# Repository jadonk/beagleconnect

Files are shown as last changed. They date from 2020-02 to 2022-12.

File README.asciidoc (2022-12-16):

ifdef::env-github[]
:tip-caption: :bulb:
:note-caption: :information_source:
:important-caption: :heavy_exclamation_mark:
:caution-caption: :fire:
:warning-caption: :warning:
:todo-caption: :hammer:
endif::[]
:toc:
:toc-placement!:

Moved to https://git.beagleboard.org/beagleconnect/freedom

[[beagleconnect]]
= BeagleConnect™

BeagleConnect™ is a revolutionary technology virtually eliminating low-level software
development for https://en.wikipedia.org/wiki/Internet_of_things[IoT] and https://en.wikipedia.org/wiki/Industrial_internet_of_things[IIoT] applications, such as building automation, factory
automation, home automation, and scientific data acquisition. While numerous IoT and IIoT
solutions available today
provide massive software libraries for microcontrollers footnote:[Complexity can be seen by exploring https://www.arduino.cc/reference/en/libraries/category/sensors/[Arduino sensor libraries]]
supporting a limited body of
https://en.wikipedia.org/wiki/Sensor[sensors],
https://en.wikipedia.org/wiki/Actuator[actuators] and
https://en.wikipedia.org/wiki/Indicator_(distance_amplifying_instrument)[indicators]
as well as libraries for communicating over various networks,
BeagleConnect simply eliminates the need for these libraries by shifting the burden
into the most massive and collaborative software project of all time, the https://en.wikipedia.org/wiki/Linux_kernel[Linux kernel].

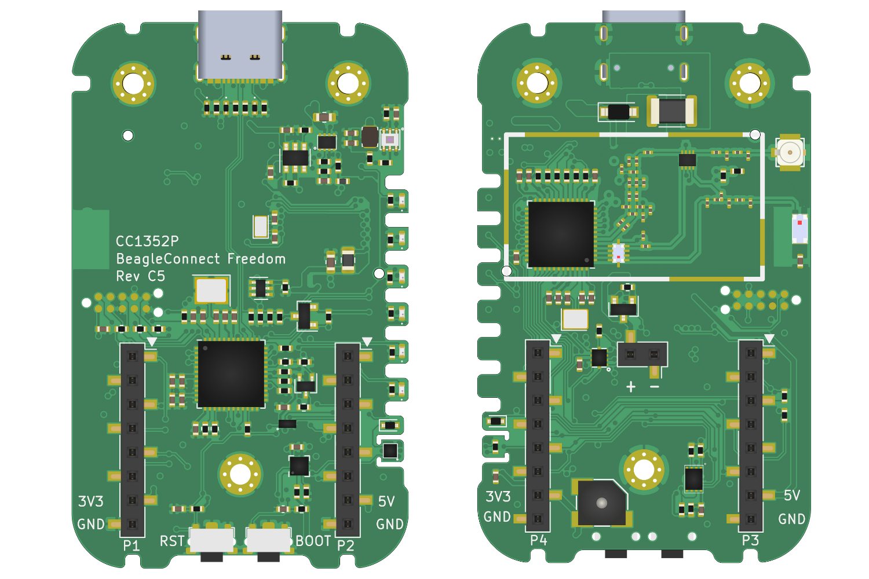
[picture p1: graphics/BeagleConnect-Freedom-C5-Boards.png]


These are the tools used to automate things in
https://en.wikipedia.org/wiki/Data_collection_system[scientific data collection],
https://en.wikipedia.org/wiki/Data_science[data science],
https://en.wikipedia.org/wiki/Mechatronics[mechatronics], and
https://en.wikipedia.org/wiki/Internet_of_things[IoT].

BeagleConnect™ technology solves: 

* The need to write software to add a large set of diverse devices to your system, 
* The need to maintain the software with security updates, 
* The need to rapidly prototype using off-the-shelf software and hardware without wiring, 
* The need to connect to devices using long-range, low-power wireless, and 
* The need to produce high-volume custom hardware cost-optimized for your requirements.

toc::[]

= BeagleConnect™ experience

BeagleConnect™ provides a scalable experience for interacting with the physical world.

NOTE: The term _BeagleConnect™_ refers to a technology comprising of
a family of boards, a collection of Linux kernel drivers,
microcontroller firmware, a communication protocol, and system-level
integration to automation software tools. More specific terms will be
applied in the architecture details. The term is also used here to
represent the experience introduced to users through the initial
_BeagleConnect™ Freedom_ product consisting of a board and case which
ships programmed and ready to be used.

For scientists, we are integrating https://jupyter.org/[Jupyter Notebook] with the data streams
from any of hundreds of sensor options, including https://www.mikroe.com/click/sensors/force[vibration],
https://www.mikroe.com/click/sensors/gas[gas detection],
https://www.mikroe.com/click/sensors/biometrics[biometrics] and
https://www.mikroe.com/click/sensors[more]. These data streams can be stored in simple
https://en.wikipedia.org/wiki/Comma-separated_values[data files] or processed and visualized.

WARNING: TODO provide images demonstrating Jupyter Notebook visualization

For embedded systems developers, data is easily extracted using the standard
https://www.kernel.org/doc/html/latest/driver-api/iio/index.html[IIO]
interface provided by the https://kernel.org[Linux kernel]
running on the gateway using any of hundreds of
programming languages and environments, without writing a line of microcontroller firmware.
The Linux environment provides opportunities for high-level remote management using tools
like https://balena.io[Balena] with applications deployed in
https://docker.io[Docker] containers.

WARNING: TODO provide image illustrating remote management#

The hardware and software are fully open source, providing for scalability and a lack of
vendor lock-in.

For DevOps...

For home automaters, integration into https://webthings.io[WebThings]...

WARNING: TODO think a bit more about this section with some feedback from Cathy.

= BeagleConnect™ hardware

== BeagleConnect™ Freedom

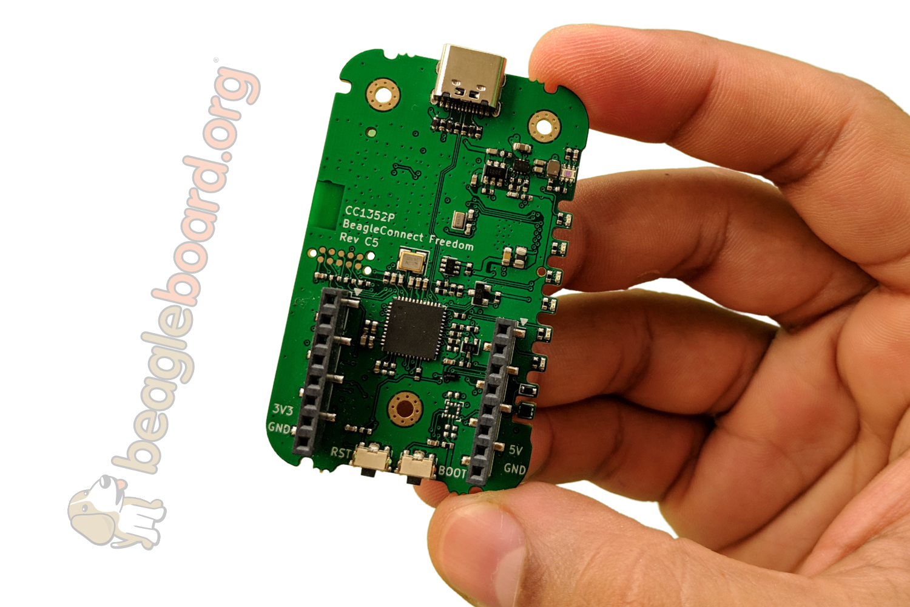
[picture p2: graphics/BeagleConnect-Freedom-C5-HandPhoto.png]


WARNING: TODO provide image of BeagleConnect™ Freedom in case with a hand for size perspective#

IMPORTANT: _BeagleConnect™ Freedom_ enables wirelessly adding new device nodes and is targeted
to cost initially around US$20 with a roadmap to variants as low as US$1.

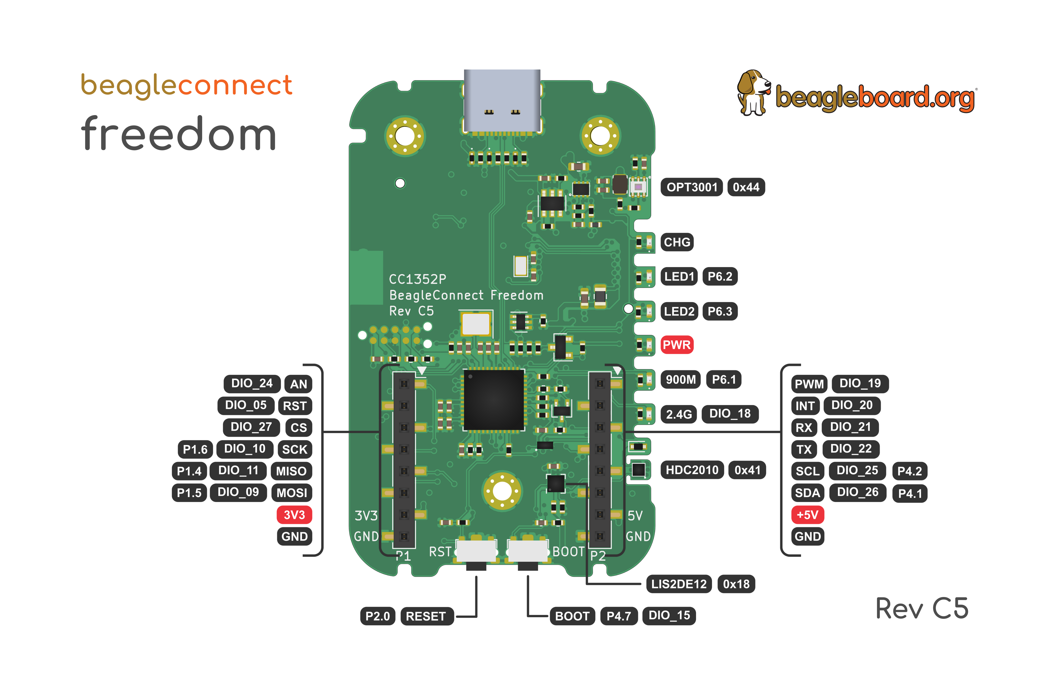
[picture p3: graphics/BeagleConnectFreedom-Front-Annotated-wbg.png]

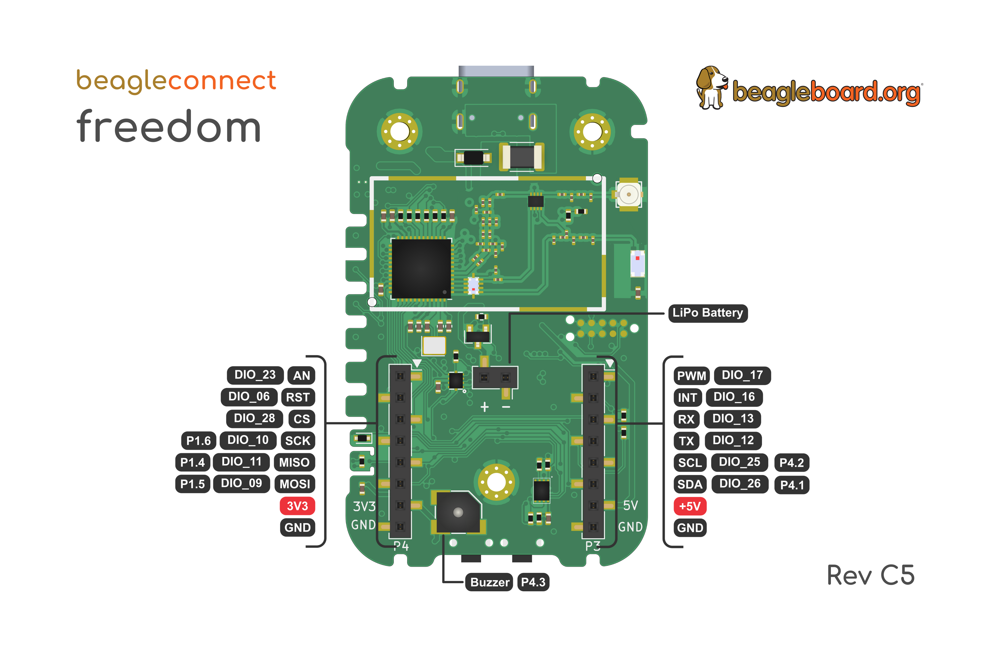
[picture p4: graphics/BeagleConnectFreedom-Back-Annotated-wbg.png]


The initial _BeagleConnect™ Freedom_ production release will: 

* Support at least 100 https://elinux.org/Mikrobus[mikroBUS]-based https://mikroe.com/click[Click boards from Mikroelectronika], 
* Work with https://en.wikipedia.org/wiki/Bluetooth_Low_Energy[Bluetooth Low Energy (BLE)]-enabled Linux computers at 2.4GHz, 
* Work with long-range sub-1GHz https://en.wikipedia.org/wiki/IEEE_802.15.4[IEEE 802.15.4 wireless connections] at 500 meters with data rates of 1kbps, and 
* Work with a low-cost BeagleBoard.org Linux https://en.wikipedia.org/wiki/Single-board_computer[single-board computer (SBC)] as a `BeagleConnect™ gateway device` and
  work with at least 10 other `BeagleConnect™ node devices` each supporting 2 add-on sensor, actuator or indicator devices.

Future releases will be collaborated with the community, evolve
dynamically, and contain additional functionality. The goal is to
support over 500 add-on devices within the first year after the
initial release.

[[beta-kit]]
== BeagleConnect™ Freedom beta kit

A small number of beta kits have been assembled with BeagleConnect™ Freedom rev C5
boards, which is the version that should be taken to production.

The kit includes:

* 1x https://wiki.seeedstudio.com/BeagleBone-Green-Gateway/[Seeed BeagleBone® Green Gateway] (board, USB cable)
* 3x BeagleConnect™ Freedom (board, antenna, USB cable)
* 1x https://www.mikroe.com/unique-id-click[MikroElektronikia Click ID Board]

To get started with this kit, see <<demo-1>>.

== BeagleConnect™ Mobile Gateway

This is a work-in-progress that will be released as the first integrated BeagleConnect™
gateway. It is possible to assemble a gateway with any Linux computer, but this computer
will ship setup and ready to go.

The gateway is built from:

* BeagleBoard.org PocketBeagle,
* BeagleConnect™ Freedom,
* a cellular modem,
* a USB WiFi dongle,
* antennas, and
* an enclosure.

[[story]]
= The Story Behind BeagleConnect™ 

[[long-background]]
== The Long Background
There are many stories behind BeagleConnect™, mine is just one of them. It begins
with my mom teaching me about computers. She told me I could anything I wanted
with ours, as long as I didn't open the case. This was the late-70s/early-80s, so
all she needed to do was put her https://en.wikipedia.org/wiki/Floppy_disk[floppy disk]
away and there wasn't risk of me damaging the family photo album or her ability to
do her work the next day. I listened and learned from her the basics of programming, but
it wasn't long before I wanted to take the computer apart. 

=== Getting Started in Electronics
Exploring http://www.forrestmims.org/[Getting Started in Electronics] satisfied my
itch for quite a while. Eventually, I got a Commodore 64 and began connecting voice
synthesizer ICs to it. My interest in computers and electronics flourished into
an electrical engineering degree and a long career in the semiconductor industry.

Over this time, I've become more and more alarmed with the progress of technology. Now,
to be clear, I love technology. I love innovation and invention. It is just that some
things have evolved in a sort of tunnel-vision, without bringing everyone along.

=== But, what about keyboard users?
As graphical user interfaces and mice took over computers, they rapidly became almost
unusable by my mom. She typed well, but the dexterity to move a mouse alluded her.
To satisfy the need to interact with locations on the screen, she adopted using a
joystick and her productivity came to a crawl. How is it that such assumptions could
be made impacting *all* computer users without any thoughtful provisions for what
already worked?

=== Find out more
Get on https://beagleboard.org/about/jkridner[my calendar] if you'd like to chat
with me more about this story.

[[architecture]]
= Architecture

[[beagleconnect-leash]]
== BeagleConnect™ Freedom
_BeagleConnect™ Freedom_ is based on the https://www.ti.com/product/CC1352R[TI CC1352] and is the first available
BeagleConnect™ solution. It implements:

* `BeagleConnect™ gateway device` function for Sub-GHz 802.15.4 long-range wireless
* `BeagleConnect™ node device` function for Bluetooth Low-Energy (BLE) and Sub-GHz
802.15.4 long range wireless
* USB-based serial console and firmware updates
* 2x https://www.mikroe.com/mikrobus[mikroBUS sockets] with `BeagleConnect™ protocol support`

WARNING: TODO provide BeagleConnect™ Freedom pinout diagram

[[what-is-new]]
== What makes BeagleConnect™ new and different?

IMPORTANT: BeagleConnect™ solves IoT in a different and better way than any previous
solution.

[[the-device-interface-software-is-already-done]]
=== The device interface software is already done

BeagleConnect™ uses the collaboratively developed Linux kernel to contain
the intelligence required to speak to these devices (sensors, actuators,
and indicators), rather than relying on writing code on a
microcontroller specific to these devices. Some existing solutions rely
on large libraries of microcontroller code, but the integration of
communications, maintenance of the library with a limited set of
developer resources and other constraints to be explained later make
those other solutions less suitable for rapid prototyping than
BeagleConnect™.

Linux presents these devices abstractly in ways that are
self-descriptive. Add an accelerometer to the system and you are
automatically fed a stream of force values in standard units. Add a
temperature sensor and you get it back in standard units again. Same for
sensing magnetism, proximity, color, light, frequency, orientation, or
multitudes of other inputs. Indicators, such as LEDs and displays, are
similarly abstracted with a few other kernel subsystems and more
advanced actuators with and without feedback control are in the process
of being developed and standardized. In places where proper Linux kernel
drivers exist, no new specialized code needs to be created for the
devices.

IMPORTANT: _Bottom line_: For hundreds of devices, users won't have to write a
single line of code to add them their systems. The automation code they
do write can be extremely simple, done with graphical tools or in any
language they want. Maintenance of the code is centralized in a small
reusable set of microcontroller firmware and the Linux kernel, which is
highly peer reviewed under a
https://wiki.p2pfoundation.net/Linux_-_Governance[highly-regarded
governance model].

[[on-going-maintenance]]
=== On-going maintenance

Because there isn't code specific to any given network-of-devices
configuration, we can all leverage the same software code base. This
means that when someone fixes an issue in either BeagleConnect™ firmware
or the Linux kernel, you benefit from the fixes. The source for
BeagleConnect™ firmware is also submitted to the
https://www.zephyrproject.org/[Zephyr Project] upstream, further
increasing the user base. Additionally, we will maintain stable branches
of the software and provide mechanisms for updating firmware on
BeagleConnect™ hardware. With a single, relatively small firmware load,
the potential for bugs is kept low. With large user base, the potential
for discovering and resolving bugs is high.

[[rapid-prototyping-without-wiring]]
=== Rapid prototyping without wiring

BeagleConnect™ utilizes the https://elinux.org/Mikrobus[mikroBUS
standard]. The mikroBUS standard interface is flexible enough for almost
any typical sensor or indicator with hundreds of devices available.

NOTE: Currently, we have support in the Linux kernel for a bit over 100
_Click_ mikroBUS add-on boards from Mikroelektronika and are working
with Mikroelektronika on a updated version of the specification for these
boards to self-identify. Further, eventually the vast majority of over
800 currently available _Click_ mikroBUS add-on boards will be supported
as well as the hundreds of compliant boards developed every year.

[[long-range-low-power-wireless]]
=== Long-range, low-power wireless

_BeagleConnect™ Freedom_ wireless hardware is built around a
http://www.ti.com/product/CC1352R[TI CC1352] multiprotocol and multi-band Sub-1 GHz and 2.4-GHz wireless 
microcontroller (MCU). CC1352R includes a 48-MHz Arm® Cortex®-M4F processor, 352KB Flash, 256KB ROM, 8KB Cache SRAM,
80KB of ultra-low leakage SRAM, and https://en.wikipedia.org/wiki/Over-the-air_programming[Over-the-Air] upgrades (OTA).

[[full-customization-possible]]
=== Full customization possible

BeagleConnect™ utilizes https://www.oshwa.org/definition/[open source
hardware] and https://en.wikipedia.org/wiki/Open-source_software[open
source software], making it possible to optimize hardware and software
implementations and sourcing to meet end-product requirements.
BeagleConnect™ is meant to enable rapid-prototyping and not to
necessarily satisfy any particular end-product's requirements, but with
full considerations for go-to-market needs.

Each BeagleBoard.org BeagleConnect™ solution will be:

* Readily available for over 10 years, 
* Built with fully
open source software with submissions to mainline Linux and Zephyr
repositories to aide in support and porting, 
* Built with fully open
source and non-restrictive hardware design including schematic,
bill-of-materials, layout, and manufacturing files (with only the
BeagleBoard.org logo removed due to licensing restrictions of our
brand), 
* Built with parts where at least a compatible part is available
from worldwide distributors in any quantity, 
* Built with design and
manufacturing partners able to help scale derivative designs, 
* Based on
a security model using public/private keypairs that can be replaced to
secure your own network, and 
* Fully FCC/CE certified.

[[usage]]
= Usage
This section describes the usage model we are developing. To use the current code in development,
please refer to the <<development>> section below.

[[beagleconnect-user-experience]]
== BeagleConnect™ wireless user experience

[[enable-a-linux-host-with-beagleconnect]]
=== Enable a Linux host with BeagleConnect™

image:https://github.com/beagleboard/beagleconnect/blob/master/docs/ProvStep1.PNG?raw=true[Provisioning
Step 1] Log into a host system running Linux that is BeagleConnect™
enabled. Enable a Linux host with BeagleConnect™ by plugging a
`BeagleConnect™ gateway device` into it's USB port. You'll also want to have a
`BeagleConnect™ node device` with a sensor, actuator or indicator device connected.

NOTE: _BeagleConnect™ Freedom_ can act as either a `BeagleConnect™ gateway device` or a
`BeagleConnect™ node device`.

IMPORTANT: The Linux host will need to run the `BeagleConnect™ management
software`, most of which is incorporated into the Linux kernel. Support will
be provided for BeagleBoard and BeagleBone boards, x86 hosts, and Raspberry Pi.

WARNING: TODO Clean up images

[[connect-host-and-device]]
=== Connect host and device

image:https://github.com/beagleboard/beagleconnect/blob/master/docs/ProvStep2.PNG?raw=true[Provisioning
Step 2] Initiate a connection between the host and devices by pressing
the discovery button(s).

[[device-data-shows-up-as-files]]
=== Device data shows up as files

image:https://github.com/beagleboard/beagleconnect/blob/master/docs/ProvStep3.PNG?raw=true[Provisioning
Step 3] New streams of self-describing data show up on the host system
using native device drivers.

High-level applications, like `Node-RED`, can directly read/write these high-level
data streams (including data-type information) to Internet-based https://mqtt.org/[MQTT] brokers,
live dashboards, or other logical operations without requiring any sensor-specific
coding. Business logic can be applied using simple if-this-then-that style operations
or be made as complex as desired using virtually any programming language or environment.

WARNING: TODO Actually, Node-RED will make these show up automatically as streams.

[[components]]
== Components

[horizontal]
BeagleConnect™ enabled host:: Linux computer, possibly single-board computer (SBC), with
`BeagleConnect™ management software` and `BeagleConnect™ gateway function`. `BeagleConnect™ gateway
function` can be provided by a `BeagleConnect™ compatible interface` or by connecting a
`BeagleConnect™ gateway device` over USB.
+
NOTE: If the Linux host has BLE, the BeagleConnect™ is optional for short distances
+

BeagleConnect™ Freedom:: Board, case, and wireless MCU with `Zephyr` based firmware for acting
as either a `BeagleConnect™ gateway device` or `BeagleConnect™ node device`.
* In `BeagleConnect™ gateway device` mode:
** Provides long-range, low-power wireless communications,
** Connects with the `host` via USB and an associated Linux kernel driver, and
** Is powered by the USB connector.
* In `BeagleConnect™ node device` mode:
** Powered by a battery or USB connector
** Provides 2 mikroBUS connectors for connecting any of hundreds of
https://bbb.io/click[Click Board] mikroBUS add-on devices
** Provides new Linux host controllers for SPI, I2C, UART, PWM, ADC, and
GPIO with interrupts via `Greybus`

BeagleConnect™ gateway device:: Provides a `BeagleConnect™ compatible interface` to a host. This
could be a built-in interface device or one connected over USB. _BeagleConnect™ Freedom_ can provide
this function.

BeagleConnect™ node device:: Utilizes a `BeagleConnect™ compatible interface` and #TODO#

BeagleConnect™ compatible interface:: Immediate plans are to support Bluetooth Low Energy (BLE),
2.4GHz IEEE 802.15.4, and Sub-GHz IEEE 802.15.4 _wireless_ interfaces. A built-in BLE interface is
suitable for this at short range, whereas IEEE 802.15.4 is typically significantly better at long
ranges. Other _wired_ interfaces, such as _CAN_ and _RS-485_, are being considered for future
`BeagleConnect™ gateway device` and `BeagleConnect™ node device` designs.

Greybus:: #TODO#

WARNING: TODO Find a place for the following notes:

** The device interfaces get exposed to the host via Greybus BRIDGED_PHY
protocol
** The I2C bus is probed for a an identifier EEPROM and appropriate
device drivers are loaded on the host
** Unsupported Click Boards connected are exposed via userspace drivers
on the host for development

[[whats-different]]
== What's different

So, in summary, what is so different with this approach?

* No microcontroller code development is required by users
* Userspace drivers make rapid prototyping really easy
* Kernel drivers makes the support code collaborative parts of the Linux
kernel, rather than cut-and-paste

[[development]]
= Develop for BeagleConnect™ Freedom with Zephyr

Developing directly in Zephyr will not be ultimately required for end-users who won't touch the firmware running on BeagleConnect™ Freedom and will instead use the BeagleConnect™ Greybus functionality, but is important for early adopters as well as people looking to extend the functionality of the open source design. If you are one of those people, this is a good place to get started.

[[equipment]]
== Equipment to begin development

There are many options, but let's get started with one recommended set for the beta users.

=== Required

* <<beta-kit>>
** https://wiki.seeedstudio.com/BeagleBone-Green-Gateway/[Seeed Studio BeagleBone® Green Gateway]
** 3x BeagleConnect™ Freedom board, antenna, U.FL to SMA cable, SMA antenna and USB Type-A to Type-C cable
** 1x https://www.mikroe.com/click[MikroE] ID Click
* microSD card (6GB or larger)
* microSD card programmer

=== Recommended

* https://smile.amazon.com/TMEZON-Power-Adapter-Supply-2-1mm/dp/B00Q2E5IXW[12V power brick]
* https://smile.amazon.com/Converter-Terminated-Galileo-BeagleBone-Minnowboard/dp/B06ZYPLFNB[USB to TTL 3.3V UART adapter]
* Ethernet cable and Internet connection
* 2x USB power adapters
* https://www.mikroe.com/weather-click[BME280-based Weather Click]
* https://www.mikroe.com/air-quality-2-click[iAQ-Core-based Air Quality 2 Click]

=== Optional

* x86_64 computer running Ubuntu 20.04.3 LTS

== Install the latest software image for BeagleBone Green Gateway

Download and install the Debian Linux operating system image for the
Seeed BeagleBone® Green Gateway host.

1. Download the special mikroBUS/Greybus BeagleBoard.org Debian image from
https://rcn-ee.net/rootfs/debian-mikrobus-armhf/[here]. 
Pick the most recent directory and select the file beginning with *bone-* and ending with *.img.xz*.
Today that file is *bone-debian-11.2-iot-mikrobus-armhf-2022-03-04-4gb.img.xz*.
2. Load this image to a microSD card using a tool like https://www.balena.io/etcher/[Etcher].
3. Insert the microSD card into the Green Gateway.
4. Power BeagleBone Green Gateway via the 12V barrel jack.

WARNING: TODO describe how to know it is working

== Setup BeagleBone Green Gateway

These instructions assume your BeagleBone Green is connected over USB to an x86_64 computer runing Ubuntu 20.04.3 LTS, but any other computer can also be used.

1. Log onto the Seeed BeagleBone® Green Gateway using `ssh`.
** We need IP address, username, and password to connect to the device.
** The default IP for the BeagleBone hardware over USB is `192.168.7.2` (over Ethernet it's usually at beaglebone.local)
** The default username is `debian` & password is `temppwd`
** To connect you can simply type `$ ssh debian@192.168.7.2` and when asked for password just type `temppwd`.
** Congratulations, You are now connected to the device!
2. Connect to the https://forum.beagleboard.org/t/debian-11-x-bullseye-monthly-snapshots/31280[WiFi]
** Execute `sudo nano /etc/wpa_supplicant/wpa_supplicant-wlan0.conf` and provide the password `temppwd` to edit the configuration file for the WiFi connection.
** Now edit the the file (shown below) under the `network={ ... }` section you can set you `ssid` (WiFi name) and `psk` (Wifi Password).

    ctrl_interface=DIR=/run/wpa_supplicant GROUP=netdev
    update_config=1
    #country=IN
    network={
            ssid="WiFi Name"
            psk="WiFi Password"
    }
    
** Now save the file with `CTRL+O` and exit with `CTRL+X`.
** Check if the connection is established by executing `$ ping 8.8.8.8` you should see something like shown below.

    debian@BeagleBone:~$ ping 8.8.8.8
    PING 8.8.8.8 (8.8.8.8) 56(84) bytes of data.
    64 bytes from 8.8.8.8: icmp_seq=1 ttl=118 time=10.5 ms
    64 bytes from 8.8.8.8: icmp_seq=2 ttl=118 time=5.72 ms
    64 bytes from 8.8.8.8: icmp_seq=3 ttl=118 time=6.13 ms
    64 bytes from 8.8.8.8: icmp_seq=4 ttl=118 time=6.11 ms
    ...
    
** If everything goes well, you are ready to update your system and install new applications for beagleconnect.

3. Install https://github.com/rcn-ee/code-server/tree/v3.11.1-bbb.io[Visual Studio Code Server] for easy terminal access and code editing.
** Update, Upgrade & Install the code server.

    sudo apt update
    
    sudo apt upgrade
    
    sudo apt install bb-code-server
    
    sudo reboot

** Enable and start the VSCode Server on `192.168.7.2:3000`
  
  sudo systemctl enable bb-code-server
  
  sudo systemctl start bb-code-server

** Visit `http://192.168.7.2:3000` and access the terminal easily using `CTRL + ``, You may also checkout other VSCode shortcuts https://code.visualstudio.com/shortcuts/keyboard-shortcuts-linux.pdf[here].

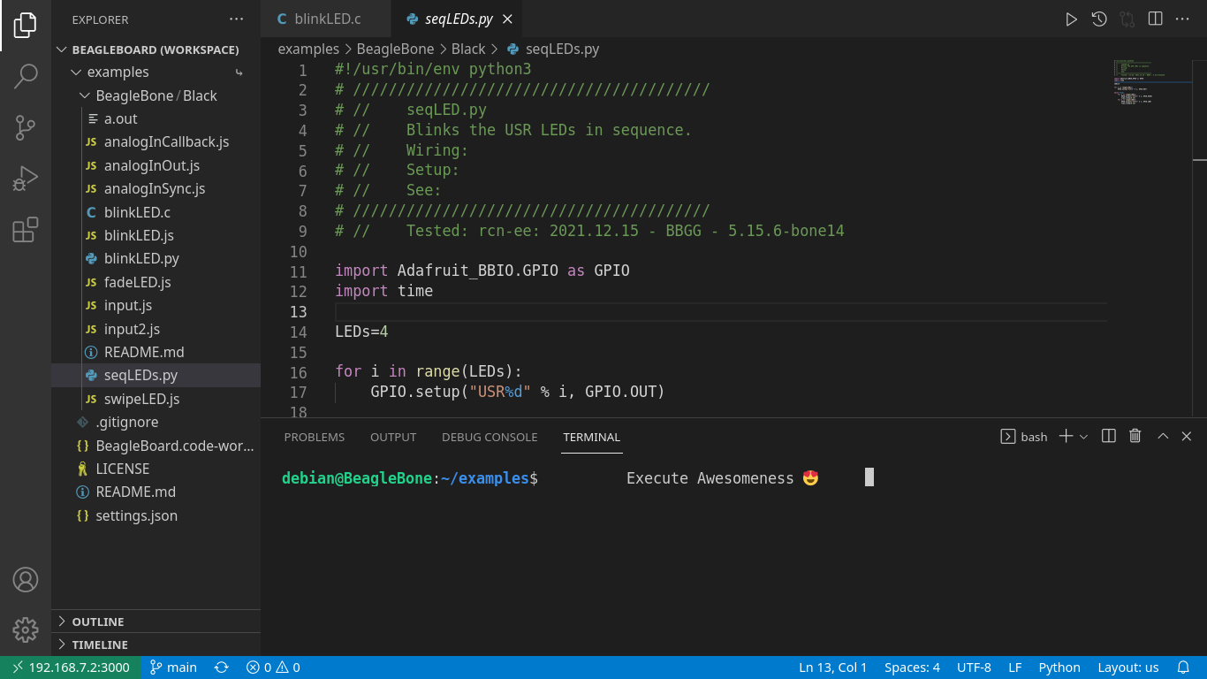
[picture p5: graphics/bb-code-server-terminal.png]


WARNING: TODO the above installation of bb-code-server should not be required on the mikrobus images. it needs to be enabled by default.

NOTE: If you are facing some issue during boot then you can try debuging the boot session with a USB to serial interface cable such as those made by https://www.digikey.com/short/cfjmdbdd[FTDI] plugged into J10 with the black wire of the FTDI cable toward the Ethernet connector. Application like tio/minicom/putty can be used to make the connection establishment procedure easy.

WARNING: TODO Simplify and elaborate on this section, add boot session debugging walkthrough

[[sdk]]
== Install Zephyr development tools on BeagleBone Green Gateway

<1> Update the system.

    sudo apt update

<2> Install all BeagleConnect™ management software.
    
    sudo apt install -y \
	    beagleconnect beagleconnect-msp430 \
	    git vim \
	    build-essential \
	    cmake ninja-build gperf \
	    ccache dfu-util device-tree-compiler \
	    make gcc libsdl2-dev \
	    libxml2-dev libxslt-dev libssl-dev libjpeg62-turbo-dev \
	    gcc-arm-none-eabi libnewlib-arm-none-eabi \
	    libtool-bin pkg-config autoconf automake libusb-1.0-0-dev \
	    python3-dev python3-pip python3-setuptools python3-tk python3-wheel

    echo "export PATH=$PATH:$HOME/.local/bin" >> $HOME/.bashrc
    
    source $HOME/.bashrc

<3> Reboot

    sudo reboot

<4> Install BeagleConnect™ flashing software

    pip3 install -U west

<5> Reboot

    sudo reboot

<6> Download and setup Zephyr for BeagleConnect™ 

    cd

    west init -m https://github.com/jadonk/zephyr --mr bcf-sdk-3.1.0-rebase bcf-zephyr

    cd $HOME/bcf-zephyr

    west update

    west zephyr-export

    pip3 install -r zephyr/scripts/requirements-base.txt

    echo "export CROSS_COMPILE=/usr/bin/arm-none-eabi-" >> $HOME/.bashrc

    echo "export ZEPHYR_BASE=$HOME/bcf-zephyr/zephyr" >> $HOME/.bashrc

    echo "export PATH=$HOME/bcf-zephyr/zephyr/scripts:$PATH" >> $HOME/.bashrc

    echo "export BOARD=beagleconnect_freedom" >> $HOME/.bashrc

    source $HOME/.bashrc

== Build applications for BeagleConnect Freedom on BeagleBone Green Gateway

Now you can build various Zephyr applications

<1> Change directory to BeagleConnect Freedom zephyr repository.
    
    cd $HOME/bcf-zephyr

<2> Build blinky example

    west build -d build/blinky zephyr/samples/basic/blinky

<3> TODO

    west build -d build/sensortest zephyr/samples/boards/beagle_bcf/sensortest -- -DOVERLAY_CONFIG=overlay-subghz.conf

<4> TODO

    west build -d build/wpanusb modules/lib/wpanusb_bc -- -DOVERLAY_CONFIG=overlay-subghz.conf

<5> TODO 

    west build -d build/bcfserial modules/lib/wpanusb_bc -- -DOVERLAY_CONFIG=overlay-bcfserial.conf -DDTC_OVERLAY_FILE=bcfserial.overlay

<6> TODO

    west build -d build/greybus modules/lib/greybus/samples/subsys/greybus/net -- -DOVERLAY_CONFIG=overlay-802154-subg.conf

== Flash applications to BeagleConnect Freedom from BeagleBone Green Gateway

And then you can flash the BeagleConnect Freedom boards over USB

<1> Make sure you are in Zephyr directory

    cd $HOME/bcf-zephyr

<2> Flash Blinky

    cc2538-bsl.py build/blinky

== Debug applications over the serial terminal

#TODO

[[work-in-progress]]
= Work in progress

To understand a bit more about how the BeagleConnect™ Greybus stack is being built, this section helps describe the development currently in progress and the principles of operation.

[[background]]
== Background

image:https://github.com/beagleboard/beagleconnect/blob/master/docs/SoftwareProp.PNG?raw=true[Software
Proposition] BeagleConnect™ uses Greybus and updated Click Boards with
identifiers to eliminate the need to add and manually configure devices
added onto the Linux system.

[[high-level]]
=== High-level

* For Linux nerds: Think of BeagleConnect™ as
https://en.wikipedia.org/wiki/6LoWPAN[6LoWPAN] over
https://en.wikipedia.org/wiki/IEEE_802.15.4[802.15.4]-based
https://kernel-recipes.org/en/2015/talks/an-introduction-to-greybus/[Greybus]
(instead of Unipro as used by Project Ara), where every BeagleConnect™
board shows up as new SPI, I2C, UART, PWM, ADC, and GPIO controllers
that can now be probed to load drivers for the sensors or whatever is
connected to them. (Proof of concept of Greybus over TCP/IP:
https://www.youtube.com/watch?v=7H50pv-4YXw)
* For MCU folks: Think of BeagleConnect™ as a
https://github.com/firmata/protocol[Firmata]-style firmware load that
exposes the interfaces for remote access over a secured wireless
network. However, instead of using host software that knows how to speak
the Firmata protocol, the Linux kernel speaks the slightly similar
Greybus protocol to the MCU and exposes the device generically to users
using a Linux kernel driver. Further, the Greybus protocol is spoken
over https://en.wikipedia.org/wiki/6LoWPAN[6LoWPAN] on
https://en.wikipedia.org/wiki/IEEE_802.15.4[802.15.4].

[[software-architecture]]
=== Software architecture

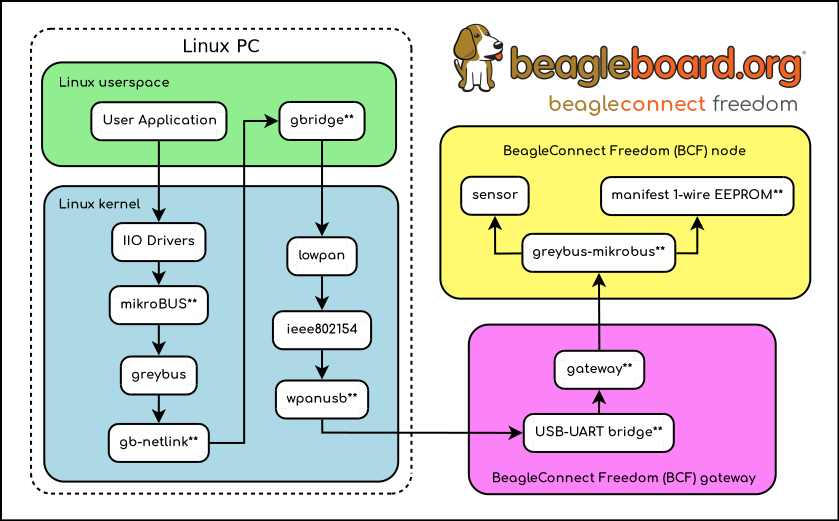
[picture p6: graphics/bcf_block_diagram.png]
Block Diagram


[[todo-items]]
TODO items
~~~~~~~~~~

* Linux kernel driver
* Provisioning
* Firmware for host CC13x
* Firmware for device CC13x
* Click Board drivers and device tree formatted metadata for 100 or so
Click Boards
* Click Board plug-ins for node-red for the same 100 or so Click Boards
* BeagleConnect™ Freedom System Reference Manual and FAQs

[[associated-pre-work]]
Associated pre-work
~~~~~~~~~~~~~~~~~~~

* Click Board support for Node-RED can be executed with native
connections on PocketBeagle+TechLab and BeagleBone Black with mikroBUS
Cape
* Device tree fragments and driver updates can be provided via
https://bbb.io/click
* The Kconfig style provisioning can be implemented for those solutions,
which will require a reboot. We need to centralize edits to
/boot/uEnv.txt to be programmatic. As I think through this, I don't
think BeagleConnect is impacted, because the Greybus-style discovery
along with Click EEPROMS will eliminate any need to edit /boot/uEnv.txt.

[[user-experience-concerns]]
User experience concerns
~~~~~~~~~~~~~~~~~~~~~~~~

* Make sure no reboots are required
* Plugging BeagleConnect into host should trigger host configuration
* Click EEPROMs should trigger loading whatever drivers are needed and
provisioning should load any new drivers
* Userspace (spidev, etc.) drivers should unload cleanly when 2nd phase
provisioning is completed

[[demo-1]]
= BeagleConnect™ Greybus demo using BeagleConnect™ Freedom
BeagleConnect™ Freedom runs a subGHz IEEE 802.15.4 network. This BeagleConnect™ Greybus demo shows how to interact with GPIO, I2C and mikroBUS add-on boards remotely connected over a BeagleConnect™ Freedom.

This section starts with the steps required to use
https://en.wikipedia.org/wiki/Linux[Linux] embedded computer (https://wiki.seeedstudio.com/BeagleBone-Green-Gateway/[BeagleBone Green Gateway]) and the
https://lwn.net/Articles/715955/[Greybus] protocol, over an IEEE
802.15.4 wireless link, to blink an LED on a
https://zephyrproject.org[Zephyr] device.

== Introduction

=== Why??

Good question. Blinking an LED is kind of the
https://en.wikipedia.org/wiki/%22Hello,_World!%22_program[Hello, World]
of the hardware community. In this case, we’re less interested in the
mechanics of switching a GPIO to drive some current through an LED and
more interested in how that happens with the
https://en.wikipedia.org/wiki/Internet_of_things[Internet of Things
(IoT)].

There are several existing network and application layers that are
driven by corporate heavyweights and industry consortiums, but
relatively few that are community driven and, more specifically, even
fewer that have the ability to integrate so tightly with the Linux
kernel.

The goal here is to provide a community-maintained, developer-friendly,
and open-source protocol for the Internet of Things using the Greybus
Protocol, and blinking an LED using Greybus is the simplest
proof-of-concept for that. All that is required is a reliable transport.

=== History

There are a few technologies at the core of this demonstration, and far
too much background information to describe adequately here, so they are
simply listed below for brevity:

* https://en.wikipedia.org/wiki/Project_Ara[Project Ara]
* https://en.wikipedia.org/wiki/IPv6[IPv6] (via
https://en.wikipedia.org/wiki/6LoWPAN[6LoWPAN])
* https://zephyrproject.org[Zephyr] support for
https://docs.zephyrproject.org/latest/reference/networking/ieee802154.html[IEEE
802.15.4]
* https://youtu.be/UzRq8jAHAxU[Greybus] originally from
https://youtu.be/UzRq8jAHAxU[Project Ara]
* https://youtu.be/7H50pv-4YXw[Using Greybus for IoT]

In short, Greybus is an application layer protocol that can be described
as a ``bus transport'' in that it conveys bus-specific messages back and
forth between Linux and a connected device. The physical bus is attached
to the connected device, which could be running Linux or a variety of
Real-Time Operating Systems. Meanwhile, on the Linux side, a virtual bus
is created corresponding to the physical bus on the connected device. To
the user, this virtual bus (be it /dev/gpiochip0, /dev/i2c5, etc)
appears and functions exactly the same. Greybus is the protocol used to
exchange bus-specific messages and data between Linux and the connected
device.

The major advantage there is that drivers can be well maintained in
Linux rather than buried in microcontroller firmware.

Greybus currently supports several busses, including:

* USB
* I2C
* GPIO
* PWM
* SPI
* UART
* SDIO
* Camera (V4L)
* LED (with various programmability)
* AUDIO (I2S)

WARNING: TODO The agenda for the above falls a bit short of BeagleConnect

=== Hardware requirements

See the <<Equipment>> section for hardware requirements.

== Running the demo

WARNING: TODO Fill in some details for new embedded Linux users

WARNING: TODO Arrange demo in order of _fast success_ to _greater understanding_

=== Install the latest software image

Download and install the Debian Linux operating system image for the
Seeed BeagleBone® Green Gateway host.

1. Download the special mikroBUS/Greybus BeagleBoard.org Debian image from
https://rcn-ee.net/rootfs/debian-mikrobus-armhf/[here]. 
Pick the most recent directory and select the file beginning with *bone-* and ending with *.img.xz*.
Today that file is *bone-debian-11.2-iot-mikrobus-armhf-2022-03-04-4gb.img.xz*.
2. Load this image to a microSD card using a tool like https://www.balena.io/etcher/[Etcher].
3. Insert the microSD card into the Green Gateway.
4. Power the Green Gateway via the 12V barrel jack.
5. Log onto the Seeed BeagleBone® Green Gateway using `ssh` or, with a serial to USB cable such as those made by FTDI[https://www.digikey.com/short/cfjmdbdd] plugged into J10 with the black wire of the FTDI cable toward the Ethernet connector.  To use `ssh`, you will have to know the Green Gateway's IP address that can be found from your router.
6. (If using WiFi) Use the `connmanctl` tool to gain an Internet connection.

=== Flash BeagleConnect™ Freedom *gateway* device

Command-line instructions below are to be issued into the BeagleBone® Green Gateway terminal, either via `ssh` or the serial console.

On the newly imaged BeagleBone® Green Gateway board:

1. Connect (or reconnect) a BeagleConnect™ Freedom board over USB
2. `cc2538-bsl.py /usr/share/beagleconnect/cc1352/wpanusb_beagleconnect.bin /dev/ttyACM0` 
footnote:[If the cc2538-bs1.py command fails, see Flashing via a Linux Host below]
3. After it finishes programming successfully, reconnect the BeagleConnect Freedom board over USB
4. Test that the driver loaded and is talking to the newly added gateway radio
+
```
debian@beaglebone:~$ iwpan wpan0 info
Interface wpan0
        ifindex 10
        wpan_dev 0x200000001
        extended_addr 0x5a4f745eb7beac7f
        short_addr 0xffff
        pan_id 0xffff
        type node
        max_frame_retries 3
        min_be 3
        max_be 5
        max_csma_backoffs 4
        lbt 0
        ackreq_default 0
```

=== Test gateway using pre-programmed node firmware

By default, the beta boards ship with a debug sensor broadcast per https://gist.github.com/Pillar1989/c579b789e38e856cde16e77345932ac4[sensortest-main.c]. You can use this to further test your gateway.

1. Power a BeagleConnect Freedom that has not yet been programmed via a USB power source, not
the BeagleBone Green Gateway. You'll hear a click every 1-2 seconds along with seeing 4 of the
LEDs turn off and on.
2. In an isolated terminal window, `sudo beagleconnect-start-gateway`
3. `sensortest-rx.py`

Every 1-2 minutes, you should see something like:
```
('fe80::3111:7a22:4b:1200%lowpan0', 52213, 0, 13)  '2l:7.79;'
('fe80::3111:7a22:4b:1200%lowpan0', 52213, 0, 13)  '4h:43.75;4t:23.11;'
```

The value after "2l:" is the amount of light in lux. The value after "4h:" is the relative humidity and after "4t:" is the temperature in Celcius.

=== Flash BeagleConnect™ Freedom *node* device with Greybus firmware

WARNING: TODO How can we add a step in here to show the network is connected without needing `gbridge` to be fully functional?

Do this from the BeagleBone® Green Gateway board that was previously used to program the BeagleConnect™ Freedom *gateway* device:

1. Disconnect the BeagleConnect™ Freedom *gateway* device
2. Connect a new BeagleConnect™ Freedom board via USB
3. `sudo systemctl stop lowpan.service`
4. `cc2538-bsl.py /usr/share/beagleconnect/cc1352/greybus_mikrobus_beagleconnect.bin /dev/ttyACM0`
footnote:[If the cc2538-bs1.py command fails, see Flashing via a Linux Host below]
5. After it finishes programming successfully, disconnect the BeagleConnect Freedom node device
6. Power the newly programmed BeagleConnect Freedom *node* device from an alternate USB power source
7. Reconnect the BeagleConnect Freedom *gateway* device to the BeagleBone Green Gateway
8. `sudo systemctl start lowpan.service`
9. `sudo beagleconnect-start-gateway`

```sh
debian@beaglebone:~$ sudo beagleconnect-start-gateway 
[sudo] password for debian: 
setting up wpanusb gateway for IEEE 802154 CHANNEL 1(906 Mhz)
ping6: Warning: source address might be selected on device other than lowpan0.
PING 2001:db8::1(2001:db8::1) from ::1 lowpan0: 56 data bytes
64 bytes from 2001:db8::1: icmp_seq=2 ttl=64 time=185 ms
64 bytes from 2001:db8::1: icmp_seq=3 ttl=64 time=40.9 ms
64 bytes from 2001:db8::1: icmp_seq=4 ttl=64 time=40.9 ms
64 bytes from 2001:db8::1: icmp_seq=5 ttl=64 time=40.6 ms

--- 2001:db8::1 ping statistics ---
5 packets transmitted, 4 received, 20% packet loss, time 36ms
rtt min/avg/max/mdev = 40.593/76.796/184.799/62.356 ms
debian@beaglebone:~$ iio_info 
Library version: 0.19 (git tag: v0.19)
Compiled with backends: local xml ip usb serial
IIO context created with local backend.
Backend version: 0.19 (git tag: v0.19)
Backend description string: Linux beaglebone 5.14.18-bone20 #1buster PREEMPT Tue Nov 16 20:47:19 UTC 2021 armv7l
IIO context has 1 attributes:
	local,kernel: 5.14.18-bone20
IIO context has 3 devices:
	iio:device0: TI-am335x-adc.0.auto (buffer capable)
		8 channels found:
			voltage0:  (input, index: 0, format: le:u12/16>>0)
			1 channel-specific attributes found:
				attr  0: raw value: 1412
			voltage1:  (input, index: 1, format: le:u12/16>>0)
			1 channel-specific attributes found:
				attr  0: raw value: 2318
			voltage2:  (input, index: 2, format: le:u12/16>>0)
			1 channel-specific attributes found:
				attr  0: raw value: 2631
			voltage3:  (input, index: 3, format: le:u12/16>>0)
			1 channel-specific attributes found:
				attr  0: raw value: 817
			voltage4:  (input, index: 4, format: le:u12/16>>0)
			1 channel-specific attributes found:
				attr  0: raw value: 881
			voltage5:  (input, index: 5, format: le:u12/16>>0)
			1 channel-specific attributes found:
				attr  0: raw value: 0
			voltage6:  (input, index: 6, format: le:u12/16>>0)
			1 channel-specific attributes found:
				attr  0: raw value: 0
			voltage7:  (input, index: 7, format: le:u12/16>>0)
			1 channel-specific attributes found:
				attr  0: raw value: 1180
		2 buffer-specific attributes found:
				attr  0: data_available value: 0
				attr  1: watermark value: 1
	iio:device1: hdc2010
		3 channels found:
			humidityrelative:  (input)
			3 channel-specific attributes found:
				attr  0: peak_raw value: 52224
				attr  1: raw value: 52234
				attr  2: scale value: 1.525878906
			current:  (output)
			2 channel-specific attributes found:
				attr  0: heater_raw value: 0
				attr  1: heater_raw_available value: 0 1
			temp:  (input)
			4 channel-specific attributes found:
				attr  0: offset value: -15887.515151
				attr  1: peak_raw value: 25600
				attr  2: raw value: 25628
				attr  3: scale value: 2.517700195
	iio:device2: opt3001
		1 channels found:
			illuminance:  (input)
			2 channel-specific attributes found:
				attr  0: input value: 79.040000
				attr  1: integration_time value: 0.800000
		2 device-specific attributes found:
				attr  0: current_timestamp_clock value: realtime

				attr  1: integration_time_available value: 0.1 0.8
debian@beaglebone:~$ dmesg | grep -e mikrobus -e greybus
[  100.491253] greybus 1-2.2: Interface added (greybus)
[  100.491294] greybus 1-2.2: GMP VID=0x00000126, PID=0x00000126
[  100.491306] greybus 1-2.2: DDBL1 Manufacturer=0x00000126, Product=0x00000126
[  100.737637] greybus 1-2.2: excess descriptors in interface manifest
[  102.475168] mikrobus:mikrobus_port_gb_register: mikrobus gb_probe , num cports= 2, manifest_size 192 
[  102.475206] mikrobus:mikrobus_port_gb_register: protocol added 3
[  102.475214] mikrobus:mikrobus_port_gb_register: protocol added 2
[  102.475239] mikrobus:mikrobus_port_register: registering port mikrobus-1 
[  102.475400] mikrobus_manifest:mikrobus_state_get: mikrobus descriptor not found
[  102.475417] mikrobus_manifest:mikrobus_manifest_attach_device: parsed device 1, driver=opt3001, protocol=3, reg=44
[  102.494516] mikrobus_manifest:mikrobus_manifest_attach_device: parsed device 2, driver=hdc2010, protocol=3, reg=41
[  102.494567] mikrobus_manifest:mikrobus_manifest_parse:  (null) manifest parsed with 2 devices
[  102.494592] mikrobus mikrobus-1: registering device : opt3001
[  102.495096] mikrobus mikrobus-1: registering device : hdc2010
debian@beaglebone:~$ 
```

#TODO: update the below for the built-in sensors

WARNING: TODO can we also handle the case where these sensors are included and recommend them? Same firmware?

WARNING: TODO the current demo is for the built-in sensors, not the Click boards mentioned below

Currently only a limited number of add-on boards have been tested to work over Greybus, simple add-on
boards without interrupt requirement are the ones that work currently.  The example is for
Air Quality 2 Click and Weather Click attached to the mikroBUS ports on the device side.

/var/log/gbridge will have the gbridge log, and if the mikroBUS port has been instantiated successfully the kernel log will show the devices probe messages:

WARNING: TODO this log needs to be updated

```
greybus 1-2.2: GMP VID=0x00000126, PID=0x00000126
greybus 1-2.2: DDBL1 Manufacturer=0x00000126, Product=0x00000126
greybus 1-2.2: excess descriptors in interface manifest
mikrobus:mikrobus_port_gb_register: mikrobus gb_probe , num cports= 3, manifest_size 252
mikrobus:mikrobus_port_gb_register: protocol added 11
mikrobus:mikrobus_port_gb_register: protocol added 3
mikrobus:mikrobus_port_gb_register: protocol added 2
mikrobus:mikrobus_port_register: registering port mikrobus-0
mikrobus_manifest:mikrobus_manifest_attach_device: parsed device 1, driver=bme280, protocol=3, reg=76
mikrobus_manifest:mikrobus_manifest_attach_device: parsed device 2, driver=ams-iaq-core, protocol=3, reg=5a
mikrobus_manifest:mikrobus_manifest_parse:  Greybus Service Sample Application manifest parsed with 2 devices
mikrobus mikrobus-0: registering device : bme280
mikrobus mikrobus-0: registering device : ams-iaq-core
```

WARNING: TODO bring in the GPIO toggle and I2C explorations for greater understanding

=== Flashing via a Linux Host
If flashing the Freedom board via the BeagleBone fails here's a trick you can try to flash from a Linux host.

Use `sshfs` to mount the Bone's files on the Linux host.  This assumes the Bone is plugged in the the USB
and appears at `192.168.7.2`:

```
host$ cd
host$ sshfs 192.168.7.2:/ bone
host$ cd bone; ls
bin   dev  home    lib         media  opt   root  sbin  sys  usr
boot  etc  ID.txt  lost+found  mnt    proc  run   srv   tmp  var
host$ ls /dev/ttyACM*
/dev/ttyACM1

```
The Bone's files now appear as local files.  Notice there is already a
`/dev/ACM` appearing.  Now plug the Connect into the Linux host's USB port
and run the command again.

```
host$ ls /dev/ttyACM*
/dev/ttyACM0  /dev/ttyACM1

```

The `/dev/ttyASM` that just appeared is the one associated with the Connect.
In my case it's `/dev/ttyACM0`.  That's what I'll use in this example.

Now change directories to where the binaries are and load:

```
host$ cd ~/bone/usr/share/beagleconnect/cc1352;ls
greybus_mikrobus_beagleconnect.bin     sensortest_beagleconnect.dts
greybus_mikrobus_beagleconnect.config  wpanusb_beagleconnect.bin
greybus_mikrobus_beagleconnect.dts     wpanusb_beagleconnect.config
sensortest_beagleconnect.bin           wpanusb_beagleconnect.dts
sensortest_beagleconnect.config

host$ ~/bone/usr/bin/cc2538-bsl.py sensortest_beagleconnect.bin /dev/ttyACM0
8-bsl.py sensortest_beagleconnect.bin /dev/ttyACM0
Opening port /dev/ttyACM0, baud 50000
Reading data from sensortest_beagleconnect.bin
Cannot auto-detect firmware filetype: Assuming .bin
Connecting to target...
CC1350 PG2.0 (7x7mm): 352KB Flash, 20KB SRAM, CCFG.BL_CONFIG at 0x00057FD8
Primary IEEE Address: 00:12:4B:00:22:7A:10:46
    Performing mass erase
Erasing all main bank flash sectors
    Erase done
Writing 360448 bytes starting at address 0x00000000
Write 104 bytes at 0x00057F988
    Write done                                
Verifying by comparing CRC32 calculations.
    Verified (match: 0x0f6bdf0f)
```

Now you are ready to continue the instructions above after the cc2528 command.

==== Trying for different add-on boards

See https://github.com/vaishnav98/greybus-for-zephyr/tree/mikrobus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[mikroBUS over Greybus] for trying out the same example for different mikroBUS add-on boards/ on-board devices.

== Observe the node device

Connect BeagleConnect Freedom node device to an Ubuntu laptop to observe the Zephyr console.

=== Console (`tio`)

In order to see diagnostic messages or to run certain commands on the
Zephyr device we will require a terminal open to the device console. In
this case, we use https://tio.github.io/[tio] due how its usage
simplifies the instructions.

==== Install `tio`

[source,console]
----
sudo apt install -y tio
----

==== Run `tio`

Now, we’ll open a terminal to Zephyr using the newly created setup with
the command below.

[source,console]
----
tio /dev/ttyACM0
----

IMPORTANT: To exit `tio` (later), enter `ctrl+t, q`.

=== The Zephyr Shell

After flashing, you should observe the something matching the following
output in `tio`.

....
uart:~$ *** Booting Zephyr OS build 9c858c863223  ***
[00:00:00.009,735] <inf> greybus_transport_tcpip: CPort 0 mapped to TCP/IP port 4242
[00:00:00.010,131] <inf> greybus_transport_tcpip: CPort 1 mapped to TCP/IP port 4243
[00:00:00.010,528] <inf> greybus_transport_tcpip: CPort 2 mapped to TCP/IP port 4244
[00:00:00.010,742] <inf> greybus_transport_tcpip: Greybus TCP/IP Transport initialized
[00:00:00.010,864] <inf> greybus_manifest: Registering CONTROL greybus driver.
[00:00:00.011,230] <inf> greybus_manifest: Registering GPIO greybus driver.
[00:00:00.011,596] <inf> greybus_manifest: Registering I2C greybus driver.
[00:00:00.011,871] <inf> greybus_service: Greybus is active
[00:00:00.026,092] <inf> net_config: Initializing network
[00:00:00.134,063] <inf> net_config: IPv6 address: 2001:db8::1
....

The line beginning with `+++***+++` is the Zephyr boot banner.

Lines beginning with a timestamp of the form `[H:m:s.us]` are Zephyr
kernel messages.

Lines beginning with `uart:~$` indicates that the Zephyr shell is
prompting you to enter a command.

From the informational messages shown, we observe the following.

* Zephyr is configured with the following
https://en.wikipedia.org/wiki/Link-local_address#IPv6[link-local IPv6
address] `fe80::3177:a11c:4b:1200`
* It is listening for (both) TCP and UDP traffic on port 4242

However, what the log messages do _not_ show (which will come into play
later), are 2 critical pieces of information:

1. *The RF Channel*: As you
may have guessed, IEEE 802.15.4 devices are only able to communicate
with each other if they are using the same frequency to transmit and
recieve data. This information is part of the Physical Layer.
2. The
https://www.silabs.com/community/wireless/proprietary/knowledge-base.entry.html/2019/10/04/connect_tutorial6-ieee802154addressing-rapc[PAN
identifier]: IEEE 802.15.4 devices are only be able to communicate with
one another if they use the _same_ PAN ID. This permits multiple
networks (PANs) on the same frequency. This information is part of the
Data Link Layer.

If we type `help` in the shell and hit _Enter_, we’re prompted with the
following:

[source,console]
----
Please press the <Tab> button to see all available commands.
You can also use the <Tab> button to prompt or auto-complete all commands or its subcommands.
You can try to call commands with <-h> or <--help> parameter for more information.
Shell supports following meta-keys:

Ctrl+a, Ctrl+b, Ctrl+c, Ctrl+d, Ctrl+e, Ctrl+f, Ctrl+k, Ctrl+l, Ctrl+n, Ctrl+p, Ctrl+u, Ctrl+w
Alt+b, Alt+f.
Please refer to shell documentation for more details.

----

So after hitting _Tab_, we see that there are several interesting
commands we can use for additional information.

[source,console]
----
uart:~$ 
  clear       help        history     ieee802154  log         net
  resize      sample      shell
----

===== Zephyr Shell: IEEE 802.15.4 commands

Entering `ieee802154 help`, we see

[source,console]
----
uart:~$ ieee802154 help
ieee802154 - IEEE 802.15.4 commands
Subcommands:
  ack             :<set/1 | unset/0> Set auto-ack flag
  associate       :<pan_id> <PAN coordinator short or long address (EUI-64)>
  disassociate    :Disassociate from network
  get_chan        :Get currently used channel
  get_ext_addr    :Get currently used extended address
  get_pan_id      :Get currently used PAN id
  get_short_addr  :Get currently used short address
  get_tx_power    :Get currently used TX power
  scan            :<passive|active> <channels set n[:m:...]:x|all> <per-channel
                   duration in ms>
  set_chan        :<channel> Set used channel
  set_ext_addr    :<long/extended address (EUI-64)> Set extended address
  set_pan_id      :<pan_id> Set used PAN id
  set_short_addr  :<short address> Set short address
  set_tx_power    :<-18/-7/-4/-2/0/1/2/3/5> Set TX power
----

We get the missing Channel number (frequency) with the command
`ieee802154 get_chan`.

[source,console]
----
uart:~$ ieee802154 get_chan
Channel 26
----

We get the missing PAN ID with the command `ieee802154 get_pan_id`.

[source,console]
----
uart:~$ ieee802154 get_pan_id
PAN ID 43981 (0xabcd)
----

===== Zephyr Shell: Network Commands

Additionally, we may query the IPv6 information of the Zephyr device.

[source,console]
----
uart:~$ net iface

Interface 0x20002b20 (IEEE 802.15.4) [1]
========================================
Link addr : CD:99:A1:1C:00:4B:12:00
MTU       : 125
IPv6 unicast addresses (max 3):
        fe80::cf99:a11c:4b:1200 autoconf preferred infinite
        2001:db8::1 manual preferred infinite
IPv6 multicast addresses (max 4):
        ff02::1
        ff02::1:ff4b:1200
        ff02::1:ff00:1
IPv6 prefixes (max 2):
        <none>
IPv6 hop limit           : 64
IPv6 base reachable time : 30000
IPv6 reachable time      : 16929
IPv6 retransmit timer    : 0
----

And we see that the static IPv6 address (`2001:db8::1`) from
`samples/net/sockets/echo_server/prj.conf` is present and configured.
While the statically configured IPv6 address is useful, it isn’t 100%
necessary.

== Rebuilding from source

WARNING: TODO revisit everything below here

=== Prerequisites

* Zephyr environment is set up according to the
https://docs.zephyrproject.org/latest/getting_started/index.html[Getting
Started Guide]
** Please use the Zephyr SDK when installing a toolchain above
* https://docs.zephyrproject.org/latest/getting_started/index.html#install-a-toolchain[Zephyr
SDK] is installed at ~/zephyr-sdk-0.11.2 (any later version should be
fine as well)
* Zephyr board is connected via USB

=== Cloning the repository

This repository utilizes
https://git-scm.com/book/en/v2/Git-Tools-Submodules[git submodules] to keep
track of all of the projects required to reproduce the on-going work.
The instructions here only cover checking out the `demo` branch which
should stay in a tested state. On-going development will be on the
`master` branch.

NOTE: The parent directory `~` is simply used as a placeholder for testing.
Please use whatever parent directory you see fit.

==== Clone specific tag

[source,console]
----
cd ~
git clone --recurse-submodules --branch demo https://github.com/jadonk/beagleconnect
----

=== Zephyr

==== Add the Fork

For the time being, Greybus must remain outside of the main Zephyr
repository. Currently, it is just in a Zephyr fork, but it should be
converted to a proper
https://docs.zephyrproject.org/latest/guides/modules.html[Module
(External Project)]. This is for a number of reasons, but mainly there
must be:

* specifications for authentication and encryption 
* specifications for joining and rejoining wireless networks 
* specifications for discovery

Therefore, in order to reproduce this example, please run the following.

NOTE: Open a separate terminal window (`Ctrl+Shift+N`) or simply create a
new tab in your existing terminal (`Ctrl+Shift+T`) so that you can see
both or quickly switch between `tio` and the shell.

[source,console]
----
cd ~/beagleconnect/sw/zephyrproject/zephyr
west update
----

==== Build and Flash Zephyr

Here, we will build and flash the Zephyr
https://github.com/cfriedt/zephyr/tree/greybus-sockets/samples/subsys/greybus/net[greybus_net
sample] to our device.

[arabic]
. Edit the file `~/.zephyrrc` and place the following text inside of it
+
[source,console]
----
export ZEPHYR_TOOLCHAIN_VARIANT=zephyr
export ZEPHYR_SDK_INSTALL_DIR=~/zephyr-sdk-0.11.2
----
+
. Set up the required Zephyr environment variables via
+
[source,console]
----
source zephyr-env.sh
----
+
. Build the project
+
[source,console]
----
BOARD=cc1352r1_launchxl west build samples/subsys/greybus/net --pristine \
  --build-dir build/greybus_launchpad -- -DCONF_FILE="prj.conf overlay-802154.conf"
----
+
. Ensure that the last part of the build process looks somewhat like
this:
+
....
...
[221/226] Linking C executable zephyr/zephyr_prebuilt.elf
Memory region         Used Size  Region Size  %age Used
           FLASH:      155760 B     360360 B     43.22%
      FLASH_CCFG:          88 B         88 B    100.00%
            SRAM:       58496 B        80 KB     71.41%
        IDT_LIST:         184 B         2 KB      8.98%
[226/226] Linking C executable zephyr/zephyr.elf
....
+
. Flash the firmware to your device using
+
[source,console]
----
BOARD=cc1352r1_launchxl west flash --build-dir build/greybus_launchpad
----

[[linux]]
=== Linux

WARNING: If you aren't comfortable building and installing a Linux kernel on your computer,
you should probably just stop here. I'll assume you know the basics of building and installing
a Linux kernel from here on out.

==== Clone, patch, and build the kernel
For this demo, I used the 5.8.4 stable kernel. Also, I've applied the `mikrobus` kernel
driver, though it isn't strictly required for greybus.

NOTE: Again, `~` is just used as a placeholder and you can use whatever directory you'd like.

WARNING: TODO The patches for gb-netlink will eventually be applied here until pushed into mainline.#

[source,console]
----
cd ~
git clone --branch v5.8.4 --single-branch git://git.kernel.org/pub/scm/linux/kernel/git/stable/linux.git
cd linux
git checkout -b v5.8.4-greybus
git am ~/beagleconnect/sw/linux/v2-0001-RFC-mikroBUS-driver-for-add-on-boards.patch
git am ~/beagleconnect/sw/linux/0001-mikroBUS-build-fixes.patch
cp /boot/config-`uname -r` .config
yes "" | make oldconfig
./scripts/kconfig/merge_config.sh .config ~/beagleconnect/sw/linux/mikrobus.config
./scripts/kconfig/merge_config.sh .config ~/beagleconnect/sw/linux/atusb.config
make -j`nproc --all`
sudo make modules_install
sudo make install
----

Reboot and select your new kernel.

==== Probe the IEEE 802.15.4 Device Driver

On the Linux machine, make sure the `atusb` driver is loaded. This should happen automatically
when the adapter is inserted or when the machine is booted while the adapter is installed.

[source,console]
----
$ dmesg | grep -i ATUSB
[    6.512154] usb 1-1: ATUSB: AT86RF231 version 2
[    6.512492] usb 1-1: Firmware: major: 0, minor: 3, hardware type: ATUSB (2)
[    6.525357] usbcore: registered new interface driver atusb
...
----

We should now be able to see the IEEE 802.15.4 network device by
entering `ip a show wpan0`.

[source,console]
----
$ ip a show wpan0
36: wpan0: <BROADCAST,NOARP,UP,LOWER_UP> mtu 123 qdisc fq_codel state UNKNOWN group default qlen 300
    link/ieee802.15.4 3e:7d:90:4d:8f:00:76:a2 brd ff:ff:ff:ff:ff:ff:ff:ff
----

But wait, that is not an IP address! It’s the hardware address of the
802.15.4 device. So, in order to associate it with an IP address, we
need to run a couple of other commands (thanks to
http://wpan.cakelab.org/[cakelab.org]).

==== Set the 802.15.4 Physical and Link-Layer Parameters

[arabic]
. First, get the phy number for the `wpan0` device
+
[source,console]
----
$ iwpan list
     wpan_phy phy0
     supported channels:
        page 0: 11,12,13,14,15,16,17,18,19,20,21,22,23,24,25,26
      current_page: 0
     current_channel: 26,  2480 MHz
     cca_mode: (1) Energy above threshold
     cca_ed_level: -77
     tx_power: 3
     capabilities:
         iftypes: node,monitor
          channels:
             page 0:
                  [11]  2405 MHz, [12]  2410 MHz, [13]  2415 MHz,
                  [14]  2420 MHz, [15]  2425 MHz, [16]  2430 MHz,
                  [17]  2435 MHz, [18]  2440 MHz, [19]  2445 MHz,
                  [20]  2450 MHz, [21]  2455 MHz, [22]  2460 MHz,
                  [23]  2465 MHz, [24]  2470 MHz, [25]  2475 MHz,
                  [26]  2480 MHz
           tx_powers:
                  3 dBm, 2.8 dBm, 2.3 dBm, 1.8 dBm, 1.3 dBm, 0.7 dBm,
                  0 dBm, -1 dBm, -2 dBm, -3 dBm, -4 dBm, -5 dBm,
                  -7 dBm, -9 dBm, -12 dBm, -17 dBm,
          cca_ed_levels:
                  -91 dBm, -89 dBm, -87 dBm, -85 dBm, -83 dBm, -81 dBm,
                  -79 dBm, -77 dBm, -75 dBm, -73 dBm, -71 dBm, -69 dBm,
                  -67 dBm, -65 dBm, -63 dBm, -61 dBm,
          cca_modes:
              (1) Energy above threshold
             (2) Carrier sense only
             (3, cca_opt: 0) Carrier sense with energy above threshold (logical operator is 'and')
             (3, cca_opt: 1) Carrier sense with energy above threshold (logical operator is 'or')
         min_be: 0,1,2,3,4,5,6,7,8
          max_be: 3,4,5,6,7,8
          csma_backoffs: 0,1,2,3,4,5
          frame_retries: 3
          lbt: false
----
+
. Next, set the Channel for the 802.15.4 device on the Linux machine
+
[source,console]
----
sudo iwpan phy phy0 set channel 0 26
----
+
. Then, set the PAN identifier for the 802.15.4 device on the Linux
machine `sudo iwpan dev wpan0 set pan_id 0xabcd` ## Create a
6LowPAN Network Interface
. Associate the `wpan0` device to a new, 6lowpan network interface
+
[source,console]
----
sudo ip link add link wpan0 name lowpan0 type lowpan
----
+
. Finally, set the links up for both `wpan0` and `lowpan0`
+
[source,console]
----
sudo ip link set wpan0 up
sudo ip link set lowpan0 up
----

We should observe something like the following when we run
`ip a show lowpan0`.

[source,console]
----
ip a show lowpan0
37: lowpan0@wpan0: <BROADCAST,MULTICAST,UP,LOWER_UP> mtu 1280 qdisc noqueue state UNKNOWN group default qlen 1000
    link/6lowpan 9e:0b:a4:e8:00:d3:45:53 brd ff:ff:ff:ff:ff:ff:ff:ff
    inet6 fe80::9c0b:a4e8:d3:4553/64 scope link 
       valid_lft forever preferred_lft forever
----

=== Ping Pong

==== Broadcast Ping

Now, perform a broadcast ping to see what else is listening on
`lowpan0`.

[source,console]
----
$ ping6 -I lowpan0 ff02::1
PING ff02::1(ff02::1) from fe80::9c0b:a4e8:d3:4553%lowpan0 lowpan0: 56 data bytes
64 bytes from fe80::9c0b:a4e8:d3:4553%lowpan0: icmp_seq=1 ttl=64 time=0.099 ms
64 bytes from fe80::9c0b:a4e8:d3:4553%lowpan0: icmp_seq=2 ttl=64 time=0.125 ms
64 bytes from fe80::cf99:a11c:4b:1200%lowpan0: icmp_seq=2 ttl=64 time=17.3 ms (DUP!)
64 bytes from fe80::9c0b:a4e8:d3:4553%lowpan0: icmp_seq=3 ttl=64 time=0.126 ms
64 bytes from fe80::cf99:a11c:4b:1200%lowpan0: icmp_seq=3 ttl=64 time=9.60 ms (DUP!)
64 bytes from fe80::9c0b:a4e8:d3:4553%lowpan0: icmp_seq=4 ttl=64 time=0.131 ms
64 bytes from fe80::cf99:a11c:4b:1200%lowpan0: icmp_seq=4 ttl=64 time=14.9 ms (DUP!)
----

Yay! We have pinged (pung?) the Zephyr device over IEEE 802.15.4 using
6LowPAN!

==== Ping Zephyr

We can ping the Zephyr device directly without a broadcast ping too, of
course.

[source,console]
----
$ ping6 -I lowpan0 fe80::cf99:a11c:4b:1200
PING fe80::cf99:a11c:4b:1200(fe80::cf99:a11c:4b:1200) from fe80::9c0b:a4e8:d3:4553%lowpan0 lowpan0: 56 data bytes
64 bytes from fe80::cf99:a11c:4b:1200%lowpan0: icmp_seq=1 ttl=64 time=16.0 ms
64 bytes from fe80::cf99:a11c:4b:1200%lowpan0: icmp_seq=2 ttl=64 time=13.8 ms
64 bytes from fe80::cf99:a11c:4b:1200%lowpan0: icmp_seq=3 ttl=64 time=9.77 ms
64 bytes from fe80::cf99:a11c:4b:1200%lowpan0: icmp_seq=5 ttl=64 time=11.5 ms
----

==== Ping Linux

Similarly, we can ping the Linux host from the Zephyr shell.

[source,console]
----
uart:~$ net ping --help
ping - Ping a network host.
Subcommands:
  --help  :'net ping [-c count] [-i interval ms] <host>' Send ICMPv4 or ICMPv6
           Echo-Request to a network host.
$ net ping -c 5 fe80::9c0b:a4e8:d3:4553
PING fe80::9c0b:a4e8:d3:4553
8 bytes from fe80::9c0b:a4e8:d3:4553 to fe80::cf99:a11c:4b:1200: icmp_seq=0 ttl=64 rssi=110 time=11 ms
8 bytes from fe80::9c0b:a4e8:d3:4553 to fe80::cf99:a11c:4b:1200: icmp_seq=1 ttl=64 rssi=126 time=9 ms
8 bytes from fe80::9c0b:a4e8:d3:4553 to fe80::cf99:a11c:4b:1200: icmp_seq=2 ttl=64 rssi=128 time=13 ms
8 bytes from fe80::9c0b:a4e8:d3:4553 to fe80::cf99:a11c:4b:1200: icmp_seq=3 ttl=64 rssi=126 time=10 ms
8 bytes from fe80::9c0b:a4e8:d3:4553 to fe80::cf99:a11c:4b:1200: icmp_seq=4 ttl=64 rssi=126 time=7 ms
----

==== Assign a Static Address

So far, we have been using IPv6 Link-Local addressing. However, the
Zephyr application is configured to use a statically configured IPv6
address as well which is, namely `2001:db8::1`.

If we add a similar static IPv6 address to our Linux IEEE 802.15.4
network interface, `lowpan0`, then we should expect to be able to reach
that as well.

In Linux, run the following

[source,console]
----
sudo ip -6 addr add 2001:db8::2/64 dev lowpan0
----

We can verify that the address has been set by examining the `lowpan0`
network interface again.

[source,console]
----
$ ip a show lowpan0
37: lowpan0@wpan0: <BROADCAST,MULTICAST,UP,LOWER_UP> mtu 1280 qdisc noqueue state UNKNOWN group default qlen 1000
    link/6lowpan 9e:0b:a4:e8:00:d3:45:53 brd ff:ff:ff:ff:ff:ff:ff:ff
    inet6 2001:db8::2/64 scope global 
       valid_lft forever preferred_lft forever
    inet6 fe80::9c0b:a4e8:d3:4553/64 scope link 
       valid_lft forever preferred_lft forever
----

Lastly, ping the statically configured IPv6 address of the Zephyr
device.

[source,console]
----
$ ping6 2001:db8::1
PING 2001:db8::1(2001:db8::1) 56 data bytes
64 bytes from 2001:db8::1: icmp_seq=2 ttl=64 time=53.7 ms
64 bytes from 2001:db8::1: icmp_seq=3 ttl=64 time=13.1 ms
64 bytes from 2001:db8::1: icmp_seq=4 ttl=64 time=22.0 ms
64 bytes from 2001:db8::1: icmp_seq=5 ttl=64 time=22.7 ms
64 bytes from 2001:db8::1: icmp_seq=6 ttl=64 time=18.4 ms
----

Now that we have set up a reliable transport, let’s move on to the
application layer.

=== Greybus

Hopefully the videos listed earlier provide a sufficient foundation to
understand what will happen shortly. However, there is still a bit more
preparation required.

==== Build and probe Greybus Kernel Modules

Greybus was originally intended to work exclusively on the UniPro
physical layer. However, we’re using RF as our physical layer and TCP/IP
as our transport. As such, there was need to be able to communicate with
the Linux Greybus facilities through userspace, and out of that need
arose gb-netlink. The Netlink Greybus module actually does not care
about the physical layer, but is happy to usher Greybus messages back
and forth between the kernel and userspace.

Build and probe the gb-netlink modules (as well as the other Greybus
modules) with the following:

[source,console]
----
cd ${WORKSPACE}/sw/greybus
make -j`nproc --all`
sudo make install
../load_gb_modules.sh
----

==== Build and Run Gbridge

The gbridge utility was created as a proof of concept to abstract the
Greybus Netlink datapath among several reliable transports. For the
purposes of this tutorial, we’ll be using it as a TCP/IP bridge.

To run `gbridge`, perform the following:

[source,console]
----
sudo apt install -y libnl-3-dev libnl-genl-3-dev libbluetooth-dev libavahi-client-dev
cd gbridge
autoreconf -vfi
GBNETLINKDIR=${PWD}/../greybus \
  ./configure --enable-uart --enable-tcpip --disable-gbsim --enable-netlink --disable-bluetooth
make -j`nproc --all`
sudo make install
gbridge
----

=== Blinky!

Now that we have set up a reliable TCP transport, and set up the Greybus
modules in the Linux kernel, and used Gbridge to connect a Greybus node
to the Linux kernel via TCP/IP, we can now get to the heart of the
demonstration!

First, save the following script as `blinky.sh`.

[source,bash]
----
#!/bin/bash

# Blinky Demo for CC1352R SensorTag

# /dev/gpiochipN that Greybus created
CHIP="$(gpiodetect | grep greybus_gpio | head -n 1 | awk '{print $1}')"

# red, green, blue LED pins
RED=6
GREEN=7
BLUE=21

# Bash array for pins and values
PINS=($RED $GREEN $BLUE)
NPINS=${#PINS[@]}

for ((;;)); do
    for i in ${!PINS[@]}; do
        # turn off previous pin
        if [ $i -eq 0 ]; then
            PREV=2
        else
            PREV=$((i-1))
        fi
        gpioset $CHIP ${PINS[$PREV]}=0

        # turn on current pin
        gpioset $CHIP ${PINS[$i]}=1

        # wait a sec
        sleep 1
    done
done
----

Second, run the script with root privileges: `sudo bash blinky.sh`

The output of your minicom session should resemble the following.

[source,console]
----
$ *** Booting Zephyr OS build zephyr-v2.3.0-1435-g40c0ed940d71  ***
[00:00:00.011,932] <inf> net_config: Initializing network
[00:00:00.111,938] <inf> net_config: IPv6 address: fe80::6c42:bc1c:4b:1200
[00:00:00.112,121] <dbg> greybus_service.greybus_service_init: Greybus initializing..
[00:00:00.112,426] <dbg> greybus_transport_tcpip.gb_transport_backend_init: Greybus TCP/IP Transport initializing..
[00:00:00.112,579] <dbg> greybus_transport_tcpip.netsetup: created server socket 0 for cport 0
[00:00:00.112,579] <dbg> greybus_transport_tcpip.netsetup: setting socket options for socket 0
[00:00:00.112,609] <dbg> greybus_transport_tcpip.netsetup: binding socket 0 (cport 0) to port 4242
[00:00:00.112,640] <dbg> greybus_transport_tcpip.netsetup: listening on socket 0 (cport 0)
[00:00:00.112,823] <dbg> greybus_transport_tcpip.netsetup: created server socket 1 for cport 1
[00:00:00.112,823] <dbg> greybus_transport_tcpip.netsetup: setting socket options for socket 1
[00:00:00.112,854] <dbg> greybus_transport_tcpip.netsetup: binding socket 1 (cport 1) to port 4243
[00:00:00.112,854] <dbg> greybus_transport_tcpip.netsetup: listening on socket 1 (cport 1)
[00:00:00.113,037] <inf> net_config: IPv6 address: fe80::6c42:bc1c:4b:1200
[00:00:00.113,250] <dbg> greybus_transport_tcpip.netsetup: created server socket 2 for cport 2
[00:00:00.113,250] <dbg> greybus_transport_tcpip.netsetup: setting socket options for socket 2
[00:00:00.113,281] <dbg> greybus_transport_tcpip.netsetup: binding socket 2 (cport 2) to port 4244
[00:00:00.113,311] <dbg> greybus_transport_tcpip.netsetup: listening on socket 2 (cport 2)
[00:00:00.113,494] <dbg> greybus_transport_tcpip.netsetup: created server socket 3 for cport 3
[00:00:00.113,494] <dbg> greybus_transport_tcpip.netsetup: setting socket options for socket 3
[00:00:00.113,525] <dbg> greybus_transport_tcpip.netsetup: binding socket 3 (cport 3) to port 4245
[00:00:00.113,555] <dbg> greybus_transport_tcpip.netsetup: listening on socket 3 (cport 3)
[00:00:00.113,861] <inf> greybus_transport_tcpip: Greybus TCP/IP Transport initialized
[00:00:00.116,149] <inf> greybus_service: Greybus is active
[00:00:00.116,546] <dbg> greybus_transport_tcpip.accept_loop: calling poll
[00:45:08.397,399] <dbg> greybus_transport_tcpip.accept_loop: poll returned 1
[00:45:08.397,399] <dbg> greybus_transport_tcpip.accept_loop: socket 0 (cport 0) has traffic
[00:45:08.397,491] <dbg> greybus_transport_tcpip.accept_loop: accepted connection from [2001:db8::2]:39638 as fd 4
[00:45:08.397,491] <dbg> greybus_transport_tcpip.accept_loop: spawning client thread..
[00:45:08.397,735] <dbg> greybus_transport_tcpip.accept_loop: calling poll
[00:45:08.491,363] <dbg> greybus_transport_tcpip.accept_loop: poll returned 1
[00:45:08.491,363] <dbg> greybus_transport_tcpip.accept_loop: socket 3 (cport 3) has traffic
[00:45:08.491,455] <dbg> greybus_transport_tcpip.accept_loop: accepted connection from [2001:db8::2]:39890 as fd 5
[00:45:08.491,455] <dbg> greybus_transport_tcpip.accept_loop: spawning client thread..
[00:45:08.491,699] <dbg> greybus_transport_tcpip.accept_loop: calling poll
[00:45:08.620,056] <dbg> greybus_transport_tcpip.accept_loop: poll returned 1
[00:45:08.620,086] <dbg> greybus_transport_tcpip.accept_loop: socket 2 (cport 2) has traffic
[00:45:08.620,147] <dbg> greybus_transport_tcpip.accept_loop: accepted connection from [2001:db8::2]:42422 as fd 6
[00:45:08.620,147] <dbg> greybus_transport_tcpip.accept_loop: spawning client thread..
[00:45:08.620,422] <dbg> greybus_transport_tcpip.accept_loop: calling poll
[00:45:08.679,504] <dbg> greybus_transport_tcpip.accept_loop: poll returned 1
[00:45:08.679,534] <dbg> greybus_transport_tcpip.accept_loop: socket 1 (cport 1) has traffic
[00:45:08.679,595] <dbg> greybus_transport_tcpip.accept_loop: accepted connection from [2001:db8::2]:48286 as fd 7
[00:45:08.679,595] <dbg> greybus_transport_tcpip.accept_loop: spawning client thread..
[00:45:08.679,870] <dbg> greybus_transport_tcpip.accept_loop: calling poll
...
----

=== Read I2C Registers

The SensorTag comes with an opt3001 ambient light sensor as well as an
hdc2080 temperature & humidity sensor.

First, find which i2c device corresponds to the SensorTag:

[source,bash]
----
ls -la /sys/bus/i2c/devices/* | grep "greybus"
lrwxrwxrwx 1 root root 0 Aug 15 11:24 /sys/bus/i2c/devices/i2c-8 -> ../../../devices/virtual/gb_nl/gn_nl/greybus1/1-2/1-2.2/1-2.2.2/gbphy2/i2c-8
----

On my machine, the i2c device node that Greybus creates is /dev/i2c-8.

Read the ID registers (at the i2c register address 0x7e) of the opt3001
sensor (at i2c bus address 0x44) as shown below:

[source,bash]
----
i2cget -y 8 0x44 0x7e w
0x4954
----

Read the ID registers (at the i2c register address 0xfc) of the hdc2080
sensor (at i2c bus address 0x41) as shown below:

[source,bash]
----
i2cget -y 8 0x41 0xfc w 
0x5449
----

=== Conclusion

The blinking LED can and poking i2c registers can be a somewhat
anticlimactic, but hopefully it illustrates the potential for Greybus as
an IoT application layer protocol.

What is nice about this demo, is that we’re using Device Tree to
describe our Greybus Peripheral declaratively, they Greybus Manifest is
automatically generated, and the Greybus Service is automatically
started in Zephyr.

In other words, all that is required to replicate this for other IoT
devices is simply an appropriate Device Tree overlay file.

The proof-of-concept involving Linux, Zephyr, and IEEE 802.15.4 was
actually fairly straight forward and was accomplished with mostly
already-upstream source.

For Greybus in Zephyr, there is still a considerable amount of
integration work to be done, including
* converting the fork to a proper
Zephyr module
* adding security and authentication
* automatic
detection, joining, and rejoining of devices

Thanks for reading, and we hope you’ve enjoyed this tutorial.

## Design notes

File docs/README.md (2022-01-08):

# BeagleConnect Documentation

This is a work-in-progress for some placeholder documentation
that is likely to get moved around to different places as it
solidifies. The [top-level README](../README.asciidoc) is the
main getting started documentation for now and I'll migrate
some of this over as I can work it out.

Some other place-holders here:

* [LEDs](LED.md)
* [MSP430](MSP430.md)
* [Green Gateway](Green_Gateway.md)
* [Roadmap](ROADMAP.md)

# Overall software architecture

Block Diagram

\*\* - New code generated in this project

## User Application

We have a lot more layers to add here, but the basic entry into developing
with BeagleConnect Freedom is to create a User Application that will interact
with sensors and actuators over the Linux IIO subsystem, primarily.

TODO: Provide IIO layers to WebThings, Jupyter Notebooks (Python and Julia) and more.

## IIO Drivers

There are hundreds of drivers included in the Linux kernel for interacting
with sensors. This is one of the fundamental code bases upon which this project
is building. It provides an abstract interface such that the sensor data is
self-describing. You can query for lists of sensors and what they measure.

TODO: Think about how we want to augment this interface with network, location
and other metadata to help leverage the sensor data intelligently.

Further reading: 
* [ADI IIO docs](https://wiki.analog.com/software/linux/docs/iio/iio)
* [Linux kernel IIO docs](https://www.kernel.org/doc/html/latest/driver-api/iio/intro.html)

## mikrobus\*\*

This kernel driver provides a pin-exact abstraction for sensor boards and
an identification mechanism that can be used to load the appropriate IIO Drivers
for a given sensor board.

This driver can be used with or without Greybus to make usage of mikroBUS add-on
boards not require the addition of device tree overlays or kernel modifications.

TODO: This driver needs to be resubmitted upstream and the manifest format should
be aligned.

RISK: The manifest format might not be sufficiently defined and approved upstream.

Further reading:
* [LPC 2020 presentation](https://linuxplumbersconf.org/event/7/contributions/669/)
* [mikroBUS driver wiki](https://elinux.org/Mikrobus)

## greybus

This kernel driver enables the embedded busses used to connect sensors, like SPI,
I2C, UART, ADC and GPIO, to be dynamically added to a system and for transactions
on them to be performed on an RPC-like mechanism.

Further reading:
* [GKH Intro to Greybus](https://kernel-recipes.org/en/2015/talks/an-introduction-to-greybus/)
* [RPC on Wikipedia](https://en.wikipedia.org/wiki/Remote_procedure_call)

## gb-netlink\*\*

This kernel driver provides a netlink interface as an alternative transport
for Greybus, rather than the initial UniPro interface it supports in mobile
phones.

TODO: This should be ready to go into the upstream Linux kernel.

## gbridge\*\*

This application utilizes the gb-netlink driver to extend Greybus to any
transport, including IPv6.

TODO: This is the least stable part of the code stack and needs significant
error handling updates and to provide additional metadata to users.

Futher reading:
* [Greybus for IoT at ELC on Youtube](https://www.youtube.com/watch?v=7H50pv-4YXw&list=PLbzoR-pLrL6pRFP6SOywVJWdEHlmQE51q) [slides](https://elinux.org/images/c/cb/Using_Greybus_for_IoT.pdf)

## lowpan/ieee802154

These drivers provide the upper networking layers for talking to the BeagleConnect Freedom
Sub-GHz network.

Further reading:
* [6LoWPAN on Wikipedia](https://en.wikipedia.org/wiki/6LoWPAN)

## wpanusb\*\*

This kernel driver is used by a number of IEEE802.15.4 MAC compatbible devices to provide
an interface to low-power, long-range wireless networks over USB.

TODO: This should be ready to go into the upstream Linux kernel.

Futher reading:
* [wpanusb driver on Github](https://github.com/finikorg/wpanusb)
* [Zephyr sample](https://docs.zephyrproject.org/2.6.0/samples/net/wpanusb/README.html)

## usb\_uart\_bridge\*\*

This MSP430 firmware acts as both a USB-to-UART bridge to access the Zephyr console on the
CC1352 as well as capturing WPANUSB USB actions and sending those to the CC1352 over HDLC.

Further reading:
* [BCF MSP430 doc](MSP430.md)
* [Source code](https://github.com/jadonk/msp430F55xx_usb_uart_bridge)
* [HDLC on Wikipedia](https://en.wikipedia.org/wiki/High-Level_Data_Link_Control)

## gateway\*\*

This CC1352 Zephyr-based firmware acts as an IEEE802.15.4 radio accepting HDLC encoded
transactions over the CC1352 UART.

TODO: This needs to be integrated into a single firmware image.

TODO: The UART pin-flip issue must be addressed along with dynamic UART selection for
the console and the HDLC-based radio interface.

Further reading:
* [wpanusb\_bc source code on Github](https://github.com/jadonk/wpanusb_bc)

## greybus-mikrobus\*\*

This CC1352 Zephyr-based firmware takes Greybus transactions provided via IPv6 packets
over a IEEE802.15.4 radio and converts them into mikroBUS provided hardware interface
busses, including I2C, SPI, UART and GPIO.

TODO: Loading new manifests into non-volatile storage needs to be made easier from
the command-line until the manifest 1-wire EEPROMs become commonplace.

TODO: The UART pin-flip issue must be addressed.

Further reading:
* [greybus-for-zephyr source code on Github](https://github.com/jadonk/greybus-for-zephyr)

## Summary

Futher reading:
* [LPC2020 presentation: Using Linux, Zephyr & Greybus for IoT](https://linuxplumbersconf.org/event/7/contributions/814/)

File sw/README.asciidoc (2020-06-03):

= BeagleConnect software projects

== Linux side
* *mikrobus* is a Linux kernel driver for mikroBUS sensor, actuator and indicator add-on boards.
* *manifesto* is a tool for converting text-based parameters into binary files. The tool is used for two purposes. One,  describe the interfaces exported over Greybus to Linux. Two, describe the parameters for the mikroBUS driver to load device drivers for the add-on board.
* *greybus* is the Linux kernel driver that enables new embedded busses to be added to the running Linux kernel and sent over other transports.
* *gbridge* is a Linux userspace application that implements other transports for Greybus, including transmission over IP.

== Device side

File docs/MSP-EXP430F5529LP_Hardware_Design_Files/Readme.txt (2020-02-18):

MSP-EXP430F5529LP Hardware Design Files v1.05.00
Texas Instruments, Inc.

********************************************************************************
Welcome to the MSP-EXP430F5529LP LaunchPad!
********************************************************************************

In this package, you will find hardware design files that can help you quickly
get started on developing your own project.

Available in the 'Hardware' folder are the complete board schematic and layout,
bill of material and Gerber files.

You can also find various web links in the 'Documentation' folder pointing to
the Tool Page, Quick Start Guide, User's Guide and MSP430 USB Developers Package.

For more resources, be sure to visit http://www.ti.com/tool/MSP-EXP430F5529LP
Also checkout the Wiki page at http://processors.wiki.ti.com/index.php/MSP430F5529_LaunchPad

********************************************************************************
Revision History
********************************************************************************
Ver 1.05.00 - June 22nd, 2015
- Added MacOSX + Linux support for MSP430Flasher

Ver 1.04.00 - March 24th, 2015
- Updated driverlib and USB stack in software examples

Ver 1.03.00 - September 26th, 2014
- Updated Hardware files to Revision 1.6

Ver 1.02.00 - June 23rd, 2014
- Updated release packages to distribute hardware and software files separately

Ver 1.01.00 - Jan 2nd, 2014
- Updated Hardware files to Revision 1.5

Ver 1.00.01 - October 09th, 2013
- Added Code Size limited project for emulStorageKeyboard
- Added new folder to include emulation tool driver and simpleUsbBackChannel driver

Ver 1.00.00 - August 27th, 2013
- Initial Release

********************************************************************************
Project File Listing
********************************************************************************
|--Documentation              : Folder containing links to more resources
|--Hardware                   : Folder containing board design files, bill of
                                material and gerber files
|--Readme.txt                 : This file

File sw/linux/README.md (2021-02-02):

# mikroBUS Linux kernel driver

## Build

To build, make sure you've already built your previous kernel properly, then...

```
cd <your linux source tree>
git am <beagleconnect source tree>/sw/linux/*.patch
scripts/kconfig/merge_config.sh <beagleconnect source tree>/sw/linux/mikrobus.config
make
sudo make modules_install
sudo make install
```

Then reboot and profit!

Notes:
* You'll need at least a 5.8 kernel

## Instantiation

mikroBUS ports on a system can be of two different types:
* physical mikroBUS ports on host : For host systems like a [PocketBeagle](https://github.com/beagleboard/pocketbeagle/wiki/System-Reference-Manual#72-mikrobus-socket-connections) or a BeagleBone Black attached to [mikroBUS cape](mikroe.com/beaglebone-mikrobus-cape), the mikroBUS ports are physically present on the board and they can be instantiated over a suitable device tree overlay[1] to describe the mikroBUS port, with physical mikroBUS ports the add-on board discovery is performed directly by reading the manifest from the ID Board[2] physically over 1-wire.
* mikroBUS ports instantiated over Greybus : mikroBUS ports are instantiated over Greybus and in this case the add-on board discovery is performed along with the Greybus interface discovery mechanism over the Greybus manifest, in this case the remote MCU device will either store the add-on board manifests during compile time or fetch it during runtime from ID Board(TODO) and pass it to the host along with the Greybus interface manifest.

1. [PocketBeagle mikroBUS port 0 device tree overlay](https://github.com/beagleboard/bb.org-overlays/blob/master/src/arm/PB-MIKROBUS-0.dts)
2. [mikroBUS ID adapter hardware draft documentation](https://download.mikroe.com/documents/mikrobu_socket/ClickIdentificationFunctionlity.pdf)

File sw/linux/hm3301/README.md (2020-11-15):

# hm3301 driver

```
make -C /lib/modules/`uname -r`/build M=$PWD
sudo make -C /lib/modules/`uname -r`/build M=$PWD modules_install
```

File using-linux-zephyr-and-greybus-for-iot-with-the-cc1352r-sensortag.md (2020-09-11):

# Using Linux, Zephyr & Greybus for IoT with the CC1352R1 LaunchPad (or CC1352R SensorTag)

- [Introduction](#introduction)
  * [Why??](#why--)
  * [History](#history)
- [Hardware Requirements](#hardware-requirements)
- [Prerequisites](#prerequisites)
- [Cloning the repository](#cloning-the-repository)
- [Console (tio)](#console---tio--)
  * [Set Up tio](#set-up--tio-)
  * [Run tio](#run--tio-)
- [Zephyr](#zephyr)
  * [Add the Fork](#add-the-fork)
  * [Build and Flash Zephyr](#build-and-flash-zephyr)
  * [The Zephyr Shell](#the-zephyr-shell)
    + [Zephyr Shell: IEEE 802.15.4 commands](#zephyr-shell--ieee-802154-commands)
    + [Zephyr Shell: Network Commands](#zephyr-shell--network-commands)
- [Linux](#linux)
  * [Probe the IEEE 802.15.4 Device Driver](#probe-the-ieee-802154-device-driver)
  * [Set the 802.15.4 Physical and Link-Layer Parameters](#set-the-802154-physical-and-link-layer-parameters)
  * [Create a 6LowPAN Network Interface](#create-a-6lowpan-network-interface)
- [Ping Pong](#ping-pong)
  * [Broadcast Ping](#broadcast-ping)
  * [Ping Zephyr](#ping-zephyr)
  * [Ping Linux](#ping-linux)
  * [Assign a Static Address](#assign-a-static-address)
- [Greybus](#greybus)
    + [Build and probe Greybus Kernel Modules](#build-and-probe-greybus-kernel-modules)
    + [Build and Run Gbridge](#build-and-run-gbridge)
- [Blinky!](#blinky-)
- [Read I2C Registers](#read-i2c-registers)
- [Conclusion](#conclusion)

# Introduction
This document describes, in some detail, the steps required to use [Linux](https://en.wikipedia.org/wiki/Linux) workstation and the [Greybus](https://lwn.net/Articles/715955/) protocol, over an IEEE 802.15.4 wireless link, to blink an LED on a [Zephyr](https://zephyrproject.org) device.

## Why??
Good question. Blinking an LED is kind of the [Hello, World](https://en.wikipedia.org/wiki/%22Hello,_World!%22_program) of the hardware community. In this case, we're less interested in the mechanics of switching a GPIO to drive some current through an LED and more interested in how that happens with the [Internet of Things (IoT)](https://en.wikipedia.org/wiki/Internet_of_things).

There are several existing network and application layers that are driven by corporate heavyweights and industry consortiums, but relatively few that are community driven and, more specifically, even fewer that have the ability to integrate so tightly with the Linux kernel.

The goal here is to provide a community-maintained, developer-friendly, and open-source protocol for the Internet of Things using the Greybus Protocol, and blinking an LED using Greybus is the simplest proof-of-concept for that. All that is required is a reliable transport.

## History

There are a few technologies at the core of this demonstration, and far too much background information to describe adequately here, so they are simply listed below for brevity
* [Project Ara](https://en.wikipedia.org/wiki/Project_Ara)
* [IPv6](https://en.wikipedia.org/wiki/IPv6) (via [6LoWPAN](https://en.wikipedia.org/wiki/6LoWPAN))
* [Zephyr](https://zephyrproject.org) support for [IEEE 802.15.4](https://docs.zephyrproject.org/latest/reference/networking/ieee802154.html)
* [Greybus](https://youtu.be/UzRq8jAHAxU) originally from [Project Ara](https://youtu.be/UzRq8jAHAxU)
* [Using Greybus for IoT](https://youtu.be/7H50pv-4YXw)

In short, Greybus is an application layer protocol that can be described as a "bus transport" in that it conveys bus-specific messages back and forth between Linux and a connected device. The physical bus is attached to the connected device, which could be running Linux or a variety of Real-Time Operating Systems. Meanwhile, on the Linux side, a virtual bus is created corresponding to the physical bus on the connected device. To the user, this virtual bus (be it /dev/gpiochip0, /dev/i2c5, etc) appears and functions exactly the same. Greybus is the protocol used to exchange bus-specific messages and data between Linux and the connected device.

The major advantage there is that drivers can be well maintained in Linux rather than buried in microcontroller firmware.

Greybus currently supports several busses, including:
* USB
* I2C
* GPIO
* PWM
* SPI
* UART
* SDIO
* Camera (V4L)
* LED (with various programmability)
* AUDIO (I2S)

# Hardware Requirements
* a Linux workstation running [Ubuntu Bionic](https://releases.ubuntu.com/18.04.4)
  * Only x86_64 is supported at this time
* a USB-Serial adapter
* a J-Link JTAG tool (optional) or a LaunchPad (may require some wires)
* a board that is supported by Zephyr with support for IEEE 802.15.4
  * In this example, we use the [cc1352r1_launchpadxl](https://www.ti.com/tool/LAUNCHXL-CC1352R1)
  * Alternatively, you could use the [cc1352r_sensortag](https://www.ti.com/tool/LPSTK-CC1352R) 
    * Connect DIO12 (RXD) and DIO13 (TXD) as well as GND to the appropriate pins on your serial adapter 
* a USB IEEE 802.15.4 adapter
  * In this example, we use the [atusb](http://downloads.qi-hardware.com/people/werner/wpan/web)
  * Available for purchase from [sysmocom](http://shop.sysmocom.de/products/atusb)
  * This part is [OSHW](https://www.oshwa.org/) (i.e. all CAD files and firmware source is available) for those who choose to create their own.

# Prerequisites
* Zephyr environment is set up according to the [Getting Started Guide](https://docs.zephyrproject.org/latest/getting_started/index.html)
  * Please use the Zephyr SDK when installing a toolchain above
* [Zephyr SDK](https://docs.zephyrproject.org/latest/getting_started/index.html#install-a-toolchain) is installed at ~/zephyr-sdk-0.11.2 (any later version should be fine as well)
* Zephyr board is connected via USB

# Cloning the repository
This repository utilizes (git submodules)[https://git-scm.com/book/en/v2/Git-Tools-Submodules] to
keep track of all of the projects required to reproduce the on-going work. The instructions here
only cover checking out the "demo" branch which should stay in a tested state. On-going development
will be on the "master" branch.

## Clone specific tag
```console
cd <parent directory you choose>
git clone --recurse-submodules --branch demo https://github.com/jadonk/beagleconnect
```

# Console (`tio`)
In order to see diagnostic messages or to run certain commands on the Zephyr device we will require a terminal open to the device console. In this case, we use [tio](https://tio.github.io/).

## Install `tio`
```console
sudo apt install -y tio
```

## Run `tio`
Now, we'll open a terminal to Zephyr using the newly created setup with the command below.
```console
tio /dev/ttyACM0
```

To exit `tio` (later), enter `ctrl+t, q`.

# Zephyr
## Add the Fork

For the time being, Greybus must remain outside of the main Zephyr repository. Currently, it is just in a Zephyr fork, but it should be converted to a proper [Module (External Project)](https://docs.zephyrproject.org/latest/guides/modules.html). This is for a number of reasons, but mainly there must be:
* specifications for authentication and encryption
* specifications for joining and rejoining wireless networks
* specifications for discovery

Therefore, in order to reproduce this example, please run the following in your zephyr directory.
```console
git remote add greybus https://github.com/cfriedt/zephyr.git
git fetch greybus
git checkout -b greybus-service-lpc2020 greybus/greybus-service-lpc2020
west update
```

## Build and Flash Zephyr
Here, we will build and flash the Zephyr [greybus_net sample](https://github.com/cfriedt/zephyr/tree/greybus-sockets/samples/subsys/greybus/net) to our device.

1. Open a separate terminal window (`Ctrl+Shift+N`) or simply create a new tab in your existing terminal (`Ctrl+Shift+T`) so that you can see both or quickly switch between `minicom` and the shell.
1. Now in the shell, change to the `zephyrproject/zephyr` directory
1. Edit the file `~/.zephyrrc` and place the following text inside of it
    ```
    export ZEPHYR_TOOLCHAIN_VARIANT=zephyr
    export ZEPHYR_SDK_INSTALL_DIR=~/zephyr-sdk-0.11.2
    ```
1. Set up the required Zephyr environment variables via `source zephyr-env.sh`
1. Build the project
    ```
    BOARD=cc1352r1_launchxl west build samples/subsys/greybus/net --pristine --build-dir build/greybus_launchpad -- \
      -DCONF_FILE="prj.conf overlay-802154.conf"
    ```
1. Ensure that the last part of the build process looks somewhat like this:
    ```console
    ...
    Memory region         Used Size  Region Size  %age Used
               FLASH:      261996 B         1 MB     24.99%
                SRAM:       50879 B       256 KB     19.41%
            IDT_LIST:         152 B         2 KB      7.42%
    [245/245] Linking C executable zephyr/zephyr.elf
    ```
1. Flash the firmware to your device using `BOARD=cc1352r1_launchxl west flash --build-dir build/greybus_launchpad`

## The Zephyr Shell

After flashing, you should observe the something matching the following output in `minicom`.
```
*** Booting Zephyr OS build zephyr-v2.3.0-1435-g40c0ed940d71  ***
[00:00:00.011,932] <inf> net_config: Initializing network
[00:00:00.111,938] <inf> net_config: IPv6 address: fe80::6c42:bc1c:4b:1200
[00:00:00.112,121] <dbg> greybus_service.greybus_service_init: Greybus initializing..
[00:00:00.112,426] <dbg> greybus_transport_tcpip.gb_transport_backend_init: Greybus TCP/IP Transport initializing..
[00:00:00.112,579] <dbg> greybus_transport_tcpip.netsetup: created server socket 0 for cport 0
[00:00:00.112,579] <dbg> greybus_transport_tcpip.netsetup: setting socket options for socket 0
[00:00:00.112,609] <dbg> greybus_transport_tcpip.netsetup: binding socket 0 (cport 0) to port 4242
[00:00:00.112,640] <dbg> greybus_transport_tcpip.netsetup: listening on socket 0 (cport 0)
[00:00:00.112,823] <dbg> greybus_transport_tcpip.netsetup: created server socket 1 for cport 1
[00:00:00.112,823] <dbg> greybus_transport_tcpip.netsetup: setting socket options for socket 1
[00:00:00.112,854] <dbg> greybus_transport_tcpip.netsetup: binding socket 1 (cport 1) to port 4243
[00:00:00.112,854] <dbg> greybus_transport_tcpip.netsetup: listening on socket 1 (cport 1)
[00:00:00.113,037] <inf> net_config: IPv6 address: fe80::6c42:bc1c:4b:1200
[00:00:00.113,250] <dbg> greybus_transport_tcpip.netsetup: created server socket 2 for cport 2
[00:00:00.113,250] <dbg> greybus_transport_tcpip.netsetup: setting socket options for socket 2
[00:00:00.113,281] <dbg> greybus_transport_tcpip.netsetup: binding socket 2 (cport 2) to port 4244
[00:00:00.113,311] <dbg> greybus_transport_tcpip.netsetup: listening on socket 2 (cport 2)
[00:00:00.113,494] <dbg> greybus_transport_tcpip.netsetup: created server socket 3 for cport 3
[00:00:00.113,494] <dbg> greybus_transport_tcpip.netsetup: setting socket options for socket 3
[00:00:00.113,525] <dbg> greybus_transport_tcpip.netsetup: binding socket 3 (cport 3) to port 4245
[00:00:00.113,555] <dbg> greybus_transport_tcpip.netsetup: listening on socket 3 (cport 3)
[00:00:00.113,861] <inf> greybus_transport_tcpip: Greybus TCP/IP Transport initialized
[00:00:00.116,149] <inf> greybus_service: Greybus is active
[00:00:00.116,546] <dbg> greybus_transport_tcpip.accept_loop: calling poll
uart:~$ 
```

The line beginning with `***` is the Zephyr boot banner.

Lines beginning with a timestamp of the form `[H:m:s.us]` are Zephyr kernel messages.

Lines beginning with `uart:~$ ` indicates that the Zephyr shell is prompting you to enter a command.

From the informational messages shown, we observe the following.
* Zephyr is configured with the following [link-local IPv6 address](https://en.wikipedia.org/wiki/Link-local_address#IPv6) `fe80::cf99:a11c:4b:1200`
* It is listening for (both) TCP and UDP traffic on port 4242

However, what the log messages do *not* show (which will come into play later), are 2 critical pieces of information:
1. The RF Channel: 
    As you may have guessed, IEEE 802.15.4 devices are only able to communicate with each other if they are using
    the same frequency to transmit and recieve data. This information is part of the Physical Layer.
1. The [PAN identifier](https://www.silabs.com/community/wireless/proprietary/knowledge-base.entry.html/2019/10/04/connect_tutorial6-ieee802154addressing-rapc): 
    IEEE 802.15.4 devices are only be able to communicate with one another if they use the *same* PAN ID. This permits multiple networks (PANs) on the same frequency. This information is part of the Data Link Layer.

If we type `help` in the shell and hit *Enter*, we're prompted with the following:
```console
Please press the <Tab> button to see all available commands.
You can also use the <Tab> button to prompt or auto-complete all commands or its subcommands.
You can try to call commands with <-h> or <--help> parameter for more information.
Shell supports following meta-keys:
Ctrl+a, Ctrl+b, Ctrl+c, Ctrl+d, Ctrl+e, Ctrl+f, Ctrl+k, Ctrl+l, Ctrl+n, Ctrl+p, Ctrl+u, Ctrl+w
Alt+b, Alt+f.
Please refer to shell documentation for more details.
```
So after hitting *Tab*, we see that there are several interesting commands we can use for additional information.
```console
uart:~$ 
  clear       help        history     ieee802154  log         net
  resize      sample      shell
```

### Zephyr Shell: IEEE 802.15.4 commands
Entering `ieee802154 help`, we see
```console
uart:~$ ieee802154 help
ieee802154 - IEEE 802.15.4 commands
Subcommands:
  ack             :<set/1 | unset/0> Set auto-ack flag
  associate       :<pan_id> <PAN coordinator short or long address (EUI-64)>
  disassociate    :Disassociate from network
  get_chan        :Get currently used channel
  get_ext_addr    :Get currently used extended address
  get_pan_id      :Get currently used PAN id
  get_short_addr  :Get currently used short address
  get_tx_power    :Get currently used TX power
  scan            :<passive|active> <channels set n[:m:...]:x|all> <per-channel
                   duration in ms>
  set_chan        :<channel> Set used channel
  set_ext_addr    :<long/extended address (EUI-64)> Set extended address
  set_pan_id      :<pan_id> Set used PAN id
  set_short_addr  :<short address> Set short address
  set_tx_power    :<-18/-7/-4/-2/0/1/2/3/5> Set TX power
```
We get the missing Channel number (frequency) with the command `ieee802154 get_chan`.
```console
uart:~$ ieee802154 get_chan
Channel 26
```
We get the missing PAN ID with the command `ieee802154 get_pan_id`.
```console
uart:~$ ieee802154 get_pan_id
PAN ID 43981 (0xabcd)
```

### Zephyr Shell: Network Commands
Additionally, we may query the IPv6 information of the Zephyr device.
```console
uart:~$ net iface

Interface 0x20002b20 (IEEE 802.15.4) [1]
========================================
Link addr : CD:99:A1:1C:00:4B:12:00
MTU       : 125
IPv6 unicast addresses (max 3):
        fe80::cf99:a11c:4b:1200 autoconf preferred infinite
        2001:db8::1 manual preferred infinite
IPv6 multicast addresses (max 4):
        ff02::1
        ff02::1:ff4b:1200
        ff02::1:ff00:1
IPv6 prefixes (max 2):
        <none>
IPv6 hop limit           : 64
IPv6 base reachable time : 30000
IPv6 reachable time      : 16929
IPv6 retransmit timer    : 0
```
And we see that the static IPv6 address (`2001:db8::1`) from `samples/net/sockets/echo_server/prj.conf` is present and configured. While the statically configured IPv6 address is useful, it isn't 100% necessary.

# Linux
## Probe the IEEE 802.15.4 Device Driver
On the Linux machine, we've inserted our atusb device, and should now be able to run `sudo modprobe atusb`. The kernel should provide some information messages (via `dmesg`) to indicate that the device is recognized.

```console
[704054.909350] usb 1-1.3: ATUSB: AT86RF231 version 2
[704054.909602] usb 1-1.3: Firmware: major: 0, minor: 2, hardware type: ATUSB (2)
[704054.910097] usb 1-1.3: Firmware: build #24 Wed 20 May 15:19:58 CEST 2015
[704054.927872] usbcore: registered new interface driver atusb
```

We should now be able to see the IEEE 802.15.4 network device by entering `ip a show wpan0`.
```console
$ ip a show wpan0
36: wpan0: <BROADCAST,NOARP,UP,LOWER_UP> mtu 123 qdisc fq_codel state UNKNOWN group default qlen 300
    link/ieee802.15.4 3e:7d:90:4d:8f:00:76:a2 brd ff:ff:ff:ff:ff:ff:ff:ff
```
But wait, that is not an IP address! It's the hardware address of the 802.15.4 device. So, in order to associate it with an IP address, we need to run a couple of other commands (thanks to [cakelab.org](http://wpan.cakelab.org/)).

## Set the 802.15.4 Physical and Link-Layer Parameters
1. First, get the phy number for the `wpan0` device
    ```console
    $ iwpan list 
    wpan_phy phy0
    supported channels:
    	page 0: 11,12,13,14,15,16,17,18,19,20,21,22,23,24,25,26 
    current_page: 0
    current_channel: 26,  2480 MHz
    cca_mode: (1) Energy above threshold
    cca_ed_level: -77
    tx_power: 3
    capabilities:
    	iftypes: node,monitor 
    	channels:
    		page 0: 
    			[11]  2405 MHz, [12]  2410 MHz, [13]  2415 MHz, 
    			[14]  2420 MHz, [15]  2425 MHz, [16]  2430 MHz, 
    			[17]  2435 MHz, [18]  2440 MHz, [19]  2445 MHz, 
    			[20]  2450 MHz, [21]  2455 MHz, [22]  2460 MHz, 
    			[23]  2465 MHz, [24]  2470 MHz, [25]  2475 MHz, 
    			[26]  2480 MHz  
    	tx_powers: 
    			3 dBm, 2.8 dBm, 2.3 dBm, 1.8 dBm, 1.3 dBm, 0.7 dBm, 
    			0 dBm, -1 dBm, -2 dBm, -3 dBm, -4 dBm, -5 dBm, 
    			-7 dBm, -9 dBm, -12 dBm, -17 dBm, 
    	cca_ed_levels: 
    			-91 dBm, -89 dBm, -87 dBm, -85 dBm, -83 dBm, -81 dBm, 
    			-79 dBm, -77 dBm, -75 dBm, -73 dBm, -71 dBm, -69 dBm, 
    			-67 dBm, -65 dBm, -63 dBm, -61 dBm, 
    	cca_modes: 
    		(1) Energy above threshold
    		(2) Carrier sense only
    		(3, cca_opt: 0) Carrier sense with energy above threshold (logical operator is 'and')
    		(3, cca_opt: 1) Carrier sense with energy above threshold (logical operator is 'or')
    	min_be: 0,1,2,3,4,5,6,7,8 
    	max_be: 3,4,5,6,7,8 
    	csma_backoffs: 0,1,2,3,4,5 
    	frame_retries: 3 
    	lbt: false
    ```
1. Next, set the Channel for the 802.15.4 device on the Linux machine
    ```console
    sudo iwpan phy phy0 set channel 0 26
    ```
1. Then, set the PAN identifier for the 802.15.4 device on the Linux machine
    ```console
    sudo iwpan dev wpan0 set pan_id 0xabcd
    ```
## Create a 6LowPAN Network Interface
1. Associate the `wpan0` device to a new, 6lowpan network interface
    ```console
    sudo ip link add link wpan0 name lowpan0 type lowpan
    ```
1. Finally, set the links up for both `wpan0` and `lowpan0`
    ```console
    sudo ip link set wpan0 up
    sudo ip link set lowpan0 up
    ```

We
should observe something like the
following when we run `ip a show lowpan0`. 
```console
ip a show lowpan0
37: lowpan0@wpan0: <BROADCAST,MULTICAST,UP,LOWER_UP> mtu 1280 qdisc noqueue state UNKNOWN group default qlen 1000
    link/6lowpan 9e:0b:a4:e8:00:d3:45:53 brd ff:ff:ff:ff:ff:ff:ff:ff
    inet6 fe80::9c0b:a4e8:d3:4553/64 scope link 
       valid_lft forever preferred_lft forever
```

# Ping Pong
## Broadcast Ping

Now, perform a broadcast ping to see what else is listening on `lowpan0`.
```console
$ ping6 -I lowpan0 ff02::1
PING ff02::1(ff02::1) from fe80::9c0b:a4e8:d3:4553%lowpan0 lowpan0: 56 data bytes
64 bytes from fe80::9c0b:a4e8:d3:4553%lowpan0: icmp_seq=1 ttl=64 time=0.099 ms
64 bytes from fe80::9c0b:a4e8:d3:4553%lowpan0: icmp_seq=2 ttl=64 time=0.125 ms
64 bytes from fe80::cf99:a11c:4b:1200%lowpan0: icmp_seq=2 ttl=64 time=17.3 ms (DUP!)
64 bytes from fe80::9c0b:a4e8:d3:4553%lowpan0: icmp_seq=3 ttl=64 time=0.126 ms
64 bytes from fe80::cf99:a11c:4b:1200%lowpan0: icmp_seq=3 ttl=64 time=9.60 ms (DUP!)
64 bytes from fe80::9c0b:a4e8:d3:4553%lowpan0: icmp_seq=4 ttl=64 time=0.131 ms
64 bytes from fe80::cf99:a11c:4b:1200%lowpan0: icmp_seq=4 ttl=64 time=14.9 ms (DUP!)
```

Yay! We have pinged (pung?) the Zephyr device over IEEE 802.15.4 using 6LowPAN!

## Ping Zephyr
We can ping the Zephyr device directly without a broadcast ping too, of course.
```console
$ ping6 -I lowpan0 fe80::cf99:a11c:4b:1200
PING fe80::cf99:a11c:4b:1200(fe80::cf99:a11c:4b:1200) from fe80::9c0b:a4e8:d3:4553%lowpan0 lowpan0: 56 data bytes
64 bytes from fe80::cf99:a11c:4b:1200%lowpan0: icmp_seq=1 ttl=64 time=16.0 ms
64 bytes from fe80::cf99:a11c:4b:1200%lowpan0: icmp_seq=2 ttl=64 time=13.8 ms
64 bytes from fe80::cf99:a11c:4b:1200%lowpan0: icmp_seq=3 ttl=64 time=9.77 ms
64 bytes from fe80::cf99:a11c:4b:1200%lowpan0: icmp_seq=5 ttl=64 time=11.5 ms
```
## Ping Linux
Similarly, we can ping the Linux host from the Zephyr shell.
```console
uart:~$ net ping --help
ping - Ping a network host.
Subcommands:
  --help  :'net ping [-c count] [-i interval ms] <host>' Send ICMPv4 or ICMPv6
           Echo-Request to a network host.
$ net ping -c 5 fe80::9c0b:a4e8:d3:4553
PING fe80::9c0b:a4e8:d3:4553
8 bytes from fe80::9c0b:a4e8:d3:4553 to fe80::cf99:a11c:4b:1200: icmp_seq=0 ttl=64 rssi=110 time=11 ms
8 bytes from fe80::9c0b:a4e8:d3:4553 to fe80::cf99:a11c:4b:1200: icmp_seq=1 ttl=64 rssi=126 time=9 ms
8 bytes from fe80::9c0b:a4e8:d3:4553 to fe80::cf99:a11c:4b:1200: icmp_seq=2 ttl=64 rssi=128 time=13 ms
8 bytes from fe80::9c0b:a4e8:d3:4553 to fe80::cf99:a11c:4b:1200: icmp_seq=3 ttl=64 rssi=126 time=10 ms
8 bytes from fe80::9c0b:a4e8:d3:4553 to fe80::cf99:a11c:4b:1200: icmp_seq=4 ttl=64 rssi=126 time=7 ms
```

## Assign a Static Address

So far, we have been using IPv6 Link-Local addressing. However, the Zephyr application is configured to use a statically configured IPv6 address as well which is, namely `2001:db8::1`.

If we add a similar static IPv6 address to our Linux IEEE 802.15.4 network interface, `lowpan0`, then we should expect to be able to reach that as well.

In Linux, run the following
```console
sudo ip -6 addr add 2001:db8::2/64 dev lowpan0
```
We can verify that the address has been set by examining the `lowpan0` network interface again.
```console
$ ip a show lowpan0
37: lowpan0@wpan0: <BROADCAST,MULTICAST,UP,LOWER_UP> mtu 1280 qdisc noqueue state UNKNOWN group default qlen 1000
    link/6lowpan 9e:0b:a4:e8:00:d3:45:53 brd ff:ff:ff:ff:ff:ff:ff:ff
    inet6 2001:db8::2/64 scope global 
       valid_lft forever preferred_lft forever
    inet6 fe80::9c0b:a4e8:d3:4553/64 scope link 
       valid_lft forever preferred_lft forever
```

Lastly, ping the statically configured IPv6 address of the Zephyr device.
```console
$ ping6 2001:db8::1
PING 2001:db8::1(2001:db8::1) 56 data bytes
64 bytes from 2001:db8::1: icmp_seq=2 ttl=64 time=53.7 ms
64 bytes from 2001:db8::1: icmp_seq=3 ttl=64 time=13.1 ms
64 bytes from 2001:db8::1: icmp_seq=4 ttl=64 time=22.0 ms
64 bytes from 2001:db8::1: icmp_seq=5 ttl=64 time=22.7 ms
64 bytes from 2001:db8::1: icmp_seq=6 ttl=64 time=18.4 ms
```

Now that we have set up a reliable transport, let's move on to the application layer.

# Greybus

Hopefully the videos listed earlier provide a sufficient foundation to understand what will happen shortly. However, there is still a bit more preparation required.

### Build and probe Greybus Kernel Modules

Greybus was originally intended to work exclusively on the UniPro physical layer. However, we're using RF as our physical layer and TCP/IP as our transport. As such, there was need to be able to communicate with the Linux Greybus facilities through userspace, and out of that need arose gb-netlink. The Netlink Greybus module actually does not care about the physical layer, but is happy to usher Greybus messages back and forth between the kernel and userspace.

Build and probe the gb-netlink modules (as well as the other Greybus modules) with the following:
```console
cd ${WORKSPACE}
git clone https://github.com/friedtco/greybus.git
cd greybus
make -j`nproc --all`
./gbprobe.sh
```

### Build and Run Gbridge

The gbridge utility was created as a proof of concept to abstract the Greybus Netlink datapath among several reliable transports. For the purposes of this tutorial, we'll be using it as a TCP/IP bridge.

To run `gbridge`, perform the following:
```console
cd gbridge
autoreconf -vfi
GBNETLINKDIR=${PWD}/../greybus \
  ./configure --enable-uart --enable-tcpip --disable-gbsim --enable-netlink --disable-bluetooth
make -j`nproc --all`
sudo make install
gbridge
```

# Blinky!

Now that we have set up a reliable TCP transport, and set up the Greybus modules in the Linux kernel, and used Gbridge to connect a Greybus node to the Linux kernel via TCP/IP, we can now get to the heart of the demonstration!

First, save the following script as `blinky.sh`.
```bash
#!/bin/bash

# Blinky Demo for CC1352R SensorTag

# /dev/gpiochipN that Greybus created
CHIP="$(gpiodetect | grep greybus_gpio | head -n 1 | awk '{print $1}')"

# red, green, blue LED pins
RED=6
GREEN=7
BLUE=21

# Bash array for pins and values
PINS=($RED $GREEN $BLUE)
NPINS=${#PINS[@]}

for ((;;)); do
	for i in ${!PINS[@]}; do
		# turn off previous pin
		if [ $i -eq 0 ]; then
			PREV=2
		else
			PREV=$((i-1))
		fi
		gpioset $CHIP ${PINS[$PREV]}=0

		# turn on current pin
		gpioset $CHIP ${PINS[$i]}=1

		# wait a sec
		sleep 1
	done
done
```

Second, run the script with root privileges: `sudo bash blinky.sh`

The output of your minicom session should resemble the following.

```console
$ *** Booting Zephyr OS build zephyr-v2.3.0-1435-g40c0ed940d71  ***
[00:00:00.011,932] <inf> net_config: Initializing network
[00:00:00.111,938] <inf> net_config: IPv6 address: fe80::6c42:bc1c:4b:1200
[00:00:00.112,121] <dbg> greybus_service.greybus_service_init: Greybus initializing..
[00:00:00.112,426] <dbg> greybus_transport_tcpip.gb_transport_backend_init: Greybus TCP/IP Transport initializing..
[00:00:00.112,579] <dbg> greybus_transport_tcpip.netsetup: created server socket 0 for cport 0
[00:00:00.112,579] <dbg> greybus_transport_tcpip.netsetup: setting socket options for socket 0
[00:00:00.112,609] <dbg> greybus_transport_tcpip.netsetup: binding socket 0 (cport 0) to port 4242
[00:00:00.112,640] <dbg> greybus_transport_tcpip.netsetup: listening on socket 0 (cport 0)
[00:00:00.112,823] <dbg> greybus_transport_tcpip.netsetup: created server socket 1 for cport 1
[00:00:00.112,823] <dbg> greybus_transport_tcpip.netsetup: setting socket options for socket 1
[00:00:00.112,854] <dbg> greybus_transport_tcpip.netsetup: binding socket 1 (cport 1) to port 4243
[00:00:00.112,854] <dbg> greybus_transport_tcpip.netsetup: listening on socket 1 (cport 1)
[00:00:00.113,037] <inf> net_config: IPv6 address: fe80::6c42:bc1c:4b:1200
[00:00:00.113,250] <dbg> greybus_transport_tcpip.netsetup: created server socket 2 for cport 2
[00:00:00.113,250] <dbg> greybus_transport_tcpip.netsetup: setting socket options for socket 2
[00:00:00.113,281] <dbg> greybus_transport_tcpip.netsetup: binding socket 2 (cport 2) to port 4244
[00:00:00.113,311] <dbg> greybus_transport_tcpip.netsetup: listening on socket 2 (cport 2)
[00:00:00.113,494] <dbg> greybus_transport_tcpip.netsetup: created server socket 3 for cport 3
[00:00:00.113,494] <dbg> greybus_transport_tcpip.netsetup: setting socket options for socket 3
[00:00:00.113,525] <dbg> greybus_transport_tcpip.netsetup: binding socket 3 (cport 3) to port 4245
[00:00:00.113,555] <dbg> greybus_transport_tcpip.netsetup: listening on socket 3 (cport 3)
[00:00:00.113,861] <inf> greybus_transport_tcpip: Greybus TCP/IP Transport initialized
[00:00:00.116,149] <inf> greybus_service: Greybus is active
[00:00:00.116,546] <dbg> greybus_transport_tcpip.accept_loop: calling poll
[00:45:08.397,399] <dbg> greybus_transport_tcpip.accept_loop: poll returned 1
[00:45:08.397,399] <dbg> greybus_transport_tcpip.accept_loop: socket 0 (cport 0) has traffic
[00:45:08.397,491] <dbg> greybus_transport_tcpip.accept_loop: accepted connection from [2001:db8::2]:39638 as fd 4
[00:45:08.397,491] <dbg> greybus_transport_tcpip.accept_loop: spawning client thread..
[00:45:08.397,735] <dbg> greybus_transport_tcpip.accept_loop: calling poll
[00:45:08.491,363] <dbg> greybus_transport_tcpip.accept_loop: poll returned 1
[00:45:08.491,363] <dbg> greybus_transport_tcpip.accept_loop: socket 3 (cport 3) has traffic
[00:45:08.491,455] <dbg> greybus_transport_tcpip.accept_loop: accepted connection from [2001:db8::2]:39890 as fd 5
[00:45:08.491,455] <dbg> greybus_transport_tcpip.accept_loop: spawning client thread..
[00:45:08.491,699] <dbg> greybus_transport_tcpip.accept_loop: calling poll
[00:45:08.620,056] <dbg> greybus_transport_tcpip.accept_loop: poll returned 1
[00:45:08.620,086] <dbg> greybus_transport_tcpip.accept_loop: socket 2 (cport 2) has traffic
[00:45:08.620,147] <dbg> greybus_transport_tcpip.accept_loop: accepted connection from [2001:db8::2]:42422 as fd 6
[00:45:08.620,147] <dbg> greybus_transport_tcpip.accept_loop: spawning client thread..
[00:45:08.620,422] <dbg> greybus_transport_tcpip.accept_loop: calling poll
[00:45:08.679,504] <dbg> greybus_transport_tcpip.accept_loop: poll returned 1
[00:45:08.679,534] <dbg> greybus_transport_tcpip.accept_loop: socket 1 (cport 1) has traffic
[00:45:08.679,595] <dbg> greybus_transport_tcpip.accept_loop: accepted connection from [2001:db8::2]:48286 as fd 7
[00:45:08.679,595] <dbg> greybus_transport_tcpip.accept_loop: spawning client thread..
[00:45:08.679,870] <dbg> greybus_transport_tcpip.accept_loop: calling poll
...
```
# Read I2C Registers

The SensorTag comes with an opt3001 ambient light sensor as well as an hdc2080 temperature & humidity sensor.

First, find which i2c device corresponds to the SensorTag:

```bash
ls -la /sys/bus/i2c/devices/* | grep "greybus"
lrwxrwxrwx 1 root root 0 Aug 15 11:24 /sys/bus/i2c/devices/i2c-8 -> ../../../devices/virtual/gb_nl/gn_nl/greybus1/1-2/1-2.2/1-2.2.2/gbphy2/i2c-8
```
On my machine, the i2c device node that Greybus creates is /dev/i2c-8.

Read the ID registers (at the i2c register address 0x7e) of the opt3001 sensor (at i2c bus address 0x44) as shown below:

```bash
i2cget -y 8 0x44 0x7e w
0x4954
```

Read the ID registers (at the i2c register address 0xfc) of the hdc2080 sensor (at i2c bus address 0x41) as shown below:

```bash
i2cget -y 8 0x41 0xfc w 
0x5449
```

# Conclusion
The blinking LED can and poking i2c registers can be a somewhat anticlimactic, but hopefully it illustrates the potential for Greybus as an IoT application layer protocol.

What is nice about this demo, is that we're using Device Tree to describe our Greybus Peripheral declaratively, they Greybus Manifest is automatically generated, and the Greybus Service is automatically started in Zephyr.

In other words, all that is required to replicate this for other IoT devices is simply an appropriate Device Tree overlay file.

The proof-of-concept involving Linux, Zephyr, and IEEE 802.15.4 was actually fairly straight forward and was accomplished with mostly already-upstream source.

For Greybus in Zephyr, there is still a considerable amount of integration work to be done, including
* converting the fork to a proper Zephyr module
* adding security and authentication
* automatic detection, joining, and rejoining of devices

Thanks for reading, and we hope you've enjoyed this tutorial.

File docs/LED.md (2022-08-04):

# LED definition

These definitions are proposed with the mindset of giving end-users high-level functional
status indication of the devices and nodes. It seeks to avoid having the status of any
one LED being required to interpret another, which has the undesirable effect of limiting
the amount of information that can be conveyed, but should simplify interpretation.

Single letter abbreviations are provided in case we can put these on a silkscreen on the
side of the case.

## Positions

#TODO: - I need to determine for sure where each LED is on the board and make it clear in this document.

## Functions

<table>
 <thead>
  <tr>
   <td>LED</td>
   <td>Signal</td>
   <td>Status</td>
   <td>Indication</td>
  </tr>
 </thead>
 <tbody>
  <tr>
   <td rowspan=2>CHG (Charging)</td>
   <td rowspan=2>D7, CHG (no S/W control)</td>
   <td>On</td>
   <td>Charger active</td>
  </tr>
  <tr>
   <td>Off</td>
   <td>Charger not active</td>
  </tr>
  <tr>
   <td rowspan=4>LNK (Link)</td>
   <td rowspan=4>D6, 2.4G (DIO_18 on CC1352)</td>
   <td>On</td>
   <td>Radio RX within timeout</td>
  </tr>
  <tr>
   <td>Fast blink</td>
   <td>Radio active</td>
  </tr>
  <tr>
   <td>Off</td>
   <td>Radio RX inactive (timeout)</td>
  </tr>
  <tr>
   <td>Slow blink</td>
   <td>Radio error</td>
  </tr>
  <tr>
   <td rowspan=4>USB (USB)</td>
   <td rowspan=4>D5, 900M (P6.1 on MSP430)</td>
   <td>On</td>
   <td>Device in <i>gateway</i> mode</td>
  </tr>
  <tr>
   <td>Fast blink</td>
   <td>USB active</td>
  </tr>
  <tr>
   <td>Off</td>
   <td>Device in <i>node</i> mode</td>
  </tr>
  <tr>
   <td>Slow blink</td>
   <td>Seeking USB (<i>gateway</i>) connection</td>
  </tr>
  <tr>
   <td rowspan=2>PWR (Power)</td>
   <td rowspan=2>D4, PWR (no S/W control)</td>
   <td>On</td>
   <td>Device powered</td>
  </tr>
  <tr>
   <td>Off</td>
   <td>Device not powered</td>
  </tr>
  <tr>
   <td rowspan=6>MB1 (mikroBUS 1)</td>
   <td rowspan=6>D3, LED1 (P6.2 on MSP430)</td>
   <td>On</td>
   <td>Identified and connected</td>
  </tr>
  <tr>
   <td>Fast blink (w/o 2)</td>
   <td>Active</td>
  </tr>
  <tr>
   <td>Fast blink (w/ 2)</td>
   <td>Internal sensor active</td>
  </tr>
  <tr>
   <td>Off</td>
   <td>Inactive</td>
  </tr>
  <tr>
   <td>Slow blink (w/o 2)</td>
   <td>Identified, but not connected</td>
  </tr>
  <tr>
   <td>Slow blink (w/ 2)</td>
   <td>Seeking Greybus connection</td>
  </tr>
  <tr>
   <td rowspan=6>MB2 (mikroBUS 2)</td>
   <td rowspan=6>D2, LED2 (P6.3 on MSP430)</td>
   <td>On</td>
   <td>Identified and connected</td>
  </tr>
  <tr>
   <td>Fast blink (w/o 1)</td>
   <td>Active</td>
  </tr>
  <tr>
   <td>Fast blink (w/ 1)</td>
   <td>Internal sensor active</td>
  </tr>
  <tr>
   <td>Off</td>
   <td>Inactive</td>
  </tr>
  <tr>
   <td>Slow blink (w/o 1)</td>
   <td>Identified, but not connected</td>
  </tr>
  <tr>
   <td>Slow blink (w/ 1)</td>
   <td>Seeking Greybus connection</td>
  </tr>
 </tbody>
</table>

## Modes

<table>
 <thead>
  <tr>
   <td>Mode/firmware</td>
   <td>Submode</td>
   <td>USB LED (U)</td>
   <td>MikroBUS LEDs (1/2)</td>
  </tr>
 </thead>
 <tbody>
  <tr>
   <td rowspan=1>Sensortest node</td>
   <td>-</td>
   <td>off</td>
   <td>off</td>
  </tr>
  <tr>
   <td rowspan=4>Greybus node</td>
   <td>searching</td>
   <td rowspan=3>off</td>
   <td>slow blink</td>
  </tr>
  <tr>
   <td>searching</td>
   <td rowspan=3>connected</td>
   <td>off</td>
  </tr>

| Mode/firmware | USB LED | MikroBUS 1/2 LEDs |
| --- | --- | --- |
| Sensortest node | off | off |
| Greybus node | off | slow blink, fast blink, or on (not off) |
| Gateway | slow blink, fast blink, or on (not off) | off |

## Implementation

### Link

#### CC1352
* We've got a hook for TX toggle at the antenna switch. A global variable can remember if
  we should leave it on or off.
* I need to look for where we have RX at the level of valid IEEE802.15.4 packets on the
  SubG radio. I think we can set the flag there, but probably need a mutex.

### USB

#### MSP430
* A global flag to reflect the LED mode
* Set the LED if USB connected and HDLC connection established with _gateway_ firmware
* Toggle the LED status with short pulses based on getting or sending USB traffic
* Toggle the LED slow if USB is connected, but not in HDLC mode (passthrough or searching for HDLC)

### 1/2

TBD

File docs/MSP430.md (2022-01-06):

# MSP430 summary

Primary goal is to be a USB-to-UART bridge for the CC1352, but it has evolved over time.

* The Linux WPANUSB driver talks to USB use a custom protocol, not as a UART. To support communication

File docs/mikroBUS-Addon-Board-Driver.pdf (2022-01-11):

# mikroBUS Driver for Add-on Boards

You, Me and IoT Two MicroConference

Vaishnav M A <vaishnav@beagleboard.org>

### mikroBUSTM add-on board socket standard

- Open Standard from MikroElektronika
- can add mikroBUSTM Sockets to board designs.
- can design new add-on boards.
- 140+ Development Boards Supported.
- 850+ Add-on Boards.
- not excessively flexible and require abritrary device-tree overlays like Cape/Hats/Shields.
- 150+ add-on boards already have corresponding device drivers within the linux kernel.

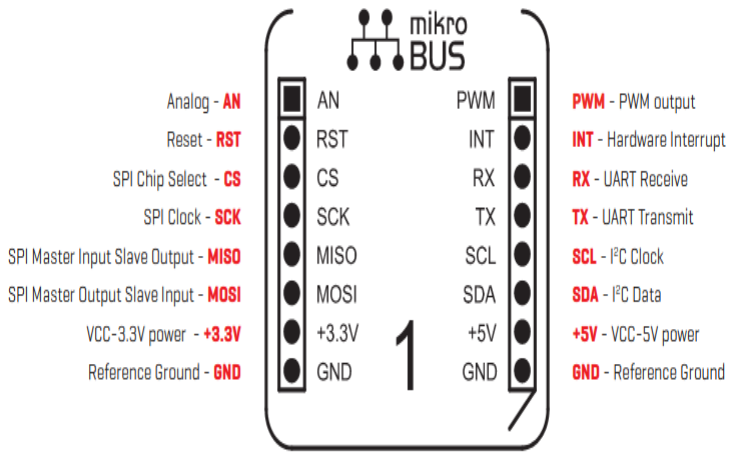
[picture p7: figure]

https://www.mikroe.com/mikrobus

### Usage of mikroBUS comaptible add-on boards today

- 150+ add-on board has existing device drivers on the kernel.
- Device-Tree Overlays loaded at boot time.
- requires maintenance of overlay fragments specific to each add-on board for each socket.*
- Considering a BeagleBoard.org PocketBeagle target alone(2 mikroBUS socket) with the 150 add-on boards which has existing device drivers, 300 different device tree overlay fragment needs to be maintained.
- Time consuming and potentially error-prone.

* Device Tree maintainer Frank Rowand has an active proposal to solve the problem of maintaining overlay fragments for each socket, but this might not apply for mikroBUS sockets added dynamically.(discussed later)

### mikroBUS driver in the Linux Kernel

- mikroBUS as a probeable bus, kernel can discover the device(s) on the mikroBUS at boot time.
- Add-on board specific identifier information stored on a non-volatile storage on the add-on board.
- Currently the identifier is stored on an EEPROM on the I2C bus on the mikroBUS socket.
- Identifier format used is an extension to Greybus Manifest <linux/greybus/greybus_manifest.h>.
- Support tested for 110 mikroBUS add-on boards.
- MikroBUS v3 standard under development.

### mikroBUS driver in the Linux Kernel

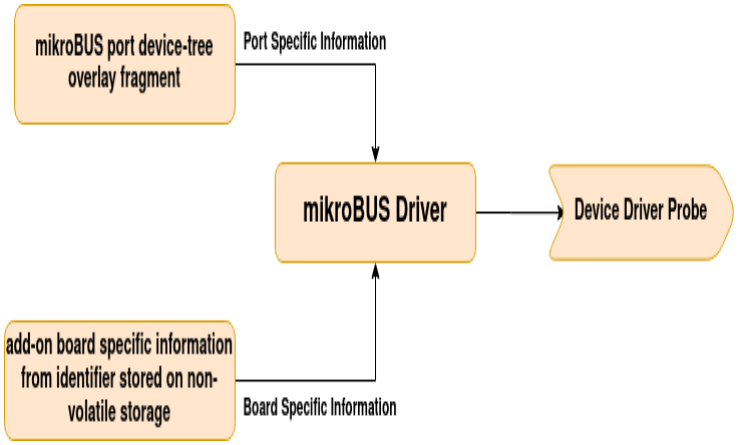
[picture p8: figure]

### Add-on board identifier : Extension to Greybus Manifest

- data structure which contains the manifest header along with a set of descriptors, used within greybus to describe the capabilities of a module.
- Source similar to INI style configuration.
- existing descriptors cannot accurately describe a device with enough information to perform the device-driver probe.
- majority of the add-on boards require interrupt information for sucessful device driver probe, few require additional named properties, few require named GPIOs.
- Addition of new descriptors : mikrobus-descriptor, device-descriptor, property-descriptor, uses same manifesto tool to generate the manifest binary.

### mikrobus-descriptor

- to describe the prior setup(pinmux, GPIO states) required on the mikroBUS for the add-on board.
- Each pin can take up its own default state or a GPIO state.

[mikrobus-descriptor]
pwm-state = 4
int-state = 1
rx-state = 7
tx-state = 7
scl-state = 6
sda-state = 6
mosi-state = 5
miso-state = 5
sck-state = 5
cs-state = 5
rst-state = 2
an-state = 1

### device-descriptor

- Used to describe a single device on an add-on board, contains fields from spi_board_info and i2c_board_info, can also fairly describe other devices relevant to the mikroBUS(serdev, platform devices).
- Fixed length descriptor, can have multiple instances of in a single add-on board manifest.

[device-descriptor 1]
driver-string-id = 3
protocol = 0x0b
mode = 0x0
reg = 0
max-speed-hz = 16000000
irq = 1
irq-type = 0x2

[string-descriptor 3]
string = enc28j60

### property-descriptor

- Used to pass additional named properties/GPIOs to device drivers, in case of properties the information is mapped to a struct property_entry under <linux/property.h> , in case of named GPIOs, the mikroBUS driver will map the values to the actual GPIOs and add a GPIOD lookup table for the device.

[property-descriptor 2]
name-string-id = 5
type = 0x05
value = <262144>

[string-descriptor 5]
string = size

### MikroBUS ports over Greybus : Proposal

- Dynamically adding mikrobus ports over greybus has the advantage of using different transports.
- Addition of new bundle class.
- The mikroBUS bundle will have Cport with protocols corresponding to each of the Busses(SPI,I2C,UART) and other peripherals(PWM, GPIOs) on the mikroBUS socket.

### Demo

- BeagleBoard.org PocketBeagle mikroBUS ports.
- PocketBeagle with Techlab Cape.
- BeagleBone Black Wireless with mikroBUS Cape.
- Writing manifests for mikroBUS add-on boards.

### Open Problems/Challenges

- Device Drivers not using Unified Device Properties API to fetch properties : drivers which uses device_property_read_* calls work but of_propert_read_u32 will not work , similarly devm_gpiod_get will work but of_get_named_gpio will not work.
- Device Drivers for which the corresponding device tree entries have child nodes cannot be described through property descriptors.
- Pinmux handling when adding mikroBUS ports through Greybus

### TODO

- SERDEV Devices Support (GNSS Add-on Boards)
- Update the identifier fetching mechanism according to mikroBUS v3 standard (add-on boards with on-board identifier mechanism).
- Greybus Bundle Class
- Documentation

# THANK YOU

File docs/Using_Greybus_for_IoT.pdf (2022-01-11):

Greybus for IOT
Alexandre Bailon ELCE Berlin 2016

## Table of Contents

1 | Introduction
2 | Greybus for IOT
3 | Greybus
4 | Samples
5 | Limitations / Know issues

## Project ARA

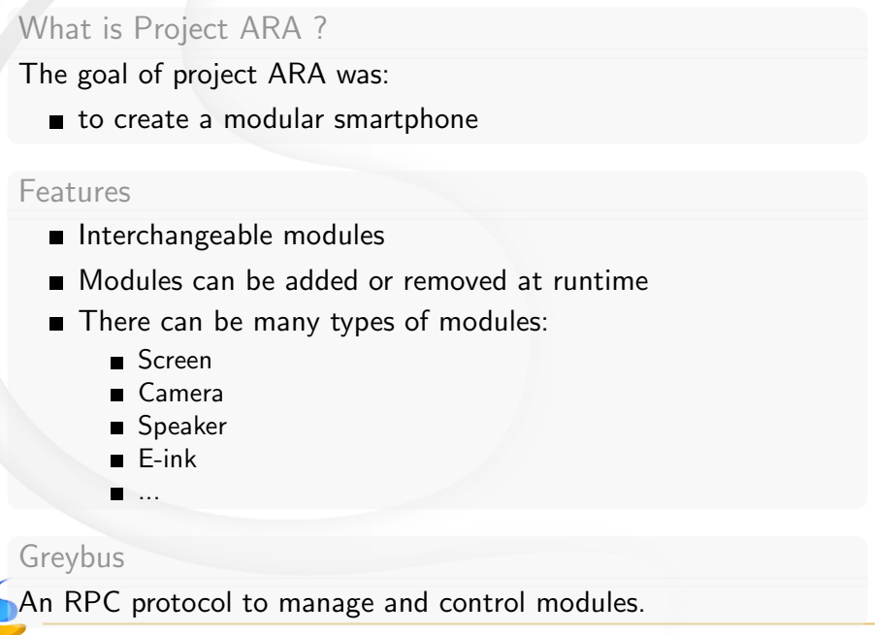
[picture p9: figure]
What is Project ARA ?; The goal of project ARA was:; to create a modular smartphone; Features; Interchangeable modules; There can be many types of modules:; Screen Camera Speaker E-ink ...; Greybus

Modules can be added or removed at runtime

An RPC protocol to manage and control modules.

## Greybus

Features
hotplug / hot unplug

Modules discovery
Class and protocols to talk to modules

## Greybus

Main classes
Camera

Audio
HID
I2C
SPI
GPIO
SDIO

PWM
UART

## Greybus for IOT

Why Greybus may be useful for IOT ?

Free
Highly documented
Will be merged to mainline kernel soon (currently in linux-next)

Keep the intelligence in the host
It just works!

## Greybus for IOT

CC26xx SensorTag

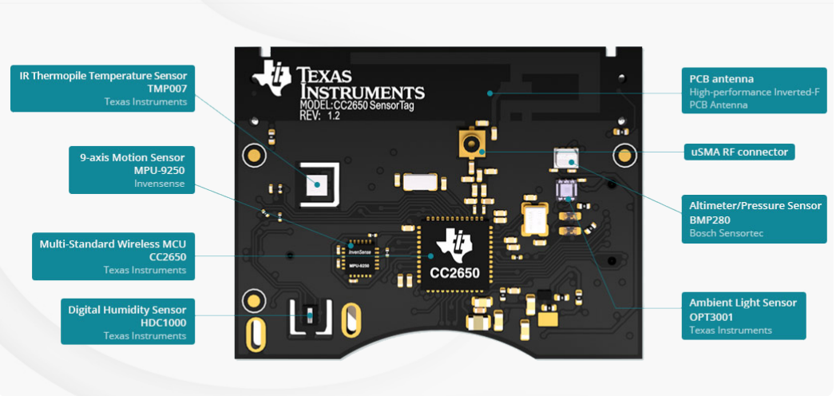
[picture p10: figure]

## Greybus for IOT

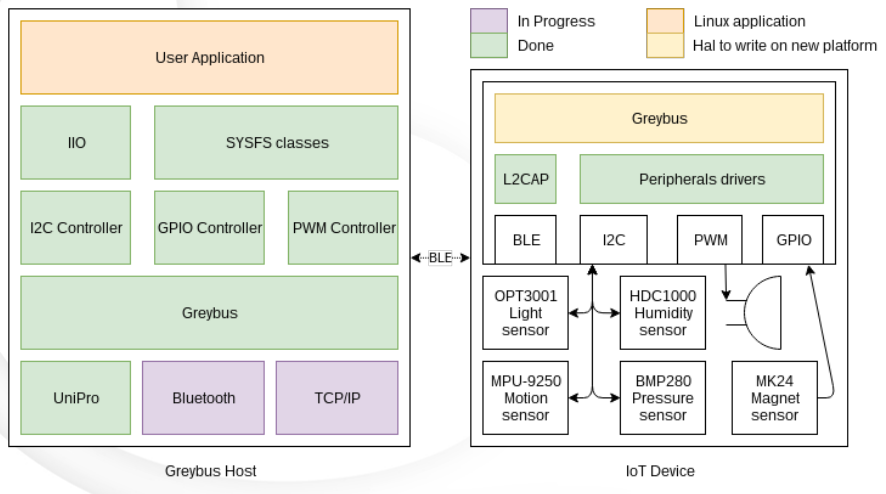
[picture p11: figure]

## Greybus: An application layer of UniPro

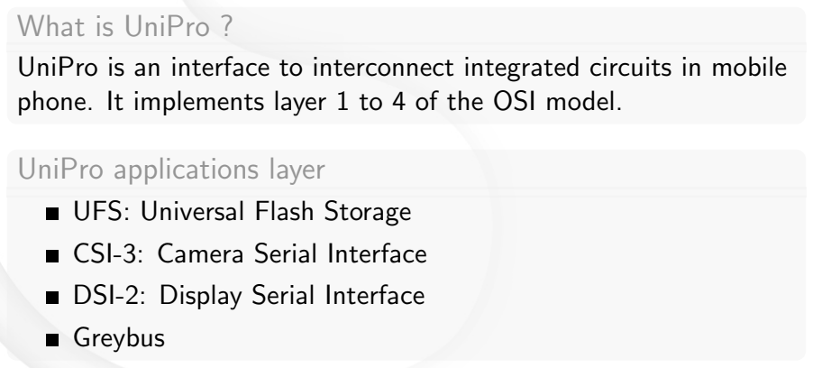
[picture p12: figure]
What is UniPro ?; UniPro applications layer; UFS: Universal Flash Storage; CSI-3: Camera Serial Interface; DSI-2: Display Serial Interface; Greybus

UniPro is an interface to interconnect integrated circuits in mobile phone. It implements layer 1 to 4 of the OSI model.

## Greybus: An application layer of UniPro

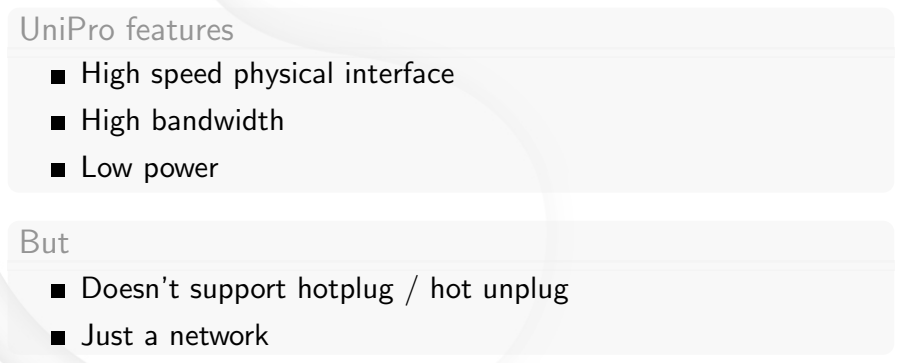
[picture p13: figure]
UniPro features; High speed physical interface; High bandwidth; Low power; But; Doesn’t support hotplug / hot unplug; Just a network

## Greybus / UniPro topology

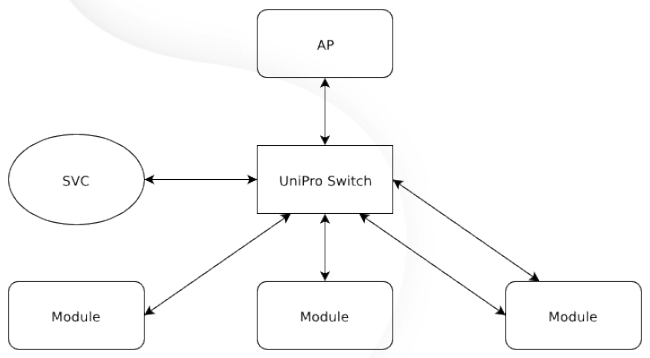
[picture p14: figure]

## Greybus / IOT topology

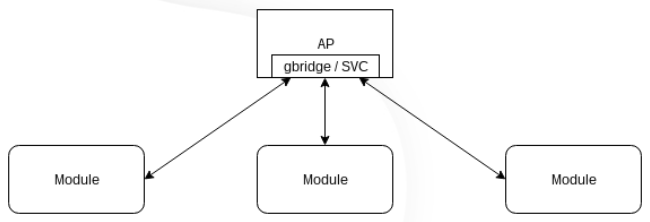
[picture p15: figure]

## Greybus

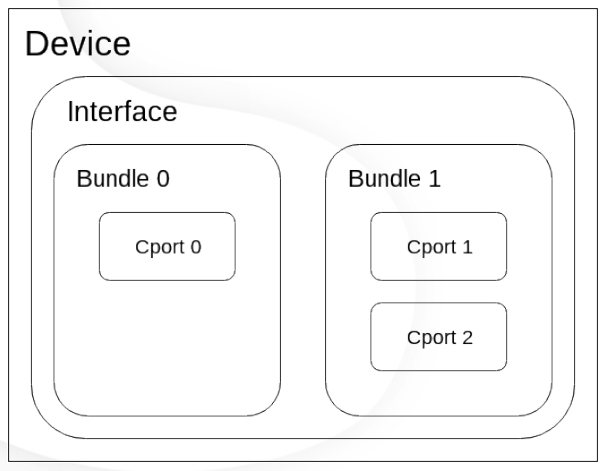
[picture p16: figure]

## Greybus sysfs

sysfs layout

/sys/bus/greybus/devices/
1-1: module
1-1.1: interface
1-1.1.1: bundle 1
1-1.1.ctrl: control bundle

## Greybus manifest

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

[ b u n dle−d e s c r i p t o r 1 ] c l a s s = 2

## Greybus GPIO sample

/sys/class/gpio
export
gpiochip506
unexport

cat /sys/class/gpio/gpiochip506/label greybus gpio

cat /sys/class/gpio/gpiochip506/ngpio 6

echo 506 >/sys/class/gpio/export
echo out >/sys/class/gpio/gpio506/direction echo 1 >/sys/class/gpio/gpio506/value

## Firmware sample

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

## Limitations

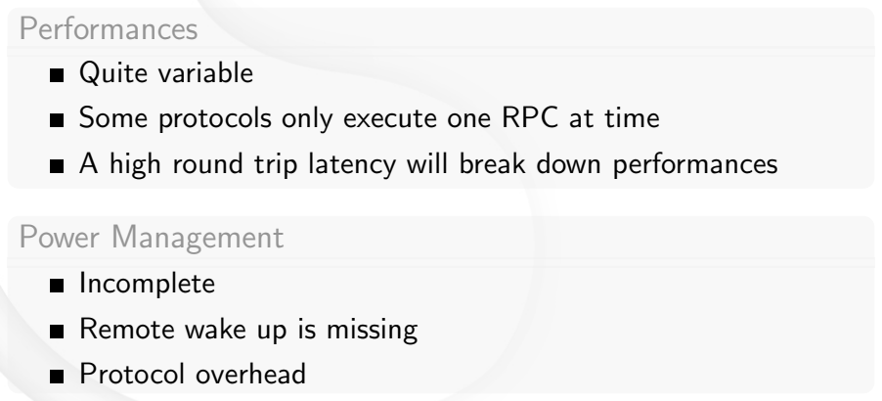
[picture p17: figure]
Performances; Quite variable; Power Management; Incomplete; Remote wake up is missing; Protocol overhead

Some protocols only execute one RPC at time

A high round trip latency will break down performances

## Limitations

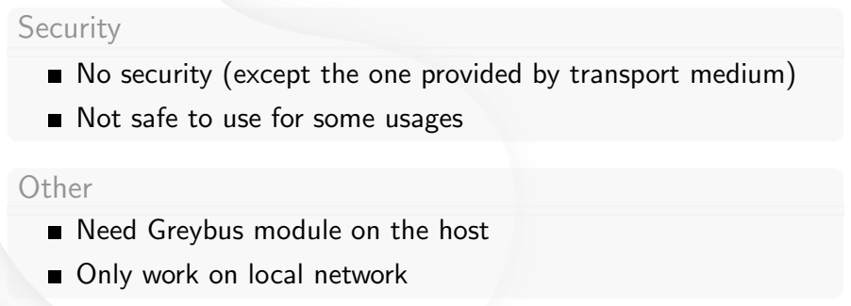
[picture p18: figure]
Security; Not safe to use for some usages; Other; Need Greybus module on the host; Only work on local network

No security (except the one provided by transport medium)

## Source code

Requirements

A Beagle Bone Black to run gbsim
A computer to run Greybus and gbridge

Sources
git clone https://github.com/anobli/gbridge.git -b ELCE git clone https://github.com/anobli/greybus.git -b ELCE git clone https://github.com/anobli/gbsim.git -b ELCE

## Next steps

Update gbridge and gbsim to work with the latest version of Greybus
Port Greybus to an OS for MCU.

## Contribute

Greybus was driven by Google to develop a module phone Now, we are free to do what ever we want

## Thank you

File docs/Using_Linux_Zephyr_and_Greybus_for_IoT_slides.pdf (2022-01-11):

# Using Zephyr, Linux and Greybus for IoT

## Chris Friedt

chris@friedt.co

# The Internet of Things

“A system of interrelated computing devices, mechanical and digital machines provided with unique identifiers and the ability to transfer data over a network without requiring human-to-human or human-to-computer interaction.”

-- Wikipedia

# Popular IoT Devices

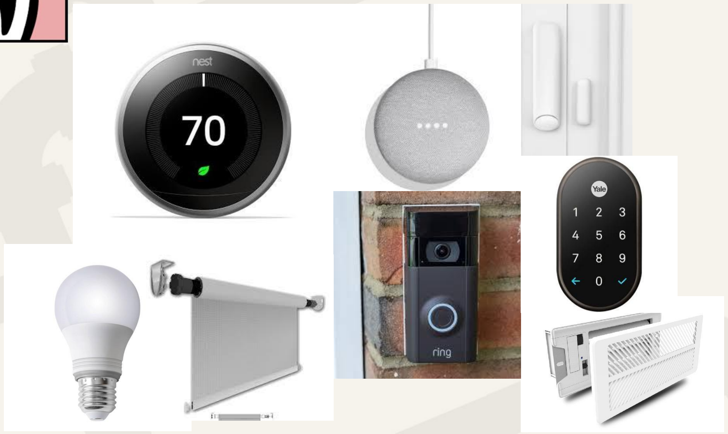
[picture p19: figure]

# Popular IoT Devices

- /dev/gpiochipN
- /dev/i2cN
- /dev/videodevN
- /sys/bus/iio/devices/iio:deviceN ...

# Discoverable Buses

1. Must be able to query devices attached to the bus
2. Services provided by each device must be categorized
3. Services should use a standard protocol

PCIe, USB, Ethernet are discoverable
GPIO, I2C, SPI are non-discoverable

# Project Ara

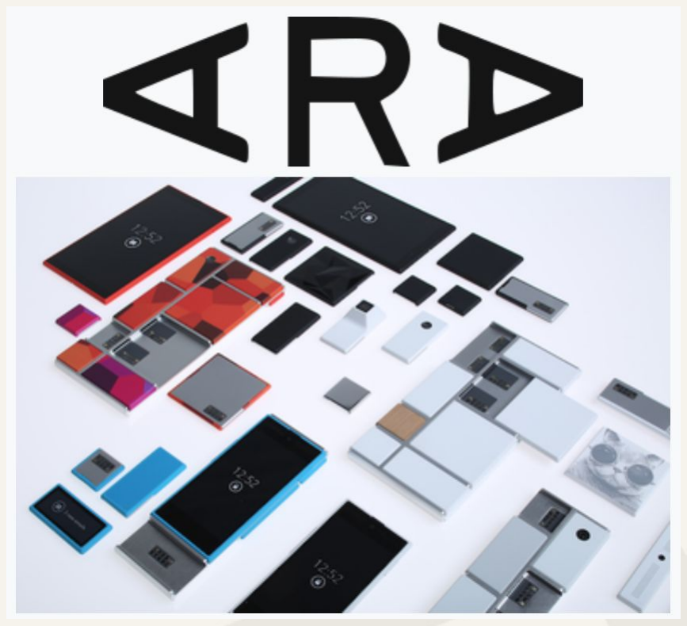
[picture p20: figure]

- Motorola Advanced
Technologies and
Projects (ATAP)
- Former DARPA
- Acquired by Google

# Project Ara

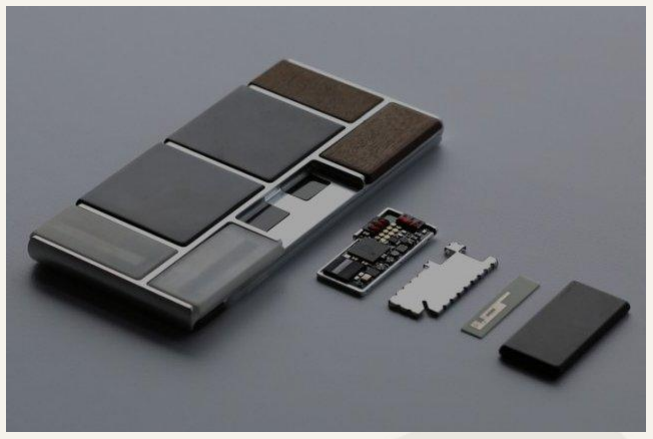
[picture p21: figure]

- Modules could use
GPIO, I2C, SPI, MIPI,
etc.
- UniPro High-speed
Interconnect
- Shelved in 2016

# Project Ara

Due to the application-layer protocol being used on top of UniPro for Project Ara, all of those non-discoverable buses that we had been using in embedded for so long had suddenly become discoverable*.

*with some exceptions

# Greybus

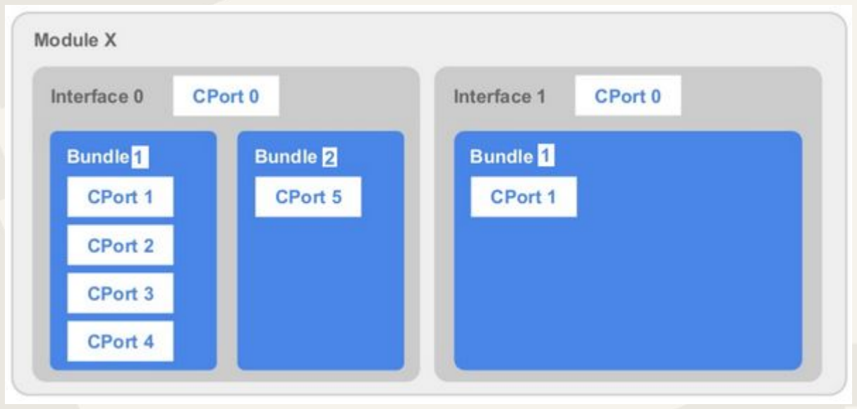
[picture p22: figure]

# Greybus Manifest

[manifest-header]
version-major = 0
version-minor = 1

[interface-descriptor]
vendor-string-id = 0x1
vendor-product-id = 0x2

; Interface vendor string
[string-descriptor 0x1]
string = Zephyr Project RTOS

; Interface product string [string-descriptor 0x2]
string = Greybus Service Sample Application

; 'Control' class on Bundle 0 [bundle-descriptor 0x0]
class = 0x0

; 'Bridged PHY' class on Bundle 1 [bundle-descriptor 0x1]
class = 0xa

; 'Bridged PHY' class on Bundle 2 [bundle-descriptor 0x2]
class = 0xa

; 'Bridged PHY' class on Bundle 3 [bundle-descriptor 0x3]
class = 0xa

; 'Control' protocol on CPort 0 [cport-descriptor 0x0]
bundle = 0x0
protocol = 0x0

; 'GPIO' protocol on CPort 1 [cport-descriptor 0x1]
bundle = 0x1
protocol = 0x2

; 'I2C' protocol on CPort 2 [cport-descriptor 0x2]
bundle = 0x2
protocol = 0x3

; 'SPI' protocol on CPort 3 [cport-descriptor 0x3]
bundle = 0x3
protocol = 0xb

# Greybus Special Entities

AP (Applications Processor)
- Lives inside the Linux kernel
- Communicates via UniPro using AP Bridge
- Administrates the Greybus network

SVC (Supervisory Controller)
- Notify AP when modules are inserted or removed
- Configure and Control the transport (e.g. UniPro)

# Gbridge: Greybus for IoT

- Alexandre Baillon, BayLibre
- ELCE 2016, Berlin (https://www.youtube.com/watch?v=7H50pv-4YXw)
- Plumbers 2019, Lisbon (https://linuxplumbersconf.org/event/4/sessions/56/attachments/263/627/greybus_for_iot.pdf)
- Implement SVC in software
- Communicate with AP (Linux kernel) via Netlink
- gb-netlink kernel module

https://github.com/anobli/gbridge

https://github.com/anobli/greybus/tree/gb_netlink | 12

# Project Ara Topology

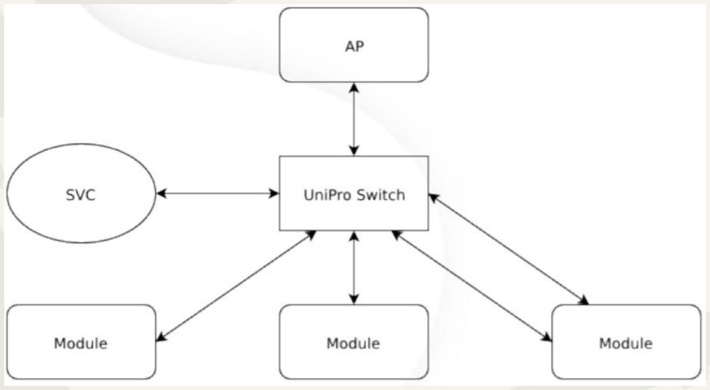
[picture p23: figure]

# Gbridge Topology

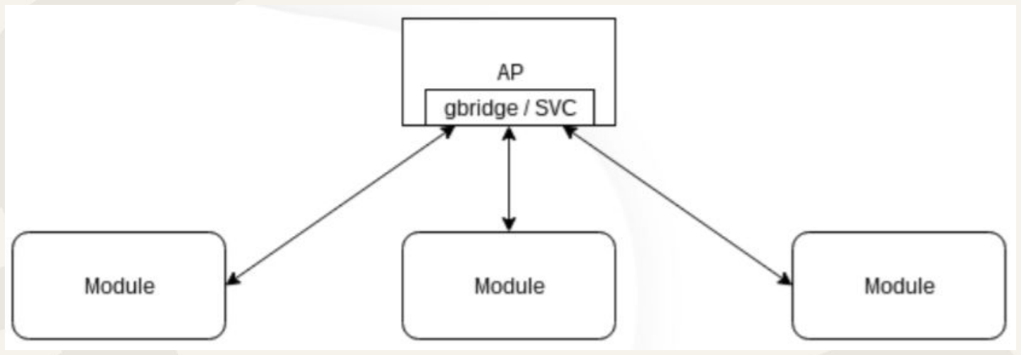
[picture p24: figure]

# Gbridge Host Controllers

- UART (CPort buried in reserved bits)
- BLE (using Generic Attribute Profile?)
- GB Sim (simulated Greybus module using BBB)
- TCP/IP (mDNS discovery, CPorts as seq TCP ports )

# Gbridge Host Controllers

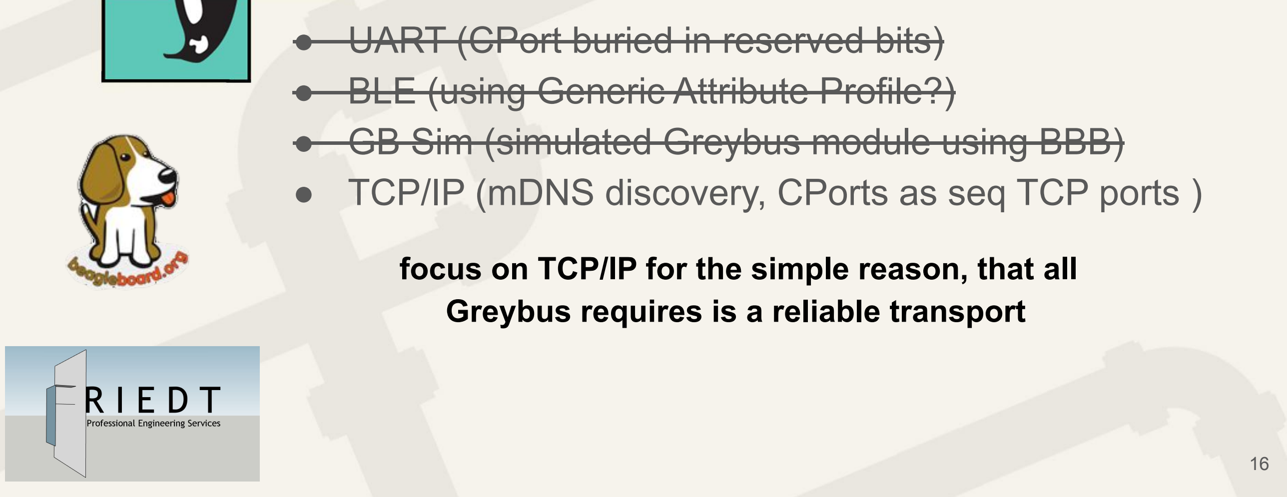
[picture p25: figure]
● UART (CPort buried in reserved bits)

- BLE (using Generic Attribute Profile?)
- GB Sim (simulated Greybus module using BBB)
- TCP/IP (mDNS discovery, CPorts as seq TCP ports )

focus on TCP/IP for the simple reason, that all Greybus requires is a reliable transport

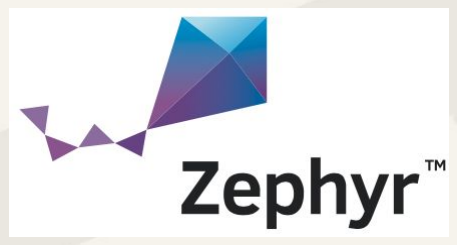
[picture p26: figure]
Zephyr

- Kconfig
- Menuconfig
- Shell!
- Documentation!
- Community!

Features:

- BSD Sockets API
- Network protocols
- 6LowPAN
- IP over everything
- POSIX threads
- Device Tree

# Zephyr Menuconfig

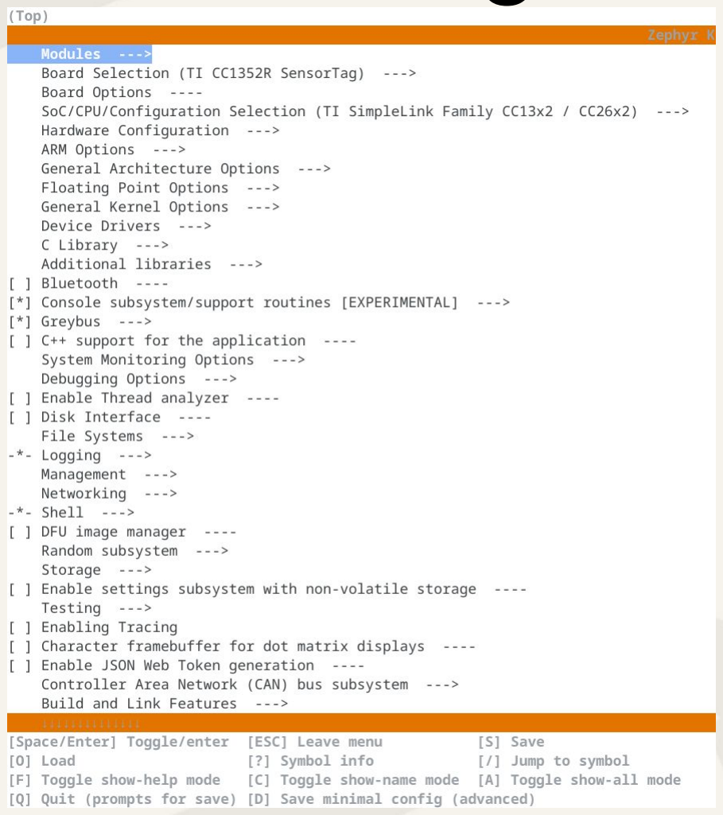
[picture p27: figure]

- $ ninja -C build
menuconfig
- familiar look & feel
- easily find Kconfig
symbols and info

# Zephyr & Device Tree

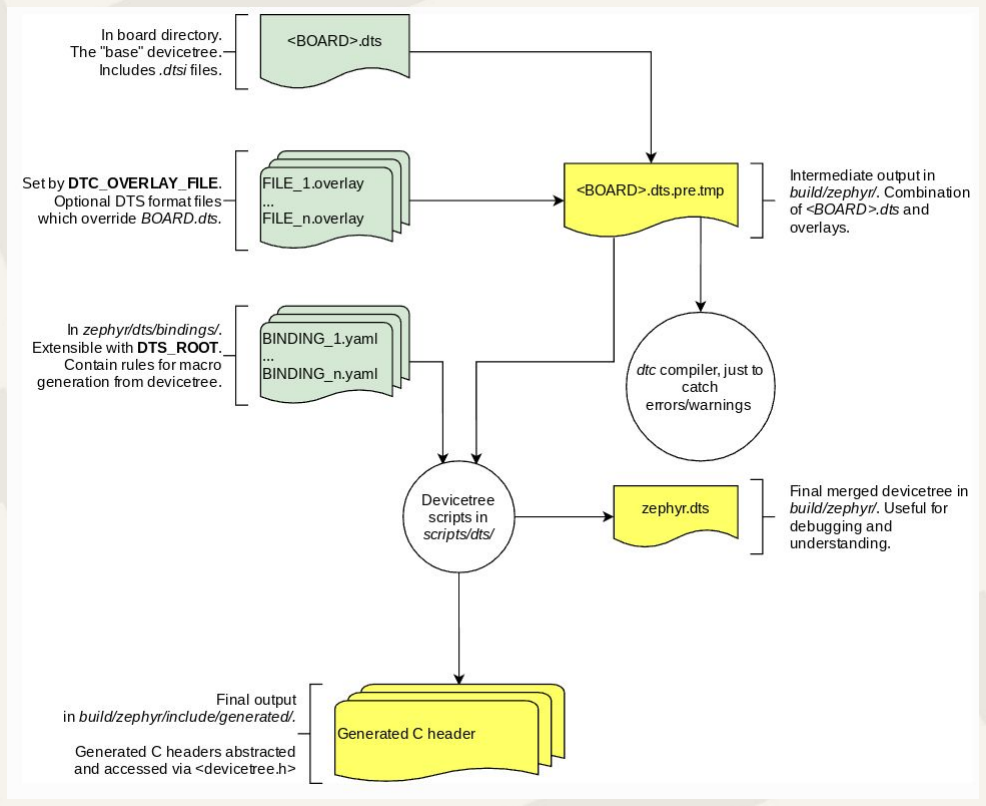
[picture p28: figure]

# Porting Greybus to Zephyr

The original NuttX Greybus implementation had relatively few runtime and OS requirements:
- POSIX threads
- malloc / heap allocation
- unistd.h sleep routines
- qsort
- atomics
- linked-lists

# Porting Greybus to Zephyr

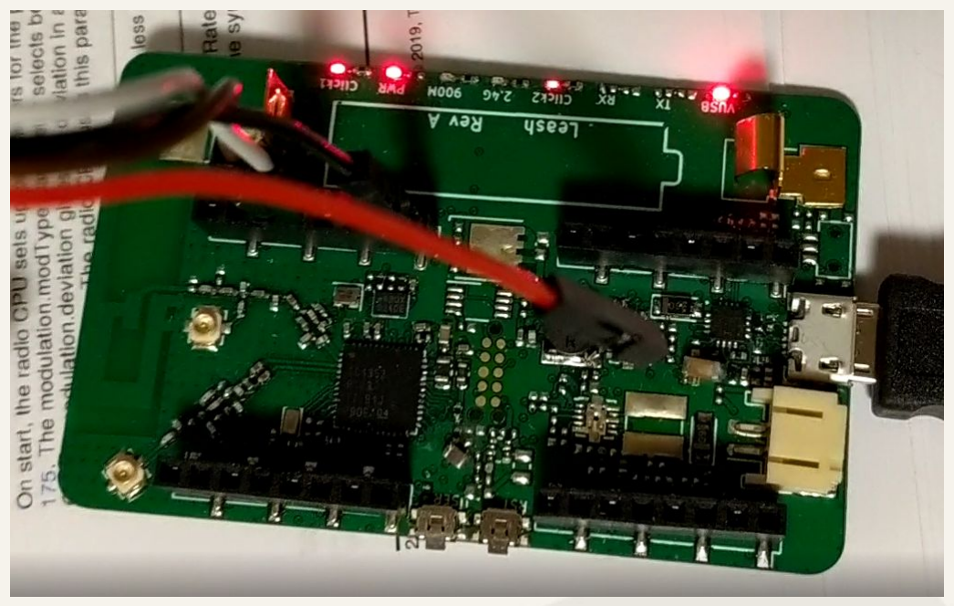
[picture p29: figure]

- Port done last year
- Sneak preview of Leash
PCB
- Blinking LEDs
- UART only
- Demo hardcoded a lot
of things

# Zephyr & Device Tree

- DT is the single source of all hardware configuration
- Includes virtual hardware
- DT bindings compatible with Linux & other OS’s
- Preprocessed DT used to generate C header
- All DT information is compile-time const
- Unused DT nodes occupy 0 bytes in ROM
- Cannot parse DT at runtime

# Zephyr Devices

- Devices instantiated by macro
#define DT_DRV_COMPAT my_dt_label #include <devicetree.h>

#define MY_FUN(_num) ...

DT_INST_FOREACH_STATUS_OKAY(MY_FUN) (https://docs.zephyrproject.org/latest/reference/devicetree/index.html#c.DT_INST_FOREACH_STATUS_OKAY)
- All Zephyr devices have
- Mandatory init function (ro)
- optional config (ro), data (rw), api (ro)

# Zephyr Devices + Greybus

Integration Options:

1. 👎require users to maintain a Greybus Manifest AND

Device Tree AND ensure that the two are consistent

2. 👍somehow generate Manifest from Device Tree or

vice-versa

## Greybus Manifest ≠> Device Tree 👎

- Insufficient platform metadata to go in this direction
- Implies that 10’s (100’s?) of board-specific init functions exist
- Possibly requires runtime parsing of DT
- Not possible in Zephyr
- Possibly requires handling permutations of enabled device instances
- Undesired ROM footprint

## Device Tree => Greybus Manifest 👍

- DT is a Superset of what is required for Manifest
- Conveniently handles nested relationships
- Possibility of supporting multiple, isolated Greybus instances
- Handle the base case for a given platform
- Allow User Manifests (e.g. in EEPROM) to override default given a fixed pinmux / pinconf

# Greybus (DT)

#include <dt-bindings/greybus/greybus.h> / {

greybus0: greybus0 {
compatible = "zephyr,greybus"; label = "GREYBUS_0";
};
};
&greybus0 {
status = "okay";
version-major = <GREYBUS_VERSION_MAJOR>; version-minor = <GREYBUS_VERSION_MINOR>; /* … interfaces … */
};

# Greybus String (DT)

&greybus0 {
/* ... */
gbstring1: gbstring1 {
status = "okay";
compatible = "zephyr,greybus-string"; /* string id 0 is invalid */
id = <1>;
greybus-string = "Zephyr Project RTOS"; };
/* ... */
};

# Greybus Interface (DT)

&greybus0 {
/* ... */
gbinterface0 {
status = "okay";
compatible = "zephyr,greybus-interface"; /* give phandle rather than integer */ vendor-string-id = <&gbstring1>; product-string-id = <&gbstring2>; greybus-interface;
};
/* ... */
};

# Greybus Bundle (DT)

&greybus0 {
/* ... */
gbbundle0 {
status = "okay";
compatible = "zephyr,greybus-bundle";
id = <42>; /* 0 is reserved for the Control Bundle */ bundle-class = </* fixed based on child CPorts */>; /* … CPorts nested inside of bundles … */
};
/* ... */
};

# GPIO CPort (DT)

&greybus0 {
gbbundle0 {
/* ... */
bundle-class = <BUNDLE_CLASS_BRIDGED_PHY>; gbgpio0 {
status = "okay";
compatible = "zephyr,greybus-gpio-controller"; greybus-gpio-controller = <&gpio0>;
id = <1>;
cport-protocol = <CPORT_PROTOCOL_GPIO>; };
};
};

# I2C CPort (DT)

&greybus0 {
gbbundle0 {
/* ... */
bundle-class = <BUNDLE_CLASS_BRIDGED_PHY>; gbi2c0 {
status = "okay";
compatible = "zephyr,greybus-i2c-controller"; greybus-i2c-controller = <&i2c0>;
id = <1>;
cport-protocol = <CPORT_PROTOCOL_I2C>; };
};
};

# SPI CPort (DT)

gbspi0 {
status = "okay";
compatible = "zephyr,greybus-spi-controller"; greybus-spi-controller = <&spi0>;
id = <1>; /* CPort ID */
cport-protocol = <CPORT_PROTOCOL_SPI>;
/* Entries for struct gb_spi_master_config_response */ bpw-mask = <0xff>;
min-speed-hz = <2000000>;
max-speed-hz = <6000000>;
mode = <0>;
flags = <0>;
/* greybus spi devices */

# SPI Device (DT)

gbspi0 {
gbspidev0 {
status = "okay";
compatible = "zephyr,greybus-spi-peripheral";
cs = <0>; /* used as gpio array index in spi phandle of parent device */ /* Entries for struct gb_spi_device_config_response */
mode = <0>;
bpw = <8>;
max-speed-hz = <8000000>;
device-type = <GB_SPI_SPI_DEV>; device-name = "ADXL362";
};
};

# Fake GPIO, I2C, & SPI

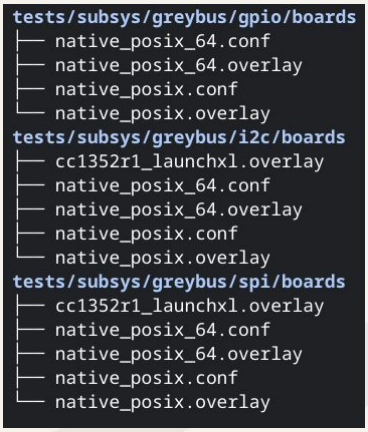
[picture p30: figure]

Another core philosophy of Zephyr is to test everything

Development of DT
bindings was mostly driven via test cases using “fake” device interfaces.

# Greybus System Service

- Leveraged Device Tree to automatically generate the manifest.
- Leveraged Device Tree to automatically create virtual
- Why not also automatically start a Greybus Service?
- Not a single line of code required
- Declare GB resources in Device Tree
- Support for drivers in Kconfig

# Linux Driver Ecosystem

- Keep the intelligence in the host
- Vaishnav Ma has done a great job of re-using existing Linux drivers
- Same driver works regardless of Wireless SoC
- Drivers get updated & maintained in the Linux kernel

# Greybus in Linux: a Proposal

- Currently with the Gbridge Topology, the SVC lives in userspace and effectively routes messages between AP and other Greybus devices
- By using a connected socket (or really any file descriptor), we can move the SVC into the kernel
- Gbridge would then stay in userspace as mainly an auth + session broker

# Linux: WPANUSB

- being developed further as more of a generic interface to IEEE 802.15.4 USB hardware
- Enable Linux & RTOS devs, as well as HW manufacturers
- Originally developed by Andrei Emeltchenko (Intel)
- Already supported in Zephyr (less extensions below)
- Commitment to add support in RIOT OS (Koen Zandberg)
- Add GET_EXTENDED_ADDR command
- Add GET_CAPABILITIES command
- Set LBT in USB
- Set frame retries in USB (for controllers lacking auto-ack)

# Open Problems: Greybus

- authentication: support multiple mechanisms
- public key auth (in progress)
- encryption: standardize on one or two methods
- aes-128 (in progress)
- auth negotiation
- commissioning, joining, rejoining
- cloud: management of devices at scale

# Open Problems: Zephyr

- pthread: dynamic stack allocation (in progress)
- dt-bindings: greybus: mask for fixed pin direction
- dt-bindings: greybus: pwm, adc, camera, ..
- ieee802154: cc1352r: TI RF driverlib (in progress)
- ieee802154: cc1352r: subghz (in progress)
- ble: cc1352r: split-stack driver (in progress)
- proper Zephyr module repo for Greybus
- init: dt: deterministic module loading (in progress)

# Open Problems: Linux

- gbridge: discovery should be ip-version agnostic
- gbridge: move svc in-kernel
- greybus: pass fd + session key to kernel post auth
- wpanusb: feature implementation, test, & lkml patch
- opt3001: specify i2c bus / addr with modprobe

# Additional Resources

Current development branch for Greybus in Zephyr https://github.com/cfriedt/zephyr (branch greybus-service-lpc2020) Zephyr Getting Started Guide / Slack (https://zephyrproject.slack.com/) https://docs.zephyrproject.org/latest/getting_started/index.html BeagleConnect (Hardware Rev C) / Slack (https://beagleboard.slack.com/)

https://github.com/jadonk/beagleconnec

Board | Topic(s) | Instructions | Video
nRF52840 DK | GPIO LED BLE | https://bit.ly/2NR0NCI | https://youtu.be/Y_6y6gpZ2GA
CC1352R1 LaunchXL | GPIO LED IEEE 802.15.4
CC1352R SensorTag | GPIO LED I2C SPI IEEE 802.15.4
https://bit.ly/31FQNV4 | https://youtu.be/hd60CbiUN1g
https://bit.ly/3aZK7ne | https://youtu.be/6SNkjiDJ3KY

# Conclusion

- Now is the time to start contributing!
- Developers Wanted!! - Zephyr, Linux, Cloud, BeagleConnect
- Greybus itself may well begin to evolve very soon..

Q & A

# Thank You!

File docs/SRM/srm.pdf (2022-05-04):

# BeagleConnect™ C5 System Reference Manual

# Table of Contents

3.5. Install the latest software image for BeagleBone Green Gateway ... 16
3.7. Install Zephyr development tools on BeagleBone Green Gateway .. 18
3.8. Build applications for BeagleConnect Freedom on BeagleBone

iii

BeagleConnect™ C5 System Reference Manual

3.9. Flash applications to BeagleConnect Freedom from BeagleBone
4.6. BeagleConnect™ Greybus demo using BeagleConnect™
4.8. Flash BeagleConnect™ Freedom node device with Greybus

iv

BeagleConnect™ C5 System Reference Manual

4.17.3. Set the 802.15.4 Physical and Link-Layer Parameters ..... 39

v

vi

# The Story Behind BeagleConnect™

There are many stories behind BeagleConnect™, mine is just one of them. It begins with my mom teaching me about computers. She told me I could anything I wanted with ours, as long as I didn’t open the case. This was the late-70s/ early-80s, so all she needed to do was put her floppy disk¹ (https://en.wikipedia.org/wiki/Floppy_disk)
away and there wasn’t
risk of me damaging the family photo album or her ability to do her work the next day. I listened and learned from her the basics of programming, but it wasn’t long before I wanted to take the computer apart.
Initially exploring Getting Started in Electronics² (http://www.forrestmims.org/)
satisfied my itch for quite a while. Eventually, I got a Commodore 64 and began connecting voice synthesizer ICs to it. My interest in computers and electronics flourished into an electrical engineering degree and a long career in the semiconductor industry.

Over this time, I’ve become more and more alarmed with the progress of technology. Now, to be clear, I love technology. I love innovation and invention. It is just that some things have evolved in a sort of tunnel-vision, without bringing everyone along.

But, what about keyboard users? As graphical user interfaces and mice took over computers, they rapidly became almost unusable by my mom. She typed well, but the dexterity to move a mouse aluded her. To satisfy the need to interact with locations on the screen, she adopted using a joystick and her productivity came to a crawl. How is it that such assumptions could be made impacting all computer users without any thoughtful provisions for what already worked?

1
https://en.wikipedia.org/wiki/Floppy_disk 2
http://www.forrestmims.org/

vii

viii

1

# BeagleConnect™ Introduction

BeagleConnect™ is a revolutionary technology virtually eliminating low-level software development for IoT¹ (https://en.wikipedia.org/wiki/Internet_of_things)

and IIoT² (https://en.wikipedia.org/wiki/Industrial_internet_of_things)
applications, such as building automation, factory automation, home automation, and scientific data acquisition. While numerous IoT and IIoT solutions available today provide massive software libraries for microcontrollers 3

supporting a limited body of sensors⁴ (https://en.wikipedia.org/wiki/Sensor)

, actuators⁵ (https://en.wikipedia.org/wiki/Actuator)
and indicators⁶ (https://en.wikipedia.org/wiki/Indicator_(distance_amplifying_instrument))
as well as libraries for communicating over various networks, BeagleConnect simply eliminates the need for these libraries by shifting the burden into the most massive and collaborative software project of all time, the Linux kernel⁷ (https://en.wikipedia.org/wiki/Linux_kernel)

1
https://en.wikipedia.org/wiki/Internet_of_things
2
https://en.wikipedia.org/wiki/Industrial_internet_of_things
3Complexity can be seen by exploring Arduino sensor libraries (https://www.arduino.cc/reference/en/libraries/category/sensors/) [https://www.arduino.cc/reference/en/libraries/category/sensors/] (https://www.arduino.cc/reference/en/libraries/category/sensors/)
4
https://en.wikipedia.org/wiki/Sensor
5
https://en.wikipedia.org/wiki/Actuator
6
https://en.wikipedia.org/wiki/Indicator_(distance_amplifying_instrument) 7
https://en.wikipedia.org/wiki/Linux_kernel

BeagleConnect™ experience


These are the tools used to automate things in scientific data collection⁸ (https://en.wikipedia.org/wiki/Data_collection_system) , data
science⁹ (https://en.wikipedia.org/wiki/Data_science)

, mechatronics¹⁰, (https://en.wikipedia.org/wiki/Mechatronics) and IoT¹¹ (https://en.wikipedia.org/wiki/Internet_of_things)

BeagleConnect™ technology solves:

- The need to write software to add a large set of diverse devices to your system,
- The need to maintain the software with security updates,
- The need to rapidly prototype using off-the-shelf software and hardware without wiring,
- The need to connect to devices using long-range, low-power wireless, and
- The need to produce high-volume custom hardware cost-optimized for your requirements.

### 1.1. BeagleConnect™ experience

BeagleConnect™ provides a scalable experience for interacting with the physical world.

8
https://en.wikipedia.org/wiki/Data_collection_system
9
https://en.wikipedia.org/wiki/Data_science

### 10 https://en.wikipedia.org/wiki/Mechatronics

11
https://en.wikipedia.org/wiki/Internet_of_things

BeagleConnect™ experience

The term BeagleConnect™ refers to a technology comprising of a family of boards, a collection of Linux kernel drivers, microcontroller firmware, a communication protocol, and system-level integration to automation software tools. More specific terms will be applied in the architecture details. The term is also used here to represent the experience introduced to users through the initial BeagleConnect™ Freedom product consisting of a board and case which ships programmed and ready to be used.
For scientists, we are integrating Jupyter Notebook¹² (https://jupyter.org/) with the data streams from any of hundreds of sensor options, including vibration¹³ (https://www.mikroe.com/click/sensors/force)

, gas detection¹⁴ (https://www.mikroe.com/click/sensors/gas)
,
biometrics¹⁵ (https://www.mikroe.com/click/sensors/biometrics) and more¹⁶. (https://www.mikroe.com/click/sensors) These data streams can be stored in simple data files¹⁷ (https://en.wikipedia.org/wiki/Comma-separated_values) or processed and visualized.

#TODO: provide images demonstrating Jupyter Notebook visualization

For embedded systems developers, data is easily extrated using the standard IIO¹⁸ (https://www.kernel.org/doc/html/latest/driver-api/iio/index.html) interface provided by the Linux kernel¹⁹ (https://kernel.org) running on the gateway using any of hundreds of programming languages and environments, without writing a line of microcontroller firmware. The Linux environment provides opportunities for high-level remote management using tools like Balena²⁰ (https://balena.io) with applications deployed in Docker²¹ (https://docker.io) containers.

#TODO: provide image illustrating remote management

The hardware and software are fully open source, providing for scalability and a lack of vendor lock-in.

12 https://jupyter.org/ 13 https://www.mikroe.com/click/sensors/force 14 https://www.mikroe.com/click/sensors/gas 15 https://www.mikroe.com/click/sensors/biometrics 16 https://www.mikroe.com/click/sensors 17 https://en.wikipedia.org/wiki/Comma-separated_values 18 https://www.kernel.org/doc/html/latest/driver-api/iio/index.html 19 https://kernel.org 20 https://balena.io 21 https://docker.io

BeagleConnect™ hardware

For DevOps…

For home automaters, integration into WebThings (https://webthings.io)

22…

#TODO: think a bit more about this section with some feedback from Cathy.

### 1.2. BeagleConnect™ hardware

### 1.2.1. BeagleConnect™ Freedom


BeagleConnect™ Freedom enables wirelessly adding new device nodes and is targeted to cost initially around US$20 with a roadmap to variants as low as US$1.

The initial BeagleConnect™ Freedom production release will:

- Support at least 100 mikroBUS²³-based (https://elinux.org/Mikrobus) Click boards from Mikroelectronika²⁴ (https://mikroe.com/click)
,
- Work with Bluetooth Low Energy (BLE)²⁵-enabled (https://en.wikipedia.org/wiki/Bluetooth_Low_Energy) Linux computers at 2.4GHz,

### 22 https://webthings.io 23 https://elinux.org/Mikrobus 24 https://mikroe.com/click 25 https://en.wikipedia.org/wiki/Bluetooth_Low_Energy

BeagleConnect™ Freedom beta kit

- Work with long-range sub-1GHz IEEE 802.15.4 wireless connections²⁶ (https://en.wikipedia.org/wiki/IEEE_802.15.4) at 500 meters with data rates of 1kbps, and
- Work with a low-cost BeagleBoard.org Linux single-board computer (SBC)²⁷ (https://en.wikipedia.org/wiki/Single-board_computer) as a BeagleConnect™ gateway device and work with at least 10 other BeagleConnect™ node devices each supporting 2 add-on sensor, actuator or indicator devices.

Future releases will be collaborated with the community, evolve dynamically, and contain additional functionality. The goal is to support over 500 add-on devices within the first year after the initial release.

### 1.2.2. BeagleConnect™ Freedom beta kit

A small number of beta kits have been assembled with BeagleConnect™ Freedom rev C5 boards, which is the version that should be taken to production.

The kit includes:

- 1x Seeed BeagleBone® Green Gateway²⁸ (https://wiki.seeedstudio.com/BeagleBone-Green-Gateway/) (board, USB cable)
- 3x BeagleConnect™ Freedom (board, attenna, USB cable)
- 1x MikroElektronikia Click ID Board²⁹ (https://www.mikroe.com/unique-id-click)

To get started with this kit, see Section 4.6, “BeagleConnect™ Greybus demo using BeagleConnect™ Freedom”.

### 1.3. BeagleConnect™ Mobile Gateway

This is a work-in-progress that will be released as the first integrated BeagleConnect™ gateway. It is possible to assemble a gateway with any Linux computer, but this computer will ship setup and ready to go.

The gateway is built from:

- BeagleBoard.org PocketBeagle,

### 26 https://en.wikipedia.org/wiki/IEEE_802.15.4 27 https://en.wikipedia.org/wiki/Single-board_computer 28 https://wiki.seeedstudio.com/BeagleBone-Green-Gateway/ 29 https://www.mikroe.com/unique-id-click

Architecture

- BeagleConnect™ Freedom,
- a cellular modem,
- a USB WiFi dongle,
- antennas, and
- an enclosure.

### 1.3.1. Architecture

### 1.3.2. BeagleConnect™ Freedom

BeagleConnect™ Freedom is based on the TI CC1352³⁰ (https://www.ti.com/product/CC1352R) and is the first available BeagleConnect™ solution. It implements:

- BeagleConnect™ gateway device function for Sub-GHz 802.15.4 long-range wireless
- BeagleConnect™ node device function for Bluetooth Low-Energe (BLE) and Sub-GHz 802.15.4 long range wireless
- USB-based serial console and firmware updates
- 2x mikroBUS sockets³¹ (https://www.mikroe.com/mikrobus) with BeagleConnect™ protocol support

#TODO: provide image of BeagleConnect™ Freedom in a case with a hand for size perspective

### 1.3.3. What makes BeagleConnect™ new and different?

BeagleConnect™ solves IoT in a different and better way than any previous solution.

### 1.3.4. The device interface software is already done

BeagleConnect™ uses the collaboratively developed Linux kernel to contain the intelligence required to speak to these devices (sensors, actuators, and indicators), rather than relying on writing code on a microcontroller specific to these devices. Some existing solutions rely on large libraries of microcontroller

### 30 https://www.ti.com/product/CC1352R 31 https://www.mikroe.com/mikrobus

On-going maintenance

code, but the integration of communications, maintenance of the library with a limited set of developer resources and other constraints to be explained later make those other solutions less suitable for rapid prototyping than BeagleConnect™.

Linux presents these devices abstractly in ways that are self-descriptive. Add an accelerometer to the system and you are automatically fed a stream of force values in standard units. Add a temperature sensor and you get it back in standard units again. Same for sensing magnetism, proximity, color, light, frequency, orientation, or multitudes of other inputs. Indicators, such as LEDs and displays, are similarly abstracted with a few other kernel subsystems and more advanced actuators with and without feedback control are in the process of being developed and standardized. In places where proper Linux kernel drivers exist, no new specialized code needs to be created for the devices.

Bottom line: For hundreds of devices, users won’t have to write a single line of code to add them their systems. The automation code they do write can be extremely simple, done with graphical tools or in any language they want. Maintenance of the code is centralized in a small reusable set of microcontroller firmware and the Linux kernel, which is highly peer reviewed under a highly-regarded governance model³² (https://wiki.p2pfoundation.net/Linux_-_Governance)

### 1.3.5. On-going maintenance

Because there isn’t code specific to any given network-of-devices configuration, we can all leverage the same software code base. This means that when someone fixes an issue in either BeagleConnect™ firmware or the Linux kernel, you benefit from the fixes. The source for BeagleConnect™ firmware is also submitted to the Zephyr Project³³ (https://www.zephyrproject.org/) upstream, further increasing the user base. Additionally, we will maintain stable branches of the software and provide mechanisms for updating firmware on BeagleConnect™ hardware. With a single, relatively small firmware load, the potential for bugs is kept low. With large user base, the potential for discovering and resolving bugs is high.

### 32 https://wiki.p2pfoundation.net/Linux_-_Governance 33 https://www.zephyrproject.org/

Rapid prototyping without wiring

### 1.3.6. Rapid prototyping without wiring

BeagleConnect™ utilizes the mikroBUS standard³⁴. (https://elinux.org/Mikrobus) The mikroBUS standard interface is flexible enough for almost any typical sensor or indicator with hundreds of devices available.

Currently, we have support in the Linux kernel for a bit over 100 Click mikroBUS add-on boards from Mikroelektronika and are working with Mikroelektronika on a updated version of the specification for these boards to self-identify. Further, eventually the vast majority of over 800 currently available Click mikroBUS add-on boards will be supported as well as the hundreds of compliant boards developed every year.

### 1.3.7. Long-range, low-power wireless

BeagleConnect™ Freedom wireless hardware is built around a TI CC1352³⁵ (http://www.ti.com/product/CC1352R) multiprotocol and multi-band Sub-1 GHz and 2.4-GHz wireless microcontroller (MCU). CC1352R includes a 48-MHz Arm® Cortex®-M4F processor, 352KB Flash, 256KB ROM, 8KB Cache SRAM, 80KB of ultra-low leakage SRAM, and Over-the-Air³⁶ (https://en.wikipedia.org/wiki/Over-the-air_programming) upgrades (OTA).

### 1.3.8. Full customization possible

BeagleConnect™ utilizes open source hardware³⁷ (https://www.oshwa.org/definition/) and open source software³⁸ (https://en.wikipedia.org/wiki/Open-source_software) ,
making it possible to optimize hardware and software implementations and sourcing to meet end-product requirements. BeagleConnect™ is meant to enable rapid-prototyping and not to necessarily satisfy any particular end-product’s requirements, but with full considerations for go-to-market needs.

Each BeagleBoard.org BeagleConnect™ solution will be:

- Readily available for over 10 years,

### 34 https://elinux.org/Mikrobus 35 http://www.ti.com/product/CC1352R 36 https://en.wikipedia.org/wiki/Over-the-air_programming 37 https://www.oshwa.org/definition/ 38 https://en.wikipedia.org/wiki/Open-source_software

Full customization possible

- Built with fully open source software with submissions to mainline Linux and Zephyr repositories to aide in support and porting,
- Built with fully open source and non-restrictive hardware design including schematic, bill-of-materials, layout, and manufacturing files (with only the BeagleBoard.org logo removed due to licensing restrictions of our brand),
- Built with parts where at least a compatible part is available from worldwide distributors in any quantity,
- Built with design and manufacturing partners able to help scale derivative designs,
- Based on a security model using public/private keypairs that can be replaced to secure your own network, and
- Fully FCC/CE certified.

2

# BeagleConnect™ Usage

This section describes the usage model we are developing. To use the current code in development, please refer to the Section 3.1, “Develop for BeagleConnect™ Freedom with Zephyr” section below.

### 2.1. BeagleConnect™ wireless user experience

### 2.1.1. Enable a Linux host with BeagleConnect™

Log into a host system running Linux that is BeagleConnect™ enabled. Enable a Linux host with BeagleConnect™ by plugging a BeagleConnect™ gateway device into it’s USB port. You’ll also want to have a BeagleConnect™ node device with a sensor, actuator or indicator device connected.

BeagleConnect™ Freedom can act as either a
BeagleConnect™ gateway device or a BeagleConnect™ node device.

The Linux host will need to run the BeagleConnect™ management software, most of which is incorporated into the Linux kernel. Support will be provided for BeagleBoard and BeagleBone boards, x86 hosts, and Raspberry Pi.

TODO: Clean up images

### 2.2. Connect host and device

Initiate a connection between the host and devices by pressing the discovery button(s).

Device data shows up as files

### 2.3. Device data shows up as files

New streams of self-describing data show up on the host system using native device drivers.

High-level applications, like Node-RED, can directly read/write these high-level data streams (including data-type information) to Internet-based MQTT¹ (https://mqtt.org/) brokers,
live dashboards, or other logical operations without requiring any sensor-specific coding. Business logic can be applied using simple if-this-then-that style operations or be made as complex as desired using virtually any programming language or environment.

TODO: Actually, Node-RED will make these show up automatically as streams.

### 2.4. Components

BeagleConnect™ enabled host Linux computer, possibly single-board computer
(SBC), with BeagleConnect™ | management | software and BeagleConnect™
gateway function. BeagleConnect™ gateway function can be provided by a BeagleConnect™ compatible interface or by connecting a BeagleConnect™ gateway device over USB.

If the Linux host has BLE, the BeagleConnect™ is optional for short distances

BeagleConnect™ Freedom Board, case, and wireless MCU with Zephyr based firmware for acting as either a BeagleConnect™ gateway device or
BeagleConnect™ node device. * In BeagleConnect™ gateway device mode:
Provides long-range, low-power wireless communications, Connects with the host via USB and an associated Linux kernel driver, and Is powered by the
USB connector. * In BeagleConnect™ node device mode: Powered by a battery
or USB connector Provides 2 mikroBUS connectors for connecting any of hundreds of Click Board² (https://bbb.io/click)
mikroBUS add-on devices Provides new Linux host controllers for SPI, I2C, UART, PWM, ADC, and GPIO with interrupts via Greybus

1
https://mqtt.org/
2
https://bbb.io/click

What’s different

BeagleConnect™ gateway device
Provides a BeagleConnect™ compatible interface to a host. This could
be a built-in interface device or one connected over USB. BeagleConnect™ Freedom can provide this function.

BeagleConnect™ node device
Utilizes a BeagleConnect™ compatible interface and TODO

BeagleConnect™ compatible interface
Immediate plans are to support Bluetooth Low Energy (BLE), 2.4GHz IEEE 802.15.4, and Sub-GHz IEEE 802.15.4 wireless interfaces. A built-in BLE interface is suitable for this at short range, whereas IEEE 802.15.4 is typically significantly better at long ranges. Other wired interfaces, such as CAN and RS-485, are being considered for future BeagleConnect™ gateway device
and BeagleConnect™ node device designs.

Greybus
TODO

#TODO: Find a place for the following notes:

- The device interfaces get exposed to the host via Greybus BRIDGED_PHY protocol
- The I2C bus is probed for a an identifier EEPROM and appropriate device drivers are loaded on the host
- Unsupported Click Boards connected are exposed via userspace drivers on the host for development

### 2.5. What’s different

So, in summary, what is so different with this approach?

- No microcontroller code development is required by users
- Userspace drivers make rapid prototyping really easy
- Kernel drivers makes the support code collaborative parts of the Linux kernel, rather than cut-and-paste

3

# BeagleConnect™ Freedom & Zephyr

### 3.1. Develop for BeagleConnect™ Freedom with Zephyr

Developing directly in Zephyr will not be ultimately required for end-users who won’t touch the firmware running on BeagleConnect™ Freedom and will instead use the BeagleConnect™ Greybus functionality, but is important for early adopters as well as people looking to extend the functionality of the open source design. If you are one of those people, this is a good place to get started.

### 3.1.1. Equipment to begin development

There are many options, but let’s get started with one recommended set for the beta users.

### 3.2. Required

- Section 1.2.2, “BeagleConnect™ Freedom beta kit”
- Seeed Studio BeagleBone® Green Gateway¹ (https://wiki.seeedstudio.com/BeagleBone-Green-Gateway/)
- 3x BeagleConnect™ Freedom board, antenna, U.FL to SMA cable, SMA antenna and USB Type-A to Type-C cable
- 1x MikroE² (https://www.mikroe.com/click)
ID Click
- microSD card (6GB or larger)
- microSD card programmer

1
https://wiki.seeedstudio.com/BeagleBone-Green-Gateway/2
https://www.mikroe.com/click

Recommended

### 3.3. Recommended

- 12V power brick³ (https://smile.amazon.com/TMEZON-Power-Adapter-Supply-2-1mm/dp/B00Q2E5IXW)
- USB to TTL 3.3V UART adapter (https://smile.amazon.com/Converter-Terminated-Galileo-BeagleBone-Minnowboard/dp/B06ZYPLFNB)

4
- Ethernet cable and Internet connection
- 2x USB power adapters
- BME280-based Weather Click (https://www.mikroe.com/weather-click)

5
- iAQ-Core-based Air Quality 2 Click⁶ (https://www.mikroe.com/air-quality-2-click)

### 3.4. Optional

- x86_64 computer running Ubuntu 20.04.3 LTS

### 3.5. Install the latest software image for BeagleBone Green Gateway

Download and install the Debian Linux operating system image for the Seeed BeagleBone® Green Gateway host.

1. Download the special mikroBUS/Greybus BeagleBoard.org Debian image from here⁷ (https://rcn-ee.net/rootfs/debian-mikrobus-armhf/)
. Pick the most recent directory and select the file beginning with bone- and ending with .img.xz. Today that file is bone-debian-11.2-iot-mikrobus-armhf-2022-03-04-4gb.img.xz.
2. Load this image to a microSD card using a tool like Etcher⁸ (https://www.balena.io/etcher/)
3. Insert the microSD card into the Green Gateway.
4. Power BeagleBone Green Gateway via the 12V barrel jack.

#TODO: describe how to know it is working

3
https://smile.amazon.com/TMEZON-Power-Adapter-Supply-2-1mm/dp/B00Q2E5IXW 4
https://smile.amazon.com/Converter-Terminated-Galileo-BeagleBone-Minnowboard/dp/B06ZYPLFNB (https://smile.amazon.com/Converter-Terminated-Galileo-BeagleBone-Minnowboard/dp/B06ZYPLFNB)
5
https://www.mikroe.com/weather-click
6
https://www.mikroe.com/air-quality-2-click
7
https://rcn-ee.net/rootfs/debian-mikrobus-armhf/8
https://www.balena.io/etcher/

Log into BeagleBone Green Gateway

### 3.6. Log into BeagleBone Green Gateway

These instructions assume an x86_64 computer runing Ubuntu 20.04.3 LTS, but any computer can be used to connect to your BeagleBone Green Gateway.

1. Log onto the Seeed BeagleBone® Green Gateway using ssh.
- We need IP address, Username, and Password to connect to the device.
- The default IP for the BeagleBone hardware is 192.168.7.2
- The default Username is debian & Password is temppwd
- To connect you can simply type $ ssh debian@192.168.7.2 and when asked for password just type temppwd.
- Congratulations, You are now connected to the device!
2. Connect to the WiFi⁹ (https://forum.beagleboard.org/t/debian-11-x-bullseye-monthly-snapshots/31280)
- Execute sudo nano /etc/wpa_supplicant/wpa_supplicant-wlan0.conf
and provide the password temppwd to edit the configuration file for the WiFi connection.
- Now edit the the file (shown below) under the network={ … } section you can set you ssid (WiFi name) and psk (Wifi Password).

ctrl_interface=DIR=/run/wpa_supplicant GROUP=netdev update_config=1
#country=IN

network={
ssid="WiFi Name"
psk="WiFi Password"
}
- Now save the file with CTRL+O and exit with CTRL+X.
- Check if the connection is established by executing $ ping 8.8.8.8 you should see something like shown below.

debian@BeagleBone:~$ ping 8.8.8.8
PING 8.8.8.8 (8.8.8.8) 56(84) bytes of data.
64 bytes from 8.8.8.8: icmp_seq=1 ttl=118 time=10.5 ms

9
https://forum.beagleboard.org/t/debian-11-x-bullseye-monthly-snapshots/31280

Install Zephyr development tools on BeagleBone Green Gateway 64 bytes from 8.8.8.8: icmp_seq=2 ttl=118 time=5.72 ms 64 bytes from 8.8.8.8: icmp_seq=3 ttl=118 time=6.13 ms
64 bytes from 8.8.8.8: icmp_seq=4 ttl=118 time=6.11 ms
- If everything goes well, you are ready to update your system and install new applications for beagleconnect.

If you are facing some issue during boot then you can try debuging the boot session with a USB to serial interface cable such as those made by FTDI¹⁰ (https://www.digikey.com/short/cfjmdbdd) plugged into J10 with the black wire of the FTDI cable toward the Ethernet connector. Application like tio/mimicom/putty can be used to make the connection estibleshment procedure easy.

TODO: Simplify and elaborate on this section, add boot session debugging walkthrough

### 3.7. Install Zephyr development tools on BeagleBone Green Gateway

Update the system.

sudo apt update
Install all BeagleConnect™ management software.

sudo apt install -y \
beagleconnect beagleconnect-msp430 \
git vim \
build-essential \
cmake ninja-build gperf \
ccache dfu-util device-tree-compiler \
make gcc libsdl2-dev \
libxml2-dev libxslt-dev libssl-dev libjpeg62-turbo-dev \ gcc-arm-none-eabi libnewlib-arm-none-eabi \
libtool-bin pkg-config autoconf automake libusb-1.0-0-dev \ python3-dev python3-pip python3-setuptools python3-tk python3-wheel

### 10 https://www.digikey.com/short/cfjmdbdd

Install Zephyr development tools on BeagleBone Green Gateway

echo "export PATH=$PATH:$HOME/.local/bin" >> $HOME/.bashrc

source $HOME/.bashrc
Reboot

sudo reboot
Install BeagleConnect™ flashing software

pip3 install -U west
Reboot

sudo reboot
Download and setup Zephyr for BeagleConnect™

cd

west init -m https://github.com/jadonk/zephyr --mr bcf-sdk-0.0.5 bcf-zephyr

cd $HOME/bcf-zephyr

west update

west zephyr-export

pip3 install -r zephyr/scripts/requirements-base.txt

echo "export CROSS_COMPILE=/usr/bin/arm-none-eabi-" >> $HOME/.bashrc

echo "export ZEPHYR_BASE=$HOME/bcf-zephyr/zephyr" >> $HOME/.bashrc

Build applications for BeagleConnect Freedom on BeagleBone Green Gateway

echo "export PATH=$HOME/bcf-zephyr/zephyr/scripts:$PATH" >> $HOME/.bashrc

echo "export BOARD=beagleconnect_freedom" >> $HOME/.bashrc

source $HOME/.bashrc

### 3.8. Build applications for BeagleConnect Freedom on BeagleBone Green Gateway

Now you can build various Zephyr applications

Change directory to BeagleConnect Freedom zephyr repository.

cd $HOME/bcf-zephyr
Build blinky example

west build -d build/blinky zephyr/samples/basic/blinky
TODO

west build -d build/sensortest zephyr/samples/boards/beagle_bcf/ sensortest -- -DOVERLAY_CONFIG=overlay-subghz.conf
TODO

west build -d build/wpanusb modules/lib/wpanusb_bc -- -DOVERLAY_CONFIG=overlay-subghz.conf
TODO

west build -d build/bcfserial modules/lib/wpanusb_bc -- -DOVERLAY_CONFIG=overlay-bcfserial.conf -DDTC_OVERLAY_FILE=bcfserial.overlay
TODO

Flash applications to BeagleConnect Freedom from BeagleBone Green Gateway

west build -d build/greybus modules/lib/greybus/samples/subsys/ greybus/net -- -DOVERLAY_CONFIG=overlay-802154-subg.conf

### 3.9. Flash applications to BeagleConnect Freedom from BeagleBone Green Gateway

And then you can flash the BeagleConnect Freedom boards over USB

Make sure you are in Zephyr directory

cd $HOME/bcf-zephyr
Flash Blinky

cc2538-bsl.py build/blinky

### 3.10. Debug applications over the serial terminal

#TODO

4

# BeagleConnect™ greybus stack

### 4.1. Work in progress

To understand a bit more about how the BeagleConnect™ Greybus stack is being built, this section helps describe the development currently in progress and the principles of operation.

### 4.1.1. Background

BeagleConnect™ uses Greybus and updated Click Boards with identifiers to eliminate the need to add and manually configure devices added onto the Linux system.

### 4.1.2. High-level

- For Linux nerds: Think of BeagleConnect™ as 6LoWPAN (https://en.wikipedia.org/wiki/6LoWPAN)

1

over 802.15.4² (https://en.wikipedia.org/wiki/IEEE_802.15.4)
based Greybus³ (https://kernel-recipes.org/en/2015/talks/an-introduction-to-greybus/)
(instead of Unipro as used by Project Ara), where every BeagleConnect™ board shows up as new SPI, I2C, UART, PWM, ADC, and GPIO controllers that can now be probed to load drivers for the sensors or whatever is connected to them. (Proof of concept of Greybus over TCP/IP: https://www.youtube.com/watch?v=7H50pv-4YXw)
- For MCU folks: Think of BeagleConnect™ as a Firmata⁴ (https://github.com/firmata/protocol)
-style firmware load
that exposes the interfaces for remote access over a secured wireless network.

1
https://en.wikipedia.org/wiki/6LoWPAN
2
https://en.wikipedia.org/wiki/IEEE_802.15.4
3
https://kernel-recipes.org/en/2015/talks/an-introduction-to-greybus/4
https://github.com/firmata/protocol

Software architecture

However, instead of using host software that knows how to speak the Firmata protocol, the Linux kernel speaks the slightly similar Greybus protocol to the MCU and exposes the device generically to users using a Linux kernel driver. Further, the Greybus protocol is spoken over 6LoWPAN (https://en.wikipedia.org/wiki/6LoWPAN)

5

on 802.15.4⁶ (https://en.wikipedia.org/wiki/IEEE_802.15.4)

### 4.2. Software architecture

### 4.3. TODO items

- Linux kernel driver
- Provisioning
- Firmware for host CC13x
- Firmware for device CC13x
- Click Board drivers and device tree formatted metadata for 100 or so Click Boards
- Click Board plug-ins for node-red for the same 100 or so Click Boards
- BeagleConnect™ Freedom System Reference Manual and FAQs

### 4.4. Associated pre-work

- Click Board support for Node-RED can be executed with native connections on PocketBeagle+TechLab and BeagleBone Black with mikroBUS Cape
- Device tree fragments and driver updates can be provided via https://bbb.io/click (https://bbb.io/click)
- The Kconfig style provisioning can be implemented for those solutions, which will require a reboot. We need to centralize edits to /boot/uEnv.txt to be programmatic. As I think through this, I don’t think BeagleConnect is impacted, because the Greybus-style discovery along with Click EEPROMS will eliminate any need to edit /boot/uEnv.txt.

### 4.5. User experience concerns

- Make sure no reboots are required

5
https://en.wikipedia.org/wiki/6LoWPAN
6
https://en.wikipedia.org/wiki/IEEE_802.15.4

BeagleConnect™ Greybus demo using BeagleConnect™ Freedom
- Plugging BeagleConnect into host should trigger host configuration
- Click EEPROMs should trigger loading whatever drivers are needed and provisioning should load any new drivers
- Userspace (spidev, etc.) drivers should unload cleanly when 2nd phase provisioning is completed

### 4.6. BeagleConnect™ Greybus demo using BeagleConnect™ Freedom

BeagleConnect™ Freedom runs a subGHz IEEE 802.15.4 network. This BeagleConnect™ Greybus demo shows how to interact with GPIO, I2C and mikroBUS add-on boards remotely connected over a BeagleConnect™ Freedom. This section starts with the steps required to use Linux⁷ (https://en.wikipedia.org/wiki/Linux)
embedded computer
(BeagleBone Green Gateway⁸ (https://wiki.seeedstudio.com/BeagleBone-Green-Gateway/)

) and the Greybus⁹ (https://lwn.net/Articles/715955/)
protocol, over an IEEE
802.15.4 wireless link, to blink an LED on a Zephyr¹⁰ (https://zephyrproject.org) device.

### 4.7. Introduction

### 4.7.1. Why??

Good question. Blinking an LED is kind of the Hello, World (https://en.wikipedia.org/wiki/%22Hello,_World!%22_program)

11
of the hardware
community. In this case, we’re less interested in the mechanics of switching a GPIO to drive some current through an LED and more interested in how that happens with the Internet of Things (IoT)¹² (https://en.wikipedia.org/wiki/Internet_of_things)
There are several existing network and application layers that are driven by corporate heavyweights and industry consortiums, but relatively few that are community driven and, more specifically, even fewer that have the ability to integrate so tightly with the Linux kernel.
The goal here is to provide a community-maintained, developer-friendly, and open-source protocol for the Internet of Things using the Greybus Protocol, and

7
https://en.wikipedia.org/wiki/Linux
8
https://wiki.seeedstudio.com/BeagleBone-Green-Gateway/9
https://lwn.net/Articles/715955/

### 10 https://zephyrproject.org

11
https://en.wikipedia.org/wiki/%22Hello,_World!%22_program

### 12 https://en.wikipedia.org/wiki/Internet_of_things

Flash BeagleConnect™ Freedom node device with Greybus firmware
blinking an LED using Greybus is the simplest proof-of-concept for that. All that is required is a reliable transport.
1. Power a BeagleConnect Freedom that has not yet been programmed via a USB power source, not the BeagleBone Green Gateway. You’ll hear a click every 1-2 seconds along with seeing 4 of the LEDs turn off and on.
2. In an isolated terminal window, sudo beagleconnect-start-gateway
3. sensortest-rx.py

Every 1-2 minutes, you should see something like:

('fe80::3111:7a22:4b:1200%lowpan0', 52213, 0, 13) '2l:7.79;' ('fe80::3111:7a22:4b:1200%lowpan0', 52213, 0, 13) '4h:43.75;4t:23.11;'

The value after "2l:" is the amount of light in lux. The value after "4h:" is the relative humidity and after "4t:" is the temperature in Celcius.

### 4.8. Flash BeagleConnect™ Freedom node device with Greybus firmware

#TODO: How can we add a step in here to show the network is connected without needing gbridge to be fully functional?

Do this from the BeagleBone® Green Gateway board that was previously used to program the BeagleConnect™ Freedom gateway device:

1. Disconnect the BeagleConnect™ Freedom gateway device
2. Connect a new BeagleConnect™ Freedom board via USB
3. sudo systemctl stop lowpan.service
4. cc2538-bsl.py | /usr/share/beagleconnect/cc1352/
greybus_mikrobus_beagleconnect.bin /dev/ttyACM0 13
5. After it finishes programming successfully, disconnect the BeagleConnect Freedom node device
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

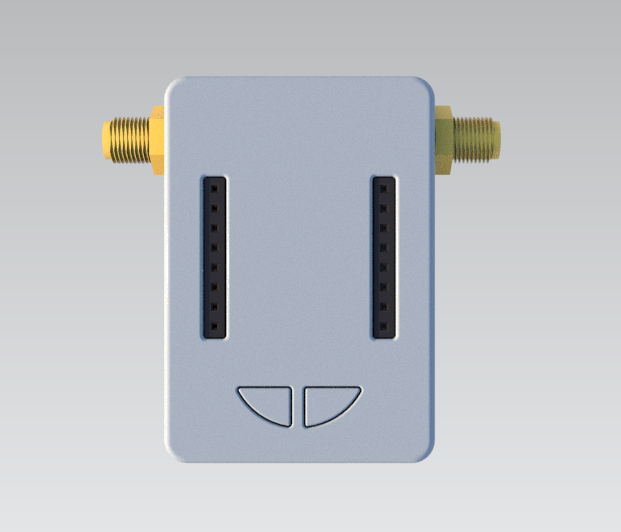
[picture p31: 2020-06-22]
case/Industrial design/BeagleConnect_ID_1.png

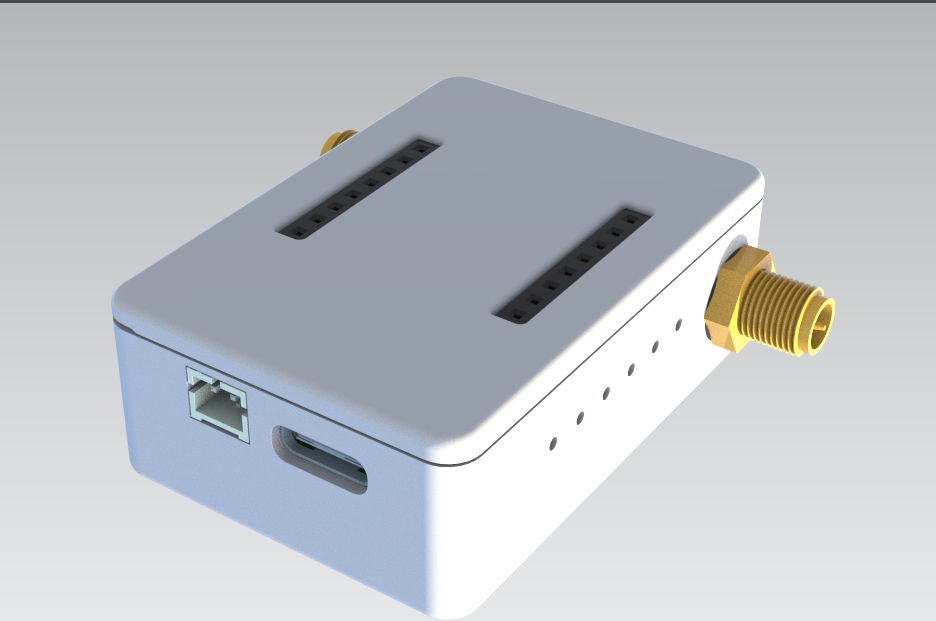
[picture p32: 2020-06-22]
case/Industrial design/BeagleConnect_ID_7.png

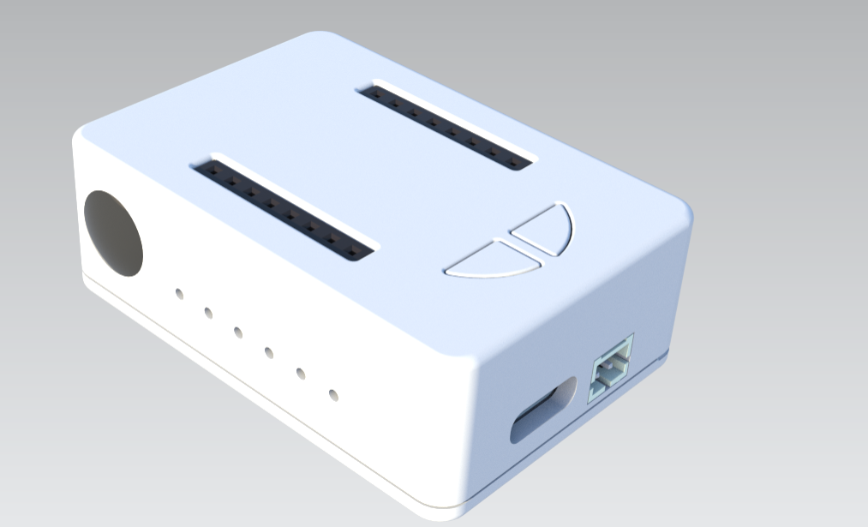
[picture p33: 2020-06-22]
case/Industrial design/BeagleConnect_ID_3.png

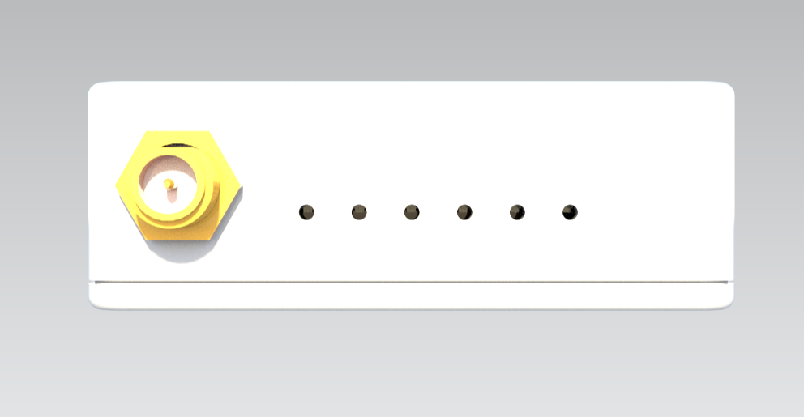
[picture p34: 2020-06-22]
case/Industrial design/BeagleConnect_ID_9.png

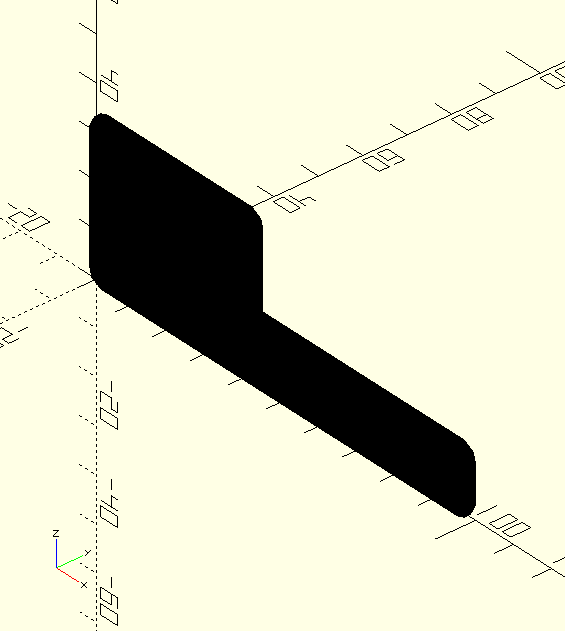
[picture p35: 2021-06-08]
case/Industrial design/backplate1.png

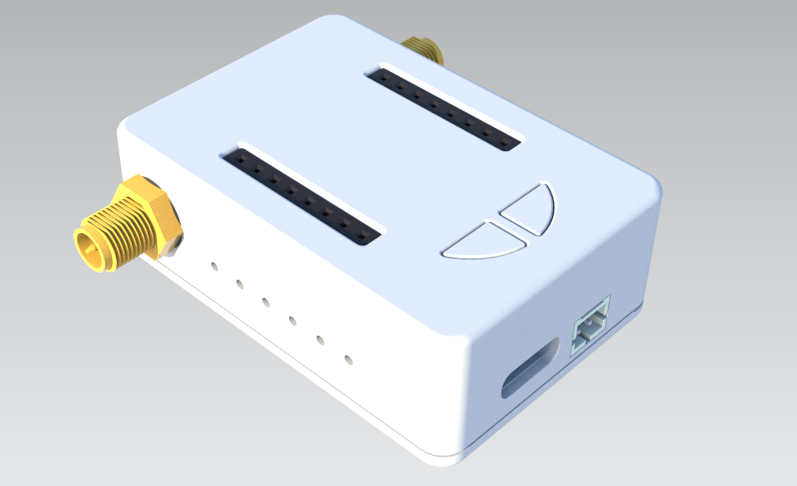
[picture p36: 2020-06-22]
case/Industrial design/BeagleConnect_ID_2.png

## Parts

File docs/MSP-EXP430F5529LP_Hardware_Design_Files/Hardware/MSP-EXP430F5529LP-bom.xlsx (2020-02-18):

BOM for MSP-EXP430F5529LP
Do not populate (Dnp) part if Quantity equals zero
Use exact PartNumber and Manufacturer if this data is provided
Feedback from ContractManufacturer (CM) needed where supplier equals CM
ezFET or EXP? | Qty | Reference | Manufacturer | Description | Part Number | PCB DECAL/Package | Value | Supplier1 | Digikey Number | Rev1.4 to Rev 1.5 Change
Box | 1 |  | CM | MicroUSB cable. Lierda to suggest part | tbd | Box | Micro USB cable | CM | to be provided by CM
ezFET | 1 | C101 | Standard | CAP CER 0.47UF 16V 10% X5R 0402,Digikey 445-4976-1-ND |  | C0402 | 470n | Digikey | 445-4976-1-ND
ezFET | 1 | C102 | Standard | CAP CER 0.22UF 16V 10% X5R 0402,Digikey 445-4972-1-ND |  | C0402 | 220n | Digikey | 445-4972-1-ND
ezFET | 1 | C103 | Standard | CAP CER 0.1UF 10V 20% X5R 0402,Digikey 445-4984-1-ND |  | C0402 | 100n | Digikey | 445-4984-1-ND
ezFET | 1 | C104 | Standard | CAP TANT 10UF 10V 20% 1206,Digikey 493-2351-1-ND |  | TANT_3216 | 10u | Digikey | 493-2351-1-ND
ezFET | 1 | C107 | Standard | CAP CER 0.22UF 16V 10% X5R 0402,Digikey 445-4972-1-ND |  | C0402 | 220n | Digikey | 445-4972-1-ND
ezFET | 1 | C110 | Standard | CAP CER 10PF 50V NP0 0402,Digikey 445-1235-1-ND |  | C0402 | 10p | Digikey | 445-1235-1-ND
ezFET | 1 | C111 | Standard | CAP CER 10PF 50V NP0 0402,Digikey 445-1235-1-ND |  | C0402 | 10p | Digikey | 445-1235-1-ND
ezFET | 1 | C112 | Standard | CAP CER 1000PF 50V 10% X7R 0402,Digikey 445-1256-1-ND |  | C0402 | 1n | Digikey | 445-1256-1-ND
ezFET | 1 | C113 | Standard | CAP CER 0.1UF 10V 20% X5R 0402,Digikey 445-4984-1-ND |  | C0402 | 100n | Digikey | 445-4984-1-ND
ezFET | 1 | C121 | Standard | CAP CER 0.1UF 10V 20% X5R 0402,Digikey 445-4984-1-ND |  | C0402 | 100n | Digikey | 445-4984-1-ND
ezFET | 1 | C122 | Standard | CAP CER 33PF 50V 5% NP0 0402,Digikey 445-1241-1-ND |  | C0402 | 33p | Digikey | 445-1241-1-ND
ezFET | 1 | C123 | Standard | CAP CER 33PF 50V 5% NP0 0402,Digikey 445-1241-1-ND |  | C0402 | 33p | Digikey | 445-1241-1-ND
LP | 1 | C14 | Standard | CAP CER 0.1UF 10V 20% X5R 0402,Digikey 445-4984-1-ND |  | C0402 | 100n | Digikey | 445-4984-1-ND
LP | 1 | C15 | Standard | CAP CER 0.22UF 16V 10% X5R 0402,Digikey 445-4972-1-ND |  | C0402 | 220n | Digikey | 445-4972-1-ND
LP | 1 | C16 | Standard | CAP CER 0.22UF 16V 10% X5R 0402,Digikey 445-4972-1-ND |  | C0402 | 220n | Digikey | 445-4972-1-ND
LP | 1 | C17 | Standard | CAP CER 1000PF 50V 10% X7R 0402,Digikey 445-1256-1-ND |  | C0402 | 1n | Digikey | 445-1256-1-ND
LP | 1 | C18 | Standard | CAP CER 0.47UF 16V 10% X5R 0402,Digikey 445-4976-1-ND |  | C0402 | 470n | Digikey | 445-4976-1-ND
LP | 1 | C19 | Standard | CAP CER 0.1UF 10V 20% X5R 0402,Digikey 445-4984-1-ND |  | C0402 | 100n | Digikey | 445-4984-1-ND
LP | 1 | C20 | Standard | CAP CER 0.1UF 10V 20% X5R 0402,Digikey 445-4984-1-ND |  | C0402 | 100n | Digikey | 445-4984-1-ND
LP | 1 | C21 | Standard | CAP CER 0.1UF 10V 20% X5R 0402,Digikey 445-4984-1-ND |  | C0402 | 100n | Digikey | 445-4984-1-ND
LP | 1 | C23 | Standard | CAP CER 10PF 50V 5%NP0 0402,Digikey 445-1235-1-ND |  | C0402 | 10p | Digikey | 445-1235-1-ND
LP | 1 | C24 | Standard | CAP CER 10PF 50V 5% NP0 0402,Digikey 445-1235-1-ND |  | C0402 | 10p | Digikey | 445-1235-1-ND
LP | 1 | C25 | Standard | CAP CER 12PF 50V 5% NP0 0402,Digikey 445-1236-1-ND |  | C0402 | 12p | Digikey | 445-1236-1-ND
LP | 1 | C26 | Standard | CAP CER 12PF 50V 5% NP0 0402,Digikey 445-1236-1-ND |  | C0402 | 12p | Digikey | 445-1236-1-ND
LP | 1 | C27 | Standard | CAP TANT 4.7UF 10V 10% 1206,Digikey 493-4142-1-ND |  | A/3216-18R | 4u7 | Digikey | 493-4142-1-ND
LP | 1 | C28 | Standard | CAP CER 0.1UF 10V 20% X5R 0402,Digikey 445-4984-1-ND |  | C0402 | 100n | Digikey | 445-4984-1-ND
LP | 1 | C29 | Standard | CAP CER 0.1UF 10V 20% X5R 0402,Digikey 445-4984-1-ND |  | C0402 | 100n | Digikey | 445-4984-1-ND
LP | 1 | C30 | Standard | CAP TANT 10UF 10V 20% 1206,Digikey 493-2351-1-ND |  | TANT_3216 | 10u | Digikey | 493-2351-1-ND
LP | 1 | C31 | Standard | CAP CER 0.1UF 10V 20% X5R 0402,Digikey 445-4984-1-ND |  | C0402 | 100n | Digikey | 445-4984-1-ND
Hub | 1 | C401 | Standard | CAP CER 1UF 10V 10% X7R 0805,Digikey 587-1284-2-ND |  | CSMD0805 | 1u | Digikey | 587-1284-2-ND
Hub | 1 | C402 | Standard | CAP CER 0.1UF 10V 20% X5R 0402,Digikey 445-4984-1-ND |  | C0402 | 100n | Digikey | 445-4984-1-ND
Hub | 1 | C403 | Standard | CAP TANT 4.7UF 10V 10% 1206,Digikey 493-4142-1-ND |  | A/3216-18R | 4u7 | Digikey | 493-4142-1-ND
Hub | 1 | C404 | Standard | CAP CER 1UF 10V 10% X7R 0805,Digikey 587-1284-2-ND |  | CSMD0805 | 1u | Digikey | 587-1284-2-ND
Hub | 1 | C405 | Standard | CAP CER 22PF 50V 5% NP0 0402,Digikey 445-1239-1-ND |  | C0402 | 22p | Digikey | 445-1239-1-ND
Hub | 1 | C406 | Standard | CAP CER 22PF 50V 5% NP0 0402,Digikey 445-1239-1-ND |  | C0402 | 22p | Digikey | 445-1239-1-ND
Hub | 1 | C407 | Standard | CAP CER 0.1UF 10V 20% X5R 0402,Digikey 445-4984-1-ND |  | C0402 | 100n | Digikey | 445-4984-1-ND
Hub | 1 | C408 | Standard | CAP CER 0.1UF 10V 20% X5R 0402,Digikey 445-4984-1-ND |  | C0402 | 100n | Digikey | 445-4984-1-ND
Hub | 1 | C409 | Standard | CAP CER 22PF 50V 5% NP0 0402,Digikey 445-1239-1-ND |  | C0402 | 22p | Digikey | 445-1239-1-ND
Hub | 1 | C410 | Standard | CAP CER 22PF 50V 5% NP0 0402,Digikey 445-1239-1-ND |  | C0402 | 22p | Digikey | 445-1239-1-ND
Hub | 1 | C411 | Standard | CAP CER 22PF 50V 5% NP0 0402,Digikey 445-1239-1-ND |  | C0402 | 22p | Digikey | 445-1239-1-ND
Hub | 1 | C412 | Standard | CAP CER 22PF 50V 5% NP0 0402,Digikey 445-1239-1-ND |  | C0402 | 22p | Digikey | 445-1239-1-ND
Hub | 1 | IC401 | TI | IC 4-PORT HUB FOR USB 32-QFN,Digikey 296-21926-1-ND | TUSB2046BIRHBR | RHB_S-PQFP-N32 | TUSB2046BIRHBIRHB | Digikey | 296-21926-1-ND
LP | 1 | J1 | CM | CONN HEADER 20POS .100" DUAL, FEMALE with long male leads | CNT-F254-2*10-GS-850-9 | 2X10 |  | CM | to be provided by CM | Updated part # for stronger male leads
LP | 1 | J10 | Standard | CONN HEADER 3POS .100" SNGL TIN,Digikey SAM1075-03-ND |  | 1X03 | PWR | Digikey | SAM1075-03-ND
LP | 1 | J3 | Standard | CONN HEADER 3POS .100" SNGL TIN,Digikey SAM1075-03-ND |  | 1X03 | PWR | Digikey | SAM1075-03-ND
Hub | 1 | J401 | Standard | CONN RCPT MICRO USB B SMD R/A, Digikey H11574CT-ND |  | CONN_USB-MICRO-B-SMT_R | ZX62R-B-5P | Digikey | H11574CT-ND
LP | 1 | J5 | CM | CONN HEADER 20POS .100" DUAL, FEMALE with long male leads | CNT-F254-2*10-GS-850-9 | 2X10 |  | CM | to be provided by CM | Updated part # for stronger male leads
LP | 1 | JP1 | Standard | CONN HEADER 2POS .100" SNGL TIN,Digikey SAM1075-02-ND |  | JP1M | +5V | Digikey | SAM1075-02-ND
LP | 1 | JP2 | Standard | CONN HEADER 2POS .100" SNGL TIN,Digikey SAM1075-02-ND |  | JP1M | +3V3 | Digikey | SAM1075-02-ND
LP | 1 | JP3 | Standard | CONN HEADER 2POS .100" SNGL TIN,Digikey SAM1075-02-ND |  | JP1M | GND | Digikey | SAM1075-02-ND
LP | 1 | JP4.1 | Standard | CONN HEADER 2POS .100" SNGL TIN,Digikey SAM1075-02-ND |  | JP1M | SBWTCK | Digikey | SAM1075-02-ND
LP | 1 | JP4.2 | Standard | CONN HEADER 2POS .100" SNGL TIN,Digikey SAM1075-02-ND |  | JP1M | SBWTDIO | Digikey | SAM1075-02-ND
LP | 0 | JP4.3 | Standard | CONN HEADER 2POS .100" SNGL TIN,Digikey SAM1075-02-ND |  | JP1M | SBWDAT (dnp) | Digikey | SAM1075-02-ND
LP | 1 | JP6.1 | Standard | CONN HEADER 2POS .100" SNGL TIN,Digikey SAM1075-02-ND |  | JP1M | TXD | Digikey | SAM1075-02-ND
LP | 1 | JP6.2 | Standard | CONN HEADER 2POS .100" SNGL TIN,Digikey SAM1075-02-ND |  | JP1M | RXD | Digikey | SAM1075-02-ND
LP | 1 | JP6.3 | Standard | CONN HEADER 2POS .100" SNGL TIN,Digikey SAM1075-02-ND |  | JP1M | CTS | Digikey | SAM1075-02-ND
LP | 1 | JP6.4 | Standard | CONN HEADER 2POS .100" SNGL TIN,Digikey SAM1075-02-ND |  | JP1M | RTS | Digikey | SAM1075-02-ND
LP | 1 | JP8 | Standard | CONN HEADER 2POS .100" SNGL TIN,Digikey SAM1075-02-ND |  | JP1 | LED1_PWR | Digikey | SAM1075-02-ND
Hub | 1 | L401 | Taiyo Yuden | INDUCTOR 2.2UH 20% SMD,Digikey 587-1638-1-ND | NR3010T2R2M | L-NR3010 | 2.2uH (NR3010T2R2M) | Digikey | 587-1638-1-ND
LP | 1 | LED1 | Standard | LED RED CLEAR 0603 SMD,Digikey 160-1181-1-ND |  | CHIPLED_0603 |  | Digikey | 160-1181-1-ND
ezFET | 1 | LED101 | Standard | LED RED CLEAR 0603 SMD,Digikey 160-1181-1-ND |  | LED603 | Red | Digikey | 160-1181-1-ND
ezFET | 1 | LED102 | Standard | LED GREEN CLEAR 0603 SMD,Digikey 160-1183-1-ND |  | LED603 | Green | Digikey | 160-1183-1-ND
LP | 1 | LED2 | Standard | LED GREEN CLEAR 0603 SMD,Digikey 160-1183-1-ND |  | CHIPLED_0603 |  | Digikey | 160-1183-1-ND
ezFET | 1 | MSP101 | TI | IC MCU 16BIT 128KB FLASH 64VQFN,Digikey 296-27400-1-ND | MSP430F5528IRGC | RGC-64 | MSP430F5528IRGC | Digikey | 296-27400-1-ND
ezFET | 1 | Q101 | Murata | CER RESONATOR 4.00MHZ SMD | CSTCR4M00G15L99 | PIEZO-2X4.5MM | PIEZO_CSTCR4M00G15L99 | Murata | #VALUE!
LP | 1 | Q2 | Microcrystal | MS3V-T1R 32.768kHz CL 12pF +-20ppm, Microcrystal | MS3V-T1R | MS3V-T1R | 32.768kHz Microcrystal | Microcrystal | #VALUE!
LP | 1 | Q4 | Murata | CER RESONATOR 4.00MHZ SMD | CSTCR4M00G15L99 | PIEZO-2X4.5MM | PIEZO_CSTCR4M00G15L99 | Murata | #VALUE!
Hub | 1 | Q401 | Murata | CER RESONATOR 6.00MHZ SMD | CSTCR6M00G15L99 | PIEZO-2X4.5MM | PIEZO_CSTCR6M00G15L99 | Murata | #VALUE!
ezFET | 1 | R101 | Standard | RES 470 OHM 1/16W 1% 0402 SMD,Digikey 311-470LRCT-ND |  | R0402 | 470 | Digikey | 311-470LRCT-ND
ezFET | 1 | R102 | Standard | RES 390 OHM 1/16W 1% 0402 SMD,Digikey 311-390LRCT-ND |  | R0402 | 390 | Digikey | 311-390LRCT-ND
ezFET | 1 | R103 | Standard | RES 27 OHM 1/16W 5% 0402 SMD,Digikey 311-27JRCT-ND |  | R0402 | 27 | Digikey | 311-27JRCT-ND
ezFET | 1 | R104 | Standard | RES 27 OHM 1/16W 5% 0402 SMD,Digikey 311-27JRCT-ND |  | R0402 | 27 | Digikey | 311-27JRCT-ND
ezFET | 1 | R105 | Standard | RES 1.33K OHM 1/16W 1% 0402 SMD,Digikey 311-1.33KLRCT-ND |  | R0402 | 1k4 | Digikey | 311-1.33KLRCT-ND
ezFET | 1 | R106 | Standard | RES 1.00M OHM 1/16W 1% 0402 SMD,Digikey 311-1.00MLRCT-ND |  | R0402 | 1M | Digikey | 311-1.00MLRCT-ND
ezFET | 1 | R109 | Standard | RES 47.0K OHM 1/16W 1% 0402 SMD,Digikey 311-47.0KLRCT-ND |  | R0402 | 47k | Digikey | 311-47.0KLRCT-ND
ezFET | 1 | R121 | Standard | RES 220K OHM 1/16W 1% 0402 SMD,Digikey 311-220KLRCT-ND |  | R0402 | 220k | Digikey | 311-220KLRCT-ND
ezFET | 1 | R122 | Standard | RES 220K OHM 1/16W 1% 0402 SMD,Digikey 311-220KLRCT-ND |  | R0402 | 220k | Digikey | 311-220KLRCT-ND
ezFET | 1 | R124 | Standard | RES 240K OHM 1/16W 1% 0402 SMD,Digikey 311-240KLRCT-ND |  | R0402 | 240k | Digikey | 311-240KLRCT-ND
ezFET | 1 | R125 | Standard | RES 150K OHM 1/16W 1% 0402 SMD,Digikey 311-150KLRCT-ND |  | R0402 | 150k | Digikey | 311-150KLRCT-ND
LP | 1 | R14 | Standard | RES 100 OHM 1/16W 1% 0402 SMD,Digikey 311-100LRCT-ND |  | R0402 | 100R | Digikey | 311-100LRCT-ND
LP | 1 | R15 | Standard | RES 1.33K OHM 1/16W 1% 0402 SMD,Digikey 311-1.33KLRCT-ND |  | R0402 | 1k4 | Digikey | 311-1.33KLRCT-ND
LP | 1 | R16 | Standard | RES 1.00M OHM 1/16W 1% 0402 SMD,Digikey 311-1.00MLRCT-ND |  | R0402 | 1M | Digikey | 311-1.00MLRCT-ND
LP | 1 | R27 | Standard | RES 47.0K OHM 1/16W 1% 0402 SMD,Digikey 311-47.0KLRCT-ND |  | R0402 | 47k | Digikey | 311-47.0KLRCT-ND
LP | 1 | R28 | Standard | RES 0.0 OHM 1/16W 0402 SMD,Digikey 311-0.0JRTR-ND |  | R0402 | 0R | Digikey | 311-0.0JRTR-ND
LP | 1 | R29 | Standard | RES 470 OHM 1/16W 1% 0402 SMD,Digikey 311-470LRCT-ND |  | R0402 | 470R | Digikey | 311-470LRCT-ND
LP | 1 | R30 | Standard | RES 470 OHM 1/16W 1% 0402 SMD,Digikey 311-470LRCT-ND |  | R0402 | 470R | Digikey | 311-470LRCT-ND
LP | 1 | R31 | Standard | RES 27 OHM 1/16W 5% 0402 SMD,Digikey 311-27JRCT-ND |  | R0402 | 27R | Digikey | 311-27JRCT-ND
LP | 1 | R32 | Standard | RES 27 OHM 1/16W 5% 0402 SMD,Digikey 311-27JRCT-ND |  | R0402 | 27R | Digikey | 311-27JRCT-ND
Hub | 1 | R401 | Standard | RES 33 OHM 1/16W 5% 0402 SMD,Digikey 311-33JRCT-ND |  | R0402 | 33R | Digikey | 311-33JRCT-ND
Hub | 1 | R402 | Standard | RES 10.0K OHM 1/16W 1% 0402 SMD,Digikey 311-10.0KLRCT-ND |  | R0402 | 10k | Digikey | 311-10.0KLRCT-ND
Hub | 1 | R403 | Standard | RES 1.50K OHM 1/16W 1% 0402 SMD,Digikey 311-1.50KLRCT-ND |  | R0402 | 1k5 | Digikey | 311-1.50KLRCT-ND
Hub | 1 | R404 | Standard | RES 47.0K OHM 1/16W 1% 0402 SMD,Digikey 311-47.0KLRCT-ND |  | R0402 | 47k | Digikey | 311-47.0KLRCT-ND
Hub | 1 | R405 | Standard | RES 22 OHM 1/16W 5% 0402 SMD,Digikey 311-22JRCT-ND |  | R0402 | 22R | Digikey | 311-22JRCT-ND
Hub | 1 | R406 | Standard | RES 22 OHM 1/16W 5% 0402 SMD,Digikey 311-22JRCT-ND |  | R0402 | 22R | Digikey | 311-22JRCT-ND
Hub | 1 | R407 | Standard | RES 1.50K OHM 1/16W 1% 0402 SMD,Digikey 311-1.50KLRCT-ND |  | R0402 | 1k5 | Digikey | 311-1.50KLRCT-ND
Hub | 1 | R408 | Standard | RES 15.0K OHM 1/16W 1% 0402 SMD,Digikey 311-15.0KLRCT-ND |  | R0402 | 15k | Digikey | 311-15.0KLRCT-ND
Hub | 1 | R409 | Standard | RES 15.0K OHM 1/16W 1% 0402 SMD,Digikey 311-15.0KLRCT-ND |  | R0402 | 15k | Digikey | 311-15.0KLRCT-ND
Hub | 1 | R410 | Standard | RES 22 OHM 1/16W 5% 0402 SMD,Digikey 311-22JRCT-ND |  | R0402 | 22R | Digikey | 311-22JRCT-ND
Hub | 1 | R411 | Standard | RES 22 OHM 1/16W 5% 0402 SMD,Digikey 311-22JRCT-ND |  | R0402 | 22R | Digikey | 311-22JRCT-ND
Hub | 1 | R412 | Standard | RES 15.0K OHM 1/16W 1% 0402 SMD,Digikey 311-15.0KLRCT-ND |  | R0402 | 15k | Digikey | 311-15.0KLRCT-ND
Hub | 1 | R413 | Standard | RES 15.0K OHM 1/16W 1% 0402 SMD,Digikey 311-15.0KLRCT-ND |  | R0402 | 15k | Digikey | 311-15.0KLRCT-ND
Hub | 1 | R414 | Standard | RES 15.0K OHM 1/16W 1% 0402 SMD,Digikey 311-15.0KLRCT-ND |  | R0402 | 15k | Digikey | 311-15.0KLRCT-ND
Hub | 1 | R415 | Standard | RES 15.0K OHM 1/16W 1% 0402 SMD,Digikey 311-15.0KLRCT-ND |  | R0402 | 15k | Digikey | 311-15.0KLRCT-ND
Hub | 1 | R416 | Standard | RES 22 OHM 1/16W 5% 0402 SMD,Digikey 311-22JRCT-ND |  | R0402 | 22R | Digikey | 311-22JRCT-ND
Hub | 1 | R417 | Standard | RES 22 OHM 1/16W 5% 0402 SMD,Digikey 311-22JRCT-ND |  | R0402 | 22R | Digikey | 311-22JRCT-ND
Hub | 1 | R418 | Standard | RES 15.0K OHM 1/16W 1% 0402 SMD,Digikey 311-15.0KLRCT-ND |  | R0402 | 15k | Digikey | 311-15.0KLRCT-ND
Hub | 1 | R419 | Standard | RES 15.0K OHM 1/16W 1% 0402 SMD,Digikey 311-15.0KLRCT-ND |  | R0402 | 15k | Digikey | 311-15.0KLRCT-ND
LP | 1 | S1 | Standard | SWITCH TACTILE SPST-NO 0.02A 15V,Digikey P8079STB-ND |  | PBTH | SPST | Digikey | P8079STB-ND
LP | 1 | S2 | Standard | SWITCH TACTILE SPST-NO 0.02A 15V,Digikey P8079STB-ND |  | PBTH | SPST | Digikey | P8079STB-ND
LP | 1 | S3 | Standard | SWITCH TACTILE SPST-NO 0.02A 15V,Digikey P8079STB-ND |  | PBTH | SPST | Digikey | P8079STB-ND
LP | 1 | S5 | Standard | SWITCH TACTILE SPST-NO 0.02A 15V,Digikey P8079STB-ND |  | PBTH | SPST | Digikey | P8079STB-ND
ezFET | 1 | TP104 | PCB | Test Point,O.038 Hole, Digikey nothing-to-purchase |  | TP | TP | Digikey | nothing-to-purchase
ezFET | 1 | TP105 | PCB | Test Point,O.038 Hole, Digikey nothing-to-purchase |  | TP | TP | Digikey | nothing-to-purchase
ezFET | 1 | TP106 | PCB | Test Point,O.038 Hole, Digikey nothing-to-purchase |  | TP | TP | Digikey | nothing-to-purchase
ezFET | 1 | TP107 | PCB | Test Point,O.038 Hole, Digikey nothing-to-purchase |  | TP | TP | Digikey | nothing-to-purchase
ezFET | 1 | TP108 | PCB | Test Point,O.038 Hole, Digikey nothing-to-purchase |  | TP | TP | Digikey | nothing-to-purchase
ezFET | 1 | TP109 | PCB | Test Point,O.038 Hole, Digikey nothing-to-purchase |  | TP | TP | Digikey | nothing-to-purchase
ezFET | 1 | TP110 | PCB | Test Point,O.038 Hole, Digikey nothing-to-purchase |  | TP | TP | Digikey | nothing-to-purchase
Hub | 0 | U401 | TI | IC PWR DIST SWITCH SNGL SOT23-5,Digikey 296-21263-1-ND | TPS2041BDBVR | DBV5 | TPS2041B_DBV_5 | Digikey | 296-21263-1-ND | DNP- Parts Removed from PCB
Hub | 1 | U402 | TI | IC REG BUCK SYNC 3.3V 0.5A 6SON,Digikey 296-25630-1-ND | TPS62237DRYT | DRY6 | TPS62237DRY | Digikey | 296-25630-1-ND
Hub | 0 | U403 | TI | IC PWR DIST SWITCH SNGL SOT23-5,Digikey 296-21263-1-ND | TPS2041BDBVR | DBV5 | TPS2041B_DBV_5 | Digikey | 296-21263-1-ND | DNP- Parts Removed from PCB
Hub | 1 | U404 | TI | IC ESD-PROT ARRAY 2CH SOT-5,Digikey 296-21883-1-ND | TPD2E001DRLR | TPD2E001-DRL | TPD2E001DRLR | Digikey | 296-21883-1-ND
LP | 1 | U6 | TI | IC MCU 16BIT 128K FLASH 80LQFP,Digikey 296-27306-1-ND | MSP430F5529IPNR | PN80 | MSP430F5529IPNR | Digikey | 296-27306-1-ND
PCB | 1 | STAND1 | PCB | Mounting Hole 110 mil, Digikey nothing-to-purchase |  | 110mil | 110mil | Digikey | nothing-to-purchase
PCB | 1 | STAND2 | PCB | Mounting Hole 110 mil, Digikey nothing-to-purchase |  | 110mil | 110mil | Digikey | nothing-to-purchase
PCB | 1 | STAND3 | PCB | Mounting Hole 110 mil, Digikey nothing-to-purchase |  | 110mil | 110mil | Digikey | nothing-to-purchase
PCB | 1 | STAND4 | PCB | Mounting Hole 110 mil, Digikey nothing-to-purchase |  | 110mil | 110mil | Digikey | nothing-to-purchase

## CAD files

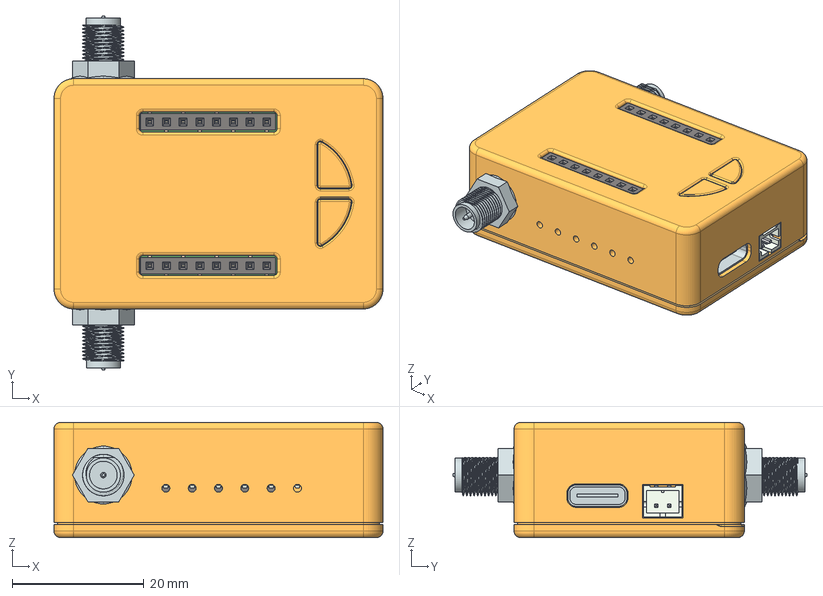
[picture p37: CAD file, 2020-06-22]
case/mechanical design/BeagleConnect_B_PCB_Placement_v2.0.stp
50.0 x 53.7 x 17.5 mm
下壳
Type C
上壳
天线通螺母接头 x 2
硅胶塞 x 2
按键1

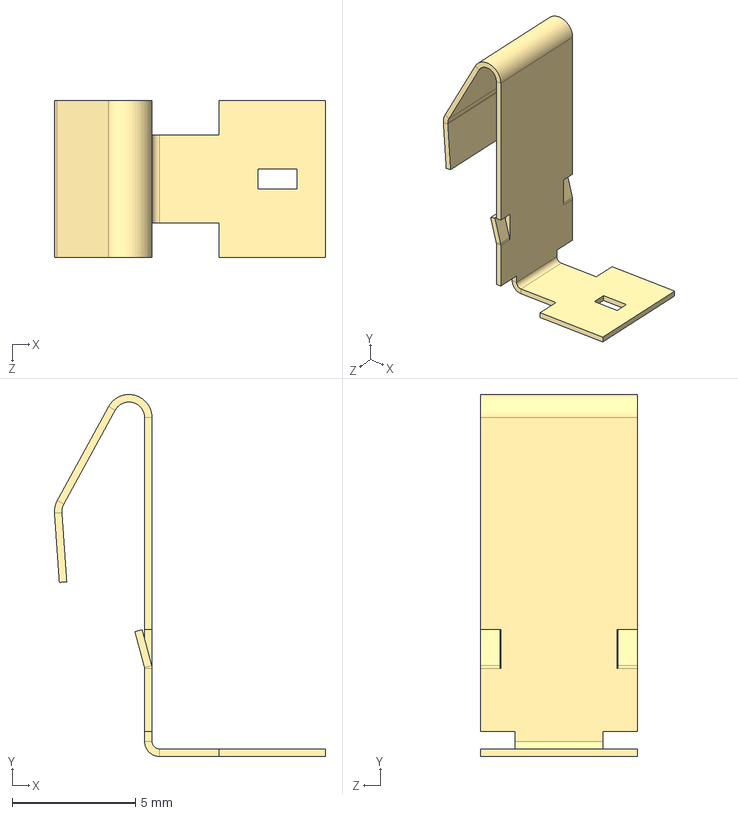
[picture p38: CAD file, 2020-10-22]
hw/Freedom_C4/mech/keystone-PN1016-1.STEP
11.0 x 14.7 x 6.35 mm

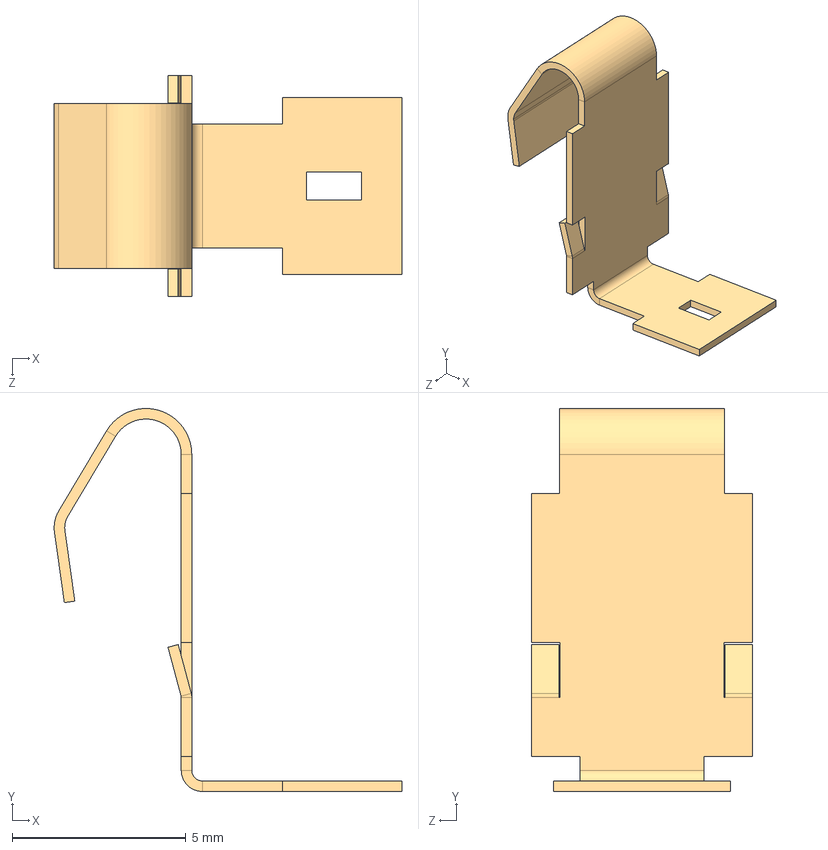
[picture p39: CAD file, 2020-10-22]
hw/Freedom_C4/mech/keystone-PN1020-1.STEP
10.0 x 11.0 x 6.35 mm

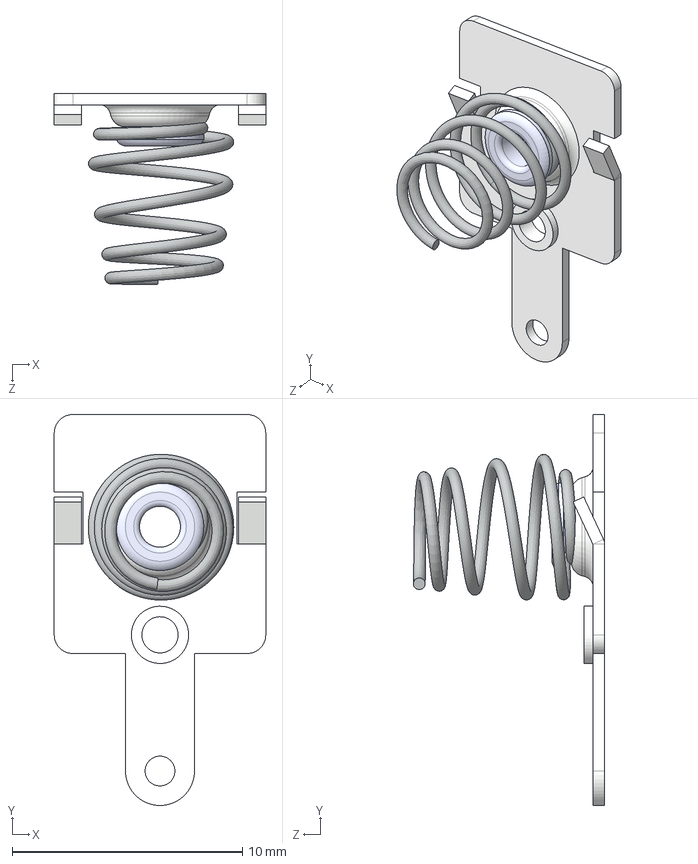
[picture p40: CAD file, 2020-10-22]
hw/Freedom_C4/mech/keystone-PN5204.STEP
9.19 x 17.0 x 8.31 mm

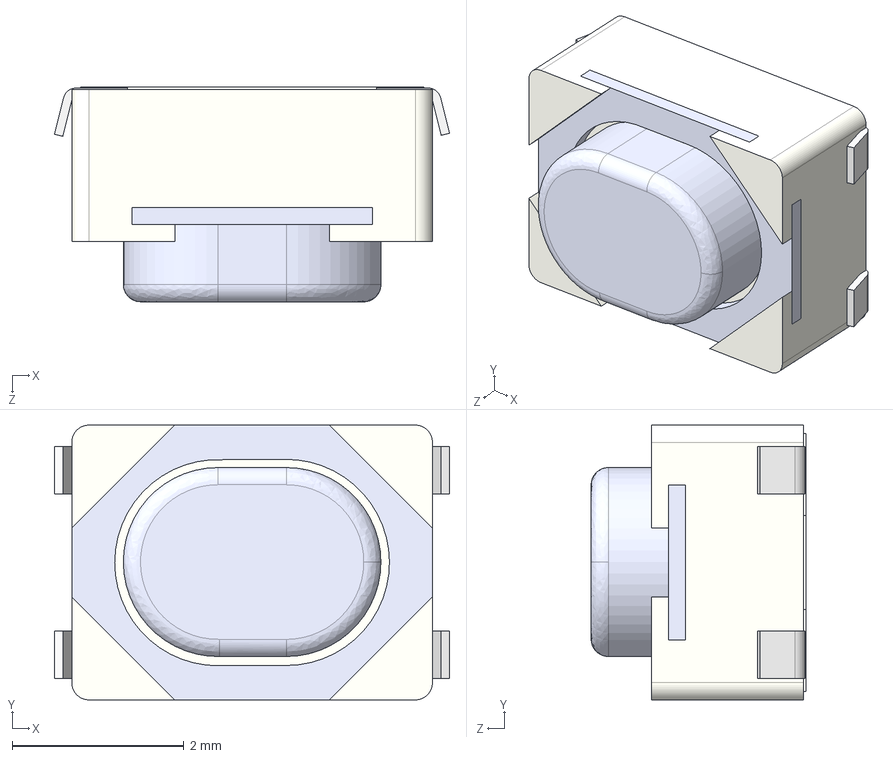
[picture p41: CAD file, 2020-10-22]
hw/Freedom_C4/mech/PTS810.STEP
4.60 x 3.20 x 2.50 mm
Strip
Button
Sheet Metal Part6 x 2
Pin

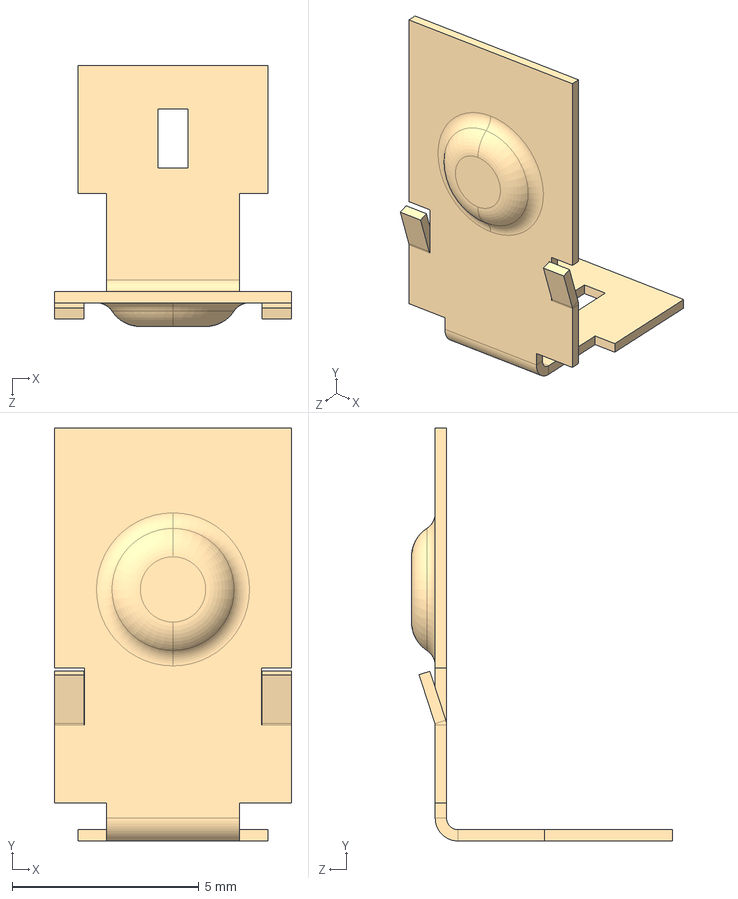
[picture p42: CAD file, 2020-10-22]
hw/Freedom_C4/mech/keystone-PN1076-1.STEP
6.35 x 11.0 x 6.99 mm

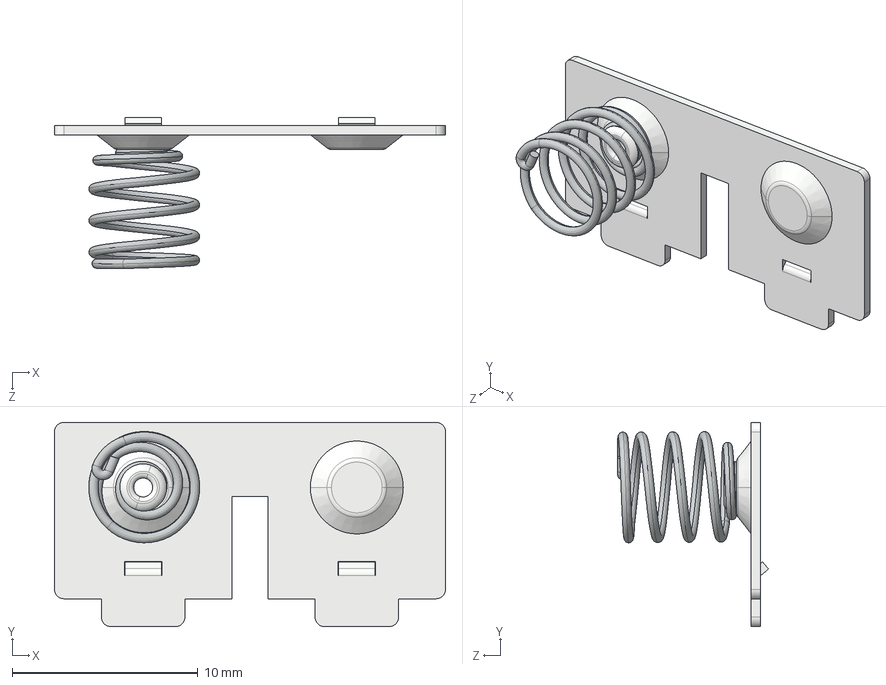
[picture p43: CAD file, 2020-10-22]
hw/Freedom_C4/mech/keystone-PN5213.STEP
21.1 x 11.0 x 8.14 mm

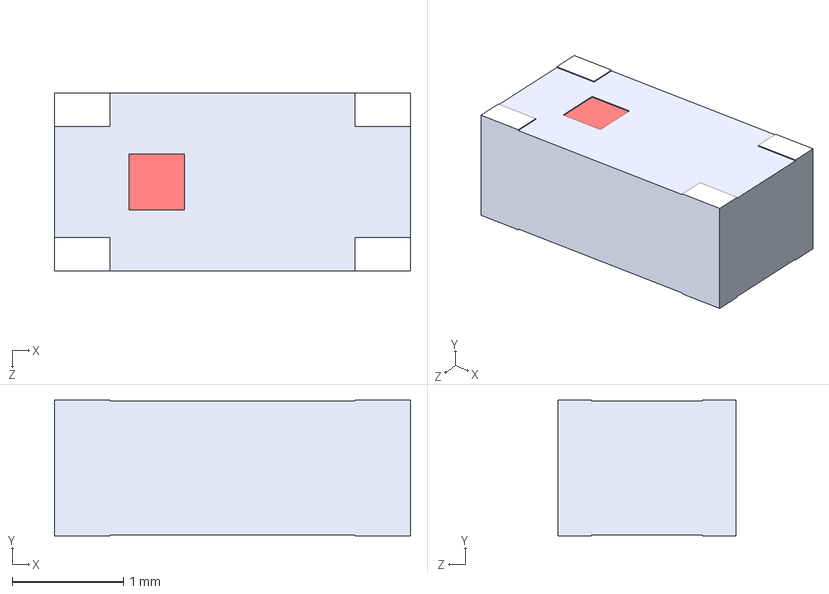
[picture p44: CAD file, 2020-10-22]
hw/Freedom_C4/mech/2450AT18D0100.STEP
3.20 x 1.22 x 1.60 mm

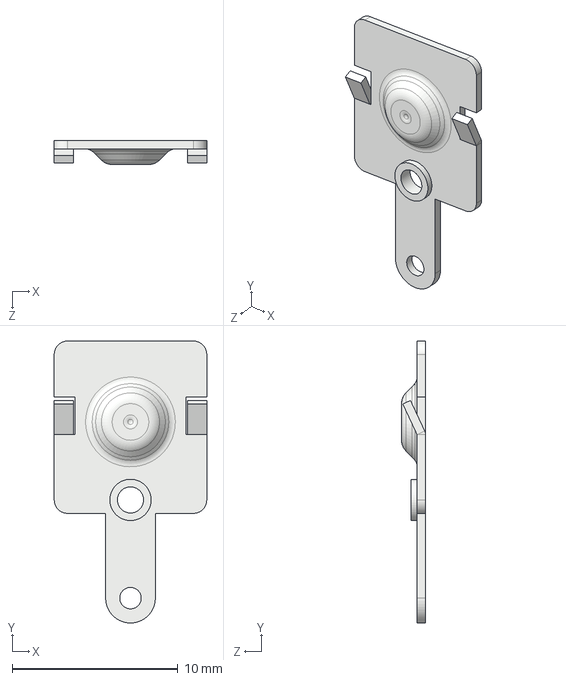
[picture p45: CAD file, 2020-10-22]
hw/Freedom_C4/mech/keystone-PN5226.STEP
9.19 x 17.0 x 1.45 mm

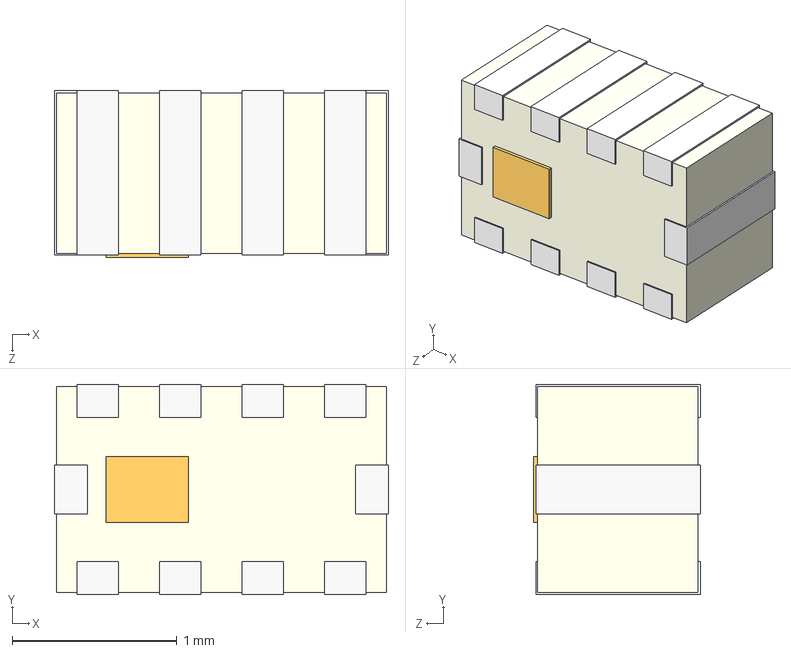
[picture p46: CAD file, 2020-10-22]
hw/Freedom_C4/mech/0900PC15J0013.STEP
2.02 x 1.27 x 1.01 mm
Pin09
Pin05
Pin03
Pin01
Pin10
Pin02
Pin04
Pin08
Pin06
Pin07

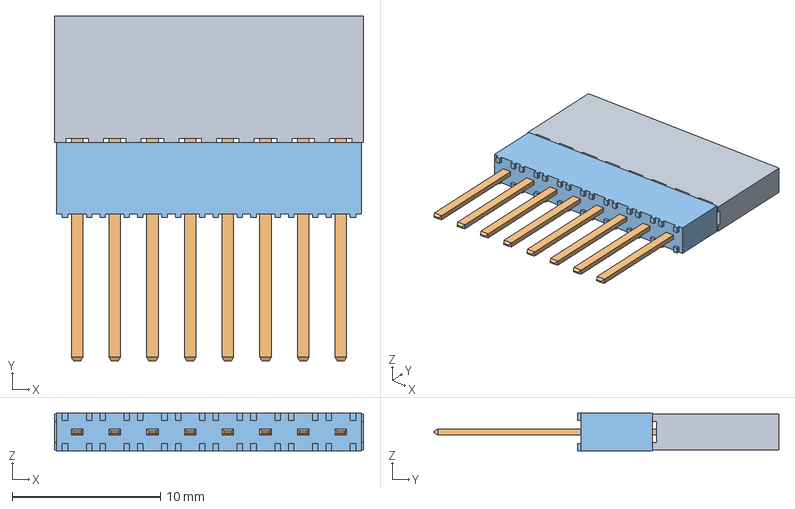
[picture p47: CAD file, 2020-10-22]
hw/Freedom_C4/mech/ESW-108-24-L-S.stp
20.8 x 23.2 x 2.54 mm
_ESW-108-24-L-S_socket
_ESW-108-24-L-S_pins
_ESW-108-24-L-S_bsocket

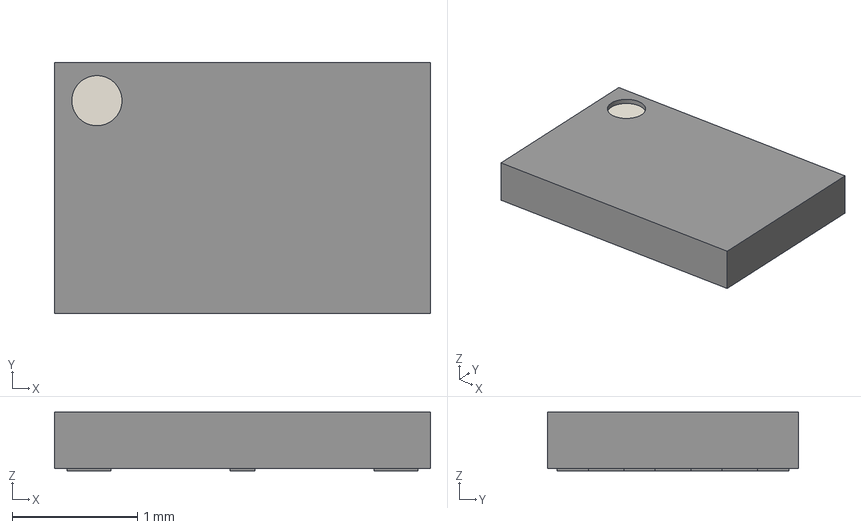
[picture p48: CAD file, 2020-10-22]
hw/Freedom_C4/mech/USON8_3x2mm.step
3.00 x 2.00 x 0.47 mm

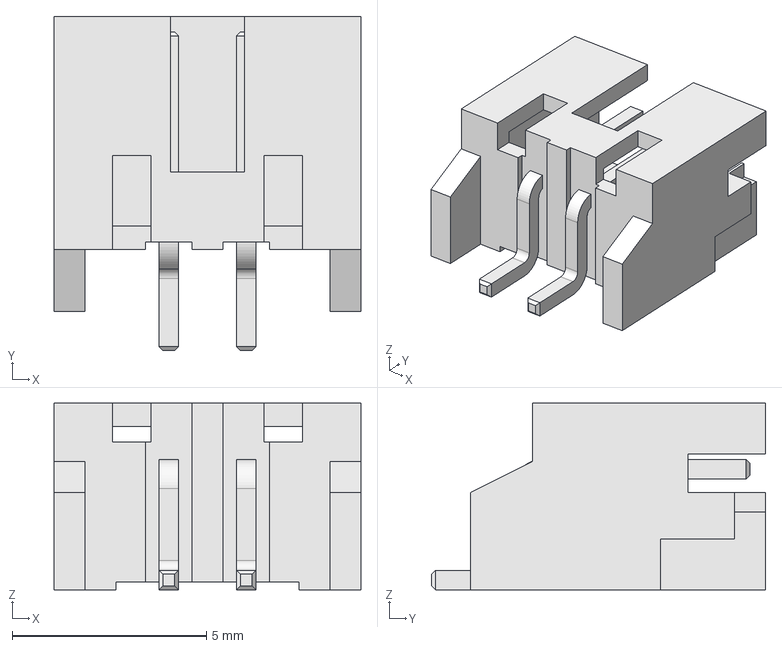
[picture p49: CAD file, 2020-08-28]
hw/Freedom_C4/mech/s2b-PH.step
7.90 x 8.60 x 4.80 mm

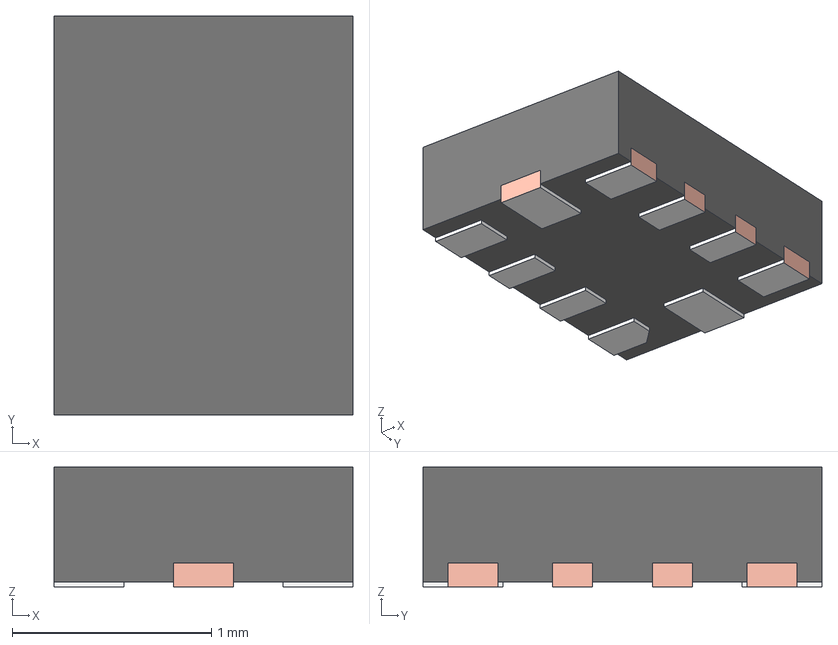
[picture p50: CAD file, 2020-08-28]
hw/Freedom_C4/mech/TS5A23157RSER.stp
1.50 x 2.00 x 0.6 mm
FRAME-RSE0010A
BODY-QFN
PIN1-ID

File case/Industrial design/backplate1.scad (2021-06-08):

color("black")
rotate([90,0,0])
linear_extrude(1.57) 
difference() {
  offset(r=3) offset(delta=-3) polygon(
  [[0,0],[0,35],[44,35],
  [44,15],[100,15],[100,0],[0,0]]);
}

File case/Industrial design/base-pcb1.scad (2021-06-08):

color("black")
translate([96-25.4,60-9*2.54,1.57])
linear_extrude(1.57)
union() {
  square([2.54,8*2.54]);
  translate([9*2.54,0,0])
    square([2.54,8*2.54]);
}

color("green")
linear_extrude(1.57) 
difference() {
  offset(r=3) offset(delta=-3) polygon(
  [[0,0],[0,60],[100,60],
  [100,0],[0,0]]);
  translate([96,30,0]) square([4,30]);
  translate([96-(25.4)-30,30,0]) square([30,30]);
}

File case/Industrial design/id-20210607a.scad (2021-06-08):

union() {
color("black")
translate([0,60-9*2.54,1.57])
union() {
cube([2.54,8*2.54,1.57]);
translate([9*2.54,0,0])
cube([2.54,8*2.54,1.57]);
}
color("green")
linear_extrude(1.57)
square([25.4,60]);
color("yellow")
translate([0,0,-10])
cube([25.4,40,10]);
}

translate([-5,0,10])
union() {
color("black")
translate([0,60-9*2.54,0.79])
union() {
cube([2.54,8*2.54,7.5]);
translate([9*2.54,0,0])
cube([2.54,8*2.54,7.5]);
}
color("green")
cube([40,60,0.79]);
}

translate([25.4,0,20])
rotate([0,180,0])
union() {
color("black")
translate([0,60-9*2.54,1.57])
union() {
cube([2.54,8*2.54,1.57]);
translate([9*2.54,0,0])
cube([2.54,8*2.54,1.57]);
}
color("green")
cube([25.4,60,1.57]);
color("yellow")
translate([0,0,-10])
cube([25.4,40,10]);
}

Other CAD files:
hw/Freedom_C4/mech/YPA0006ABAB_TEX.step
hw/Freedom_C4/mech/LGA-12_STM-M.step
hw/Freedom_C4/mech/USB Type C Port (SMD Type).STEP
case/mechanical design/BeagleConnect_B_PCB_Placement_v2.0.dxf
hw/Freedom/mech/0900PC15J0013.STEP
hw/Freedom/mech/1054500101.stp
hw/Freedom/mech/2450AT18D0100.STEP
hw/Freedom/mech/AAA Battery.STEP
hw/Freedom/mech/DNP0006A.stp
hw/Freedom/mech/ESW-108-24-L-S.stp
hw/Freedom/mech/EVQP7-JA-01P.STEP
hw/Freedom/mech/LGA-12_STM-L.step
hw/Freedom/mech/LGA-12_STM-M.step
hw/Freedom/mech/LGA-12_STM.step
hw/Freedom/mech/Leash_061319.step
hw/Freedom/mech/PTS810.STEP
hw/Freedom/mech/TPS62821.stp
hw/Freedom/mech/TS5A23157RSER.stp
hw/Freedom/mech/USB Type C Port (SMD Type).STEP
hw/Freedom/mech/USON8_3x2mm.step
hw/Freedom/mech/YPA0006ABAB_TEX.step
hw/Freedom/mech/a_1jb_3d_model_file.stp
hw/Freedom/mech/keystone-PN1016-1.STEP
hw/Freedom/mech/keystone-PN1020-1.STEP
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

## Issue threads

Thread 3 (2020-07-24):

Add MSP430 DFU mode via button press

statropy, 2020-07-24:
Pressing the USER1 button during USB insertion should put the MSP430 into USB DFU (firmware update) mode. The PUR pin needs to be pulled up to trigger this mode. See launchpad schematic for BSL button example:

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

jadonk, 2020-07-28:
@ChrisGammell is this change in the rev C schematic? Will you update today or should we ask @FionaYu20180326 at Seeed to fix?

statropy, 2020-07-28:
Looks complete to me, I think this can be closed

ChrisGammell, 2020-07-28:
Yes, this was fixed in c925208, it didn't pick up on the issue number (I had tagged #4 and #5 in my commit)

Closed 2020-07-28.

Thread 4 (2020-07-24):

CC1352R Boot trigger

statropy, 2020-07-24:
The CC1352R needs to be able to be placed in BSL (bootloader) mode by button press and programatically by the MSP430. The default boot pin is DIO15, active low. Pressing USER1 button should ground DIO15. The MSP430 needs to be able to control DIO15 and NReset of the CC1352R. No pull-up on USER1 is needed as an internal pull-up is configured by default.

Closed 2020-07-24.

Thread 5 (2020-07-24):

UART Pins for BSL

statropy, 2020-07-24:
The CC1352R serial bootloader (BSL) can only use pins DIO12 (CC1352R RX) and DIO13 (CC1352R TX). These pins should be connected to the MSP430 UART pins P4.4 (MSP430 TX) and P4.5 (MSP430 RX).

The CC1352R only has 2 UARTs available, so one must be shared with the external connector and the MSP430. Additionally, so that there is not contention for the UART pins, the MSP430 needs a method of switching the drive of the UART from the external connector to the MSP430 when USB is enumerated. This will prevent a UART connection to a module when connected via USB on that header.

statropy, 2020-07-27:
DIO12/DIO13 of CC1352R are switched in c925208247cc354a4dd9d04e9ffbb444a79c473b.

jadonk, 2020-07-28:
> DIO12/DIO13 of CC1352R are switched in [c925208](https://github.com/jadonk/beagleconnect/commit/c925208247cc354a4dd9d04e9ffbb444a79c473b).

Is this comment documentation or a request for correction?

statropy, 2020-07-28:
This needs to be fixed

Closed 2020-07-28.

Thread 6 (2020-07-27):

MSP430 Spy-Bi-Wire connections

statropy, 2020-07-27:
The simplest and default connection for MSP430 program/debug is the Spy-Bi-Wire interface, outlined in https://www.ti.com/lit/ug/slau278af/slau278af.pdf page 23 (screenshot below). The 4 connections needed are

|Signal | MSP430 | Tag Connect |
|---------|-------|-------|
| RST/NMI/SBWTDIO | 48 | 1 |
| TEST/SBWTCK | 47 | 7 |
| GND | | 9 |
| VCC |  | 4 |

The JTAG signals do not need to be connected, but the JTAG signals can still be routed to the connector using DNP 0-Ohm resistors. As long as the default mode is Spy-Bi-Wire.

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

jadonk, 2020-07-28:
@ChrisGammell are you making this change today or should we just ask @FionaYu20180326 at Seeed?

Closed 2020-07-28.

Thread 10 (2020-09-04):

Switch to Zephyr TI radio driver

jadonk, 2020-09-04:
The current Zephyr 802.15.4 driver for the CC1352R is a custom developed driver. Changing this
driver to instead use the already existing TI radio drivers will provide a more consistent interface
and ease the addition of Sub GHz communication. To support the Host Gateway, the 802.15.4
driver for the CC1352R also needs to have CONFIG_IEEE802154_RAW_MODE support added,
to allow direct access to the radio API (instead of using the Zephyr network layer).

cfriedt, 2020-09-13:
Issue: zephyrproject-rtos/zephyr#26312
PR: zephyrproject-rtos/zephyr#26316

jadonk, 2020-09-16:
Cool. Looks like the PR is still open though. Hope it gets merged soon.

cfriedt, 2020-09-24:
Yeah - everyone in the Zephyr community is kind of in crunch time right now because they're on 2.4.0-rc2 and 2.4.0 is set to be released imminently. I would assume that most / all of our changes will make it in for 2.5.0.

Although with the email from Tel Aviv last night / today, I'm going to give the TX optimization a shot again since the PR is still open.

CONFIG_IEEE802154_RAW_MODE looks pretty trivial, but it would definitely go into a separate issue / PR.

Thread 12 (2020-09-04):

Leash+Linux SW Documentation

jadonk, 2020-09-04:
- [ ] complete documentation of implementation
- [ ] step-by-step guides for compilation and usage
- [ ] prepare source code so that it is ready to upstream
- [ ] prepare slides and demonstrations for presentation

cfriedt, 2020-11-12:
IEEE 802.15.4 + CC1352R1 LaunchXL
https://gist.github.com/cfriedt/83becb9c483a818852894491b94b1eae

Blink an LED using Linux, Zephyr & Greybus via Bluetooth
GPIO LED
https://gist.github.com/cfriedt/f2026ed38025b30c67103088e14198d6

Blink an LED using Linux, Zephyr & Greybus via IEEE 802.15.4
GPIO LED
https://gist.github.com/cfriedt/67d88a7312b025d8c365b9b67d934c25
https://www.zephyrproject.org/blink-an-led-using-linux-zephyr-greybus-via-ieee-802-15-4/

https://linuxplumbersconf.org/event/7/contributions/814/
[Using_Linux_Zephyr_and_Greybus_for_IoT_slides.pdf](https://github.com/jadonk/beagleconnect/files/5531850/Using_Linux_Zephyr_and_Greybus_for_IoT_slides.pdf)

Using Linux, Zephyr & Greybus for IoT with the CC1352R SensorTag
GPIO LED + I2C
https://gist.github.com/cfriedt/9ad6a10250b5098e1aeb25193c2c9ba3
https://www.zephyrproject.org/using-linux-zephyr-greybus-for-iot/

The Greybus-for-Zephyr module will have additional documentation at
https://github.com/cfriedt/greybus-for-zephyr
shortly.

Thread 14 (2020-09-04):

BLE Greybus demo

jadonk, 2020-09-04:
- [ ] Unit Tests demonstrating required functionality
- [ ] Integration of Greybus into basic Bluetooth demonstration application
- [ ] Enumeration of SPI & I2C via Greybus over Bluetooth
- [ ] Linux host demo application that
pairs with the The Platform
enumerates remote SPI & I2C via Bluetooth & Greybus
- [ ] performs remote SPI & I2C transactions on simple, readily available SPI & I2C peripherals via Bluetooth & Greybus

jadonk, 2020-09-18:
Is this on an nRF or CC1352? I think we need to break down any nRF elements into a different issue.

cfriedt, 2020-11-12:
I'll follow up with TI to see if they will fund the BLE driver work
Otherwise, the demo is documented here:
https://gist.github.com/cfriedt/f2026ed38025b30c67103088e14198d6

Nowadays, with the greybus service, it's more like this but with `-DCONF_FILE=overlay-bt.conf`. All that needs to be changed is the board in use when the BLE driver is complete.
https://gist.github.com/cfriedt/9ad6a10250b5098e1aeb25193c2c9ba3

cfriedt, 2020-11-12:
Working on SPI next.

jadonk, 2021-01-15:
@cfriedt can you document what the issue seen with BLE is?

cfriedt, 2021-01-15:
Yes. This was rebased in June 2020 from previous work in March 2020. L

At this point, the CONNECT_IND message is processed, both the Linux host and Zephyr have made the connection (i.e. paired) but then there is a timeout with the initial TX window.

https://github.com/cfriedt/zephyr/tree/and-now-for-something-completely-different-rebased/subsys/bluetooth/controller/ll_sw/ti

jadonk, 2021-01-25:
Can you please document the issue with the TI BLE stack on e2e.ti.com and link here?

cfriedt, 2021-01-25:
> Can you please document the issue with the TI BLE stack on e2e.ti.com and link here?

TI's BLE5 Stack (and even the 'micro ble stack') require TI-RTOS. TI has no plans to support BLE5 Stack on anything other than TI-RTOS from what I've been told.

I've documented the issue on e2e.ti.com, although the post is awaiting moderator approval.

cfriedt, 2021-01-25:
https://e2e.ti.com/support/wireless-connectivity/bluetooth/f/538/t/973763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

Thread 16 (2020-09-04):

Leash rev C hardware

jadonk, 2020-09-04:
- [x] new layout
- [x] prototypes built
- [x] case prototypes built
- [x] validated

jadonk, 2020-11-04:
Superseeded by BeagleConnect Freedom rev C2.

Only confirmed case issue is to improve the silkscreen.

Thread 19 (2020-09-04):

Mikrobus driver

jadonk, 2020-09-04:
- [x] mikroBUS kernel driver patch with support tested for few example clicks
- [ ] Tested support for at least 140 different Click Boards
- [ ] Documentation, development/improvement of driver and any related userspace utilities

jadonk, 2021-01-25:
@vaishnav98 can you work on the README.md for using the latest code? I think we can create releases for the assets produced in the CI if you want to simplify the directions on usage vs. building.

vaishnav98, 2021-01-26:
Sure @jadonk I will add the step required for reproducing in README, currently the Click ID/manifest fetching mechanism is not yet added in Zephyr yet, also the zephr changes are made here  https://github.com/vaishnav98/greybus-for-zephyr/tree/mikrobus should I submit a PR to https://github.com/jadonk/greybus-for-zephyr or should add as a new submodule under https://github.com/jadonk/beagleconnect/tree/master/sw/zephyrproject ?

jadonk, 2021-01-26:
As we discussed on the call, add a new submodule *and* provide a pull request to @cfriedt greybus-for-zephyr repo. You can also create a PR for mine.

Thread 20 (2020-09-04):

Sub-G 802.15.4 Greybus demo

jadonk, 2020-09-04:
- [ ] Connect at Sub-G radio frequency
- [ ] Minimal patching for Linux (CC1352 to register with Linux WPAN subsystem)
- [ ] Linux host demo application that
forms an 802.15.4 PAN (Personal Area Network) with coordinator node
allows RFD to join PAN
- [ ] enumerates remote SPI & I2C via 6LowPan & Greybus
- [ ] performs remote SPI & I2C transactions on simple, readily available SPI & I2C peripherals via 6LowPan & Greybus

cfriedt, 2020-09-12:
LIkely will remove the requirement for coordinator. It's unnecessary for 6LowPAN and currently not anywhere close to being implemented on the Linux side. IEEE 802.15.4 joining isn't even necessary to use 6LowPAN over 15.4.

The host demo application is essentially the same as that for BLE and 2.4GHz 15.4.

This ticket should probably also be a Milestone.

There are really 2 remaining issues to complete this Milestone:
* zephyrprojectrtos/zephyr#26312 (PR: zephyrprojectrtos/zephyr#26316)
* zephyrprojectrtos/zephyr#26315 (PR forthcoming)

cfriedt, 2020-11-12:
Video of SubGHz Blinky

https://twitter.com/cfriedt/status/1324757273026154496

I2C transactions over SubGHz:
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

Just working on SPI now.

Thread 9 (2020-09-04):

Fix Bluetooth (BLE) in Zephyr on CC1352R

jadonk, 2020-09-04:
TI promised some help with this, but unsure if it is ever coming. Using 802.15.4 for the 2.4GHz doesn't give us the ability to connect to typical laptops that already have BLE radios.

jadonk, 2021-01-25:
One possible resolution is to take the Zephyr Split-Stack Bluetooth API and port it to the CC1352P.

- [ ] An implementation of the Zephyr Split-Stack Bluetooth API under zephyr/subsys/bluetooth/controller/ll_sw/ti/
- [ ] Pairing between the Linux host with BLE and CC1352P BeagleConnect Freedom device
- [ ] Sustained Bluetooth (BLE) operation between the Linux host and CC1352P BeagleConnect Freedom device
- [ ] Demonstrate the CC1352P running zephyr/samples/bluetooth/peripheral_hr/
- [ ] Demonstrate the CC1352P running zephyr/samples/bluetooth/ipsp/

Pillar1989, 2021-09-08:
https://software-dl.ti.com/simplelink/esd/simplelink_cc13x2_26x2_sdk/4.40.00.44/exports/docs/ble5stack/ble_user_guide/html/ble-mesh/ti-zephyr-overview.html @jadonk   It seam It had do some explore about this.

Pillar1989, 2021-10-09:
https://github.com/cfriedt/zephyr/blob/37ea335ea56963893897695051538a76a11ca739/subsys/bluetooth/controller/ll_sw/ti/README.md  @jadonk @cfriedt

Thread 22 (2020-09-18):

Silkscreen design for Leash case

jadonk, 2020-09-18:

jadonk, 2020-10-23:
This needs to be updated for 3-side markings and the new product name "BeagleBoard.org BeagleConnect Freedom".

jadonk, 2021-12-24:
#66 duplicate

Closed 2021-12-24.

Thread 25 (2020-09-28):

Host gateway config for BeagleBone AI and/or PocketBeagle

jadonk, 2020-09-28:
- [ ] Kernel: greybus/gb-netlink drivers
- [ ] Kernel: mikrobus drivers
- [ ] Kernel: Environmental Click driver
- [ ] Kernel: PM2.5 driver
- [ ] GBridge
- [ ] Node-RED: sources for sensors
- [ ] Integration: automated configuration and service start-up
- [ ] Integration: integrated disk image

jadonk, 2020-09-28:
PM2.5 example code: https://github.com/Seeed-Studio/Seeed_PM2_5_sensor_HM3301/blob/master/src/Seeed_HM330X.cpp

jadonk, 2021-01-25:
@vaishnav98 can you check where we are on these? Do you need a PM2.5 sensor? We likely need to ship you more boards. Please bug me for that.

vaishnav98, 2021-01-26:
@jadonk we are very close to this would like to have PM2.5 sensor and the latest HW, also one concern is the need to continuously send some traffic (https://github.com/jadonk/beagleconnect/blob/master/sw/buildroot/board/beagleboard/beagleconnect_gateway_qemu_x86_64/rootfs_overlay/opt/gbridge.sh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) so that the kernel panic/Netlink issue does not happen(looks like it is something related to greybus power management as it does not happen when the continuous background transactions are present), this was same on PocketBeagle as host and also on the qemux86(buildroot image) setup.

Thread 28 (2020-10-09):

HW: LeashPCB rev C USB not wired completely for cable swap

jadonk, 2020-10-09:
I'm finding that plugging in the USB cable that orientation matters. It should not. D+/D- should be routed to both sides with minimal stubs. Cc @FionaYu20180326

FionaYu20180326, 2020-10-12:
Sure. I will change the design in next sample building.

jadonk, 2020-12-29:
Resolved in C2.

Closed 2020-12-29.

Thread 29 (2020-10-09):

HW: Leash PCB rev C: mikrobus connector rotated

jadonk, 2020-10-09:
It seems the mikroBUS socket on the side of the board with the buttons is facing the wrong way. The mikroBUS add-on boards should extend *away* from the buttons as not to cover them up. This is wrong for sure.

The mikroBUS socket on the USB/battery side of the board faces away from the USB/battery, which is probably fine. Originally, the thought was to have the top/bottom side connectors facing opposite directions, but this is probably better due to assumptions likely to be made regarding the board orientation. We can discuss.

cc @FionaYu20180326

FionaYu20180326, 2020-10-12:
Sure. Let's talk about this and modify the PCB placement.

jadonk, 2020-11-02:
The rev C2 release did not fix this layout issue.

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

jadonk, 2020-11-16:
Rev C2 placement fix:

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

Closed 2021-01-15.

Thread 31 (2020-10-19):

HW: Leash PCB rev C: kicad_pcb file not up to date

statropy, 2020-10-19:
The hw/Leash/LeashPCB.kicad_pcb file does not match the Rev C board layout.

Error when opening hw/Leash/LeashPCB.sch
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

FionaYu20180326, 2020-10-20:
This may because of the different components library. We are trying to fix it, and will update Git once done.

statropy, 2020-10-20:
More importantly the PCB layout does not match the Rev C board. I really need this to be able to trace through and test hardware. Even if there are errors, please update the kicad_pcb file to the one used to make Rev C

FionaYu20180326, 2020-10-21:
Updated. In case that there may meet some issues if we cover old version, so I created a new folder. Please check #34

Closed 2022-01-06.

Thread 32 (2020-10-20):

CC1352R and CC1352P are not pin compatible

statropy, 2020-10-20:
Pins 5-9 have different assignments on the CC1352R vs CC1352P

Pin | CC1352R | CC1352P
---|----------|-----------
5 | RX_TX Bias | TX_20DBM_P
6 | X32K_Q1 | TX_20DBM_N
7 | X32K_Q2 | RX_TX Bias
8 | DIO_3 | X32K_Q1
9 | DIO_4 | X32K_Q2

jadonk, 2020-10-20:
Probably makes sense for us to stick with CC1352*P*. Looks like we'll need to move the 2.4GHz and SubGHz LEDs over to some other pins and move the User 1 and 2 LEDs over to the MSP430.

Also, looks like we'd want to use the output from the amplifier and adjust the layout to optimize for it.

jadonk, 2020-11-02:
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

jadonk, 2020-11-17:
Missed the radio interface changes:

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

jadonk, 2020-12-12:
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

New RF section:
* 2.4GHz uses on-board chip antenna by default population.
* SubGHz should have used AE2 spring antenna by default, but the population options above show the connection isn't populated and the J7 U.FL is used by default population.
* The power amplifier output is given a SubGHz balun and is TX only. I believe the current board has a wire modification to enable this, but this needs to be documented.

Notes:
* Populating the J6 U.FL for 2.4GHz doesn't make sense without populating the cap, so next version should remove J6.
* Using AE2 should be the default and J7 U.FL should be not populated on the next version.

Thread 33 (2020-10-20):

HW: Sensor interrupt design is incorrect

statropy, 2020-10-20:
The sensor interrupt design was changed incorrectly in Rev C. The Rev B design combined interrupt signals from the 3 on-board sensors (OPT3001, HDC2010 and LIS2DE12) through a logic-OR IC to provide the CC1352R with a single interrupt input that could be triggered by any of the 3 sensors. It would then be up to the CC1352R control software do poll each sensor to determine which provided the interrupt signal. The reason for this design is to reduce the required pins used on the CC1352R from 3 to 1.

The Rev C design has flipped the logic such that the CC1352R interrupt input is now an OUTPUT that is split and routed through Schottky Barrier Diodes to each of the sensor interrupt OUTPUT pins. This will not work and may damage the sensors if this pin is actively driven by the CC1352R.

qunanan, 2020-10-21:
Hi, I think the previous interuupt design has issues. First ,The OPT3301's interrupt pin has not connected. The second is LIS2DE12 has multiple interrupt outputs, any of the interrupt pins can be setuped by register. The other reason to modify the design is to reduce the cost of bom.

Let me explain how current desgin work：
The interrupt pin of OPT3011 can be setup as open-drain mod , this pin connected to the MCU derectly.
The interrupt pin of LIS2DE12 and HDC2010 can be setup as Push-Pull active-low mode, these pins connected to the MCU through diode and isolated mutual influences by the diodes.
Any one of the sensor's interrupt signal can put the INT_SENSOR signal to low to indicate the MCU.

statropy, 2020-10-21:
Now that I have the Rev C schematics and layout, I can trace the signals through the diodes. The push-pull interrupts are default configured to active high. Switching both LISDE12 and HDC2010 to active low allowed the interrupt to trigger. The shared interrupt doesn't fit very well with the Zephyr driver and device tree system, but the hardware does work as intended.

Closed 2020-10-21.

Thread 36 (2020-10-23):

HW: buck-only regulator only operates down to 3.5V

jadonk, 2020-10-23:
When using a LiPo battery, the life is severely limited due to the lack of a boost regulator.

jadonk, 2020-12-29:
See https://github.com/jadonk/beagleconnect/issues/41

Ddevendra, 2022-01-02:
does this issue still exists, if yes, I believe it could be solved by some of these methods

- changing voltage conversion IC to
	- [LTC3440](https://www.analog.com/en/products/ltc3440.html#product-overview)
	- [TPS61200](https://www.ti.com/product/TPS61200)
_These are some standalone ICs for single cell power management_

- using VLDO voltage regulator (useful only if entire board can operate on complete voltage range 3.3v-3.0v)

- using PowerMUX like [TPS2116](https://www.ti.com/product/TPS2116)

jadonk, 2022-01-06:
No, we switched to an "ideal diode".

Closed 2022-01-06.

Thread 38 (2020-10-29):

SubG Greybus Demo

jadonk, 2020-10-29:
- [x] CI for MSP430 firmware for UART pass-through (for flashing CC1352) @statropy
- [x] CI for MSP430 firmware for wpanusb @statropy and @jadonk
- [x] Main repo has instructions for flashing the MSP430 and CC1352 @statropy
- [x] CI for CC1352 firmware for Launchpad supporting 2.4G/SubG, Greybus w/ GPIO/I2C @cfriedt
- [x] CI for CC1352 firmware for BeagleConnect Freedom supporting wpanusb @cfriedt and @statropy
- [x] CI for qemu image with wpanusb driver @jadonk and @statropy

jadonk, 2020-11-05:
We need to set some new requirements to be completed for the next week! These are all completed, but it still isn't reproduced.

Closed 2020-11-05.

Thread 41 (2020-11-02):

HW: Freedom: Ideal diode

jadonk, 2020-11-02:
Replace D1 with an ideal diode circuit to increase battery life by reducing circuit voltage drop.

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

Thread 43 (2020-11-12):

SPI Demo

cfriedt, 2020-11-12:
Demonstrate SPI running over Greybus

jadonk, 2020-12-06:
I've got a new "build-firmware.sh" script. Adding the build steps for each demo project there would be of some value. With the CCACHE, I'm hopeful the CI build times won't go up too crazy.

cfriedt, 2020-12-09:
The ADXL portion has been demonstrated (video in the beagleconnect slack channel) and source code here:

https://github.com/cfriedt/cc1352r-sensortag-adxl362-greybus-demo

As for the OLED C Click board, I recently confirmed with @vaishnav98 that the using the Linux driver unmodified would require additional GPIOs to be passed from platform data which is really more along the lines of creating a mikrobus driver.

I would be happy to write another spidev driver for the OLED C Click board if we create an additional SoW that covers that requirement.

jadonk, 2022-06-09:
@lorforlinux can you replicate this and verify it is integrated and repeatable so we can close this?

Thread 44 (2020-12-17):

HW: add I2C signals to MSP430

jadonk, 2020-12-17:
We need some extra communication between the CC1352 and MSP430. Adding the I2C signals to the MSP430 would be very helpful.

Use pins 30/31 (P4.1/P4.2) (SDA/SCL).

jadonk, 2020-12-24:
@FionaYu20180326 can you confirm there is a fix for C2 (to fix the wire mod)? can you add this as well?

Still having trouble with the SubG radio.

FionaYu20180326, 2020-12-24:
Yes, this is fixed on next sample build.

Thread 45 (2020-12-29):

HW: Freedom: isolate temperature sensor

jadonk, 2020-12-29:
Baozhu, please note the issue here.

Pillar1989, 2020-12-30:
I have communicated this idea to the relevant electronic engineers.

Closed 2022-01-06.

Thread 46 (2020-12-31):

Case: need serial number barcode

jadonk, 2020-12-31:
We need some way to identify these in the field. Ideally, a 2D barcode with the MAC ID would be printed on a sticker on the side. Not sure if that is possible. Somehow, the device itself should have the value on the barcode.

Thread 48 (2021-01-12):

mikroBUS over Greybus

vaishnav98, 2021-01-12:
Hi @jadonk,

Temporarily adding this issue to track mikroBUS over Greybus steps to reproduce, not able to reproduce the buildroot setup still and is failing as before, can you point me on how I should update the beagleconnect repo for steps to repoduce the results?

For now an out of tree Greybus+mikroBUS modules are available/patches are added to bb-kernel repo, the changes are being added here:

- Greybus/mikroBUS Patches : https://github.com/vaishnav98/bb-kernel/commit/711db11fe3bb48c8caa4ac35fb0e0d54cf86a574
- Out of Tree Module (Greybus + mikroBUS) : https://github.com/vaishnav98/greybus/tree/mikrobus_over_greybus
- Zephyr changes: https://github.com/vaishnav98/greybus-for-zephyr/tree/mikrobus

Devices are described over Zephyr DT, the device tree binding for the same is available here: https://github.com/vaishnav98/greybus-for-zephyr/blob/mikrobus/dts/bindings/greybus/zephyr%2Cgreybus-device.yaml

The[ overlay](https://github.com/vaishnav98/greybus-for-zephyr/blob/mikrobus/samples/subsys/greybus/net/boards/cc1352r_sensortag.overlay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) for SensorTag sample(both UART, NET[2.4G] tested) adds the devices on board(OPT3001) and few added Click Boards, all the devices were tested in Polling/no IRQ mode.

Once the changes are taken the steps to reproduce are very similar to the normal Greybus Sample(mikrobus needs to be probed at host additionally)
For build and flash TCP/IP NET 2.4GHz Sample:

```
west build -t flash -p always -b cc1352r_sensortag ../greybus/samples/subsys/greybus/net -- -DOVERLAY_CONFIG=overlay-802154.conf -DCONFIG_NET_CONFIG_IEEE802154_DEV_NAME="\"IEEE802154_0\"" -DCONFIG_IEEE802154_CC13XX_CC26XX=y -DCONFIG_IEEE802154_CC13XX_CC26XX_SUB_GHZ=n
```
For build and flash UART Sample:
```
west build -t flash -p always -b cc1352r_sensortag ../greybus/samples/subsys/greybus/uart
```
At host:
```
gbidge -p /dev/ttyACM0 -b 115200
```
Here is a quick demo with PocketBeagle + ATUSB and CC1352R SensorTag : https://youtu.be/JKrCRRuCw3c?t=143

 TODO:
* GPIO Mapping from Greybus GPIO Chip to mikroBUS port GPIOs.
* SPI Chip Select Mapping.
* Reading manifest from Click ID NVMEM and Patching Base Manifest.

jadonk, 2021-01-15:
Let's get this documented in README.md

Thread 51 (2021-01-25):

SW: Add CC1352P support to Zephyr

jadonk, 2021-01-25:
- [ ] Add SoC CC1352P support under zephyr/soc/arm/ti_simplelink/cc13x2_cc26x2/
- [ ] Add necessary CC1352P drivers from the SimpleLink SDK to zephyrproject/hal/ti/
- [ ] Add SoC-specific entries to IEEE 802.15.4 drivers under zephyr/drivers/ieee802154
- [ ] Verify that IEEE 802.15.4 works with BeagleConnect Freedom at 2.4 GHz
- [ ] Verify that IEEE 802.15.4 works with BeagleConnect Freedom at SubGHz

Pillar1989, 2021-02-02:
Upgrade to version 4_40_00_44 and try to overwrite the original files directly, there are so many affected files.
```
.../ti/devices/cc13x2_cc26x2/driverlib/adi.c  |    86 +-
 .../ti/devices/cc13x2_cc26x2/driverlib/adi.h  |  1582 +-
 .../devices/cc13x2_cc26x2/driverlib/adi_doc.h |   136 +-
 .../ti/devices/cc13x2_cc26x2/driverlib/aes.c  |   744 +-
 .../ti/devices/cc13x2_cc26x2/driverlib/aes.h  |  1686 +-
 .../devices/cc13x2_cc26x2/driverlib/aes_doc.h |   132 +-
 .../cc13x2_cc26x2/driverlib/aon_batmon.c      |   160 +-
 .../cc13x2_cc26x2/driverlib/aon_batmon.h      |   612 +-
 .../cc13x2_cc26x2/driverlib/aon_event.c       |   360 +-
 .../cc13x2_cc26x2/driverlib/aon_event.h       |  1128 +-
 .../cc13x2_cc26x2/driverlib/aon_event_doc.h   |   116 +-
 .../devices/cc13x2_cc26x2/driverlib/aon_ioc.c |    78 +-
 .../devices/cc13x2_cc26x2/driverlib/aon_ioc.h |   584 +-
 .../cc13x2_cc26x2/driverlib/aon_ioc_doc.h     |   130 +-
 .../cc13x2_cc26x2/driverlib/aon_pmctl.c       |    82 +-
 .../cc13x2_cc26x2/driverlib/aon_pmctl.h       |   402 +-
 .../cc13x2_cc26x2/driverlib/aon_pmctl_doc.h   |   198 +-
 .../devices/cc13x2_cc26x2/driverlib/aon_rtc.c |   154 +-
 .../devices/cc13x2_cc26x2/driverlib/aon_rtc.h |  1862 +-
 .../cc13x2_cc26x2/driverlib/aon_rtc_doc.h     |    82 +-
 .../devices/cc13x2_cc26x2/driverlib/aux_adc.c |   709 +-
 .../devices/cc13x2_cc26x2/driverlib/aux_adc.h |  1259 +-
 .../cc13x2_cc26x2/driverlib/aux_smph.c        |    82 +-
 .../cc13x2_cc26x2/driverlib/aux_smph.h        |   516 +-
 .../cc13x2_cc26x2/driverlib/aux_sysif.c       |   192 +-
 .../cc13x2_cc26x2/driverlib/aux_sysif.h       |   308 +-
 .../devices/cc13x2_cc26x2/driverlib/aux_tdc.c |   222 +-
 .../devices/cc13x2_cc26x2/driverlib/aux_tdc.h |  1808 +-
 .../cc13x2_cc26x2/driverlib/ccfgread.c        |    82 +-
 .../cc13x2_cc26x2/driverlib/ccfgread.h        |   442 +-
 .../cc13x2_cc26x2/driverlib/ccfgread_doc.h    |   102 +-
 .../cc13x2_cc26x2/driverlib/chipinfo.c        |   439 +-
 .../cc13x2_cc26x2/driverlib/chipinfo.h        |  1398 +-
 .../ti/devices/cc13x2_cc26x2/driverlib/cpu.c  |   812 +-
 .../ti/devices/cc13x2_cc26x2/driverlib/cpu.h  |   932 +-
 .../devices/cc13x2_cc26x2/driverlib/cpu_doc.h |    88 +-
 .../ti/devices/cc13x2_cc26x2/driverlib/ddi.c  |   428 +-
 .../ti/devices/cc13x2_cc26x2/driverlib/ddi.h  |   924 +-
 .../devices/cc13x2_cc26x2/driverlib/ddi_doc.h |   134 +-
 .../devices/cc13x2_cc26x2/driverlib/debug.c   |   114 +-
 .../devices/cc13x2_cc26x2/driverlib/debug.h   |   168 +-
 .../driverlib/driverlib_release.c             |    90 +-
 .../driverlib/driverlib_release.h             |   312 +-
 .../devices/cc13x2_cc26x2/driverlib/event.c   |    82 +-
 .../devices/cc13x2_cc26x2/driverlib/event.h   |   534 +-
 .../cc13x2_cc26x2/driverlib/event_doc.h       |   116 +-
 .../devices/cc13x2_cc26x2/driverlib/flash.c   |  1337 +-
 .../devices/cc13x2_cc26x2/driverlib/flash.h   |  1640 +-
 .../ti/devices/cc13x2_cc26x2/driverlib/gpio.c |    82 +-
 .../ti/devices/cc13x2_cc26x2/driverlib/gpio.h |  1286 +-
 .../cc13x2_cc26x2/driverlib/gpio_doc.h        |   180 +-
 .../driverlib/group_analog_doc.h              |   210 +-
 .../cc13x2_cc26x2/driverlib/group_aon_doc.h   |   152 +-
 .../cc13x2_cc26x2/driverlib/group_aux_doc.h   |   116 +-
 .../ti/devices/cc13x2_cc26x2/driverlib/i2c.c  |   344 +-
 .../ti/devices/cc13x2_cc26x2/driverlib/i2c.h  |  1948 +-
 .../devices/cc13x2_cc26x2/driverlib/i2c_doc.h |   324 +-
 .../ti/devices/cc13x2_cc26x2/driverlib/i2s.c  |   698 +-
 .../ti/devices/cc13x2_cc26x2/driverlib/i2s.h  |  2718 +-
 .../devices/cc13x2_cc26x2/driverlib/i2s_doc.h |   282 +-
 .../cc13x2_cc26x2/driverlib/interrupt.c       |   938 +-
 .../cc13x2_cc26x2/driverlib/interrupt.h       |  1436 +-
 .../cc13x2_cc26x2/driverlib/interrupt_doc.h   |   324 +-
 .../ti/devices/cc13x2_cc26x2/driverlib/ioc.c  |  1366 +-
 .../ti/devices/cc13x2_cc26x2/driverlib/ioc.h  |  2450 +-
 .../devices/cc13x2_cc26x2/driverlib/ioc_doc.h |   184 +-
 .../ti/devices/cc13x2_cc26x2/driverlib/osc.c  |  1410 +-
 .../ti/devices/cc13x2_cc26x2/driverlib/osc.h  |  1510 +-
 .../ti/devices/cc13x2_cc26x2/driverlib/pka.c  |  3263 +-
 .../ti/devices/cc13x2_cc26x2/driverlib/pka.h  |  2910 +-
 .../devices/cc13x2_cc26x2/driverlib/pka_doc.h |   160 +-
 .../ti/devices/cc13x2_cc26x2/driverlib/prcm.c |  1337 +-
 .../ti/devices/cc13x2_cc26x2/driverlib/prcm.h |  2494 +-
 .../cc13x2_cc26x2/driverlib/pwr_ctrl.c        |   160 +-
 .../cc13x2_cc26x2/driverlib/pwr_ctrl.h        |   602 +-
 .../cc13x2_cc26x2/driverlib/rf_ble_cmd.h      |   223 +
 .../driverlib/rf_bt5_iq_autocopy.h            |   126 +
 .../cc13x2_cc26x2/driverlib/rf_common_cmd.h   |     2 +
 .../cc13x2_cc26x2/driverlib/rf_hid_cmd.h      |   844 +
 .../cc13x2_cc26x2/driverlib/rf_hid_mailbox.h  |    63 +
 .../cc13x2_cc26x2/driverlib/rf_prop_cmd.h     |     4 +
 .../ti/devices/cc13x2_cc26x2/driverlib/rom.h  |  2098 +-
 .../cc13x2_cc26x2/driverlib/rom_crypto.c      |   337 +-
 .../cc13x2_cc26x2/driverlib/rom_crypto.h      |   489 +-
 .../devices/cc13x2_cc26x2/driverlib/setup.c   |   688 +-
 .../devices/cc13x2_cc26x2/driverlib/setup.h   |   282 +-
 .../cc13x2_cc26x2/driverlib/setup_doc.h       |    82 +-
 .../cc13x2_cc26x2/driverlib/setup_rom.c       |  1886 +-
 .../cc13x2_cc26x2/driverlib/setup_rom.h       |   938 +-
 .../cc13x2_cc26x2/driverlib/setup_rom_doc.h   |    88 +-
 .../ti/devices/cc13x2_cc26x2/driverlib/sha2.c |   543 +-
 .../ti/devices/cc13x2_cc26x2/driverlib/sha2.h |  1604 +-
 .../cc13x2_cc26x2/driverlib/sha2_doc.h        |   124 +-
 .../ti/devices/cc13x2_cc26x2/driverlib/smph.c |   202 +-
 .../ti/devices/cc13x2_cc26x2/driverlib/smph.h |   624 +-
 .../cc13x2_cc26x2/driverlib/smph_doc.h        |   114 +-
 .../ti/devices/cc13x2_cc26x2/driverlib/ssi.c  |   506 +-
 .../ti/devices/cc13x2_cc26x2/driverlib/ssi.h  |  1400 +-
 .../cc13x2_cc26x2/driverlib/sw_chacha.c       |   242 +-
 .../driverlib/sw_ecrypt-config.h              |   558 +-
 .../driverlib/sw_ecrypt-machine.h             |   102 +-
 .../driverlib/sw_ecrypt-portable.h            |   616 +-
 .../cc13x2_cc26x2/driverlib/sw_ecrypt-sync.h  |   568 +-
 .../driverlib/sw_poly1305-donna-32.h          |   446 +-
 .../driverlib/sw_poly1305-donna.c             |   372 +-
 .../driverlib/sw_poly1305-donna.h             |    50 +-
 .../cc13x2_cc26x2/driverlib/sys_ctrl.c        |   769 +-
 .../cc13x2_cc26x2/driverlib/sys_ctrl.h        |  1154 +-
 .../devices/cc13x2_cc26x2/driverlib/systick.c |    82 +-
 .../devices/cc13x2_cc26x2/driverlib/systick.h |   574 +-
 .../cc13x2_cc26x2/driverlib/systick_doc.h     |   136 +-
 .../devices/cc13x2_cc26x2/driverlib/timer.c   |   784 +-
 .../devices/cc13x2_cc26x2/driverlib/timer.h   |  2352 +-
 .../cc13x2_cc26x2/driverlib/timer_doc.h       |   242 +-
 .../ti/devices/cc13x2_cc26x2/driverlib/trng.c |   224 +-
 .../ti/devices/cc13x2_cc26x2/driverlib/trng.h |   902 +-
 .../ti/devices/cc13x2_cc26x2/driverlib/uart.c |   608 +-
 .../ti/devices/cc13x2_cc26x2/driverlib/uart.h |  2194 +-
 .../cc13x2_cc26x2/driverlib/uart_doc.h        |   214 +-
 .../ti/devices/cc13x2_cc26x2/driverlib/udma.c |   896 +-
 .../ti/devices/cc13x2_cc26x2/driverlib/udma.h |  2484 +-
 .../ti/devices/cc13x2_cc26x2/driverlib/vims.c |   352 +-
 .../ti/devices/cc13x2_cc26x2/driverlib/vims.h |   742 +-
 .../cc13x2_cc26x2/driverlib/watchdog.c        |    82 +-
 .../cc13x2_cc26x2/driverlib/watchdog.h        |  1040 +-
 .../cc13x2_cc26x2/driverlib/watchdog_doc.h    |   242 +-
 .../ti/devices/cc13x2_cc26x2/inc/asmdefs.h    |   302 +-
 .../ti/devices/cc13x2_cc26x2/inc/hw_adi.h     |  2364 +-
 .../cc13x2_cc26x2/inc/hw_adi_2_refsys.h       |   724 +-
 .../cc13x2_cc26x2/inc/hw_adi_3_refsys.h       |  1370 +-
 .../devices/cc13x2_cc26x2/inc/hw_adi_4_aux.h  |  1026 +-
 .../devices/cc13x2_cc26x2/inc/hw_aon_batmon.h |  1324 +-
 .../devices/cc13x2_cc26x2/inc/hw_aon_event.h  |  2270 +-
 .../ti/devices/cc13x2_cc26x2/inc/hw_aon_ioc.h |   316 +-
 .../devices/cc13x2_cc26x2/inc/hw_aon_pmctl.h  |  1250 +-
 .../ti/devices/cc13x2_cc26x2/inc/hw_aon_rtc.h |  1092 +-
 .../devices/cc13x2_cc26x2/inc/hw_aux_aiodio.h |  2060 +-
 .../devices/cc13x2_cc26x2/inc/hw_aux_anaif.h  |  1266 +-
 .../devices/cc13x2_cc26x2/inc/hw_aux_evctl.h  |  4710 +-
 .../ti/devices/cc13x2_cc26x2/inc/hw_aux_mac.h |  1496 +-
 .../ti/devices/cc13x2_cc26x2/inc/hw_aux_ram.h |    96 +-
 .../ti/devices/cc13x2_cc26x2/inc/hw_aux_sce.h |   796 +-
 .../devices/cc13x2_cc26x2/inc/hw_aux_smph.h   |   564 +-
 .../devices/cc13x2_cc26x2/inc/hw_aux_spim.h   |   478 +-
 .../devices/cc13x2_cc26x2/inc/hw_aux_sysif.h  |  4176 +-
 .../ti/devices/cc13x2_cc26x2/inc/hw_aux_tdc.h |  1758 +-
 .../cc13x2_cc26x2/inc/hw_aux_timer01.h        |  1222 +-
 .../devices/cc13x2_cc26x2/inc/hw_aux_timer2.h |  4982 +-
 .../ti/devices/cc13x2_cc26x2/inc/hw_ccfg.h    |  3868 +-
 .../cc13x2_cc26x2/inc/hw_ccfg_simple_struct.h |   162 +-
 .../devices/cc13x2_cc26x2/inc/hw_chip_def.h   |   468 +-
 .../ti/devices/cc13x2_cc26x2/inc/hw_cpu_dwt.h |  1712 +-
 .../ti/devices/cc13x2_cc26x2/inc/hw_cpu_fpb.h |   886 +-
 .../ti/devices/cc13x2_cc26x2/inc/hw_cpu_itm.h |  2244 +-
 .../cc13x2_cc26x2/inc/hw_cpu_rom_table.h      |   440 +-
 .../ti/devices/cc13x2_cc26x2/inc/hw_cpu_scs.h |  9578 +--
 .../devices/cc13x2_cc26x2/inc/hw_cpu_tiprop.h |   136 +-
 .../devices/cc13x2_cc26x2/inc/hw_cpu_tpiu.h   |   694 +-
 .../ti/devices/cc13x2_cc26x2/inc/hw_crypto.h  |  7932 +-
 .../ti/devices/cc13x2_cc26x2/inc/hw_ddi.h     |   394 +-
 .../devices/cc13x2_cc26x2/inc/hw_ddi_0_osc.h  |  2316 +-
 .../ti/devices/cc13x2_cc26x2/inc/hw_event.h   |  7376 +-
 .../ti/devices/cc13x2_cc26x2/inc/hw_fcfg1.h   |  5846 +-
 .../ti/devices/cc13x2_cc26x2/inc/hw_flash.h   |  6996 +-
 .../ti/devices/cc13x2_cc26x2/inc/hw_gpio.h    |  4494 +-
 .../ti/devices/cc13x2_cc26x2/inc/hw_gpram.h   |    96 +-
 .../ti/devices/cc13x2_cc26x2/inc/hw_gpt.h     |  3394 +-
 .../ti/devices/cc13x2_cc26x2/inc/hw_i2c.h     |  1456 +-
 .../ti/devices/cc13x2_cc26x2/inc/hw_i2s.h     |  1934 +-
 .../ti/devices/cc13x2_cc26x2/inc/hw_ints.h    |   240 +-
 .../ti/devices/cc13x2_cc26x2/inc/hw_ioc.h     | 23838 +++---
 .../ti/devices/cc13x2_cc26x2/inc/hw_memmap.h  |   360 +-
 .../ti/devices/cc13x2_cc26x2/inc/hw_nvic.h    |  2052 +-
 .../ti/devices/cc13x2_cc26x2/inc/hw_pka.h     |  1212 +-
 .../ti/devices/cc13x2_cc26x2/inc/hw_pka_int.h |   314 +-
 .../ti/devices/cc13x2_cc26x2/inc/hw_pka_ram.h |    96 +-
 .../ti/devices/cc13x2_cc26x2/inc/hw_prcm.h    |  5058 +-
 .../devices/cc13x2_cc26x2/inc/hw_rfc_dbell.h  |  3344 +-
 .../ti/devices/cc13x2_cc26x2/inc/hw_rfc_pwr.h |   306 +-
 .../ti/devices/cc13x2_cc26x2/inc/hw_rfc_rat.h |   396 +-
 .../devices/cc13x2_cc26x2/inc/hw_rfc_ullram.h | 61534 ++++++++--------
 .../ti/devices/cc13x2_cc26x2/inc/hw_smph.h    |  2910 +-
 .../devices/cc13x2_cc26x2/inc/hw_sram_mmr.h   |   300 +-
 .../ti/devices/cc13x2_cc26x2/inc/hw_ssi.h     |  1088 +-
 .../ti/devices/cc13x2_cc26x2/inc/hw_sysctl.h  |    98 +-
 .../ti/devices/cc13x2_cc26x2/inc/hw_trng.h    |  1218 +-
 .../ti/devices/cc13x2_cc26x2/inc/hw_types.h   |   245 +-
 .../ti/devices/cc13x2_cc26x2/inc/hw_uart.h    |  2174 +-
 .../ti/devices/cc13x2_cc26x2/inc/hw_udma.h    |  1150 +-
 .../ti/devices/cc13x2_cc26x2/inc/hw_vims.h    |   408 +-
 .../ti/devices/cc13x2_cc26x2/inc/hw_wdt.h     |   580 +-
 .../rf_patches/rf_patch_cpe_bt5.c             |   137 +-
 .../rf_patches/rf_patch_cpe_ieee_802_15_4.c   |    35 +-
 .../rf_patches/rf_patch_cpe_multi_bt5_coex.c  |  1495 +-
 .../rf_patches/rf_patch_cpe_multi_protocol.c  |   196 +-
 .../rf_patch_cpe_multi_protocol_hid.c         |  2039 +
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

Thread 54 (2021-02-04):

SW: MSP430: Add I2C device to MSP430, control LEDs and buzzer

jadonk, 2021-02-04:
The C3 board version should have I2C between CC1352 and MSP430. The MSP430 controls 2 LEDs and the buzzer. Access to these should be exposed via I2C slave device on MSP430 to I2C master on CC1352 to request LED or buzzer indications.

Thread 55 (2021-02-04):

SW: MSP430: simplify code via use of I2C

jadonk, 2021-02-04:
Make the CDC full logger/shell only by:
* Replace HDLC commands with I2C commands for wpan
* Update wpanusb_bc (new name?) to use I2C instead of HDLC
* Add HID endpoint to MSP430 for CC sw update (and update python script/west integration)

I'm a little confused on this suggestion as I2C would be quite a bit slower than UART. Using I2C for mode/control tasks makes a lot of sense, but I wonder how to have reasonable data throughput without keeping the WPAN data on UART.

@statropy would you like to elaborate on the proposal?

statropy, 2021-02-04:
UART baud rate is 115,200 and I2C is 100 kbit/s in Standard Mode. I'd consider those functionally equivalent. It looks like the MSP430 can also operate in I2C Fast Mode, which is 400 kbit/s.

jadonk, 2021-02-04:
But why can't we up the UART rate to 1Mbit? Are the ports that slow?

statropy, 2021-02-04:
I did a LOT of throughput testing on the UART. 115200 was the highest speed that would work reliably without data loss. It's not just the raw clocking of the bus, but servicing the interrupt and pulling the data out without Rx overflow. The UART interrupt handler is very small, but it has to compete with the USB interrupts also.

Pillar1989, 2021-02-09:
@statropy  Is it possible to increase the burn-in speed of the CC1352? Currently, it takes almost 30 seconds to burn in one time, maybe more.

statropy, 2021-02-09:
The serial bootloader method already detects 'blank' sections and skips those when programming, so it's as fast as it is going to get. If you want a faster update method, then using the SWD port with an external programmer like a JLink is your best option.

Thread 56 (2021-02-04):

SW: MSP430/CC1352: Have CC1352 trigger how the MSP430 enumerates

jadonk, 2021-02-04:
2 separate USB enumeration profiles, with/without WPAN based on CC I2C commands

@statropy I'm confused how this would be done in time if board power is done over USB. Would/could the MSP430 trigger a bus reset and re-enumerate?

statropy, 2021-02-04:
I would have the MSP430 delay enumeration until the CC1352 sends a configuration profile to the MSP430. At that time it would enumerate, with or without the WPAN interface. An additional benefit would be to re-enumerate when the CC1352 resets, (via button push or firmware update) so the WPAN Linux driver would also reset and resynch with the gateway application.

jadonk, 2021-12-23:
@vaishnav98 Can we use the BOOT pin and I2C for this? I think the BOOT pin always needs to be MSP430->CC1352. The CC1352 could update the MSP430 with its status, however, over I2C. Maybe we need to think of this in more general terms.

vaishnav98, 2021-12-23:
It should be possible to use the BOOT pin as an interrupt for the I2C slave so that MSP430 can trigger I2C reads from CC1352, yes CC1352->MSP430 communication should be easy over the I2C, will try implementing this approach and we can review

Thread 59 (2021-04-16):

HW: Add way to disable on-board sensors

jadonk, 2021-04-16:
We need a way to change the base address of those sensors that can change (HDC2010) and/or disable sensors when their I2C address conflicts with off-board sensors. It would just be too frustrating for someone to not be able to use the sensor of their choice.

cc @Pillar1989 @FionaYu20180326

FionaYu20180326, 2021-04-16:
There are 3 ways we can do this. Which would you prefer?
1> Make a wire line on PCB and let users cut it, by cutting the line, they can chose which I2C port to use.
2> Use a resistor. Users can solder or dis-solder the resistor to chose which I2C port to use.
3> Add a analog switch and use MPS430 GPIO to control it. But may raise cost.

jadonk, 2021-04-21:
How about we use DIO_16 and DIO_17 for on-board I2C and restrict our JTAG support to 2-wire (SWD), which is the boot configuration anyway?

FionaYu20180326, 2021-04-23:
I will use current TI TS5A23157RSER as analog switch.

Pillar1989, 2021-04-25:
@jadonk  @FionaYu20180326  If we want to move quickly to the C4 version, there are three more things we need to determine at this point. I think the C4 version must be the last one. Or would it be better if we call it version C3.1?

- Antenna selection and suppliers. 14db requires 1pcs antenna, 20db requires 2pcs antennas. How many antennas inside the final package?
- About Sensor, how do we handle I2C addresses? Do we need to consider powering off the Sensor, under the ultra-low power mode?
- The current C3 version, during our testing there were power problems, when we used different power banks, the difference in signal strength was obvious, and in the worst case, using an external antenna, the communication distance was only 30 meters. @FionaYu20180326

jadonk, 2021-04-25:
> @jadonk @FionaYu20180326 If we want to move quickly to the C4 version, there are three more things we need to determine at this point. I think the C4 version must be the last one. Or would it be better if we call it version C3.1?

Please use C4 as the revision.

>
>     * Antenna selection and suppliers. 14db requires 1pcs antenna, 20db requires 2pcs antennas. How many antennas inside the final package?

Minimum required to reach 1km @ 1kbps. If we can do it with 1 14dB antenna, then let's do that. If we can do it with a shared antenna for 20dB TX and 14dB RX, then let's do that. If we must add 2 antennas to support 20dB and that is needed to reach 1km, then let's do that.

>
>     * About Sensor, how do we handle I2C addresses? Do we need to consider powering off the Sensor, under the ultra-low power mode?

Let's not try to add support for ultra-low power mode. The power is low enough for initial product.

TS5A23157RSER lists for $0.20. I don't think we need SPDT. We can just disable the on-board sensors by using SPST, like TS5A2066 which lists for only $0.13 and has fewer pins.

>
>     * The current C3 version, during our testing there were power problems, when we used different power banks, the difference in signal strength was obvious, and in the worst case, using an external antenna, the communication distance was only 30 meters. @FionaYu20180326

We should have reasonable on-board regulation with U3, C14, C45. Do you have any traces of supply noise? Our currents should be pretty low compared to what is provided by USB power sources. I'm having a hard time imagining why it would impact signal strength other than adding noise. Can you try to give me some theory?

jadonk, 2021-11-10:
There needed to have been a pull-up on the SEN_SDA/SEN_SCL side of the switch such that the SDA/SCL lines on the sensors didn't float and cause possible confusion. I'm concerned this could cause on-board sensor failure.

GuoqingLing2589, 2021-11-11:
> There needed to have been a pull-up on the SEN_SDA/SEN_SCL side of the switch such that the SDA/SCL lines on the sensors didn't float and cause possible confusion. I'm concerned this could cause on-board sensor failure.

We have added pull-up resistors to the analog switch inputs. The pull-up resistor comes into play when communication with the on-board sensor is required, pulling up the SEN_SDA/SCL. So there is no need to add pull-ups on the SEN_SDA/SEN_SCL side.

jadonk, 2021-11-12:
@GuoqingLing2589 the issue is that when you disconnect the SEN_SDA/SEN_SCL side from the pull-ups, the sensors can get into an unknown state. When you reconnect them, the sensors interfere with the I2C communications.

jadonk, 2021-11-12:
@GuoqingLing2589 Immediate issue issue may have been related to the scope probes. When I remove them, they start working. However, I think this possible failure mode is real.

jadonk, 2021-12-05:
Seems to be working well enough, but if we do any updates, we should put weak pull-ups on the sensor-side as well.

GuoqingLing2589, 2021-12-09:
Okay, we'll add it. Then jumper test it.

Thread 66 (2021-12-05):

Case: need to finalize silkscreen

jadonk, 2021-12-05:
We need a reviewed silkscreen/etch with:
* BeagleBoard.org logo
* LED indication (current schematic definition isn't accurate)
* Button labels
* MikroBUS labels

jadonk, 2021-12-13:
@GuoqingLing2589 @FionaYu20180326 Do you have any plans to create the silkscreen for the case/enclosure?

GuoqingLing2589, 2021-12-14:
Sure, what do you think of the effect of the picture below?
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

jadonk, 2021-12-21:
It looks good. Need to double-check pin positions and align with official mikroBus specification for sockets on both sides. Need to add "beagleconnect" and "freedom" below beagleboard.org.

GuoqingLing2589, 2021-12-22:
Okay, got it.

GuoqingLing2589, 2021-12-24:
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
Please see the new rendering.

jadonk, 2021-12-24:
@GuoqingLing2589 Please put "BeagleConnect" and "Freedom" on separate lines to make the text bigger. We have a lot of blank space. :-)

GuoqingLing2589, 2021-12-29:
So is this okay?
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

jadonk, 2022-01-06:
I'd go ahead and expand "Freedom" to be the full width of the available space. Also, "Connect" in "BeagleConnect" could be a different color.

GuoqingLing2589, 2022-01-17:
What about this look?
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

jadonk, 2022-01-20:
* Can you add ® marks to both the BeagleBoard.org logo and "BeagleConnect"?
* Do you have any markings for the RESET and BOOT/USER buttons?
* Do you have a similar set of markings for the backside?
* I think we need some indication of which mikroBUS. On "top", the side with the USB connector, LEDs, buttons, and MSP430, that is mikroBUS *1*. On "bottom", the side with the CC1352 and battery connector, that is mikroBUS *2*.

GuoqingLing2589, 2022-01-21:
- Okey, we will add it.
- We have added silkscreen to the RESET and BOOT/USER buttons.
- for the backside, it have the same silkscreen.
- Okey.
We will finish it as soon as possible and send you the renderings.

GuoqingLing2589, 2022-01-24:
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
We finished it, but there is a problem that the ® is too small and not obvious if we follow the trademark specification.

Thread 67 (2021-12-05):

HW (rev C5): UART pins to mikroBUS headers have swapped TX/RX

jadonk, 2021-12-05:
According to the [mikroBUS specification](https://download.mikroe.com/documents/standards/mikrobus/mikrobus-standard-specification-v200.pdf), the socket labels are based on the perspective of the MCU, meaning the RX pin on the socket in the following diagram should be connected to the RX pin on the MCU.

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

This is described in more detail in the section below showing how add-on boards should be labelled and connected in the opposite way.

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

This could be swapped in software, except the bootloader is configured in the alternate manner, as well as the connection to the MSP430.

Hey @vaishnav98, wouldn't you have seen this issue on the GPS/GNSS Click boards?

cc @ChrisGammell @statropy @Pillar1989 @FionaYu20180326

GuoqingLing2589, 2021-12-08:
Hello Jason, according to the master and slave devices has different to silkscreen, we recommend using the master device silkscreens on the front of the BeagleConnect and the slave device silkscreens on the back. Do you think it is feasible?

jadonk, 2021-12-09:
No, it should be socket/master in both cases. The socket is female, the add-on board uses male.

GuoqingLing2589, 2021-12-13:
Okay, got it

jadonk, 2021-12-13:
I don't believe the CC1352 has an easy way to detect the status of MB1_CTRL. It seems that this could cause some potential for device damage. We can do some monitoring of RX before we enable TX on the CC1352, but USB could be hot-plugged, resulting in the CC13520 TX being connected to MSP430 TX.

I'm unclear when this could be fixed in hardware--ie., can this be fixed before the larger production run. First-pass pilot run is already done.

GuoqingLing2589, 2021-12-17:
We have tested it and there are no problem. We will continue the aging test this week and give you the results next Monday.

GuoqingLing2589, 2021-12-22:
After the aging test, there is indeed a problem, is dealing with the problem.

GuoqingLing2589, 2021-12-28:
We switched the Pin 13 and Pin 14 wires on the J4 holder to avoid this problem, as follows:
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

jadonk, 2021-12-28:
OK. We'll need to have some version indication so we can apply the software work-around.

GuoqingLing2589, 2021-12-30:
I think we could change the hardware schematic version from C5 to C6 and send you the latest schematic, can we？

jadonk, 2022-01-06:
Schematic is good, but we need some software indication so that the old hardware can still work, I think.

Closed 2022-01-08.

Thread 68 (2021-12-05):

HW (rev C5): 2.4G LED cannot be used

jadonk, 2021-12-05:
Because the signal for this LED is the same signal as to the RF switch, it cannot be used in software. Further, it cannot reflect a valid antenna state as the signals that would enable this are not populated according to the schematic.

On the MSP430, the signal on pin 1 (P6.0/CB0) is available to control this LED. Otherwise, it is also possible to recover the signal fed to the antenna switch, since it has no valid use without the RF connection.

GuoqingLing2589, 2021-12-09:
Hello Jason, after our test, the LED is able to light up when 2.4G is on. Do you want the LED to achieve another function?

jadonk, 2021-12-09:
Wouldn't that interfere with the SubG radio signal? The path is mostly not populated, but it would adjust the signal to the u.fl.

GuoqingLing2589, 2021-12-13:
The external antenna is 50Ω impedance model does not need to do impedance matching, so our board is reserved for the empty paste position, and the use of 0201 package, the empty paste position does not interfere with the Sub G signal transmission.

jadonk, 2021-12-13:
so, we can enable/disable this signal without interference with the radio? This is confusing, but that seems OK. I'll re-enable that LED in the code, but we'll likely want to label it different on the enclosure silkscreen.

GuoqingLing2589, 2021-12-15:
LED can be restored to use without affecting the RF function, but to remove the resistor R58, which is in mass production when the air paste on the line. But LED silkscreens because the location is not enough to do special labeling.
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

jadonk, 2021-12-21:
I mean the silkscreen on the enclosure.

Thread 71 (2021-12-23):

SW:  Need to visually differentiate BCF node .bin files on node

erikwelsh, 2021-12-23:
Currently, all the BCF bin files have the same LED pattern on the node.  To make it easier to understand what bin file is programmed on each node, please change the LED pattern for each bin file.

Given that there are 6 LEDs on a node, you could binary encode which bin file it is using the LEDs.  For example:

gateway:  000001
sensortest:  000010
greybus:  000011

or you could do a one-hot pattern or something else.  When you have updated the bin files, please document what each LED pattern means.

jadonk, 2022-01-08:
I'd like to assign functional meaning to each LED and try to infer the running application from that.

There is a total of 6 LEDs. I believe they are in the order of CHG, 2.4G, 900M, 3V3, LED1 and LED2.

## CHG (A)
The mode of this cannot be changed. It is on when an attached battery is being charged.

## LED 2.4G (B)
This is the only one available on CC1352. I'd like to use it for things where low-overhead and low-latency matter. I think having it on when some kind of "link" is established and to blink when there is some data transfer. The easiest place I know to hook to is when the TX is active, but I don't want to miss blinking when we have noticed some RX. I may hook in TX initially and RX later. I am not aware of any "link" establishment for IEEE802.15.4 so this will require some research.

## 900M (C)
### Now
I've been using this LED to reflect the UART mux between the MSP430 and CC1352. I might want to add blinking in the case of data transfer. Currently, if **gateway** is functional, this LED should be on. This doesn't say if **gateway** is waiting for a connection over USB.

### Proposal
I think I'd like to add to the CC1352 something that says it is actively looking for a **gateway** connection. In the future, this will all be modes rather than different firmware loads. So, if the firmware is _not_ acting as a node and _is_ waiting for a host driver connection to act as a gateway, this LED should toggle slowly based on commands from the CC1352. If the UART mux is flipped to the MSP430, it should turn it on most of the time with short/fast blinks in the case of data transmission either way (not ideal to not have both TX/RX LEDs, but it is what we have. It would not be possible to distinguish between **gateway** (acting as **bcfserial** w/o the USB connection) and node operation via this LED.

## 3V3 (D)
When there is power, this is on. No way to change that.

## LED1 (E)
### Now
I've been using this for MSP430 debug to indicate an established UART connection (either passthrough or HDLC mode). This would typically be on only when there is a USB connection.

### Proposal
Both **sensortest** and **greybus** could use this LED. I'll need to think about what they might do with it and how to make up for the loss of debug information for HDLC, but, for now, they can simply turn it on and not have **gateway** or **bcfserial** turn it on.

## LED2 (F)
Why don't we use this to reflect **greybus** activity? If blinking slowly, it could mean looking for activity, meaning this is only used in the **greybus** build. Steady-on could reflect some higher-level activity, such as once a manifest has been fetched. Either after some time-out or if there is some other kind of disconnection event, it could go back to the slowly blinking state. No other firmware load should turn this LED on.

To simplify implementation, the MSP430 should perform the slow-blink operation. Due to the I2C latency, we should likely avoid any quick updates based on individual packets.

# Summary
All of this might result in a lot of blinking lights. I think there is a lot of information to consider and dynamic status will help users tell what is going on, given that we have no display for status. Do you think this is overwhelming, or can this be a workable plan?

jadonk, 2022-01-08:
Below is what I just proposed, but I'm concerned it doesn't have separate sensor status indication for both sides of the connector.

@vaishnav98 @erikwelsh - What would you think if I combined Greybus/Sensor into one indicator, but separate for each like:

## 1/2
1 or 2 on
: Sensor identified and Greybus connection established

1 or 2 off
: No sensor identified and not seeking Greybus connection

1 or 2 fast blink
: Greybus or other sensor traffic for corresponding sensor

1 and 2 fast blink
: Greybus or other sensor traffic for internal sensor

1 and 2 slow blink
: Seeking a Greybus connection

1 or 2 slow blink
: Sensor error on corresponding header

Not too complicated? Give the right information?

--

# LED definition

These definitions are proposed with the mindset of giving end-users high-level functional
status indication of the devices and nodes. It seeks to avoid having the status of any
one LED being required to interpret another, which has the undesirable effect of limiting
the amount of information that can be conveyed, but should simplify interpretation.

Single letter abbreviations are provided in case we can put these on a silkscreen on the
side of the case.

## Positions

TBD - I need to determine for sure where each LED is on the board and make it clear in this document.

## Functions

### C (Charging)

On
: Attached battery is being charged

Off
: Charger is not active

### L (Link)

On
: IEEE802.15.4 SubGHz connection established (RX occurred recently)

Fast blink
: IEEE802.15.4 SubGHz data TX or RX

Off
: IEEE802.15.4 SubGHz traffic not seen for some timeout period

Slow blink
: IEEE802.15.4 SubGHz connection error detected

### H (Gateway/Host)

On
: Device is in _gateway_ mode

Fast blink
: USB UART data traffic over MSP430

Off
: Device is in _node_ mode

Slow blink
: MSP430 is looking for a _gateway_ connection (USB active), but the CC1352 has not set the MSP430 clearly in _gateway_ or _node_ mode

### P (Power)

On
: Device is powered

Off
: Device is not powered

### S (Sensor)

On
: TBD

Fast blink
: Sensor traffic

Off
: TBD

Slow blink
: Sensor error

### G (Greybus)

On
: Greybus connection is active

Fast blink
: Greybus traffic

Off
: Greybus connection is inactive

Slow blink
: Greybus connection being attempted, but not completed

jadonk, 2022-01-08:
OK, might be useful to read this history, but I updated my proposal: https://github.com/jadonk/beagleconnect/commit/49c5539a52233f9ae5a751f95311e5e19fa50702

jadonk, 2022-05-05:
Greybus node - U off,1/2 slow/fast/on (not off)
Gateway - U slow/fast/on (not off), 1/2 off
Sensortest - U off, 1/2 off

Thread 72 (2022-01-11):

SW: BeagleBone based flashing of MSP430

jadonk, 2022-01-11:
Have a pre-installed Debian package to flash the MSP430. I've got instructions to build the virtualenv at https://github.com/jadonk/ti_msp430_python_tools/blob/main/README.md. I'd like that virtualenv to be installed so it can be used in an MSP430 programming script such as called in the usb_uart_bridge Makefile (https://github.com/jadonk/msp430F55xx_usb_uart_bridge/blob/master/Makefile#L140).

RobertCNelson, 2022-05-12:
@jadonk

```
i've added a new package to help program the msp430 on the Beagle's...
sudo apt update
sudo apt install beagleconnect-msp430
Device has to be in bootloader mode... (remove usb cable, hold down boot button, insert cable..)
Not-Okay
root@BeagleBone:~# lsusb | grep 2047
Bus 001 Device 004: ID 2047:0aa5 Texas Instruments BeagleConnect
Okay:
root@BeagleBone:~# lsusb | grep 2047
Bus 001 Device 005: ID 2047:0200 Texas Instruments MSP430 Bootloader
To update run:
python2.7 -m msp430.bsl5.hid_1 -e -P /usr/share/beagleconnect/msp430/usb_uart_bridge.hex
```

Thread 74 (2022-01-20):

HW: UART_0 pins are swapped on the mikroBUS connector

jadonk, 2022-01-20:
This is true for rev C5. I believe rev C6 addresses this issue already. We need the design released for C6.

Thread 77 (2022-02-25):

Ideas on Building at west zephyr-export and Receiving Errors on the Build

silver2row, 2022-02-25:
I am trying to build the /blinky application and port it to the Rev. C5 from the BBGG

I have researched specifics in the ZephyrProject, the communication aspects to the file system for Zephyr, and I am just starting to handle the ideas circulating around cc1352R and the M4F onboard the BeagleConnect.

I have been following along for now until I can make a break in the ` case `. Here:

```

pip3 install -U west
cd
west init -m https://github.com/jadonk/zephyr --mr bcf-sdk-0.0.5 bcf-zephyr
west update
west zephyr-export
pip3 install -r zephyr/scripts/requirements-base.txt

```

This seems a bit odd to me, e.g. as I cannot use ` west ` to ` update ` or ` zephyr-export ` outside of the ` bcf-zephyr ` directory on the BBGG.

I tried to make a closed environment via ` venv ` so far. I tried to move on and rekindle the advancement of the ` west update/zephyr-export ` outside of the bcf-zephyr build directory.

The first time I tried it, the build instructions, I got a hang up at installing the binary but only after moving on from not building with ` west update/zephyr-export ` outside of the ` bcf-zephyr ` directory. I built everything, including the ` requirements-base.txt ` file, inside of the ` bcf-zephyr ` dir.

I think that the binary is already on the C5 board and already flashed for this BeagleConnect. I expected to run through some details on how to achieve a way to flash binaries to the BeagleConnect. I also expected to move past this attempt to flash the BeagleConnect to try to start my own flashing instances.

silver2row, 2022-02-27:
Hello,

Is there a .dtsi file yet for the M4F?

Seth

silver2row, 2022-07-07:
Hello,

I have brought up this idea before today. I am building again and again. Here is the issue w/ cmake so far which I have been trying to figure out. So far, so not so good. I have not been able to move beyond: ` west zephyr-export `.

Seth

P.S. Oh! Here is the error in case others are working to fix this issue: ` FATAL ERROR: command exited with status 1: /usr/bin/cmake -P /home/debian/bcf-zephyr/zephyr/share/zephyr-package/cmake/zephyr_export.cmake `

I can only look at the files so far and through looking, I have found nothing in particular that warrants a ` FATAL ERROR `. Someone told me that people have moved on from this error but I have not moved on.

silver2row, 2022-07-07:
Hello again...

So, this command: ` west zephyr-export `

Creates this issue: ` FATAL ERROR: command exited with status 1: /usr/bin/cmake -P /home/debian/bcf-zephyr/zephyr/share/zephyr-package/cmake/zephyr_export.cmake `

If I remove that command from the build, this happens:

```
CMake Error at /home/debian/bcf-zephyr/zephyr/cmake/app/boilerplate.cmake:25 (find_package):
  Could not find a configuration file for package "Zephyr" that is compatible
  with requested version "".

  The following configuration files were considered but not accepted:

    /opt/source/bcf-zephyr/zephyr/share/zephyr-package/cmake/ZephyrConfig.cmake, version: unknown

Call Stack (most recent call first):
  /opt/source/bcf-zephyr/zephyr/share/zephyr-package/cmake/ZephyrConfig.cmake:24 (include)
  /opt/source/bcf-zephyr/zephyr/share/zephyr-package/cmake/ZephyrConfig.cmake:35 (include_boilerplate)
  CMakeLists.txt:4 (find_package)

CMake Error at CMakeLists.txt:4 (find_package):
  Found package configuration file:

    /opt/source/bcf-zephyr/zephyr/share/zephyr-package/cmake/ZephyrConfig.cmake

  but it set Zephyr_FOUND to FALSE so package "Zephyr" is considered to be
  NOT FOUND.

-- Configuring incomplete, errors occurred!
FATAL ERROR: command exited with status 1: /usr/bin/cmake -DWEST_PYTHON=/usr/bin/python3 -B/home/debian/bcf-zephyr/build/blinky -S/home/debian/bcf-zephyr/zephyr/samples/basic/blinky -GNinja -DBOARD=beagleconnect_freedom
```

I am not sure exactly what to do as of now w/ this build.

Seth

P.S. Um, if someone has figured it out, please advise me so I can move forward. I will keep on trying.

Closed 2022-09-18.

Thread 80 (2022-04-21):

SW: Usermode Linux for testing Greybus code

jadonk, 2022-04-21:
# What I'm trying to accomplish
* Enable crashes in greybus/gbridge code to not crash the system
* Validate code
* Create automated test benches that can run in CI
* Run test code in a container to normalize the build environment
* Create releases as an executable, such that we might be able to make applications

Note that User Mode Linux (UML) doesn't accomplish something I'd really like, which is the ability to make iPhone apps that could interact directly with BeagleConnect sensors. Android, however, might be possible, depending on the kernel dependencies and overall it allows better isolation.

The UML performance is also of concern, but our sensor interface example is more about code maintenance simplification and should not need very much performance which is likely to be network bound anyway.

# What I researched
* https://www.kernel.org/doc/html/latest/virt/uml/user_mode_linux_howto_v2.html
* http://user-mode-linux.sourceforge.net/
* https://git.kernel.org/pub/scm/linux/kernel/git/torvalds/linux.git/tree/arch/x86/um
* https://en.wikipedia.org/wiki/User-mode_Linux

From what people say, it only works on x86, but I've seen builds of `uml-utilities` on Debian/Ubuntu for ARM, so it seems there's some starting elements on the host-side kernel. The package `user-mode-linux` doesn't seem to be in any distros. It is unclear to me how much needs to be enabled in the host kernel.

# What I tried
Not much yet

# What happened
Nothing yet

# What I expect to happen
I need to put more here, but essentially run a Docker container with a Linux kernel and all the sensor drivers in it that "just works" and can be tested with network-based sensor simulations or the real deal.

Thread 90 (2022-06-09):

SW: Upstream wpanusb

jadonk, 2022-06-09:
https://elinux.org/BeagleBoard/GSoC/Ideas-2022#Upstream_wpanusb_and_bcfserial

These are the drivers that are used to enable Linux to use a BeagleConnect Freedom as a SubGHz IEEE802.15.4 radio (gateway). They need to be part of upstream Linux to simplify on-going support. There are several gaps that are known before they are acceptable upstream

Some notes from Stefan Schmidt:

1. The wpanusb linux driver is missing quite a few driver ops (listen before talk, set frame retries). I added rough sketches but these are non functional due to 2.
2. The zephyr firmware side needs to implement these ops as well and hook it up to the zephyr radio_api
3. A way to read the permanent extended address from the device to use in Linux is needed
4. The generic aspect of the firmware driver combo is missing completely. Band, supported channel, power levels, etc is all hard-coded in the linux driver and not queried from the device firmware. Its not even giving the page on which a channel is being set when changing it.
5. More driver ops are coming in right now as there is heavy work towards support management frames as well as active and passive scanning on the Linux stack. Which means these would need proper handling on the firmware side as well.

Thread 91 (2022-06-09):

SW: Greybus for Zephyr updates

jadonk, 2022-06-09:
https://elinux.org/BeagleBoard/GSoC/Ideas-2022#Greybus_for_Zephyr_Updates

https://elinux.org/BeagleBoard/GSoC/2022_Proposal/GreybusforZephyrUpdates

Support all the relevant peripherals(SPI, UART, PWM, ADC, GPIO IRQ) on BeagleConnect Freedom on Greybus for Zephyr, this requires adding platform specific changes to enable the protocols and interface to the existing NuttX sources, once the protocols are tested over greybus-for-zephyr, the mikrobus kernel driver needs to be updated to be able to support mikrobus add-on boards on these buses. An ideal end goal for the project would be to test one mikrobus add-on board of each category over greybus with the corresponding device driver in kernel.

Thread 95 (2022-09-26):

SW: linux/wpanusb : memory leak ?

Carton32, 2022-09-26:
Hi,

I'm using kernel 4.14.112 on a Raspberry Pi built with Yocto and your `wpanusb` kernel module. I've noticed that each time I perform a cycle of ifdown -> hard reset of MCU -> ifup, I get 2 memory leak reported by KMEMLEAK. I've spent several days to try to figure out what could cause this without success.

More details here: https://stackoverflow.com/questions/73743268/wpanusb-kernel-module-unable-to-find-memory-leak-in-probe-function-usb

Did you also notice this ? It doesn't seem to be a false positive as I've tried to perform thousands of ifup/ifdown in a script over 24h and my device ended up being freeze with a black screen after a single touch on it.

jadonk, 2022-11-11:
Thanks for the report. I'm in the process of rebasing and upstreaming and there are a lot of todos left on `wpanusb`. I'll dig into it.

Carton32, 2022-12-08:
Thank you very much. I will keep an eye on the updates!

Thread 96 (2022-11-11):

HW: 2.4G LED and mux control

jadonk, 2022-11-11:
Is R58 populated? It seems like it shouldn't be, since the antenna path through the mux isn't populated and I can only see it causing problems. If it is populated, I think the 2.4G LED should never be used.

Also, the latest schematic doesn't reflect the updated silkscreen for the LED labels.

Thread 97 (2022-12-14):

SW: production CC1352P7 firmware

jadonk, 2022-12-14:
- [ ]: Micropython shell should be possible to open via serial
- [ ]: FOTA/mcuboot: must be able to update firmware wirelessly
- [ ]: Sensortest app (python version) should run by default, broadcasting UDP packets of sensor data
- [ ]: Greybus app should be triggered by BeaglePlay packet
- [ ]: LEDs should respect the LED.md specification
- [ ]: Need MSP430 driver to control speaker and LEDs from Zephyr

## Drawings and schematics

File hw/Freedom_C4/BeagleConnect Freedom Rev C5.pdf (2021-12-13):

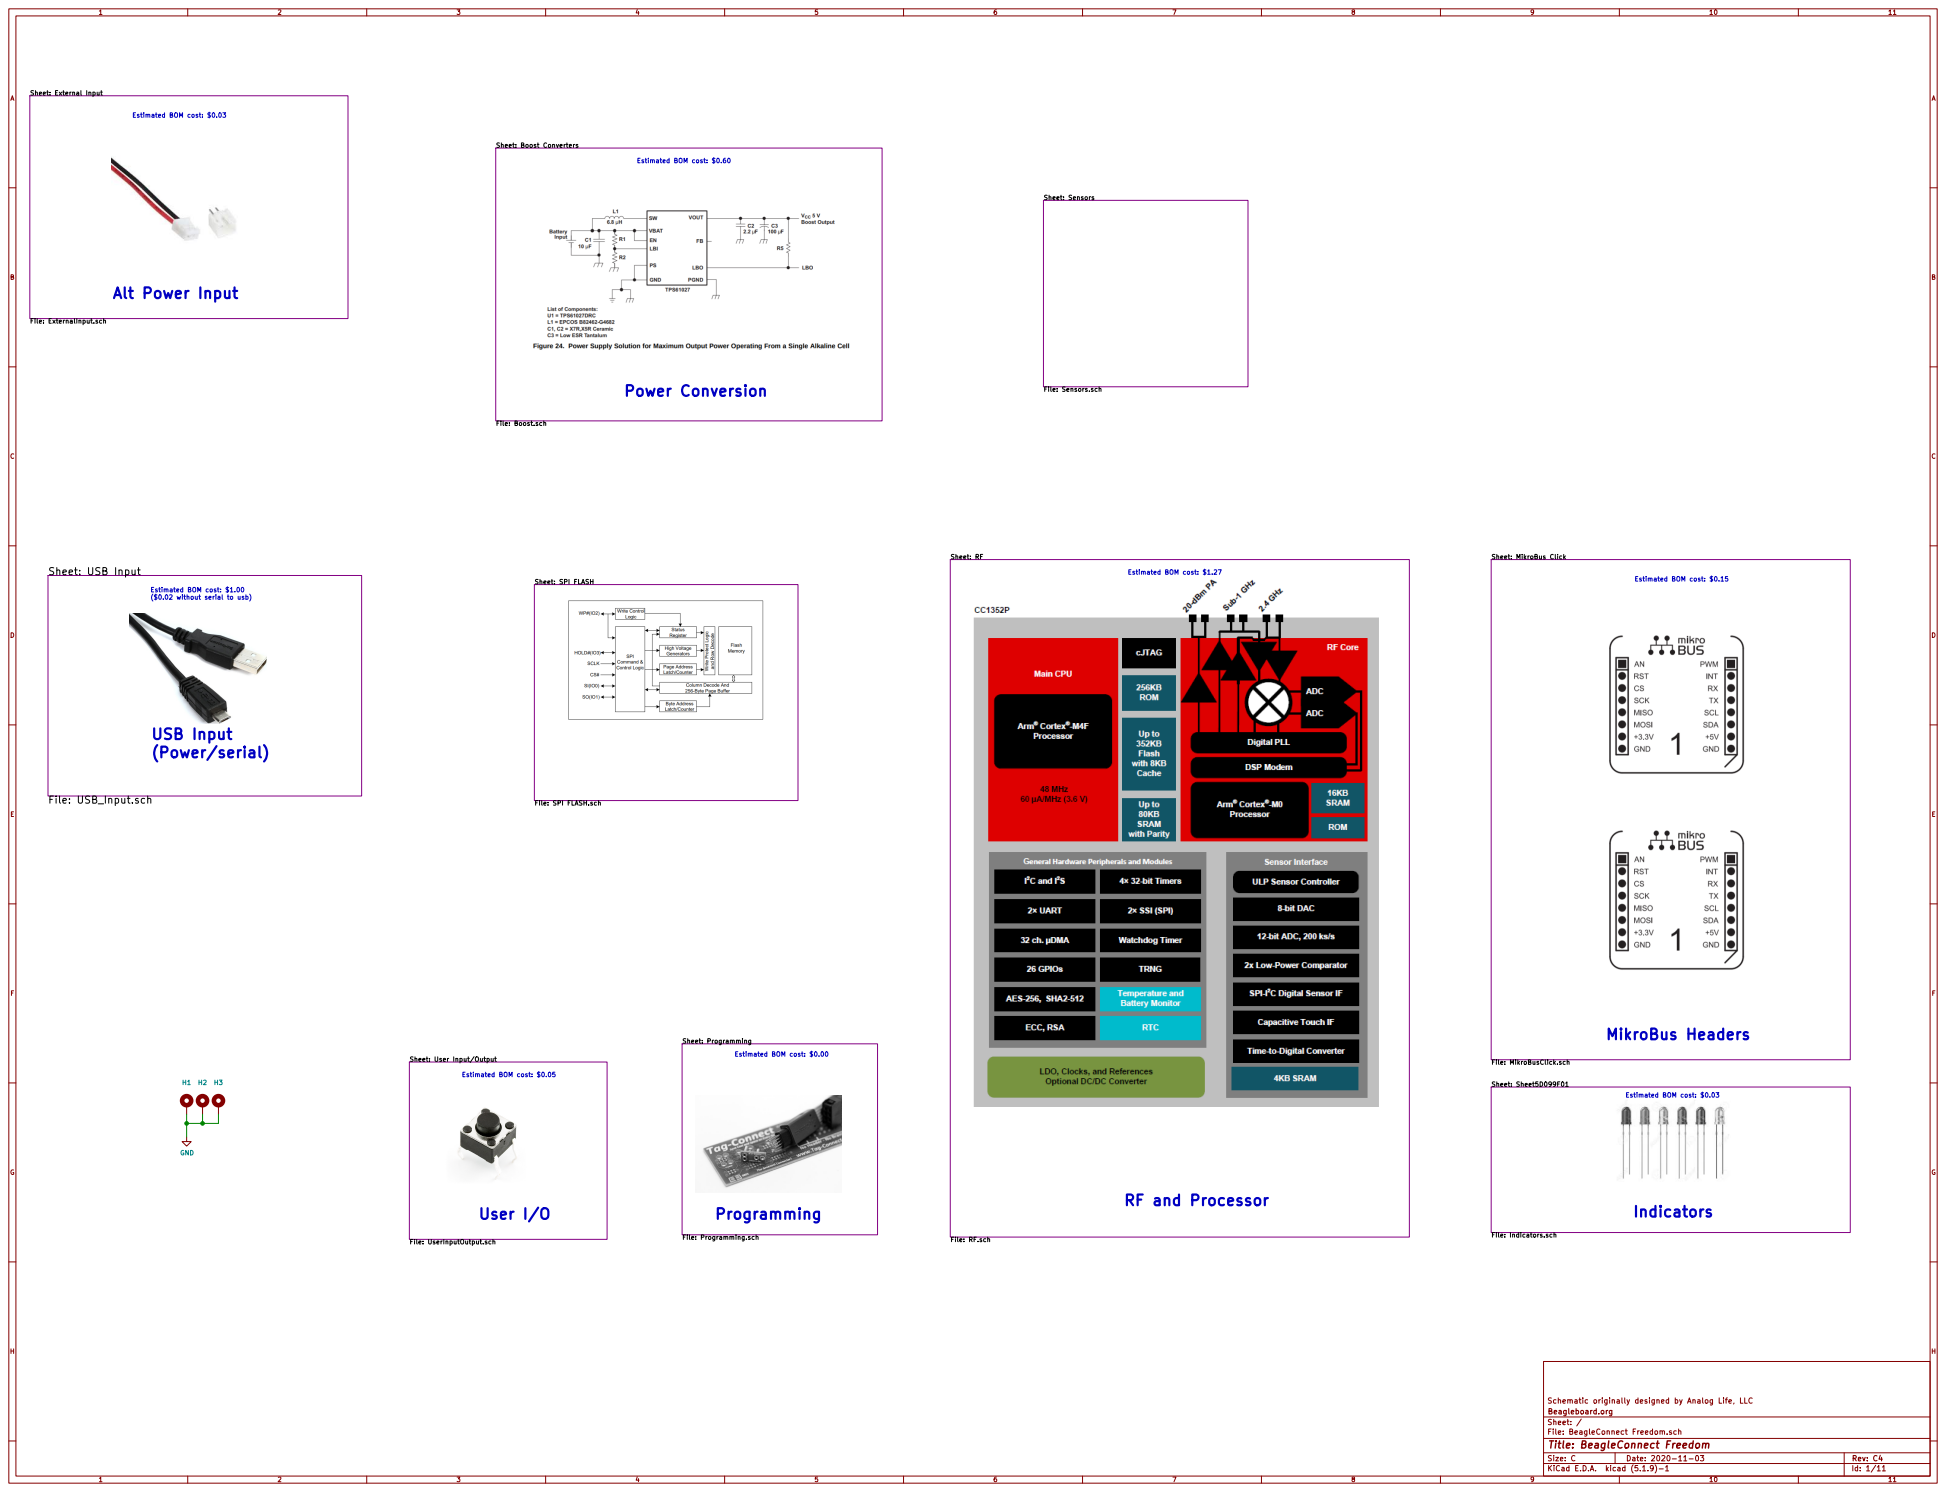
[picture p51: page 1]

Estimated BOM cost: $0.03 USB Input

Sheet: Sensors File: Sensors.sch Sheet: SPI FLASH

Estimated BOM cost: $1.27 Estimated BOM cost: $1.00

File: SPI FLASH.sch

File: RF.sch Sheet: User Input/Output

Sheet: Sheet5D099F01 File: Indicators.sch GND

Schematic originally designed by Analog Life, LLC
File: BeagleConnect Freedom.sch Sheet: / Beagleboard.org

Id: 1/11 Title: BeagleConnect Freedom

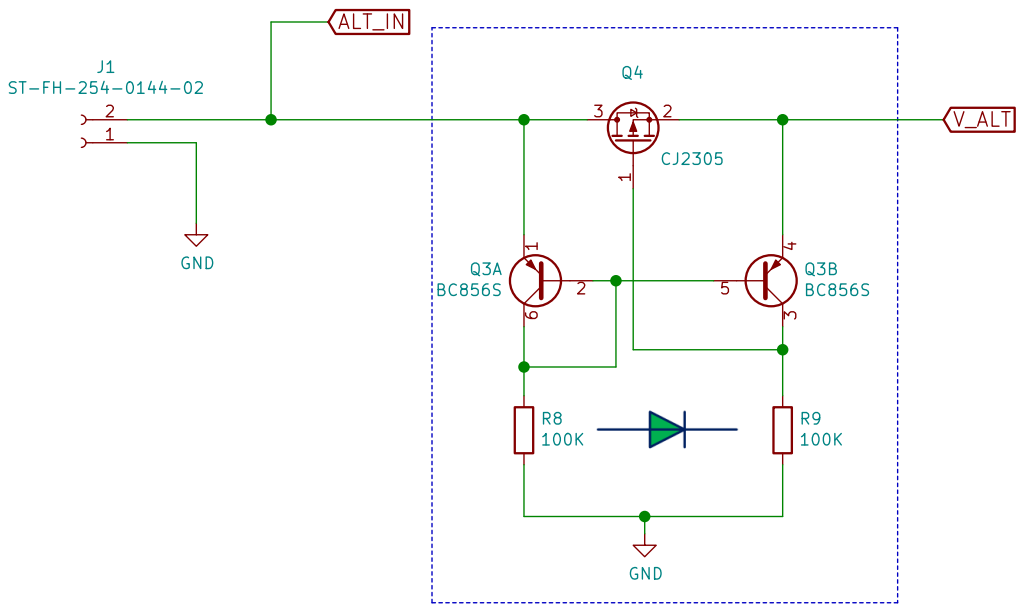
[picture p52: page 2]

Schematic originally designed by Analog Life, LLC
Beagleboard.org
Sheet: /External Input/
File: ExternalInput.sch
Id: 2/11 Title: BeagleConnect Freedom

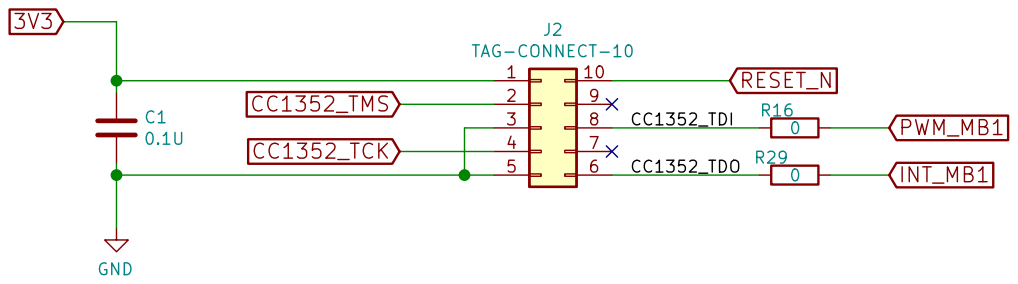
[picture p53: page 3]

Schematic originally designed by Analog Life, LLC
Beagleboard.org
Sheet: /Programming/
File: Programming.sch
Id: 3/11 Title: BeagleConnect Freedom

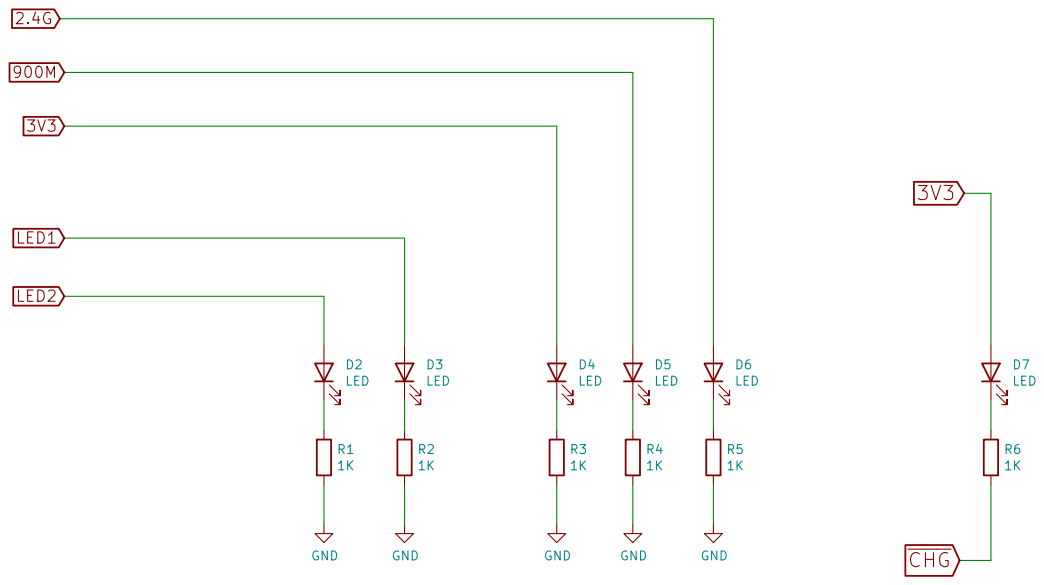
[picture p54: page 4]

Schematic originally designed by Analog Life, LLC
File: Indicators.sch Sheet: /Sheet5D099F01/ Beagleboard.org

Id: 4/11 Title: BeagleConnect Freedom

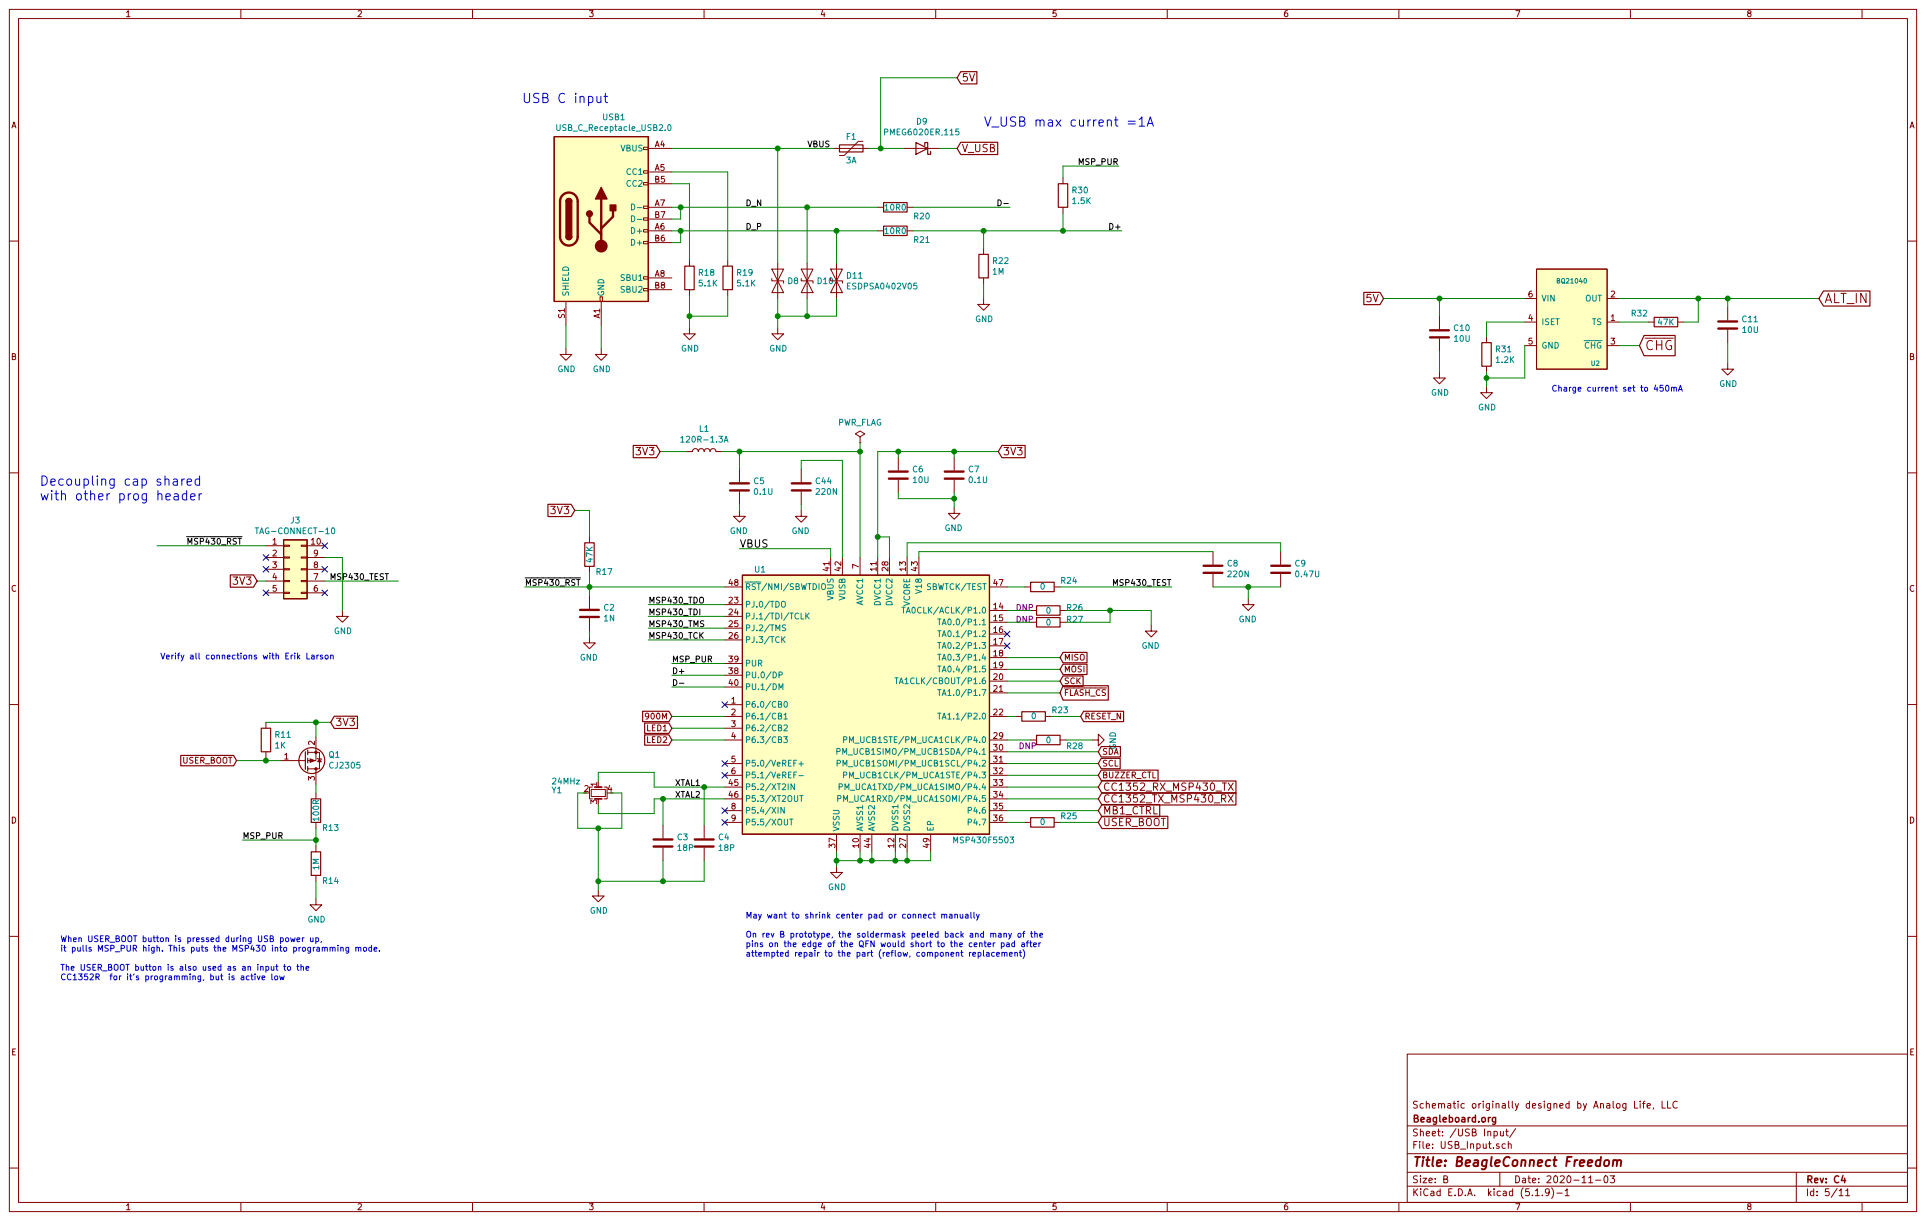
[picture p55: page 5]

Charge current set to 450mA

Decoupling cap shared
with other prog header

Verify all connections with Erik Larson

May want to shrink center pad or connect manually

When USER_BOOT button is pressed during USB power up,
it pulls MSP_PUR high. This puts the MSP430 into programming mode.

On rev B prototype, the soldermask peeled back and many of the
pins on the edge of the QFN would short to the center pad after
attempted repair to the part (reflow, component replacement)

The USER_BOOT button is also used as an input to the
CC1352R for it's programming, but is active low

Schematic originally designed by Analog Life, LLC
Beagleboard.org
Sheet: /USB Input/
File: USB_Input.sch
Id: 5/11 Title: BeagleConnect Freedom

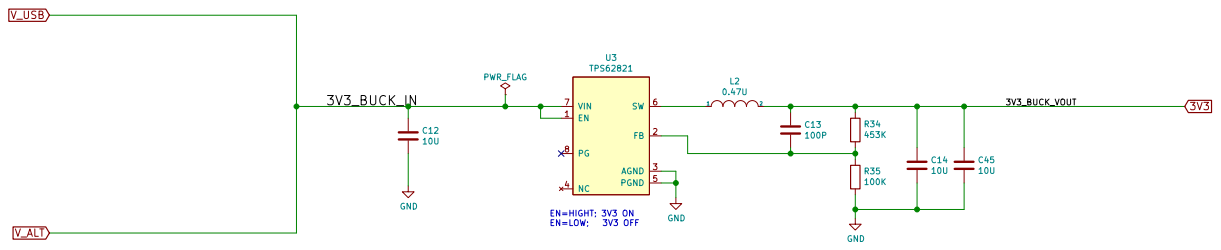
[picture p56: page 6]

Schematic originally designed by Analog Life, LLC
File: Boost.sch Sheet: /Boost Converters/ Beagleboard.org

Id: 6/11 Title: BeagleConnect Freedom

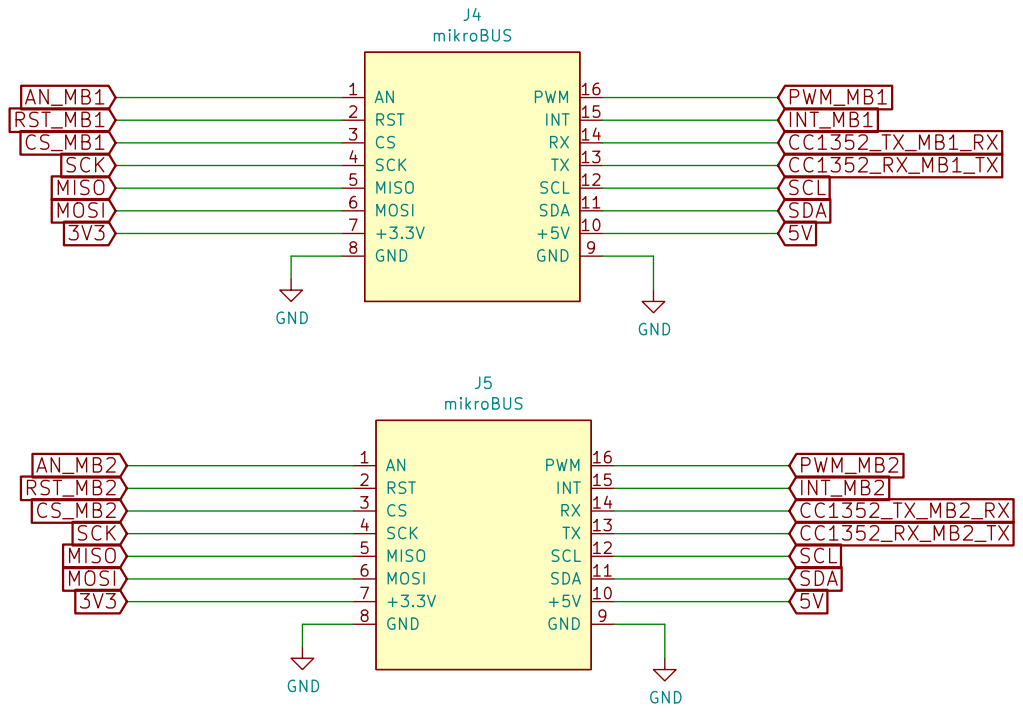
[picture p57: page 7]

Schematic originally designed by Analog Life, LLC
File: MikroBusClick.sch Sheet: /MikroBus Click/ Beagleboard.org

Id: 7/11 Title: BeagleConnect Freedom

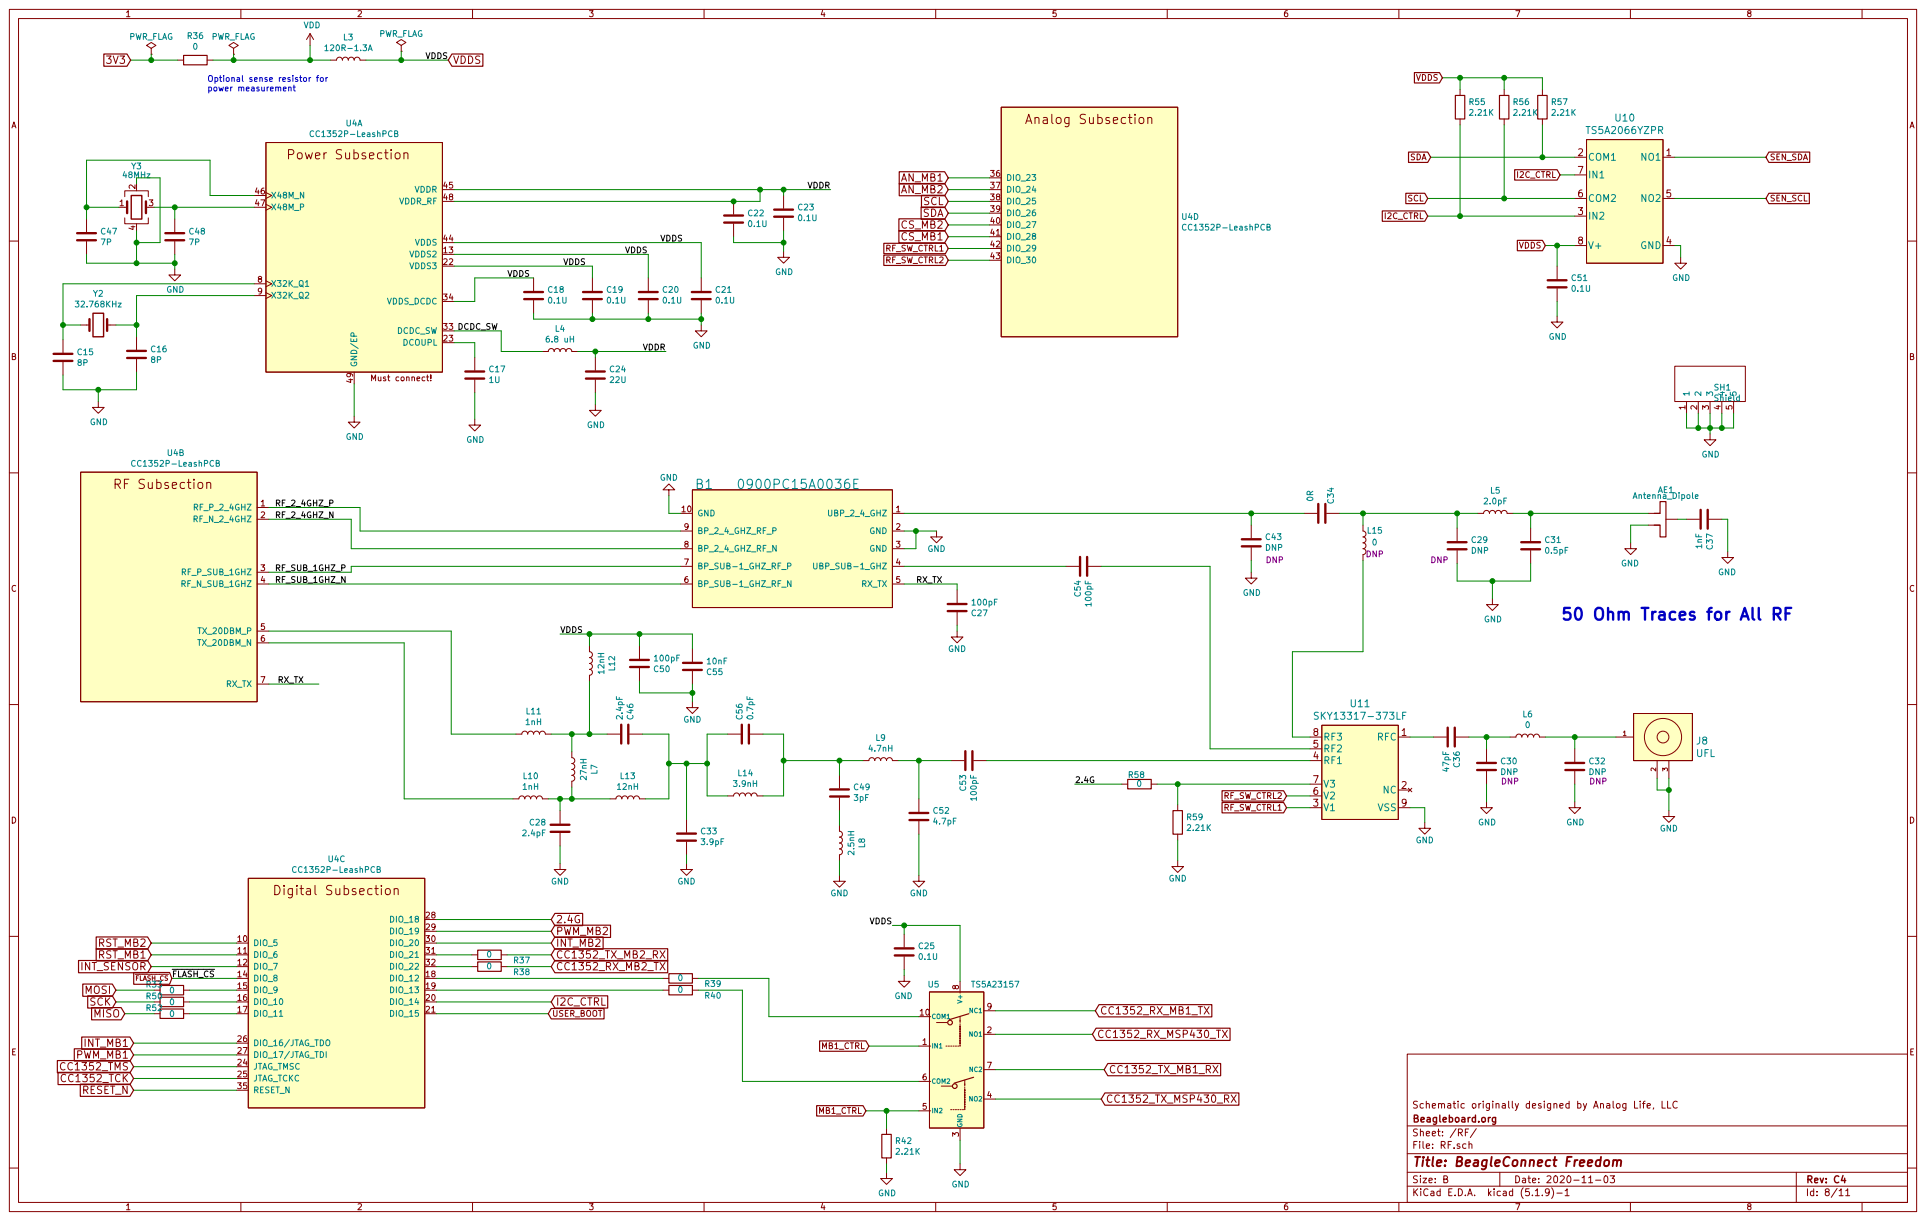
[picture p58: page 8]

Must connect! Power Subsection

Schematic originally designed by Analog Life, LLC
File: RF.sch Sheet: /RF/ Beagleboard.org

Id: 8/11 Title: BeagleConnect Freedom

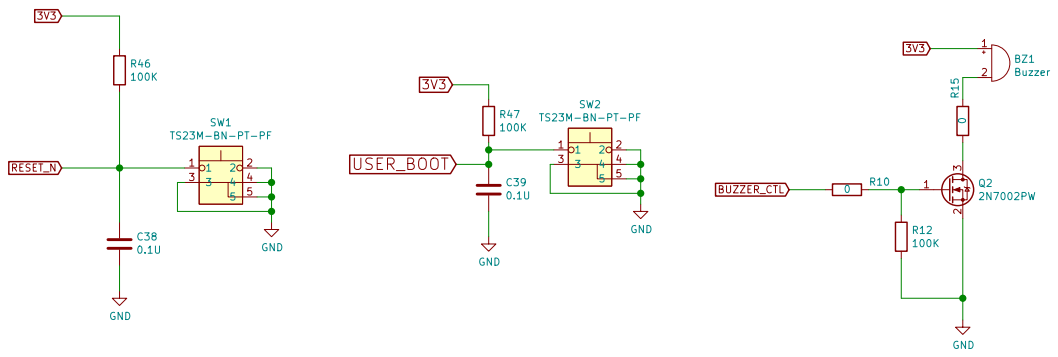
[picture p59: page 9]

Schematic originally designed by Analog Life, LLC
Beagleboard.org
Sheet: /User Input/Output/
File: UserInputOutput.sch
Id: 9/11 Title: BeagleConnect Freedom

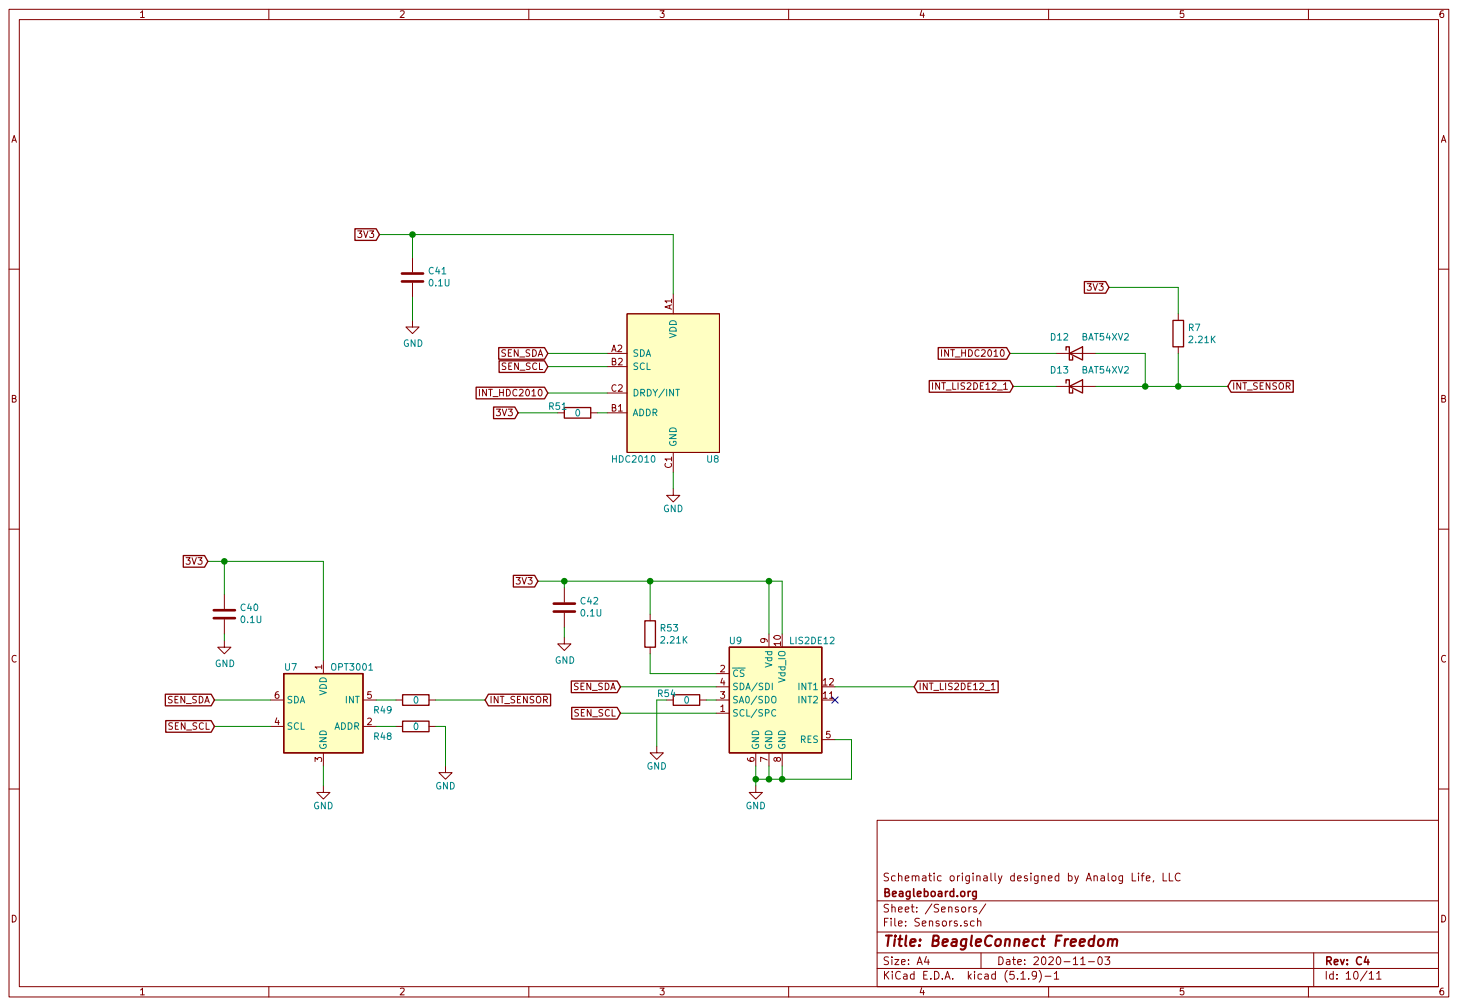
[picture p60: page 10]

File: Sensors.sch Sheet: /Sensors/ Beagleboard.org

Id: 10/11 Title: BeagleConnect Freedom

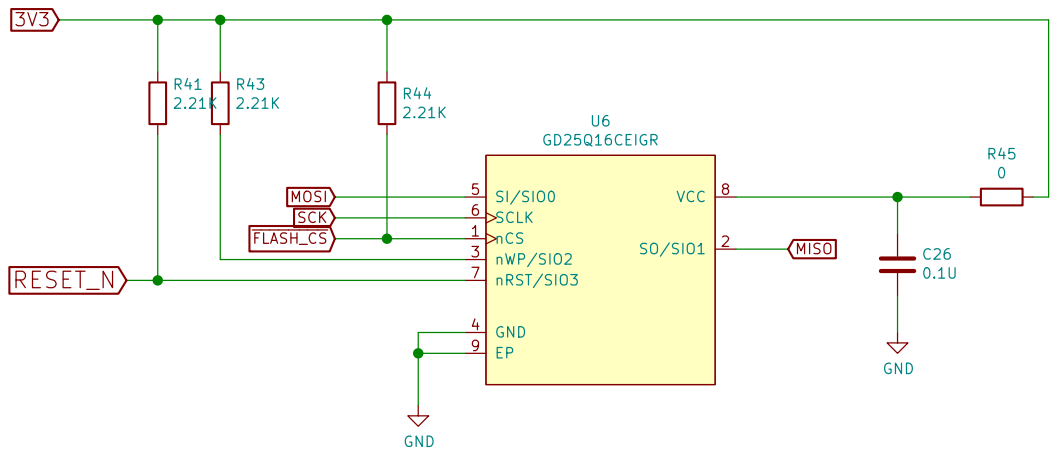
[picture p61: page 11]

Schematic originally designed by Analog Life, LLC
File: SPI FLASH.sch Sheet: /SPI FLASH/ Beagleboard.org

Id: 11/11 Title: BeagleConnect Freedom

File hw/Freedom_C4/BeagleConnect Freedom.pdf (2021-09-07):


Estimated BOM cost: $0.03 USB Input

Sheet: Sensors File: Sensors.sch Sheet: SPI FLASH

Estimated BOM cost: $1.27 Estimated BOM cost: $1.00

File: SPI FLASH.sch

File: RF.sch Sheet: User Input/Output

Sheet: Sheet5D099F01 File: Indicators.sch GND

Schematic originally designed by Analog Life, LLC
File: BeagleConnect Freedom.sch Sheet: / Beagleboard.org

Id: 1/11 Title: BeagleConnect Freedom


Schematic originally designed by Analog Life, LLC
Beagleboard.org
Sheet: /External Input/
File: ExternalInput.sch
Id: 2/11 Title: BeagleConnect Freedom


Schematic originally designed by Analog Life, LLC
Beagleboard.org
Sheet: /Programming/
File: Programming.sch
Id: 3/11 Title: BeagleConnect Freedom


Schematic originally designed by Analog Life, LLC
File: Indicators.sch Sheet: /Sheet5D099F01/ Beagleboard.org

Id: 4/11 Title: BeagleConnect Freedom

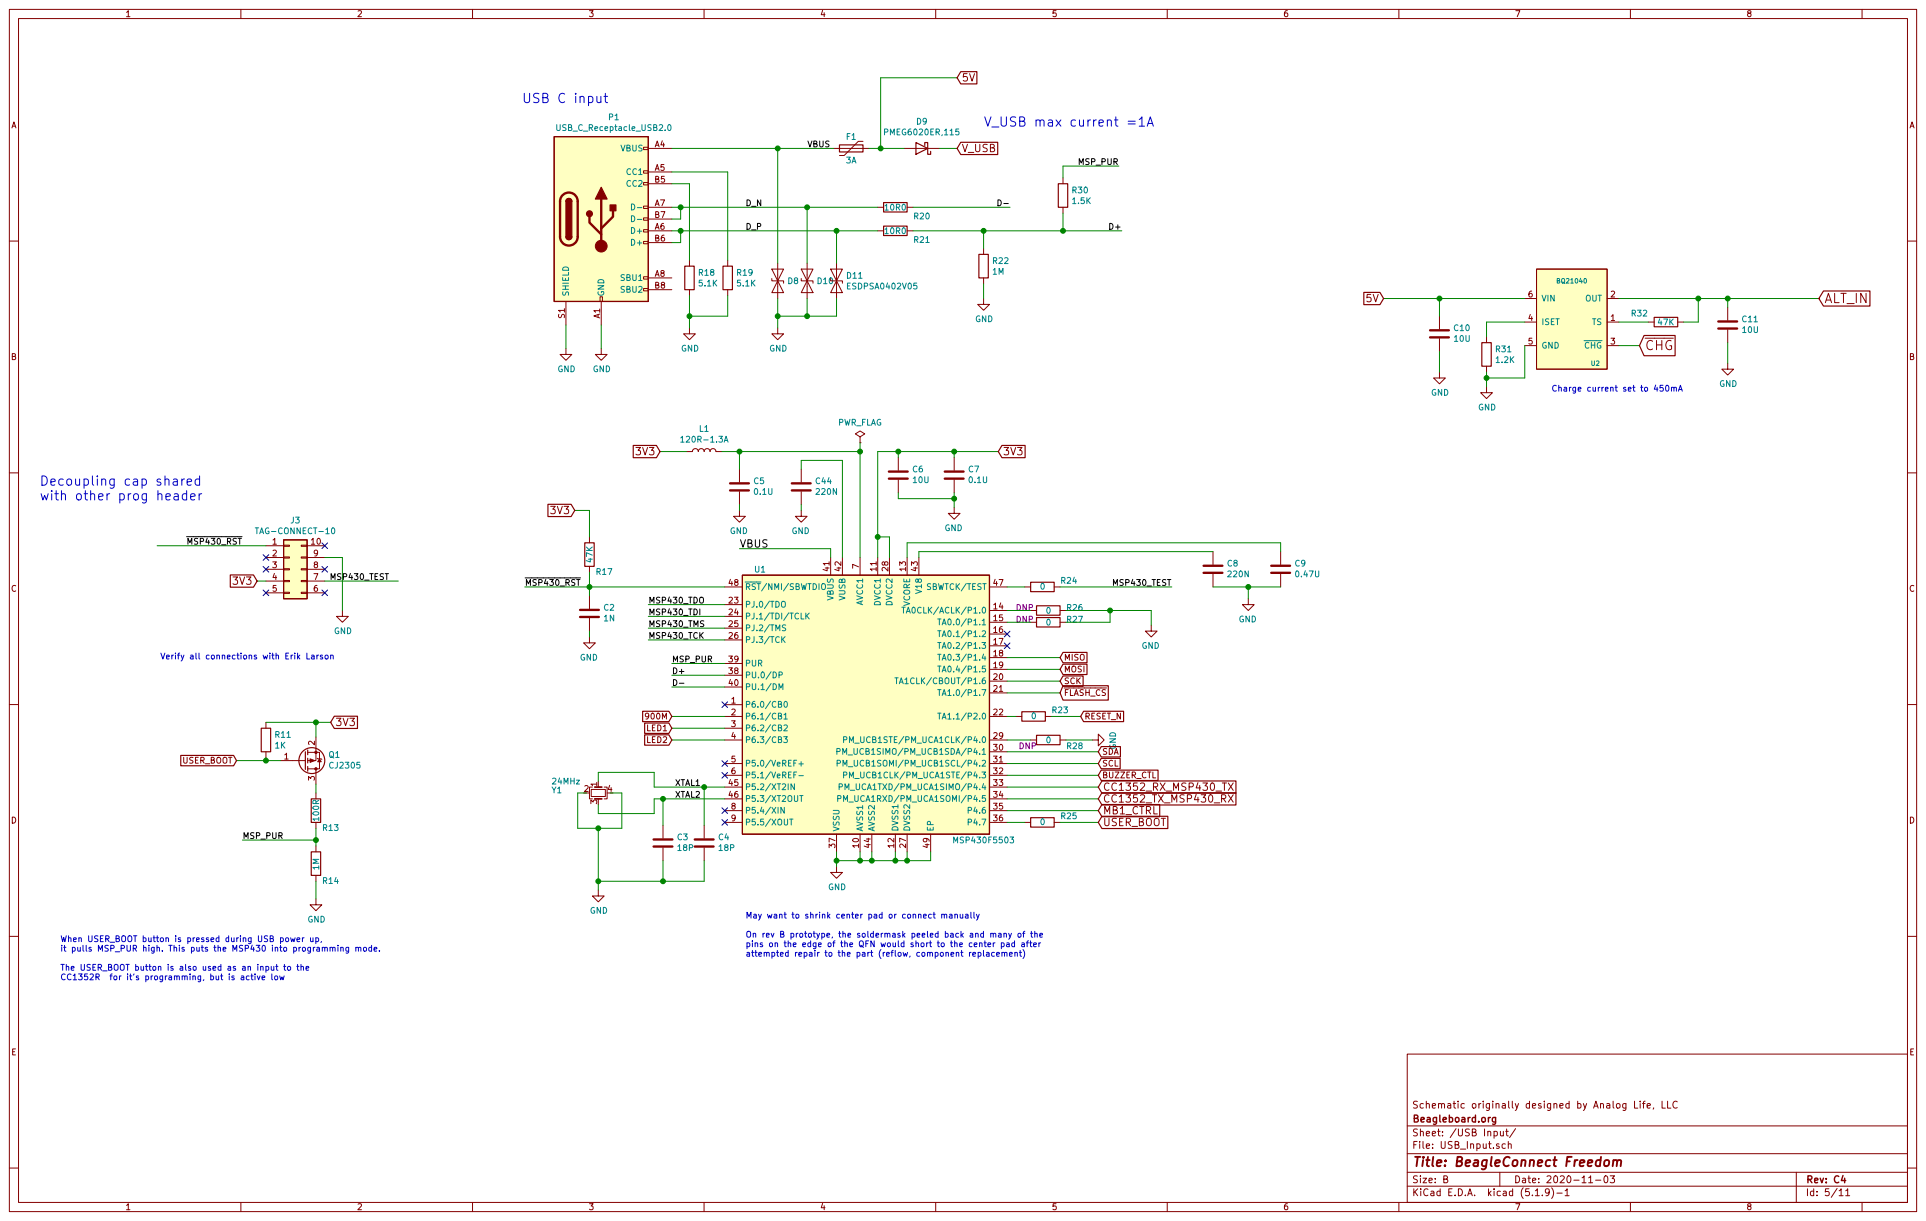
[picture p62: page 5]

Charge current set to 450mA

Decoupling cap shared
with other prog header

Verify all connections with Erik Larson

May want to shrink center pad or connect manually

When USER_BOOT button is pressed during USB power up,
it pulls MSP_PUR high. This puts the MSP430 into programming mode.

On rev B prototype, the soldermask peeled back and many of the
pins on the edge of the QFN would short to the center pad after
attempted repair to the part (reflow, component replacement)

The USER_BOOT button is also used as an input to the
CC1352R for it's programming, but is active low

Schematic originally designed by Analog Life, LLC
Beagleboard.org
Sheet: /USB Input/
File: USB_Input.sch
Id: 5/11 Title: BeagleConnect Freedom


Schematic originally designed by Analog Life, LLC
File: Boost.sch Sheet: /Boost Converters/ Beagleboard.org

Id: 6/11 Title: BeagleConnect Freedom


Schematic originally designed by Analog Life, LLC
File: MikroBusClick.sch Sheet: /MikroBus Click/ Beagleboard.org

Id: 7/11 Title: BeagleConnect Freedom


Optional sense resistor for power measurement

Schematic originally designed by Analog Life, LLC
File: RF.sch Sheet: /RF/ Beagleboard.org

Id: 8/11 Title: BeagleConnect Freedom


Schematic originally designed by Analog Life, LLC
Beagleboard.org
Sheet: /User Input/Output/
File: UserInputOutput.sch
Id: 9/11 Title: BeagleConnect Freedom


Schematic originally designed by Analog Life, LLC
File: Sensors.sch Sheet: /Sensors/ Beagleboard.org

Id: 10/11 Title: BeagleConnect Freedom


Schematic originally designed by Analog Life, LLC
File: SPI FLASH.sch Sheet: /SPI FLASH/ Beagleboard.org

Id: 11/11 Title: BeagleConnect Freedom

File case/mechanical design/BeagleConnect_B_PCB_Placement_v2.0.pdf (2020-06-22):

徐国群; <=50 TOL+/-.10; ANGLES=+/-1°; <=200 TOL+/-.30; <=100 TOL+/-.20

















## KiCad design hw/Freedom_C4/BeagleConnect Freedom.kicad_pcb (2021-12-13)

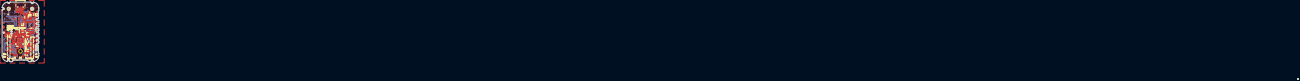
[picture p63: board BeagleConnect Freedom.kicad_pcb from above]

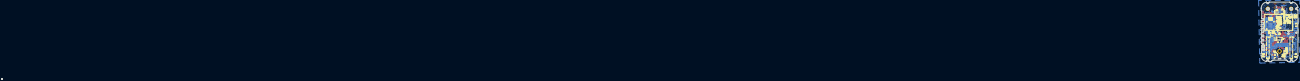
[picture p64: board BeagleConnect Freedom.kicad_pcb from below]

Board: 4 copper layers, 35.8 x 58.0 mm, 176 parts (76 on the bottom side), 136 nets.

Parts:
AE1: Antenna_Dipole; RFECA3216060A1T
B1: 0900PC15A0036E; 0900PC15A0036
BZ1: Buzzer; BUZZER3-5.5X5X2MM
C1, C5, C7, C18, C19, C20, C21, C22, C23, C25, C26, C38, C39, C40, C41, C42, C51: 0.1U; C_0402_1005Metric
C2: 1N; C_0402_1005Metric
C3, C4: 18P; C_0402_1005Metric
C6, C10, C11, C14, C45: 10U; C_0402_1005Metric
C8, C44: 220N; C_0402_1005Metric
C9: 0.47U; C_0402_1005Metric
C12: 10U; C_0603_1608Metric
C13: 100P; C_0402_1005Metric
C15, C16: 12P; C_0402_1005Metric
C17: 1U; C_0402_1005Metric
C24: 22U; C_0603_1608Metric
C27, C50, C53, C54: 100pF; C_0201_0603Metric
C28, C46: 2.4pF; C_0201_0603Metric
C29, C30, C32, C43: DNP; C_0201_0603Metric
C31: 0.5pF; C_0201_0603Metric
C33: 3.9pF; C_0201_0603Metric
C34, C36: 0R; C_0201_0603Metric
C37: 1nF; C_0402_1005Metric
C47, C48: 7P; C_0402_1005Metric
C49: 3pF; C_0201_0603Metric
C52: 4.7pF; C_0201_0603Metric
C55: 10nF; C_0201_0603Metric
C56: 0.7pF; C_0201_0603Metric
D2, D3, D4, D5, D6, D7: LED; LED_0402_1005Metric
D8, D10, D11: ESDPSA0402V05; D_0402_1005Metric
D9: PMEG6020ER,115; D_SOD-123
D12, D13: BAT54XV2; D_SOD-523
F1: 3A; R_1812_4532Metric
H1, H2, H3: Mounting Hole; MountingHole_2.2mm_M2_Pad_Via
J1: ST-FH-254-0144-02; PinSocket_1x02_P2.54mm_Vertical_SMD_Pin1Right
J2, J3: TAG-CONNECT-10; Tag-Connect-10
J4, J5: mikroBUS; MikroBus-SMD
J8: UFL; A-1JB
L1, L3: 120R-1.3A; L_0402_1005Metric
L2: 0.47U; L2X1.6X1MM
L4: 6.8 uH; L_0805_2012Metric
L5: 2.0pF; L_0201_0603Metric
L6, L15: 0; L_0201_0603Metric
L7: 27nH; L_0201_0603Metric
L8: 2.5nH; L_0201_0603Metric
L9: 4.7nH; L_0201_0603Metric
L10, L11: 1nH; L_0201_0603Metric
L12, L13: 12nH; L_0201_0603Metric
L14: 3.9nH; L_0201_0603Metric
Q1, Q4: CJ2305; SOT-23
Q2: 2N7002PW; SOT-323_SC-70
Q3: BC856S; SOT-363_SC-70-6
R1, R2, R3, R4, R5, R6, R11: 1K; R_0402_1005Metric
R7, R41, R42, R43, R44, R53, R55, R56, R57, R59: 2.21K; R_0402_1005Metric
R8, R9, R12, R35, R46, R47: 100K; R_0402_1005Metric
R10, R15, R16, R23, R24, R25, R26, R27, R28, R29, R33, R36, R37, R38, R39, R40, R45, R48, R49, R50, R51, R52, R54, R58: 0; R_0402_1005Metric
R13: 100R; R_0402_1005Metric
R14, R22: 1M; R_0402_1005Metric
R17, R32: 47K; R_0402_1005Metric
R18, R19: 5.1K; R_0402_1005Metric
R20, R21: 10R0; R_0402_1005Metric
R30: 1.5K; R_0402_1005Metric
R31: 1.2K; R_0402_1005Metric
R34: 453K; R_0402_1005Metric
SH1: Shield; SHIELDING_27.5x15.5x0.2mm
SW1, SW2: TS23M-BN-PT-PF
U1: MSP430F5503; Texas_S-PVQFN-N48_EP5.15x5.15mm
U2: BQ21040; SOT-23-6
U3: TPS62821; TPS62821DLC
U4: CC1352P-LeashPCB; QFN-48-1EP_7x7mm_P0.5mm_EP5.15x5.15mm
U5: TS5A23157; QFN10_0.6_2X1.5X0.5MM
U6: GD25Q16CEIGR; MX25R8035FZUIL0
U7: OPT3001; USON6
U8: HDC2010
U9: LIS2DE12; LGA-12_2x2mm_P0.5mm
U10: TS5A2066YZPR
U11: SKY13317-373LF
USB1: USB_C_Receptacle_USB2.0; USB_C_Receptacle_Palconn_UTC16-G
Y1: 24MHz; Crystal_SMD_3225-4Pin_3.2x2.5mm
Y2: 32.768KHz; Crystal_SMD_2012-2Pin_2.0x1.2mm
Y3: 48MHz; Crystal_SMD_2016-4Pin_2.0x1.6mm

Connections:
2.4G: D6.2, R58.1, U4.28
3V3: BZ1.1, C1.1, C6.2, C7.2, C13.1, C14.1, C40.2, C41.2, C42.2, C45.1, D4.2, D7.2, J2.1, J3.4, J4.7, J5.7, L1.2, L2.2, Q1.2, R7.1, R11.1, R17.2, R34.2, R36.2, R41.1, R43.1, R44.1, R45.1, R46.1, R47.1, R51.2, R53.1, U1.11, U1.28, U7.1, U8.A1, U9.9, U9.10
5V: C10.2, D9.2, F1.1, J4.10, J5.10, U2.6
900M: D5.2, U1.2
/Programming/CC1352_TDI: J2.8, R16.2
/Programming/CC1352_TDO: J2.6, R29.2
/RF/DCDC_SW: L4.2, U4.33
/RF/RF_2_4GHZ_N: B1.8, U4.2
/RF/RF_2_4GHZ_P: B1.9, U4.1
/RF/RF_SUB_1GHZ_N: B1.6, U4.4
/RF/RF_SUB_1GHZ_P: B1.7, U4.3
/RF/RX_TX: B1.5, C27.1, U4.7
/RF/VDDR: C22.2, C23.2, C24.2, L4.1, U4.45, U4.48
/USB Input/D+: R21.1, R22.1, R30.2, U1.38
/USB Input/D-: R20.1, U1.40
/USB Input/D_N: D10.1, R20.2, USB1.A7, USB1.B7
/USB Input/D_P: D11.1, R21.2, USB1.A6, USB1.B6
/USB Input/MSP430_TEST: J3.7, R24.1
/USB Input/MSP_PUR: R13.1, R14.2, R30.1, U1.39
/USB Input/VBUS: D8.1, F1.2, U1.41, USB1.A4, USB1.A9, USB1.B4, USB1.B9
/USB Input/XTAL1: C4.2, U1.45, Y1.1
/USB Input/XTAL2: C3.2, U1.46, Y1.3
/USB Input/~MSP430_RST: C2.2, J3.1, R17.1, U1.48
ALT_IN: C11.2, J1.2, Q3.1, Q4.3, R32.2, U2.2
AN_MB1: J4.1, U4.36
AN_MB2: J5.1, U4.37
BUZZER_CTL: R10.2, U1.32
CC1352_RX_MB1_TX: J4.13, U5.9
CC1352_RX_MB2_TX: J5.13, R38.2
CC1352_RX_MSP430_TX: U1.33, U5.2
CC1352_TCK: J2.4, U4.25
CC1352_TMS: J2.2, U4.24
CC1352_TX_MB1_RX: J4.14, U5.7
CC1352_TX_MB2_RX: J5.14, R37.2
CC1352_TX_MSP430_RX: U1.34, U5.4
CS_MB1: J4.3, U4.41
CS_MB2: J5.3, U4.40
GND: AE1.2, B1.2, B1.3, B1.10, C1.2, C2.1, C3.1, C4.1, C5.1, C6.1, C7.1, C8.1, C9.1, C10.1, C11.1, C12.2, C14.2, C15.2, C16.2, C17.1, C18.1, C19.1, C20.1, C21.1, C22.1, C23.1, C24.1, C25.1, C26.1, C27.2, C28.1, C29.1, C30.2, C31.1, C32.2, C33.1, C37.2, C38.1, C39.1, C40.1, C41.1, C42.1, C43.1, C44.1, C45.2, C47.2, C48.2, C50.2, C51.1, C52.1, C55.2, D8.2, D10.2, D11.2, H1.1, H2.1, H3.1, J1.1, J2.3, J2.5, J3.9, J4.8, J4.9, J5.8, J5.9, J8.2, J8.3, L8.1, Q2.2, R1.2, R2.2, R3.2, R4.2, R5.2, R8.1, R9.1, R12.2, R14.1, R18.2, R19.2, R22.2, R26.1, R27.1, R28.1, R31.2, R35.1, R42.2, R48.1, R54.2, R59.2, SH1.1, SH1.2, SH1.3, SH1.4, SH1.5, SW1.2, SW1.3, SW1.4, SW1.5, SW2.2, SW2.3, SW2.4, SW2.5, U1.10, U1.12, U1.27, U1.37, U1.44, U1.49, U2.5, U3.3, U3.5, U4.49, U5.3, U6.4, U6.9, U7.3, U8.C1, U9.5, U9.6, U9.7, U9.8, U10.4, U11.9, USB1.A1, USB1.A12, USB1.B1, USB1.B12, USB1.S1, Y3.2, Y3.4
I2C_CTRL: R55.2, U4.20, U10.3, U10.7
INT_HDC2010: D12.1, U8.C2
INT_LIS2DE12_1: D13.1, U9.12
INT_MB1: J4.15, R29.1, U4.26
INT_MB2: J5.15, U4.30
INT_SENSOR: D12.2, D13.2, R7.2, R49.1, U4.12
LED1: D3.2, U1.3
LED2: D2.2, U1.4
MB1_CTRL: R42.1, U1.35, U5.1, U5.5
MISO: J4.5, J5.5, R52.2, U1.18, U6.2
MOSI: J4.6, J5.6, R33.2, U1.19, U6.5
unnamed: AE1.1, C31.2, L5.1
unnamed: AE1.3, C37.1
unnamed: B1.1, C34.1, C43.2
unnamed: B1.4, C54.2
unnamed: BZ1.2, R15.1
unnamed: C5.2, L1.1, U1.7
unnamed: C8.2, U1.43
unnamed: C9.2, U1.13
unnamed: C13.2, R34.1, R35.2, U3.2
unnamed: C15.1, U4.8, Y2.1
unnamed: C16.1, U4.9, Y2.2
unnamed: C17.2, U4.23
unnamed: C26.2, R45.2, U6.8
unnamed: C28.2, L7.1, L10.1, L13.2
unnamed: C29.2, C34.2, L5.2, L15.2
unnamed: C30.1, C36.2, L6.2
unnamed: C32.1, J8.1, L6.1
unnamed: C33.2, C46.2, C56.2, L13.1, L14.2
unnamed: C36.1, U11.1
unnamed: C44.2, U1.42
unnamed: C46.1, L7.2, L11.1, L12.1
unnamed: C47.1, U4.46, Y3.1
unnamed: C48.1, U4.47, Y3.3
unnamed: C49.1, L8.2
unnamed: C49.2, C56.1, L9.2, L14.1
unnamed: C52.2, C53.2, L9.1
unnamed: C53.1, U11.4
unnamed: C54.1, U11.5
unnamed: D2.1, R1.1
unnamed: D3.1, R2.1
unnamed: D4.1, R3.1
unnamed: D5.1, R4.1
unnamed: D6.1, R5.1
unnamed: D7.1, R6.1
unnamed: L2.1, U3.6
unnamed: L10.2, U4.6
unnamed: L11.2, U4.5
unnamed: L15.1, U11.8
unnamed: Q1.3, R13.2
unnamed: Q2.1, R10.1, R12.1
unnamed: Q2.3, R15.2
unnamed: Q3.2, Q3.5, Q3.6, R8.2
unnamed: Q3.3, Q4.1, R9.2
unnamed: R18.1, USB1.B5
unnamed: R19.1, USB1.A5
unnamed: R23.2, U1.22
unnamed: R24.2, U1.47
unnamed: R25.2, U1.36
unnamed: R26.2, U1.14
unnamed: R27.2, U1.15
unnamed: R28.2, U1.29
unnamed: R31.1, U2.4
unnamed: R32.1, U2.1
unnamed: R33.1, U4.15
unnamed: R37.1, U4.31
unnamed: R38.1, U4.32
unnamed: R39.1, U4.18
unnamed: R39.2, U5.10
unnamed: R40.1, U4.19
unnamed: R40.2, U5.6
unnamed: R43.2, U6.3
unnamed: R48.2, U7.2
unnamed: R49.2, U7.5
unnamed: R50.1, U4.16
unnamed: R51.1, U8.B1
unnamed: R52.1, U4.17
unnamed: R53.2, U9.2
unnamed: R54.1, U9.3
unnamed: R58.2, R59.1, U11.7
PWM_MB1: J4.16, R16.1, U4.27
PWM_MB2: J5.16, U4.29
RESET_N: C38.2, J2.10, R23.1, R41.2, R46.2, SW1.1, U4.35, U6.7
RF_SW_CTRL1: U4.42, U11.3
RF_SW_CTRL2: U4.43, U11.6
RST_MB1: J4.2, U4.11
RST_MB2: J5.2, U4.10
SCK: J4.4, J5.4, R50.2, U1.20, U6.6
SCL: J4.12, J5.12, R56.2, U1.31, U4.38, U10.6
SDA: J4.11, J5.11, R57.2, U1.30, U4.39, U10.2
SEN_SCL: U7.4, U8.B2, U9.1, U10.5
SEN_SDA: U7.6, U8.A2, U9.4, U10.1
USER_BOOT: C39.2, Q1.1, R11.2, R25.1, R47.2, SW2.1, U4.21
VDD: L3.2, R36.1
VDDS: C18.2, C19.2, C20.2, C21.2, C25.2, C50.1, C51.2, C55.1, L3.1, L12.2, R55.1, R56.1, R57.1, U4.13, U4.22, U4.34, U4.44, U5.8, U10.8
V_ALT: C12.1, D9.1, Q3.4, Q4.2, U3.1, U3.7
~CHG: R6.2, U2.3
~FLASH_CS: R44.2, U1.21, U4.14, U6.1

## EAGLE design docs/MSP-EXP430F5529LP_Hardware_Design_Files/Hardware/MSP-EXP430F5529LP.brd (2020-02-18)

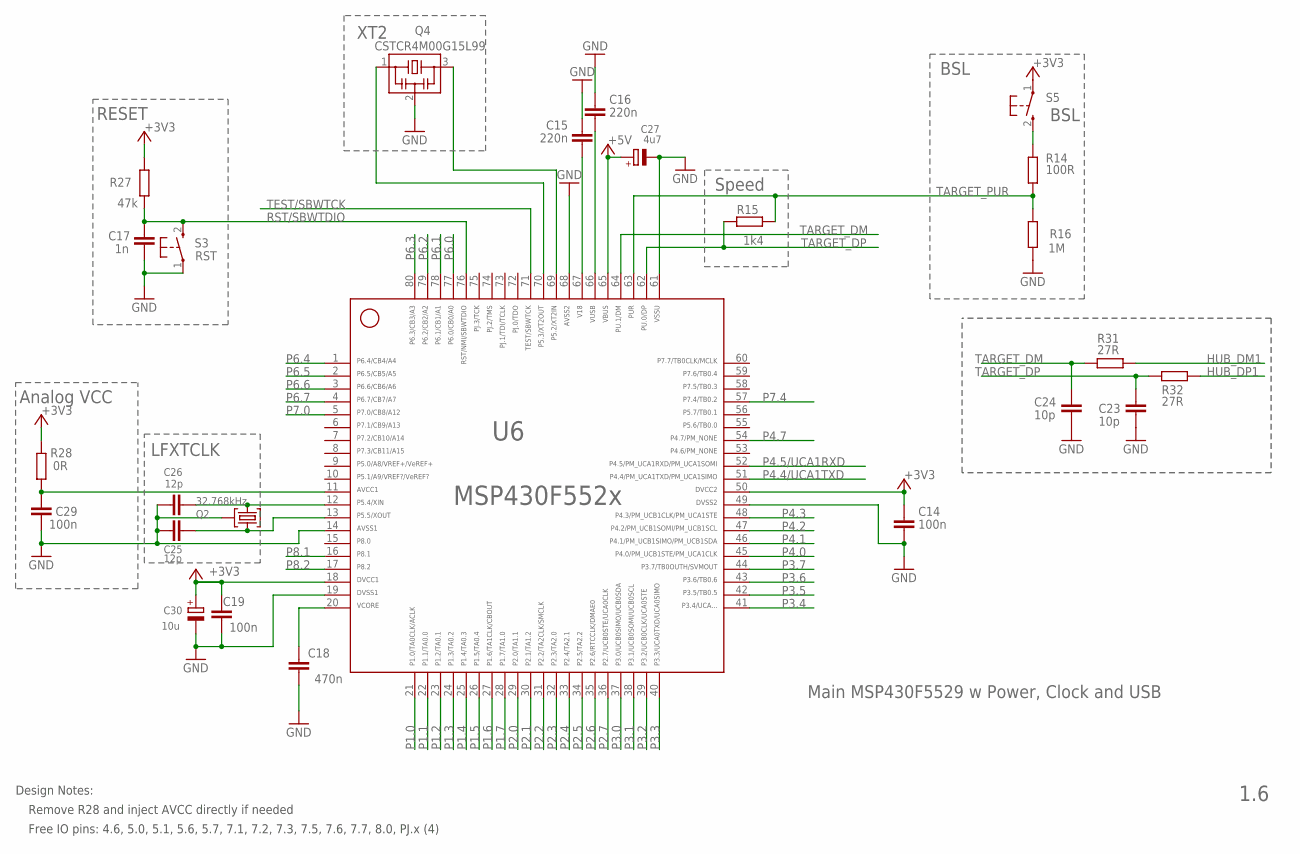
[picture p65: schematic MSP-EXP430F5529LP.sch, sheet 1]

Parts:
C14, C19, C29: 100n; 0402
C15, C16: 220n; 0402
C17: 1n; 0402
C18: 470n; 0402
C23, C24: 10p; 0402
C25, C26: 12p; 0402
C27: 4u7; A/3216-18R
C30: 10u; A/3216-18R
Q2: 32.768kHz; MS3V-T1R
Q4: CSTCR4M00G15L99; MURATA-FILTER_CSTCR
R14: 100R; 0402
R15: 1k4; 0402
R16: 1M; 0402
R27: 47k; 0402
R28: 0R; 0402
R31, R32: 27R; 0402
S3: RST; PBTH
S5: BSL; PBTH
U6: MSP430F5529IPNR; PN80

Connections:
+3V3: C14.1, C19.2, C30.+, R27.2, R28.2, S5.1, U6.18, U6.50; also elsewhere on the board
+5V: C27.+, U6.65; also elsewhere on the board
AVCC: C29.1, R28.1, U6.11
GND: C14.2, C15.2, C16.2, C17.2, C18.1, C19.1, C23.2, C24.2, C25.1, C26.1, C27.-, C29.2, C30.-, Q2.P3 (GND), Q4.2, R16.1, S3.1, U6.14, U6.19, U6.49, U6.61, U6.68; also elsewhere on the board
HUB_DM1: R31.1; also elsewhere on the board
HUB_DP1: R32.1; also elsewhere on the board
unnamed: R14.1, S5.2 (S)
P1.0: U6.21; also elsewhere on the board
P1.1: U6.22; also elsewhere on the board
P1.2: U6.23; also elsewhere on the board
P1.3: U6.24; also elsewhere on the board
P1.4: U6.25; also elsewhere on the board
P1.5: U6.26; also elsewhere on the board
P1.6: U6.27; also elsewhere on the board
P1.7: U6.28; also elsewhere on the board
P2.0: U6.29; also elsewhere on the board
P2.1: U6.30; also elsewhere on the board
P2.2: U6.31; also elsewhere on the board
P2.3: U6.32; also elsewhere on the board
P2.4: U6.33; also elsewhere on the board
P2.5: U6.34; also elsewhere on the board
P2.6: U6.35; also elsewhere on the board
P2.7: U6.36; also elsewhere on the board
P3.0: U6.37; also elsewhere on the board
P3.1: U6.38; also elsewhere on the board
P3.2: U6.39; also elsewhere on the board
P3.3: U6.40; also elsewhere on the board
P3.4: U6.41; also elsewhere on the board
P3.5: U6.42; also elsewhere on the board
P3.6: U6.43; also elsewhere on the board
P3.7: U6.44; also elsewhere on the board
P4.0: U6.45; also elsewhere on the board
P4.1: U6.46; also elsewhere on the board
P4.2: U6.47; also elsewhere on the board
P4.3: U6.48; also elsewhere on the board
P4.4/UCA1TXD: U6.51; also elsewhere on the board
P4.5/UCA1RXD: U6.52; also elsewhere on the board
P4.7: U6.54; also elsewhere on the board
P5.2/XT2IN: Q4.3, U6.69
P5.3/XT2OUT: Q4.1, U6.70
P5.4/XIN: C26.2, Q2.P2 (2), U6.12
P5.5/XOUT: C25.2, Q2.P1 (1), U6.13
P6.0: U6.77; also elsewhere on the board
P6.1: U6.78; also elsewhere on the board
P6.2: U6.79; also elsewhere on the board
P6.3: U6.80; also elsewhere on the board
P6.4: U6.1; also elsewhere on the board
P6.5: U6.2; also elsewhere on the board
P6.6: U6.3; also elsewhere on the board
P6.7: U6.4; also elsewhere on the board
P7.0: U6.5; also elsewhere on the board
P7.4: U6.57; also elsewhere on the board
P8.1: U6.16; also elsewhere on the board
P8.2: U6.17; also elsewhere on the board
RST/SBWTDIO: C17.1, R27.1, S3.2 (S), U6.76; also elsewhere on the board
TARGET_DM: C24.1, R31.2, U6.64
TARGET_DP: C23.1, R15.2, R32.2, U6.62
TARGET_PUR: R14.2, R15.1, R16.2, U6.63
TARGET_VUSB: C16.1, U6.66
TEST/SBWTCK: U6.71; also elsewhere on the board
V18: C15.1, U6.67
VCORE: C18.2, U6.20

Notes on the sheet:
RESET
LFXTCLK
XT2
Main MSP430F5529 w Power, Clock and USB
1.6
BSL
Speed
Analog VCC
Remove R28 and inject AVCC directly if needed
Design Notes:
Free IO pins: 4.6, 5.0, 5.1, 5.6, 5.7, 7.1, 7.2, 7.3, 7.5, 7.6, 7.7, 8.0, PJ.x (4)

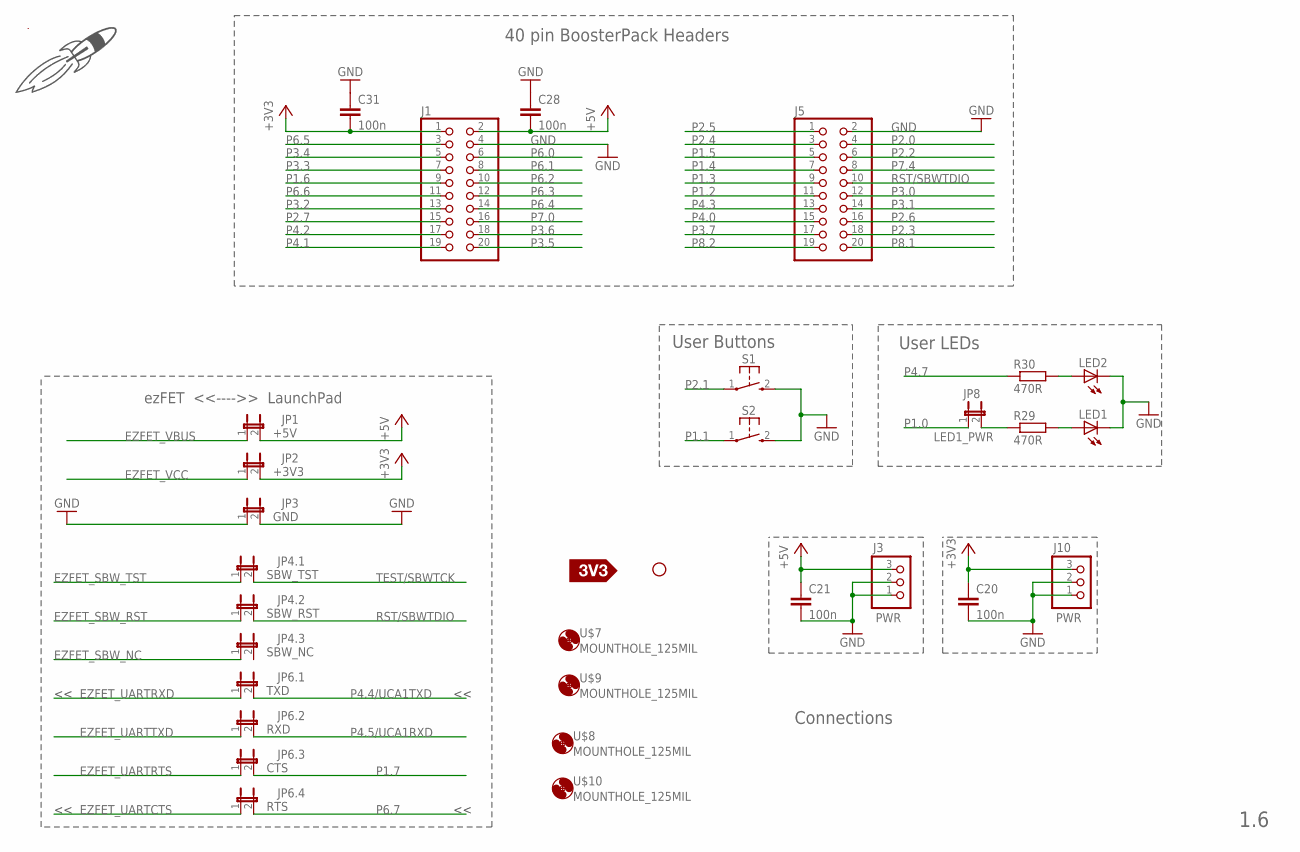
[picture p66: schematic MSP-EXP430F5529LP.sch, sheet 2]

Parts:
C20, C21, C28, C31: 100n; 0402
DRAW1: LOGO-ROCKET-20X13MM-SCH-S; LOGO-ROCKET-10X7MM-BRD
J1, J5: PINHD-2X10; 2X10
J3, J10: PWR; 1X03
JP1: +5V; JP1M
JP2: +3V3; JP1M
JP3: GND; JP1M
JP4.1: SBW_TST; JP1M
JP4.2: SBW_RST; JP1M
JP4.3: SBW_NC; JP1M
JP6.1: TXD; JP1M
JP6.2: RXD; JP1M
JP6.3: CTS; JP1M
JP6.4: RTS; JP1M
JP8: LED1_PWR; JP1
LED1, LED2: LEDCHIPLED_0603; CHIPLED_0603
R29, R30: 470R; 0402
S1, S2: PB; PBTH
U$4: MS_TM
U$6: SILK_3V3_TAG
U$7, U$8, U$9, U$10: MOUNTHOLE_125MIL
U$11: 5529LP_REARSILK_REV1_6

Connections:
+3V3: C20.1, C31.2, J1.1, J10.3, JP2.2; also elsewhere on the board
+5V: C21.1, C28.2, J1.2, J3.3, JP1.2; also elsewhere on the board
EZFET_SBW_NC: JP4.3.1; also elsewhere on the board
EZFET_SBW_RST: JP4.2.1; also elsewhere on the board
EZFET_SBW_TST: JP4.1.1; also elsewhere on the board
EZFET_UARTCTS: JP6.4.1; also elsewhere on the board
EZFET_UARTRTS: JP6.3.1; also elsewhere on the board
EZFET_UARTRXD: JP6.1.1; also elsewhere on the board
EZFET_UARTTXD: JP6.2.1; also elsewhere on the board
EZFET_VBUS: JP1.1; also elsewhere on the board
EZFET_VCC: JP2.1; also elsewhere on the board
GND: C20.2, C21.2, C28.1, C31.1, J1.4, J3.1, J3.2, J5.2, J10.1, J10.2, JP3.1, JP3.2, LED1.C, LED2.C, S1.2 (S), S2.2 (S); also elsewhere on the board
unnamed: JP8.2, R29.1
unnamed: LED1.A, R29.2
unnamed: LED2.A, R30.2
P1.0: JP8.1; also elsewhere on the board
P1.1: S2.1; also elsewhere on the board
P1.2: J5.11; also elsewhere on the board
P1.3: J5.9; also elsewhere on the board
P1.4: J5.7; also elsewhere on the board
P1.5: J5.5; also elsewhere on the board
P1.6: J1.9; also elsewhere on the board
P1.7: JP6.3.2; also elsewhere on the board
P2.0: J5.4; also elsewhere on the board
P2.1: S1.1; also elsewhere on the board
P2.2: J5.6; also elsewhere on the board
P2.3: J5.18; also elsewhere on the board
P2.4: J5.3; also elsewhere on the board
P2.5: J5.1; also elsewhere on the board
P2.6: J5.16; also elsewhere on the board
P2.7: J1.15; also elsewhere on the board
P3.0: J5.12; also elsewhere on the board
P3.1: J5.14; also elsewhere on the board
P3.2: J1.13; also elsewhere on the board
P3.3: J1.7; also elsewhere on the board
P3.4: J1.5; also elsewhere on the board
P3.5: J1.20; also elsewhere on the board
P3.6: J1.18; also elsewhere on the board
P3.7: J5.17; also elsewhere on the board
P4.0: J5.15; also elsewhere on the board
P4.1: J1.19; also elsewhere on the board
P4.2: J1.17; also elsewhere on the board
P4.3: J5.13; also elsewhere on the board
P4.4/UCA1TXD: JP6.1.2; also elsewhere on the board
P4.5/UCA1RXD: JP6.2.2; also elsewhere on the board
P4.7: R30.1; also elsewhere on the board
P6.0: J1.6; also elsewhere on the board
P6.1: J1.8; also elsewhere on the board
P6.2: J1.10; also elsewhere on the board
P6.3: J1.12; also elsewhere on the board
P6.4: J1.14; also elsewhere on the board
P6.5: J1.3; also elsewhere on the board
P6.6: J1.11; also elsewhere on the board
P6.7: JP6.4.2; also elsewhere on the board
P7.0: J1.16; also elsewhere on the board
P7.4: J5.8; also elsewhere on the board
P8.1: J5.20; also elsewhere on the board
P8.2: J5.19; also elsewhere on the board
RST/SBWTDIO: J5.10, JP4.2.2; also elsewhere on the board
TEST/SBWTCK: JP4.1.2; also elsewhere on the board

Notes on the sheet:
40 pin BoosterPack Headers
Connections
1.6
User LEDs
User Buttons
ezFET <<---->> LaunchPad

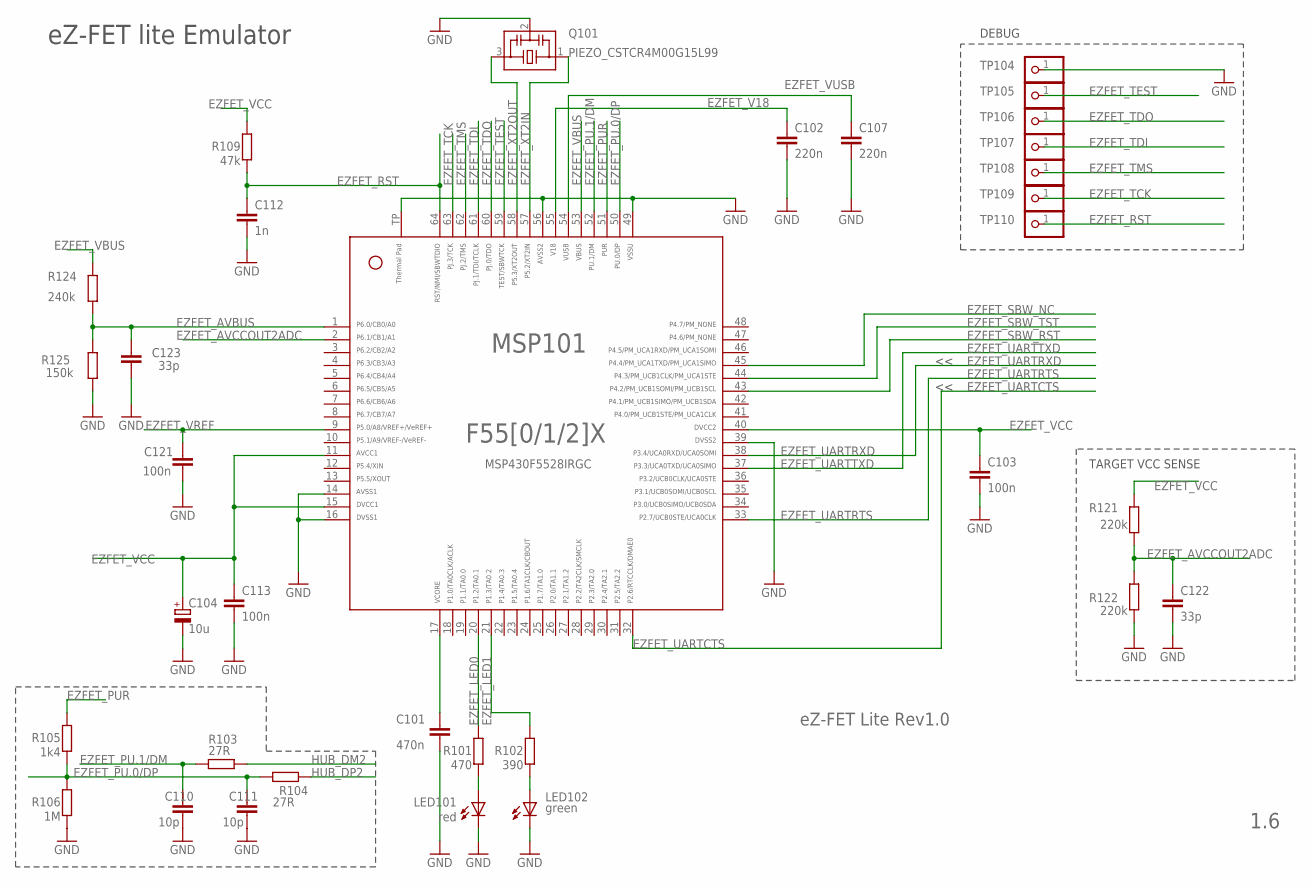
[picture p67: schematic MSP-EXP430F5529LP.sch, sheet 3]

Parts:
C101: 470n; 0402
C102, C107: 220n; 0402
C103, C113, C121: 100n; 0402
C104: 10u; A/3216-18R
C110, C111: 10p; 0402
C112: 1n; 0402
C122, C123: 33p; 0402
LED101: red; CHIP-LED0603
LED102: green; CHIP-LED0603
MSP101: MSP430F5528IRGC; RGC64
Q101: PIEZO_CSTCR4M00G15L99; MURATA-FILTER_CSTCR
R101: 470; 0402
R102: 390; 0402
R103, R104: 27R; 0402
R105: 1k4; 0402
R106: 1M; 0402
R109: 47k; 0402
R121, R122: 220k; 0402
R124: 240k; 0402
R125: 150k; 0402
TP104, TP105, TP106, TP107, TP108, TP109, TP110: TEST_PIN2; 1X01

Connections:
EZFET_AVBUS: C123.2, MSP101.1, R124.2, R125.1
EZFET_AVCCOUT2ADC: C122.2, MSP101.2, R121.2, R122.1
EZFET_LED0: MSP101.20, R101.2
EZFET_LED1: MSP101.21, R102.2
EZFET_PU.0/DP: C111.1, MSP101.50, R104.2, R105.1, R106.2
EZFET_PU.1/DM: C110.1, MSP101.52, R103.2
EZFET_PUR: MSP101.51, R105.2
EZFET_RST: C112.1, MSP101.64, R109.1, TP110.1
EZFET_SBW_NC: MSP101.45; also elsewhere on the board
EZFET_SBW_RST: MSP101.43; also elsewhere on the board
EZFET_SBW_TST: MSP101.44; also elsewhere on the board
EZFET_TCK: MSP101.63, TP109.1
EZFET_TDI: MSP101.61, TP107.1
EZFET_TDO: MSP101.60, TP106.1
EZFET_TEST: MSP101.59, TP105.1
EZFET_TMS: MSP101.62, TP108.1
EZFET_UARTCTS: MSP101.32; also elsewhere on the board
EZFET_UARTRTS: MSP101.33; also elsewhere on the board
EZFET_UARTRXD: MSP101.38; also elsewhere on the board
EZFET_UARTTXD: MSP101.37; also elsewhere on the board
EZFET_V18: C102.1, MSP101.55
EZFET_VBUS: MSP101.53, R124.1; also elsewhere on the board
EZFET_VCC: C103.1, C104.+, C113.1, MSP101.11, MSP101.15, MSP101.40, R109.2, R121.1; also elsewhere on the board
EZFET_VREF: C121.1, MSP101.9
EZFET_VUSB: C107.1, MSP101.54
EZFET_XT2IN: MSP101.57, Q101.1
EZFET_XT2OUT: MSP101.58, Q101.3
GND: C101.2, C102.2, C103.2, C104.-, C107.2, C110.2, C111.2, C112.2, C113.2, C121.2, C122.1, C123.1, LED101.C, LED102.C, MSP101.14, MSP101.16, MSP101.39, MSP101.49, MSP101.56, MSP101.TP, Q101.2, R106.1, R122.2, R125.2, TP104.1; also elsewhere on the board
HUB_DM2: R103.1; also elsewhere on the board
HUB_DP2: R104.1; also elsewhere on the board
unnamed: LED101.A, R101.1
unnamed: LED102.A, R102.1
unnamed: C101.1, MSP101.17

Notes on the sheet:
eZ-FET lite Emulator
MSP430F5528IRGC
TARGET VCC SENSE
eZ-FET Lite Rev1.0
1.6
DEBUG

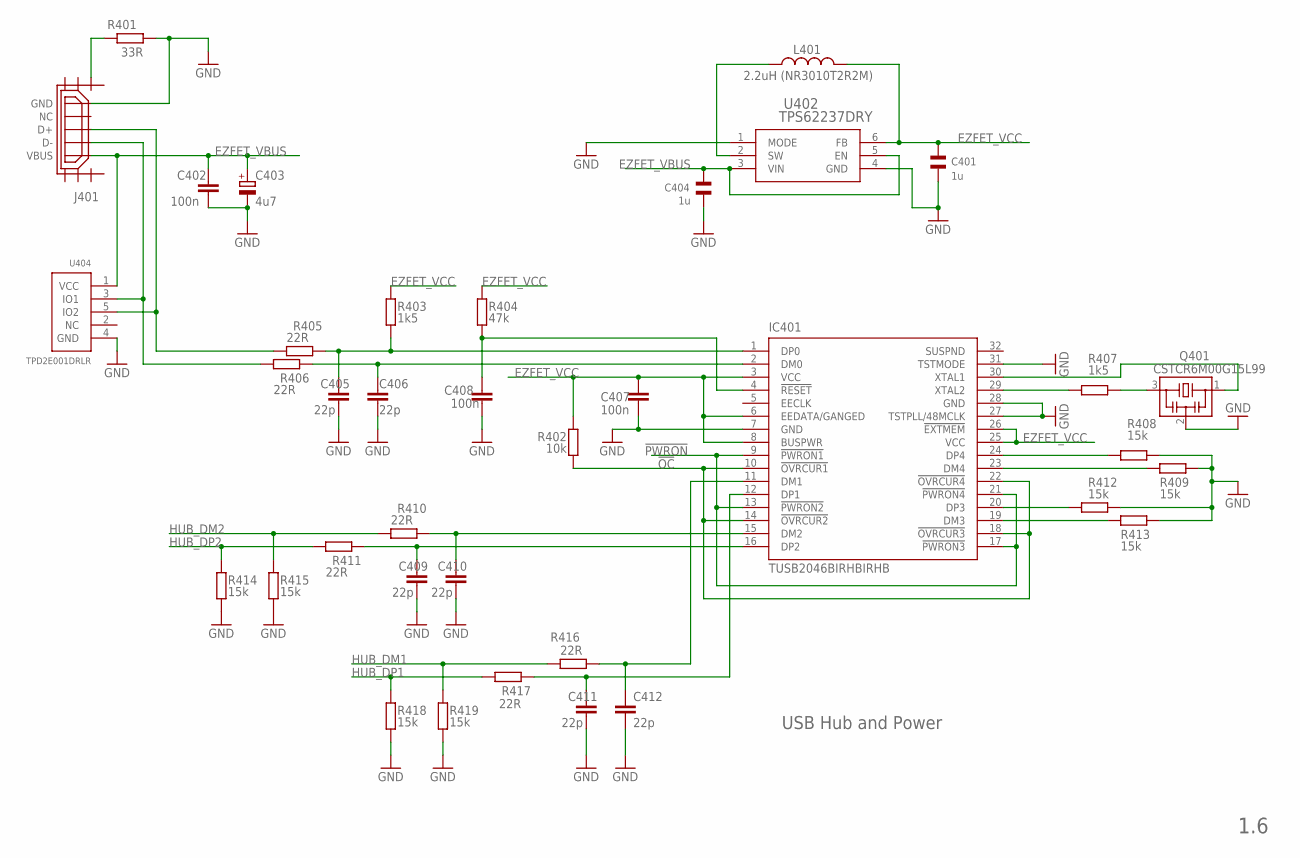
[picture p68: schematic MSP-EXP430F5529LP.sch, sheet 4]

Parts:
C401, C404: 1u; CSMD0805
C402, C407, C408: 100n; 0402
C403: 4u7; A/3216-18R
C405, C406, C409, C410, C411, C412: 22p; 0402
IC401: TUSB2046BIRHBIRHB; RHB_S-PQFP-N32
J401: USB_MICRO_FLIPPED; HIROSE-ZX62R-B-5P
L401: 2.2uH (NR3010T2R2M); L-NR3010
Q401: CSTCR6M00G15L99; MURATA-FILTER_CSTCR
R401: 33R; 0402
R402: 10k; 0402
R403, R407: 1k5; 0402
R404: 47k; 0402
R405, R406, R410, R411, R416, R417: 22R; 0402
R408, R409, R412, R413, R414, R415, R418, R419: 15k; 0402
U402: TPS62237DRY; DRY6
U404: TPD2E001DRLR; TPD2E001-DRL

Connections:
!OC: IC401.10 (!OVRCUR1), IC401.14 (!OVRCUR2), IC401.18 (!OVRCUR3), IC401.22 (!OVRCUR4), R402.2
!PWRON: IC401.9 (!PWRON1), IC401.13 (!PWRON2), IC401.17 (!PWRON3), IC401.21 (!PWRON4)
EZFET_VBUS: C402.1, C403.+, C404.2, J401.VBUS, U402.3 (VIN), U402.5 (EN), U404.1 (VCC); also elsewhere on the board
EZFET_VCC: C401.2, C407.1, IC401.3 (VCC), IC401.6 (EEDATA/GANGED), IC401.8 (BUSPWR), IC401.25 (VCC), IC401.26 (!EXTMEM), L401.P$2 (2), R402.1, R403.1, R404.1, U402.6 (FB); also elsewhere on the board
GND: C401.1, C402.2, C403.-, C404.1, C405.2, C406.2, C407.2, C408.2, C409.2, C410.2, C411.2, C412.2, IC401.7 (GND), IC401.27 (TSTPLL/48MCLK), IC401.28 (GND), IC401.31 (TSTMODE), J401.GND, Q401.2, R401.2, R408.1, R409.1, R412.1, R413.1, R414.2, R415.2, R418.2, R419.2, U402.1 (MODE), U402.4 (GND), U404.4 (GND); also elsewhere on the board
HUB_DM1: R416.2, R419.1; also elsewhere on the board
HUB_DM2: R410.2, R415.1; also elsewhere on the board
HUB_DP1: R417.2, R418.1; also elsewhere on the board
HUB_DP2: R411.2, R414.1; also elsewhere on the board
unnamed: C410.1, IC401.15 (DM2), R410.1
unnamed: C405.1, IC401.1 (DP0), R403.2, R405.1
unnamed: IC401.30 (XTAL1), Q401.1
unnamed: J401.SHIELD1, R401.1
unnamed: C406.1, IC401.2 (DM0), R406.1
unnamed: J401.D+, R405.2, U404.5 (IO2)
unnamed: J401.D-, R406.2, U404.3 (IO1)
unnamed: L401.P$1 (1), U402.2 (SW)
unnamed: IC401.29 (XTAL2), R407.2
unnamed: C412.1, IC401.11 (DM1), R416.1
unnamed: C411.1, IC401.12 (DP1), R417.1
unnamed: C409.1, IC401.16 (DP2), R411.1
unnamed: C408.1, IC401.4 (!RESET), R404.2
unnamed: IC401.20 (DP3), R412.2
unnamed: IC401.24 (DP4), R408.2
unnamed: IC401.23 (DM4), R409.2
unnamed: IC401.19 (DM3), R413.2
unnamed: Q401.3, R407.1

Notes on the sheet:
USB Hub and Power
1.6

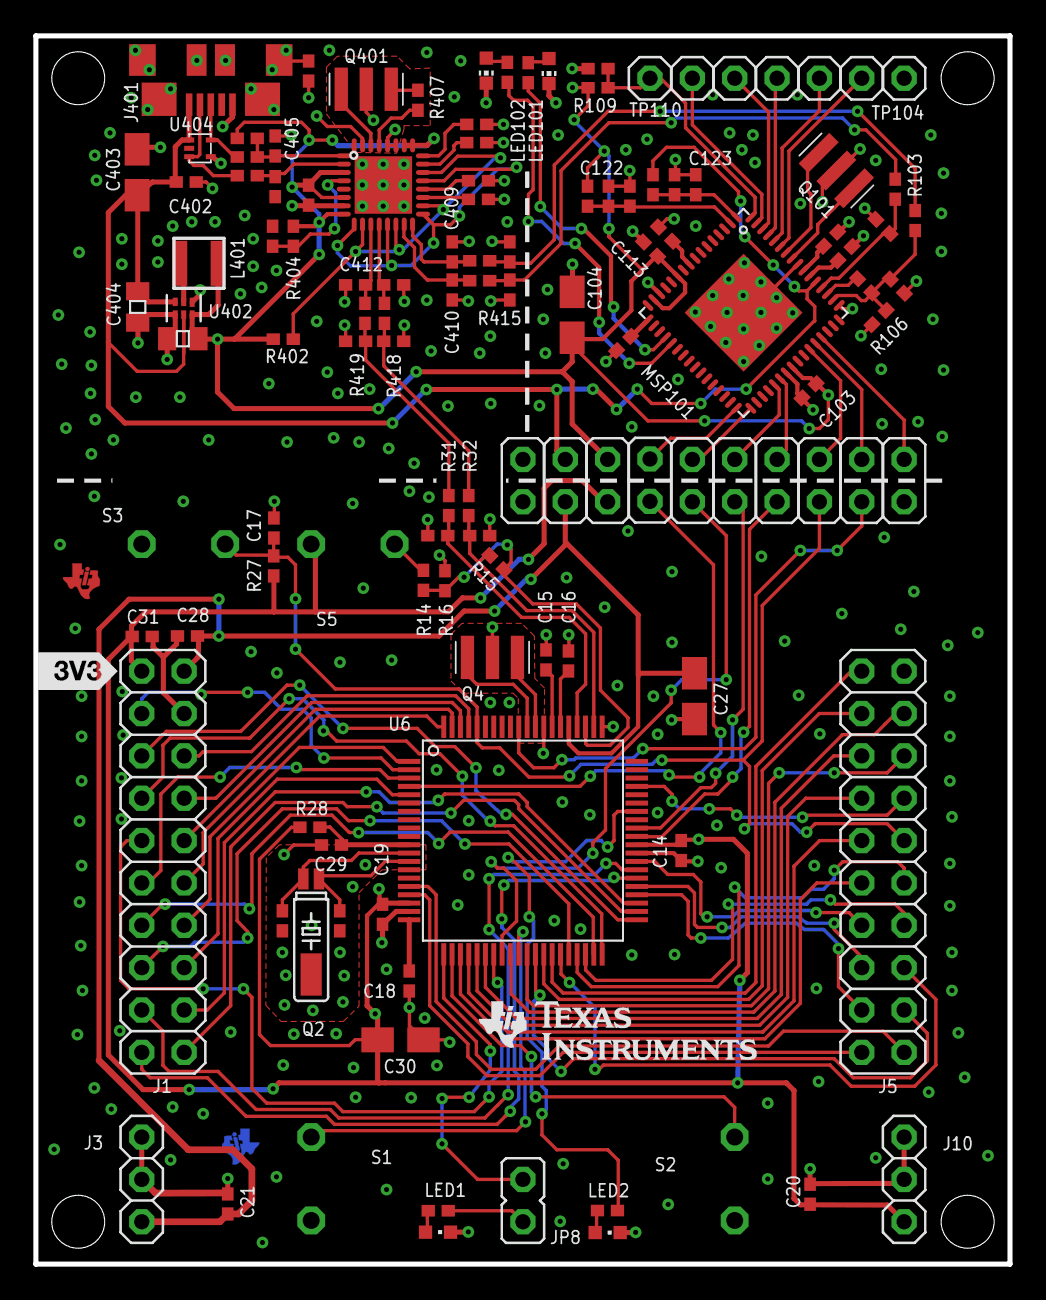
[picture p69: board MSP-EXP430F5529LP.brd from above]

Board: 2 copper layers, 58.4 x 73.7 mm, 133 parts (1 on the bottom side), 117 nets.

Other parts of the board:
DRAW2: LOGO-ROCKET-10X7MM-BRD
U$1: LOGO16_TPLACE
U$2, U$5: TILOGO_SMALL

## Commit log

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2019-06-12 Initial commit of the LeashPCB, includes CC1352R symbol
    [LeashPCB.kicad_pcb, LeashPCB.sch]
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2019-06-13 Added first pass try at the mechanicals/batteries using SMT components and AAAA batteries
    [LeashPCB.kicad_pcb, LeashPCB.sch, keystone-PN1016-1.STEP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]
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2019-06-13 Shuffled around some folders and swapped to a single AAA solution
    [ESW-108-24-L-S.stp, LeashPCB.kicad_pcb, LeashPCB.sch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]
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2019-06-15 Connected up some of the top level power signals
    [LeashPCB.sch, MikroBusClick.sch, RF.sch]
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2019-06-16 Changed some file names to remove spaces and added circuits around the main power chips
    [Battery Input.sch, BatteryInput.sch, Boost.sch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]
2019-06-16 Removed schematics with spaces, moved gitignore to top level directory
    [Battery Input.sch, External Input.sch]
2019-06-17 Changed around configuration of some parts and added top level cost estimates to block diagram
    [BatteryInput.sch, Boost.sch, ExternalInput.sch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]
2019-06-29 Swapped out second boost for a buck. Will now take all inputs up to 5V and then buck down to 3v3 for processor
    [BatteryInput.sch, Boost.sch, ExternalInput.sch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]
2019-07-01 Added more top level signals to block diagram and added alternate population options for power
    [BatteryInput.sch, ExternalInput.sch, Indicators.sch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]
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2019-07-12 Shifted all components to the left on the layout and added passives
    [BatteryInput.sch, Boost.sch, Indicators.sch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]
2019-07-16 Added flash memory, passives around RF section and started hooking up signals
    [LeashPCB.sch, RF.sch]
2019-07-17 Hooked up top level signals between cc1352r and the click headers and imported footprints from passives added yesterday
    [Boost.sch, Indicators.sch, LeashPCB.kicad_pcb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]
2019-07-17 Started connecting up all of the passive matching network for the RF output
    [LeashPCB.kicad_pcb, RF.sch]
2019-07-18 Finished layout on the boost converters and enlarged the board slightly to allow for a larger battery and the large PCB antenna
    [BatteryInput.sch, Boost.sch, LeashPCB.kicad_pcb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]
2019-07-18 Adding datasheet listings to components and some small saves
    [Boost.sch, LeashPCB.kicad_pcb, Programming.sch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]
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2019-07-23 Resized schematic sheets for printing and remapped signals for matching Launchpad headers
    [BatteryInput.sch, Boost.sch, ExternalInput.sch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]
2019-07-25 Started routing on layers 3 and 4 for east-west, north-south respectively. I think this should allow us to hit our layout targets
    [LeashPCB.kicad_pcb, RF.sch]
2019-07-30 Rotated the right click header to be the proper orientation and routed more signals on the second iner layer.
    [BatteryInput.sch, Boost.sch, ExternalInput.sch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]
2019-07-30 Removed all power planes on top side, moving to a ground fill on most layers and thick traces to pass power
    [LeashPCB.kicad_pcb]
2019-07-30 Added SWD connector on the back side as a backup for testing and continued routing
    [BatteryInput.sch, Indicators.sch, LeashPCB.kicad_pcb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]
2019-07-30 Pulled in final small components and finished routing all but the RF section
    [BatteryInput.sch, Boost.sch, ExternalInput.sch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]
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2019-07-31 Moved tag connect to be between two click headaers and DRC cleanup efforts
    [LeashPCB.kicad_pcb]
2019-07-31 Added a swtich for future testing that would allow us to remove the ideal diode controller
    [Boost.sch]
2019-08-01 Added a switch and finished closing out DRC errors. Added a lot of via stiching in RF section.
    [BatteryInput.sch, Boost.sch, LeashPCB.kicad_pcb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]
2019-08-01 Hooked up RX/TX to the USB converter (whoops) and added a few other small connections.
    [Boost.sch, ExternalInput.sch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]
2019-08-02 generated gerbers and sent off for fabrication, tagging as rev A
    [LeashPCB-B_Cu.gbr, LeashPCB-B_Mask.gbr, LeashPCB-B_Paste.gbr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]
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2020-02-11 Swapped out USB and antenna sections and refactored outline, started routing
    [0900PC15J0013.STEP, 1054500101.stp, 2450AT18D0100.STEP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]
2020-02-11 Done with 90% of routing, but going to move the USB to serial and power chips to open up the pathways underneath the CC1352R
    [Indicators.sch, LeashPCB.kicad_pcb, LeashPCB.sch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]
2020-02-12 Added a the second header back in and started hooking it up. Swapped DIO12/13 and 21/22 pins to get the correct UART configuration
    [LeashPCB.kicad_pcb, MikroBusClick.sch, RF.sch]
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2020-02-12 Reset all annotations
    [LeashPCB.kicad_pcb]
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2020-02-18 Most data lines routed, need to route final power and check USB support circuitry
    [LeashPCB.kicad_pcb, RF.sch]
2020-02-18 Moved buttons and integrated new components. Also finished layout and completed DRC
    [LeashPCB.kicad_pcb, MSP-EXP430F5529LP-bom.xlsx, MSP-EXP430F5529LP.brd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]
2020-02-19 Added accelerometer, ambient light sensor, a temp+humid sensor and an OR gate to push all of the interrupts together
    [Boost.sch, ExternalInput.sch, Indicators.sch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]
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2020-02-21 Added new components and hooked MSP430 into the SPI flash and the lines for programming the CC1352
    [ExternalInput.sch, Indicators.sch, LeashPCB.kicad_pcb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]
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2020-04-14 Updated after latest Rev B build and BOM update, including new STEP file export
    [Boost.sch, LeashPCB.kicad_pcb, LeashPCB.sch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]
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2020-07-24 Revisions and fixes for Rev B board in preparation for Rev C start. Changed how we handle the MSP430 and how it connects to the cc1352r. Also some part swaps and pin swaps on the cc1352r. Fixes #4 an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
    [Boost.sch, Programming.sch, RF.sch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]
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2020-07-28 BOM changes and swapping TX/RX input to cc1352r. Fixes #5
    [RF.sch]
2020-07-28 Added DNP resistors and reconfigured Tag Connect to use Spy-By-Wire (SPW) by default on the MSP430. Fixes #6
    [USB_Input.sch]
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2020-08-26 Schematic update by seeed
    1. BOM match seeed components library
    2. Modify U1 VBUS pin connection
    3. Add 100nF decoupling capacitor for sensors
    [Boost.sch, DNP0006A.stp, ExternalInput.sch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]
2020-08-27 Modify PCB layout by seeed
    Layout changed based on schematic change and mechanical design change.
    [LeashPCB-B.Cu.gbr, LeashPCB-B.Fab.gbr, LeashPCB-B.Mask.gbr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]
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2020-10-18 SW: buildroot: getting close to working atusb
    * Make sure you have permissions (ie., `sudo ./run`)
    * Next commit, I'll add `iwpan`
    ```
    Bus 001 Device 001: ID 1d6b:0001
    Bus 001 Device 002: ID 20b7:1540
    usb 1-1: ATUSB: AT86RF231 version 2
    usb 1-1: Firmware: major: 0, minor: 3, hardware type: ATUSB (2)
    usb 1-1: Firmware: build #132 Mo 28. Nov 16:20:35 CET 2016
    usb 1-1: Read permanent extended address 10:e2:d5:ff:ff:00:02:d1 from device
    usbcore: registered new interface driver atusb
    wpan0 Link encap:UNSPEC HWaddr 10-E2-D5-FF-FF-00-02-D1-00-00-00-00-00-00-00-00
    BROADCAST NOARP MTU:123 Metric:1
    RX packets:0 errors:0 dropped:0 overruns:0 frame:0
    TX packets:0 er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
2020-10-18 SW: buildroot: try to add ping6
    Getting close.
    NOTE: Found out that some earlier commit messages missed the commands,
    because of # in first column.
    After update:
    # modprobe atusb
    # ip link set wpan0 down
    # iwpan phy phy0 set channel 0 26
    # iwpan dev wpan0 set pan_id 0xabcd
    # ip link add link wpan0 name lowpan0 type lowpan
    # ip link set wpan0 up
    # ip link set lowpan0 up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
2020-10-18 SW: buildroot/gbridge: try to debug
    netlink: Initializing the controller
    TCP/IP: Initializing the controller
    TCP/IP: Creating the event loop thread
    A driver has already been registered for cport id 0
    Driver is at 0x500010008
    Failed to register SVC
    Failed to create client: Daemon not running
    TCP/IP: The event loop stopped
    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
2020-10-25 remove CONFIG_IEEE802154_FAKELB
    CONFIG_IEEE802154_FAKELB might be causing the extra/dummy
    loopback wpan interfaces : https://github.com/torvalds/linux/blob/master/drivers/net/ieee802154/fakelb.c#L22
    Also looks like it is a deprecated driver : https://github.com/torvalds/linux/blob/master/drivers/net/ieee802154/fakelb.c#L250
    Added GBPHY I2C,SPI,UART configs
    ping seems to work perfectly, but gbridge crashes after sometime
    (after the hotplug event)
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2020-11-02 HW: Leash: rev C overwrite rev B
    I know hardware folks like to just see frozen revs laid out in
    parallel folders, but it rubs a software guy wrong. We can always
    bring something back if we need it. I want to be definitive on
    what is the latest.
    [0900PC15J0013.STEP, 1054500101.stp, 2450AT18D0100.STEP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]
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2020-11-02 HW: Freedom: add rev A
    Previous version was Leash rev C.
    * Starting revision back at 'A'.
    * Add audible buzzer https://github.com/jadonk/beagleconnect/issues/35
    * Add USB signals to both sides of connector https://github.com/jadonk/beagleconnect/issues/28
    * Wire for CC1352P with external antenna getting power amp and with built-in antennas on signals without power amp https://github.com/jadonk/beagleconnect/issues/32
    * Move LEDs to MSP430 due to loss of GPIO on CC1352P
    https://github.com/jadonk/beagleconnect/issues/32
    * Change capacitors on 48MHz crystal
    https://github.com/jadonk/beagleconnect/issues/42
    * Adjust alternate power input diode equivalent
    https://github.com/jadonk/beagleconnect/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
    [0900PC15J0013.STEP, 1054500101.stp, 2450AT18D0100.STEP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]
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2020-11-03 HW: Freedom: rev C2 (1103)
    * Rotate mikroBUS to avoid buttons https://github.com/jadonk/beagleconnect/issues/29
    * Released to prototype
    [BeagleConnect Freedom.kicad_pcb, BeagleConnect Freedom.sch, Boost.sch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]
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2020-11-19 HW: restore Leash rev C temporarily
    This is probably adding a lot of wasteful bits, but we are doing a lot of compares between
    this rev C and the Freedom rev C2.
    [0900PC15J0013.STEP, 1054500101.stp, 2450AT18D0100.STEP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]
2020-11-19 SW: bcf_sensortest: switch UART
    Still some fixes needed
    jkridner@tupper:~/workspace/beagleconnect/sw/zephyrproject/bcf_sensortest$ tio /dev/ttyACM1
    [tio 09:41:22] tio v1.29
    [tio 09:41:22] Press ctrl-t q to quit
    [tio 09:41:22] Connected
    uart:~$ *** Booting Zephyr OS build zephyr-v2.4.0-1244-g9e3c5d8f7352 ***
    [00:00:00.005,584] <inf> lis2dh: bus=I2C_0 fs=2, odr=0x4 lp_en=0x8 scale=9576
    [00:00:00.013,122] <inf> net_config: Initializing network
    [00:00:00.113,159] <inf> net_config: IPv6 address: 2001:db8::1
    [00:00:00.113,220] <inf> net_config: IPv6 address: 2001:db8::1
    [00:00:00.113,952]
    [00:00:13.585,449] <inf> beagleconnect_freedom: User Button event
    [00:00:13.585,723] <inf> beagleconnect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
2020-11-19 SW: bcf_sensortest: script cleanup
    Summary of functionality (bug in button handler):
    [00:00:00.113,952] <inf> beagleconnect_freedom: opening device 2.4G LED
    [00:00:00.113,983] <inf> beagleconnect_freedom: opening device SubG LED
    [00:00:00.113,983] <inf> beagleconnect_freedom: opening device User Button
    [00:00:00.114,013] <inf> beagleconnect_freedom: opening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
2020-12-17 SW: zephyr: reduce size and add launchpad
    * Use a much smaller-in-scope west.yml, loading less modules
    * Add CC1352R1 LaunchpadXL support to `sensortest`
    * Simplify the device selection in `sensortest`
    * Add dummy nodes to the device tree to avoid errors, even if the device
    isn't there
2020-12-17 SW: sensortest: error in binding test
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2021-01-09 CI : fix build issues for firmware and buildroot
    buildroot issue was probably this:
    http://buildroot-busybox.2317881.n4.nabble.com/PATCH-1-1-pkg-cmake-mk-fix-host-ccache-support-for-CMake-3-19-td271371.html
    and was fixed after bumping up the version to 2020.11.1
    firmware build was failing at the 'installing zephyr
    pre-requisites stage' due to trying to fetch a old/non
    existent package resulting in 404, adding a sudo apt update
    solves the problem.
2021-01-13 sw: linux: add mikrobus driver update patches
    mikrobus driver works within buildroot but the click
    device drivers are not being probed correctly:
    in host /opt/gbridge.sh a hack for continously blinking the
    led on the SensorTag/Launchpad is added(this background
    transaction happening continously prevents some of the greybus
    pm suspend events happening, which might have been the cause
    for the kernel panic, with this continous background transfer
    the kernel panic is not seen and qemu machine does not crash)
    changes were tested using ATUSB, CC1352R SensorTag
    Welcome to Buildroot
    buildroot login: root
    Password:
    IFLP=`ifconfig | grep lowpan`
    ip link set wpan0 down
    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
2021-01-15 Update 0007-mikrobus-mikrobus-over-greybus.patch
    I'll need to track down where these files are referenced.
    Addressing build error caused by https://github.com/jadonk/beagleconnect/issues/49.
2021-01-30 README: fix excessive capitalization and change click to add-on board
    fixes wrong build directory in sw/build-firmware.sh
    fixes older buildroot version in README
    Fixes: https://github.com/jadonk/beagleconnect/pull/52#discussion_r566166949
    Fixes: https://github.com/jadonk/beagleconnect/pull/52#discussion_r566178242
    Fixes: https://github.com/jadonk/beagleconnect/pull/52#discussion_r566181604
    Fixes: https://github.com/jadonk/beagleconnect/pull/52#discussion_r566169457
    Fixes: https://github.com/jadonk/beagleconnect/pull/52#discussion_r566176208
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2021-03-05 Sensortest working after fixing net-up.sh
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2021-03-11 Revert "temporarily disable sensortag due to flash dts label conflict"
    This reverts commit 3eccb0120e4c136c046d5a12cdb397354c881677.
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2021-03-25 msp430 pin fix for rev C3
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2021-03-25 disable buggy sgp30 and hm3301 drivers for now
2021-03-25 BME680 driver interferes with HDC20X0 driver
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2021-06-13 sw: mikrobus: add mikrobus click ID flasher as submodule
    this project allows to flash the eeprom on the new mikrobus click ID adapter from BeagleConnect Freedom,
    the scheme for writing manifests is as follows:
    write production manifest(fixed, minimum information for enabling through userspace if driver is available) at addr 0x0000 onwards
    write variable manifest at next free block after writing production manifest
    update eeprom bytes with production manfiest start block
    write product fixed/production manifest(currently commented)
    production/fixed manifest - manifest available at click production time(contains some mikroe specific strings also),
    if driver does not exist at productio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
2021-10-17 sensortest: add ads1115
    * Eliminate build error related to removing LED code
    * Bugs in ads1115 showing up now, not fixed
2021-11-09 Struggling to hack in rev C4
    Drivers needed:
    * MSP430 USB UART Bridge (LEDs, Buzzer, etc.)
    * TS5A2066
    * ???
    Currently hung up trying to add the TS5A2066 driver.
    See https://github.com/jadonk/zephyr-1/commit/5c661ee81d7a391b7a3e84054f215e2232cf4b76
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2021-12-09 UART1 pin swap
2021-12-10 Add bcfserial build
    It uses UART1 that has corrected RX/TX lines for use
    with PocketBeagle-based BeagleConnect Gateway or
    updated Robotics Cape.
    UART1 is the one next to the battery connector, CC1352 and antenna.
    UART0 is the one with the MSP430, USB connector, buttons and LEDs.
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2022-01-08 Docs: LED.md
    Attempt to address https://github.com/jadonk/beagleconnect/issues/71
    Could be used to augment the silkscreen per https://github.com/jadonk/beagleconnect/issues/66
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2022-01-08 Docs: LED: syntax fixes
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2022-03-11 Added instructions for flashing via a Linux Host
    This is in case flashing from the bone fails.
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2022-05-06 Fix beagleconnect back svg
    Buttons are added.
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

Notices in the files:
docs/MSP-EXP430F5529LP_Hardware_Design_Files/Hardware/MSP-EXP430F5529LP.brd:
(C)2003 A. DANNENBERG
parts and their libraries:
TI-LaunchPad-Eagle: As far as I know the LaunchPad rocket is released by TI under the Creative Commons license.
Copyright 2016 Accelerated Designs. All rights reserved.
